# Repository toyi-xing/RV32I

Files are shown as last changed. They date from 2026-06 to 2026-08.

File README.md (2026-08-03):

# RV32I SoC

本仓库是一个 RV32I SoC 实现仓库，维护对象包括五级流水线核 `core.sv`、AXI4-Lite/APB4 数据子系统、MMIO 外设（GPIO/UART/TIMER32）、SoC 集成顶层 `rv32i_soc.sv` 及 SoC 级 testbench。已完成最小 M-mode CSR/trap、machine timer/external interrupt、single-outstanding data access、流水线 backpressure，以及 AXI4-Lite DMEM 和 APB4 外设接入。

## 当前特性（已经过定向验证）

- **40 条 RV32I 指令**：完整 ALU、分支、跳转、访存、LUI/AUIPC、FENCE（当前为 nop）、ECALL、EBREAK 全量支持。
- **五级流水线**：IF/ID/EX/MEM/WB 经典五级流水线结构。
- **数据 hazard**：forwarding（EX/MEM、MEM/WB）+ load-use stall + CSR-use stall。
- **控制 hazard**：branch/JAL/JALR/trap redirect flush + wrong-path kill。
- **CSR 寄存器及访问指令**：6 条 Zicsr 指令（CSRRW/CSRRS/CSRRC/CSRRWI/CSRRSI/CSRRCI），最小 M-mode CSR（mstatus/mtvec/mscratch/mepc/mcause/mtval + 只读 CSR）。
- **同步异常**：instruction address misaligned、illegal instruction、breakpoint、load/store address misaligned、 load/store access fault、ECALL/EBREAK from M-mode。
- **MRET**：trap handler 返回。
- **trap 精确提交**：在 MEM 边界接受，kill 年轻指令，不影响 older instruction。
- **MMIO 地址图及外设**：GPIO0、UART0、TIMER0 已集成于 data_subsystem，寄存器 ABI 见 `rtl/periph/readme.md`，SoC 地址图规划在 `soc_pkg.sv`，平台常量见 `sw/include/platform.h`。
- **MMIO access fault**：未实现外设或预留地址空间访问触发 load/store access fault。
- **machine timer interrupt**：TIMER0.MTIME ≥ MTIMECMP 触发 MTIP，level pending 输出到 mtip_o。
- **machine external interrupt**：GPIO 按 bit 独立配置边沿/电平触发、UART RX 事件，汇总为 MEIP（中断优先级 MEIP > MTIP）。
- **中断精确提交**：CSR 写同拍中断接受、MRET 同拍中断重入、mepc 记录当前提交边界的 interrupt return PC。
- **AXI4-Lite/APB4 数据子系统**：LSU 保留 single-outstanding simple request/response 边界，经 adapter 转为 AXI4-Lite；DMEM 通过外置 AXI-Lite RAM 接入，GPIO/UART/TIMER 经 AXI-Lite-to-APB4 bridge 与 APB mux 接入，标准 channel wait/error 映射到既有 MEM backpressure 和精确 access fault 语义。
- **设计可综合**：CPU 核及子模块采用可综合 rtl 编写；综合对象为 CPU 核顶层 `core.sv`，综合结果不作为项目重点。SoC 顶层透出 IMEM/DMEM 端口，仿真内存模型由 testbench 实例化；MMIO 外设模型为简化模型，未面向真实 IO 单元、真实串口协议或 PPA 做优化。
- **FPGA 上板验证**：基于 v5.1 完成 FPGA 上板验证归档，CPU core RTL 保持不改，SoC MMIO 地址图保持不改；通过 FPGA top、片上 IMEM/DMEM wrapper、UART TX/RX PHY 和 Quartus 工程适配，完成 GPIO/KEY、UART、TIMER polling、TIMER interrupt 等板级验证。

---

## 验证能力

- **SoC 级程序自检定向测试**：汇编/C 测试程序通过 PASS/FAIL 状态字结束仿真，覆盖 ISA、流水线 hazard、trap/CSR、MMIO 和 machine interrupt 场景。
- **TB mailbox 外部激励协议**：`sw/include/tb_rv32i_soc_test.h` 与 `tb/sv/tb_rv32i_soc.sv` 约定保留 DMEM store 命令，由测试程序按自身进度请求 testbench 驱动 GPIO 输入和 UART RX 事件。该协议只属于当前 testbench，不是 SoC 真实 MMIO ABI。
- **interrupt directed test**：覆盖 timer interrupt、GPIO/UART external interrupt、MEIP/MTIP 优先级、CSR 写同拍中断、MRET 同拍中断重入和周期 GPIO 输入测量，测试程序由 TB mailbox 机制自行激发。
- **FPGA board bring-up**：[fpga/readme.md](fpga/readme.md) 作为 FPGA 上板验证入口，归档板卡资料、通用上板方法，以及已完成版本的专项迁移文档和验证结果。
- **VCS/UVM/SVA 验证工作区**：[uvm/v6_0/data_subsystem](uvm/v6_0/data_subsystem/readme.md) 固定保存 v6.0 simple bus 与 response-delay wrapper 的独立验证环境，包含 active bus/wrapper agent、monitor、DMEM/GPIO0 reference check、wrapper delay checker、SVA 和 functional coverage；该版本化快照不代表当前 AXI/APB 主线 RTL，固定 seed 结果与 coverage 见 [verification report](uvm/v6_0/data_subsystem/verification_report.md)。

---

## 系统架构

```text
+-------------------------------------------------------------------------------------------------+
| tb_rv32i_soc                                                                                    |
|                                                                                                 |
|  +-----------------------+    instr     +--------------------------------------------------+    |
|  | simple_rom / IMEM     | -----------> | rv32i_soc                                        |    |
|  | 0x0000_0000  256 KiB  |              |                                                  |    |
|  | +imem image           |              |  +----------------------------------------+      |    |
|  +-----------------------+              |  | core.sv                                |      |    |
|                                         |  | RV32I 5-stage pipeline                 |      |    |
|                                         |  | forwarding / stall / redirect          |      |    |
|                                         |  | CSR / trap / precise interrupt   <---------+  |    |
|                                         |  | single-outstanding LSU + backpressure  |   |  |    |
|                                         |  +-------------------+--------------------+   |  |    |
|                                         |                      | simple req/resp        |  |    |
|                                         |                      v                        |  |    |
|                                         |  +-----------------------------------------+  |  |    |
|                                         |  | data_subsystem                          |  |  |    |
|                                         |  | simple_bus_to_axi_lite                  |  |  |    |
|  +-----------------------+   AXI4-Lite  |  |   -> axi_lite_router                    |  |  |    |
|  | axi_lite_ram / DMEM   | <----------------------+   external DMEM AXI-Lite port    |  |  |    |
|  | 0x0004_0000  256 KiB  |              |  |      +-> axi_lite_to_apb -> apb_mux     |  |  |    |
|  | +dmem image           |              |  |             +-> GPIO0 / UART0 -> MEIP +----+  |    |
|  +-----------------------+              |  |             +-> TIMER0        -> MTIP + |     |    |
|                                         |  +-----------------------------------------+     |    |
|                                         |                                                  |    |
|                                         | observable: commit / trap / data bus             |    |
|                                         |             GPIO / UART / IRQ                    |    |
|                                         +--------------------------------------------------+    |
|                                                                                                 |
|  memory images | PASS/FAIL monitor | commit/trap/data trace                                     |
|  TB mailbox store commands -> GPIO input stimulus / UART RX event                               |
|                                                                                                 |
+-------------------------------------------------------------------------------------------------+
```

IMEM 和 DMEM 均位于 `rv32i_soc` 之外；`data_subsystem` 只向外透出 AXI4-Lite DMEM port，GPIO/UART/TIMER 则作为内部 APB4 外设接入。TB mailbox 和 trace 只属于仿真观察边界。

---

## 目录结构

| 目录 | 说明 |
|---|---|
| `docs/` | 说明文档 |
| [`fpga/`](fpga/readme.md) | FPGA 上板验证工作区，包含板卡资料、版本归档工程、上板流程和验证结果入口 |
| `rtl/` | RTL 源码 |
| `scripts/` | 辅助脚本 |
| `sim/` | 编译和仿真脚本 |
| `sw/` | 汇编和 C 裸机测试程序 |
| `tb/` | SoC 级定向验证 testbench 平台 |
| [`uvm/`](uvm/readme.md) | Linux/VCS CLI UVM 验证工作区，按 release 和验证对象归档 |

---

## 项目时间戳

| 核（相对于上版本的改动） | 顶层 | 状态 | release 版本 | 备注 |
|---|---|---|---|---|
| 单周期 RV32I | `core_single_cycle.sv` | 历史版本已完成，当前不再维护 | v1.0 | 最终兼容版本为 v2.0，自 v2.10 起删除该文件 |
| 五级流水线 RV32I（data hazard + control hazard） | `core_pipeline5.sv` | 已完成 | v2.0 | - |
| 同步异常扩展、CSR 与最小特权级（CSR/exception trap） | `core_pipeline5.sv` | 已完成 | v3.0 | 自 v3.4 起，将 `core_pipeline5.sv` 改名为 `core.sv` |
| 增加 MMIO 最简外设与 SoC 平台集成 | CPU 核 `core.sv` <br> SoC 平台 `rv32i_soc` | 已完成 | v4.0 | 1. 自 v4.10 起，删除旧的 CPU 核测试平台 `tb_core_pipeline5.sv` <br>  2. 外设 offset 计算逻辑存在 bug [RTL-001](docs/known_issues.md)，已在v7.0定位并修复 |
| machine interrupt：MTIP、MEIP | CPU 核 `core.sv` <br> SoC 平台 `rv32i_soc` | 已完成 | v5.0 | 1. 自 v5.1 起，拆分 SoC 顶层电路的 mem 单元 <br> 2. 回归测试统计存在 bug [REG-001](docs/known_issues.md)，已在 v5.6 定位并修复 |
| FPGA 分支：基于 v5.1 的 FPGA 上板验证 | FPGA 顶层 [`e10_rv32i_top.sv`](fpga/project_v5.1_original_to_fpga/project_v5.1_fpga/rtl/fpga/e10_rv32i_top.sv) <br> FPGA 工程 [`e10_rv32i.qpf`](fpga/project_v5.1_original_to_fpga/project_v5.1_fpga/fpga/quartus/e10_rv32i.qpf) | 已完成 | v5.2 | - |
| data-side 可变延迟 | CPU 核 `core.sv` <br> SoC 平台 `rv32i_soc` | 已完成 | v6.0 | - |
| UVM 分支：基于 v6.0 的 data_subsystem UVM/SVA 验证 | DUT rtl top: [`data_subsystem.sv`](uvm/v6_0/data_subsystem/dut/rtl/soc/data_subsystem.sv) <br> UVM top: [`tb_data_subsystem_uvm_top.sv`](uvm/v6_0/data_subsystem/tb/top/tb_data_subsystem_uvm_top.sv) | 已完成 | v7.0 | UVM 固定 seed 回归暴露并修复 [RTL-001](docs/known_issues.md) |
| AXI4-Lite 总线接入 | CPU 核 `core.sv` <br> SoC 平台 `rv32i_soc` | 已完成 | v8.0 | - |

---

## 环境依赖

### 主仓库仿真 —— Linux

- **RISC-V bare-metal GCC 工具链**：`riscv64-unknown-elf-gcc` 等，需支持 `rv32i_zicsr` 和 `ilp32`，用于生成 ELF/BIN。
- **Verilator**：运行根目录 ASM/C directed regression。
- **Python 3**：运行 `bin2mem32.py` ，编译出的裸二进制 .bin 转成每行一个 32-bit hex word 的 .mem 文件。

### FPGA 工作区 —— Windows

- **Quartus Prime Lite 25.1std.0 Build 1129**：综合、布局布线、生成 `.sof` 和 Programmer 下载。
- **USB-Blaster 驱动**：连接 E10 开发板并下载 FPGA。
- **RISC-V bare-metal GCC 工具链、Bash 与 Python 3**：构建裸机程序并生成 `.mem`/`.mif` 初始化镜像。
- **USB-TTL 串口工具**：观察和验证真实 UART TX/RX。

FPGA 板卡、工具和版本化工程说明见 [fpga/readme.md](fpga/readme.md)。

### VCS/UVM 工作区 —— Linux

- **Synopsys VCS**：编译和运行 UVM 仿真平台。

UVM 工具、命令和结果说明见 [uvm/readme.md](uvm/readme.md)。

---

## 五级流水线核（主仓库仿真）

### 涉及文件

**RTL：**
```
rtl/common/          # 核与 SoC 公共常量/枚举/类型（core_pkg、pipeline_pkg、soc_pkg）
rtl/bus/             # AXI4-Lite adapter/router、AXI-Lite-to-APB4 bridge、APB mux/register adapter
rtl/core/            # 五级流水线核（IF/ID/EX/MEM/WB、forwarding、hazard、CSR、trap）
rtl/mem/             # memory 封装（simple_rom、当前 axi_lite_ram、legacy simple_ram）
rtl/periph/          # MMIO 外设（mmio_gpio、mmio_uart、mmio_timer32）
rtl/soc/             # SoC 集成（AXI4-Lite/APB4 data_subsystem、rv32i_soc 顶层）
```

**Testbench：** 

- `tb/sv/tb_rv32i_soc.sv`：集成 MMIO 最小外设的 SoC 测试平台。

**汇编测试程序：**
```
# 基础 ISA 测试
sw/asm/0001_smoke.S                           # 最小冒烟
sw/asm/0101_branch.S                          # 分支指令
sw/asm/0102_alu_imm.S                         # ALU 立即数
sw/asm/0103_alu_reg.S                         # ALU 寄存器
sw/asm/0104_load_store.S                      # 访存指令
sw/asm/0105_jump.S                            # JAL/JALR
sw/asm/0106_u_type.S                          # LUI/AUIPC

# 流水线 data/control hazard 测试
sw/asm/0301_pipeline5_nofwd_noredirect.S      # 不依赖 forwarding/redirect 的基线冒烟
sw/asm/0302_pipeline5_fwd_noredirect.S        # data hazard 全覆盖
sw/asm/0303_pipeline5_fwd_redirect.S          # forwarding + control hazard 混合

# trap 测试
sw/asm/0501_trap_entry_smoke.S                # ECALL trap entry smoke
sw/asm/0502_exception_full.S                  # 全同步异常总测试（9 个 step）
sw/asm/0503_csr_instr_test.S                  # 6 个 CSR 指令读写 CSR 寄存器测试

# SoC/MMIO 测试
sw/asm/0601_soc_smoke.S                       # SoC 级别冒烟
sw/asm/0602_uart_tx.S                         # UART TX 发送字符
sw/asm/0603_gpio_rw.S                         # GPIO OUT/OE/IN 读写
sw/asm/0604_mmio_access_fault.S               # MMIO 未实现外设 access fault
sw/asm/0605_mmio_misaligned_priority.S        # misaligned MMIO 访问优先级
sw/asm/0606_wrong_path_mmio.S                 # wrong-path MMIO 不提交

# interrupt 测试
sw/asm/0705_interrupt_commit_precise.S        # CSR 写同拍中断精确提交
sw/asm/0706_mret_interrupt_reentry.S          # MRET 同拍中断重入

# data subsystem 集成测试（沿用既有编号与文件名）
sw/asm/0801_dmem_wait_basic.S                 # AXI-Lite DMEM 基本 load/store 与 byte lane
sw/asm/0802_dmem_wait_forwarding.S            # AXI-Lite DMEM 固定多周期访问下 forwarding
sw/asm/0804_mmio_wait_access_fault.S          # APB 非法 offset 的精确 access fault
sw/asm/0805_wait_interrupt_boundary.S         # AXI-Lite DMEM 访问期间 interrupt 不越过 older 指令
```

**C 测试程序：**
```
sw/c/0201_c_smoke.c                           # 最小冒烟
sw/c/0202_dmem_init.c                         # .data/.bss/.rodata 初始化
sw/c/0401_control_mix.c                       # 综合控制流 + 内存操作
sw/c/0551_trap_smoke.c                        # C 侧 trap handler smoke
sw/c/0651_soc_mmio_smoke.c                    # SoC MMIO 冒烟（GPIO/UART/access fault）
sw/c/0652_soc_mmio_gpio_uart.c                # SoC MMIO 综合测试（GPIO bit 操作/UART 多字符串）
sw/c/0751_timer_smoke.c                       # TIMER0 定时器中断 smoke（C trap handler + level pending 清除）
sw/c/0752_gpio_irq_basic.c                    # GPIO 外部中断基础行为（4 类触发、IRQ_EN/STATUS/PENDING、W1C）
sw/c/0753_uart_rx_irq.c                       # UART RX 中断（TB 注入、rx_irq_enable 门控、读清与 W1C 差异）
sw/c/0754_external_timer_priority.c           # MEIP/MTIP 优先级（同时 pending 优先进 MEIP，清后进 MTIP）
sw/c/0757_gpio_periodic_irq.c                 # TB 固定周期 GPIO 中断精确测量（TIMER0.MTIME + UART 报告）
sw/c/0853_mmio_wait_basic.c                   # 固定 PREADY APB 外设基本读写与副作用
sw/c/0856_wait_mixed_random_smoke.c           # AXI-Lite DMEM/APB MMIO 混合路由 smoke
```

**仿真脚本：** `sim/soc_asm/`、`sim/soc_c/`

当前共 **38 个 directed tests**（汇编 25 + C 13），全量回归结果为 ASM 25/25、C 13/13。覆盖 RV32I 指令集、五级流水线 hazard（6 种 RAW forward + load-use stall + redirect）、7 种同步异常、MMIO 外设访问与 access fault、machine timer/external interrupt（GPIO 4 类触发、UART RX、MEIP/MTIP 优先级、CSR 同拍中断、MRET 同拍重入），以及 AXI-Lite DMEM、APB 外设、错误传播、MEM backpressure 和 DMEM/MMIO 混合路由场景。

### 仿真命令

```bash
# —— SoC 汇编回归仿真 ——
sim/soc_asm/run_all.sh

# —— SoC C 回归仿真 ——
sim/soc_c/run_all.sh

# —— SoC 单个程序仿真 ——
sim/soc_asm/run_test.sh <n>               # n 表示 sw/asm 下 汇编程序前的四位编码
sim/soc_c/run_test.sh <m>                 # m 表示 sw/c 下 c 程序前的四位编码
```

汇编仿真详细流程见 [docs/simulation_flow_asm.md](docs/simulation_flow_asm.md)。C 仿真流程见 [docs/simulation_flow_c.md](docs/simulation_flow_c.md)。

---

## 编写新测试

在 `sw/asm/` 下创建 `.S` 文件，然后：

```bash
sim/soc_asm/run_test.sh <四位编号或完整basename>
```

在 `sw/c/` 下创建 `.c` 文件后运行：

```bash
sim/soc_c/run_test.sh <四位编号或完整basename>
```

汇编测试集分类见 [sw/asm/readme.md](sw/asm/readme.md)。

c 程序测试集分类与编写方法见 [sw/c/readme.md](sw/c/readme.md)。

MMIO 外设操作手册见 [rtl/periph/readme.md](rtl/periph/readme.md)。

MMIO 地址图镜像查阅见 [sw/linker/readme.md](sw/linker/readme.md)。

## FPGA 上板验证（FPGA 工作区）

FPGA 上板验证入口见 [fpga/readme.md](fpga/readme.md)。该目录维护板卡资料、通用上板方法、版本归档工程、专项迁移说明和板级验证结果；根 README 只保留总入口，具体 FPGA 版本的工程细节以后统一在 `fpga/` 工作区内维护。

## UVM 平台仿真（VCS/UVM 工作区）

```bash
# —— 单个 UVM test，第二个参数为 random seed ——
uvm/v6_0/data_subsystem/sim/run_test.sh DS_map_random_test 1

# —— 启用 simple bus SVA ——
ASSERT_ON=1 uvm/v6_0/data_subsystem/sim/run_test.sh simple_bus_smoke_test 1

# —— 当前 UVM 受控回归 ——
uvm/v6_0/data_subsystem/sim/run_all.sh
```

UVM 工作区总入口见 [uvm/readme.md](uvm/readme.md)，当前环境的完整命令、PASS/FAIL 口径和本地产物见 [uvm_simulation_flow.md](uvm/v6_0/data_subsystem/dut/docs/uvm_simulation_flow.md)。

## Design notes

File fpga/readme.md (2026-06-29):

# RV32I FPGA 上板验证工作区

本工作区用于整理 RV32I SoC 从仿真验证版本迁移到 FPGA 上板验证版本的工程材料。当前主要目标板为正点原子 E10 最小系统板，FPGA 器件为 Intel Cyclone IV E `EP4CE10F17C8`。板卡原理图、器件手册、IO 分配表等资料统一放在 [fpga_e10_board_resources](fpga_e10_board_resources/) 中。

本文档是通用的 FPGA 上板验证方法；具体某个 RTL 版本的改造记录、验证结果和问题闭环放在对应版本目录下。

## 目录结构

```text
.
+-- readme.md
+-- fpga_e10_board_resources/
`-- project_v5.1_original_to_fpga/
    +-- project_v5.1_original/
    `-- project_v5.1_fpga/
```

| 路径 | 内容 |
| --- | --- |
| [fpga_e10_board_resources](fpga_e10_board_resources/) | E10 系统板资料归档，包括 FPGA 器件资料、原理图、IO 分配表、板载存储和外设芯片资料等。 |
| [project_v5.1_original_to_fpga](project_v5.1_original_to_fpga/) | v5.1 从仿真器验证工程迁移到 FPGA 上板工程的版本归档与专项文档入口。 |

## 目标板卡

当前上板目标：

- 板卡：正点原子 E10 最小系统板
- FPGA：Intel Cyclone IV E `EP4CE10F17C8`
- 时钟：板载 50 MHz 时钟
- 基础 IO：LED、KEY、UART、扩展排针
- FPGA 工具：Quartus Prime Lite 25.1

更细的板卡资源、M9K 片内存储、板载 SDRAM/Flash、引脚和原理图资料请查看 [fpga_e10_board_resources/readme.md](fpga_e10_board_resources/readme.md)。

## 通用上板改造项

把一个已经通过仿真的 RV32I SoC 版本搬到 FPGA 上，通常需要完成以下工作：

1. 保留已验证的 CPU core 逻辑，避免在上板适配阶段引入新的流水线行为变化。
2. 根据目标 FPGA 的片上存储资源重新评估 IMEM/DMEM 容量，并同步 RTL 参数、linker script 和 `platform.h`。
3. 分离仿真 memory 与 FPGA memory。仿真可继续使用理想 ROM/RAM，FPGA 侧应使用可综合、可推断或可例化的 block RAM。
4. 为 FPGA 添加板级 top，连接时钟、复位、LED、KEY、UART、扩展 GPIO 等真实 IO。
5. 根据 FPGA RAM 的真实时序适配 IMEM/DMEM wrapper。不能默认仿真 RAM 的组合读行为等价于 FPGA block RAM。
6. 添加 Quartus 工程、器件选择、顶层设置、QSF 引脚约束和存储初始化文件。
7. 建立 C 程序到 FPGA 初始化镜像的构建流程，并确保生成的 IMEM/DMEM 镜像被重新编译进 `.sof`。
8. 用最小可见程序逐步验证 GPIO、按键、timer polling、interrupt、UART 或其他外设。

## 工具依赖

与母仓库不同，本工作区 FPGA 上板验证在 Windows 环境下进行，建议准备：

- Quartus Prime Lite 25.1，用于综合、布局布线、生成 `.sof` 和下载 FPGA。
- USB-Blaster 驱动，用于通过 Quartus Programmer 下载。
- RISC-V bare-metal GCC 工具链，需支持 `rv32i_zicsr` 和 `ilp32`。
- Bash 环境，用于运行工程脚本。
- Python 3，用于二进制镜像、`.mem`、`.mif` 等格式转换。
- 可选 USB-TTL 串口工具，用于验证真实 UART TX/RX。

## C 程序编写规则

FPGA 上板 C 程序遵守以下规则：

- 程序放在对应 FPGA 工程的 `sw/c/` 目录下。
- 文件名使用四位编号开头，例如 `0500_xxx.c`，方便脚本按编号选择程序。
- 使用裸机 C，不依赖操作系统和标准库运行时。
- 包含工程提供的 `platform.h`，通过其中的地址图、寄存器偏移和 CSR helper 访问 SoC。
- 如果 RTL 修改了 IMEM/DMEM 容量或 MMIO 地址图，必须同步 linker script 和 `platform.h`。
- 每次更新 C 程序镜像后，需要重新运行 Quartus compile，因为 FPGA 初始化文件会被打包进 `.sof`。

## 当前版本归档

当前已完成的版本迁移归档见 [project_v5.1_original_to_fpga/readme.md](project_v5.1_original_to_fpga/readme.md)。该目录包含仿真原始工程、FPGA 改造工程，以及 v5.1 专项改造说明、上板流程和边界记录。

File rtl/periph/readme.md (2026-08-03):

# MMIO 外设寄存器手册

本文面向软件开发者描述 `rtl/periph` 下 MMIO 外设 module 的寄存器 ABI。只要系统实例化同一个外设 module，寄存器 offset、bit 定义、访问属性和软件可见副作用就应保持一致。具体实例基地址、SoC 地址译码窗口和中断汇总方式不属于本手册范围，应查对应 SoC 的 MMIO 地址图。

本文中的 offset 都是相对该外设实例 `BASE_ADDR` 的 byte offset：

```text
software_address = instance_BASE_ADDR + register_offset
```

当前三个外设本体都是固定响应 register block，寄存器 ABI 不包含软件可见的 ready/valid 信号。主线数据通路由 `axi_lite_to_apb`、`apb_mux` 和每个外设前的 `apb_to_reg_adapter` 接入：只有 `PSEL && PENABLE && PREADY` 的 APB ACCESS completion 才产生一次寄存器访问脉冲，因此 W1C、读清和 UART TX 等副作用不会在 SETUP 阶段或等待期间重复发生。当前正式外设固定 `PREADY=1`；`access_fault_o` 检测未知 offset，并经 `PSLVERR -> AXI SLVERR -> simple bus error` 形成 CPU load/store access fault。写 RO、读 WO、写保留 bit 等访问类型或字段错误当前不额外触发 fault。

外设端口的 `addr_i` 保持 CPU 发出的 byte address，但寄存器选择按 word-aligned offset 进行：`offset = {(addr_i - BASE_ADDR)[11:2], 2'b00}`。因此同一寄存器 word 内的 `reg+0`、`reg+1`、`reg+2` 和 `reg+3` 都命中同一个寄存器；`addr_i[1:0]` 不参与寄存器 decode，实际读写 byte lane 由 `be_i` 决定。读操作返回完整寄存器 word，CPU 侧再按原始地址和 load 类型提取目标 byte/halfword。只有对齐后的 register word offset 不在本 ABI 中定义时，`access_fault_o` 才应拉高。

通用访问属性：

| 属性 | 含义 |
|---|---|
| `RW` | 软件可读可写。写入时按 byte enable 更新被选中的 byte，未选 byte 保持原值。 |
| `RO` | 软件只读。写入当前忽略，不触发 `access_fault_o`。 |
| `WO` | 软件只写。读取当前返回 0，不触发 `access_fault_o`。 |
| `R/W1C` | 软件可读；写 1 清除对应 bit，写 0 保持。store byte enable 未选中的 byte 不参与清除。 |
| `*` | 不是访问属性；附在属性后表示该寄存器除访问属性本身外，还参与额外访问副作用，可能是触发方，也可能是被影响方。具体方向见寄存器列表的 `副作用` 列。 |

寄存器列表中的 `副作用` 列用于说明访问寄存器时产生或承受的软件可见变化。`-` 表示没有额外访问副作用，不代表寄存器值不会被硬件事件更新。

保留 bit 应由软件写 0，读回值不应被软件依赖。当前部分 RW 配置寄存器会保留写入的保留 bit，后续扩展时可能重新定义这些 bit，因此软件不应依赖这种读回结果。

## 1. `mmio_gpio`

`mmio_gpio` 是可参数化宽度的 GPIO MMIO 外设。寄存器宽度保持 XLEN，低 `GPIO_WIDTH` bit 对实际 GPIO 有意义；高 bit 为保留 bit。

`gpio_in_i` 可能来自 SoC 外部或 testbench。模块内部会先把它两级同步到 `clk_i` 域，软件读到的 `IN` 和中断触发检测都使用同步后的输入视图，因此相对外部真实电平通常会有约两个 `clk_i` 周期延迟。

`mmio_gpio` 把 `OUT`、`OE`、`IN` 分离为普通端口，不在外设内部实现真实 tri-state pad。`OE` 只表示输出使能配置，不参与输入采样和中断 mask。输出模式下是否回读 pad、电平如何进入 `gpio_in_i`，由 SoC 顶层或 pad wrapper 决定。

参数：

| 参数 | 说明 |
|---|---|
| `BASE_ADDR` | 外设实例基地址，用于计算寄存器 offset。 |
| `GPIO_WIDTH` | GPIO bit 数，当前应保持在 1..XLEN。 |

### GPIO 寄存器列表

| offset | 名称 | 属性 | reset | 副作用 | 说明 |
|---:|---|---|---:|---|---|
| `0x000` | `OUT` | `RW` | `0x0000_0000` | - | GPIO 输出数据。 |
| `0x004` | `IN` | `RO` | `0x0000_0000` | - | 同步后的 GPIO 输入值。 |
| `0x008` | `OE` | `RW` | `0x0000_0000` | - | GPIO 输出使能。 |
| `0x00C` | `IRQ_EN` | `RW` | `0x0000_0000` | - | 每 bit 中断总使能。 |
| `0x010` | `IRQ_RISE_EN` | `RW` | `0x0000_0000` | - | 每 bit 上升沿触发使能。 |
| `0x014` | `IRQ_FALL_EN` | `RW` | `0x0000_0000` | - | 每 bit 下降沿触发使能。 |
| `0x018` | `IRQ_HIGH_EN` | `RW` | `0x0000_0000` | - | 每 bit 高电平触发使能。 |
| `0x01C` | `IRQ_LOW_EN` | `RW` | `0x0000_0000` | - | 每 bit 低电平触发使能。 |
| `0x020` | `IRQ_PENDING` | `R/W1C` | `0x0000_0000` | 同拍触发时硬件 set 优先。 | 每 bit interrupt pending。 |
| `0x024` | `IRQ_STATUS` | `RO` | `0x0000_0000` | - | 已使能 pending 视图。 |

### GPIO 数据寄存器

`OUT[GPIO_WIDTH-1:0]` 是每个 GPIO bit 的输出数据，直接对应 `gpio_out_o`。当系统外层实现真实 GPIO pad 时，通常只有 `OE[bit]=1` 的 bit 才会被驱动到外部引脚。

`IN[GPIO_WIDTH-1:0]` 返回同步后的 `gpio_in_i`。`IN` 不受 `OUT` 或 `OE` 影响。

`OE[GPIO_WIDTH-1:0]` 是每个 GPIO bit 的输出使能，直接对应 `gpio_oe_o`。bit 为 1 表示该位按输出使用，bit 为 0 表示该位按输入或高阻使用，具体 pad 行为由外层实现。

### GPIO 中断寄存器

`IRQ_EN` 是每 bit 中断总使能。当前实现中，只有 `IRQ_EN[bit]=1` 时，该 bit 的触发条件才会置 `IRQ_PENDING[bit]`；`IRQ_EN=0` 时发生的历史事件不会被 pending 记录。

`IRQ_RISE_EN`、`IRQ_FALL_EN`、`IRQ_HIGH_EN`、`IRQ_LOW_EN` 配置每个 GPIO bit 的触发类型：

| 寄存器 | bit 为 1 时的含义 |
|---|---|
| `IRQ_RISE_EN` | 同步后输入从 0 到 1 时触发。 |
| `IRQ_FALL_EN` | 同步后输入从 1 到 0 时触发。 |
| `IRQ_HIGH_EN` | 同步后输入为 1 时持续触发。 |
| `IRQ_LOW_EN` | 同步后输入为 0 时持续触发。 |

同一个 GPIO bit 可以同时打开多个触发类型。边沿触发使用同步后的输入历史值；电平触发只要同步后的输入保持在触发电平，就会持续产生触发条件。

`IRQ_PENDING` 是 R/W1C pending 寄存器。软件读出当前 pending；软件写 1 清除对应 bit，写 0 保持。硬件触发和软件 W1C 清除在同一个时钟沿发生时，硬件置位优先。因此电平触发条件仍然成立时，软件写 1 清 pending 后该 bit 可能保持为 1 或立即再次变为 1，这是预期行为。

`IRQ_STATUS` 是 `IRQ_PENDING & IRQ_EN` 的只读视图。`gpio_irq_o` 是 level interrupt 输出，只要 `IRQ_STATUS` 任意 bit 为 1 就为 1。handler 通常读 `IRQ_STATUS` 判断有效中断源，再向 `IRQ_PENDING` 写 1 清除已处理 bit。

## 2. `mmio_timer32`

`mmio_timer32` 是 32-bit 教学用 timer 外设。它提供 `MTIME` 计数器、`MTIMECMP` 比较值、`CTRL` 使能和 `STATUS` 观察口。`timer32_irq_o` 是 level pending，不是 pulse。

这个 module 的命名明确包含 `32`，表示当前寄存器和计数比较语义是 32-bit。后续如果增加 64-bit timer，应该作为新的 timer 规格或扩展规格处理，不应悄悄改变 `mmio_timer32` 的软件可见 ABI。

参数：

| 参数 | 说明 |
|---|---|
| `BASE_ADDR` | 外设实例基地址，用于计算寄存器 offset。 |

### TIMER32 寄存器列表

| offset | 名称 | 属性 | reset | 副作用 | 说明 |
|---:|---|---|---:|---|---|
| `0x000` | `MTIME` | `RW` | `0x0000_0000` | 写 `MTIME` 的同拍不自增。 | 32-bit 计数值。 |
| `0x004` | `MTIMECMP` | `RW` | `0x0000_0000` | - | 32-bit 比较值。 |
| `0x008` | `CTRL` | `RW` | `0x0000_0000` | - | timer 控制寄存器。 |
| `0x00C` | `STATUS` | `RO` | `0x0000_0000` | - | timer 状态寄存器。 |

### `MTIME` 和 `MTIMECMP`

`MTIME` 是 32-bit 计数器。`CTRL.enable=1` 时，`MTIME` 通常每个 `clk_i` 周期加 1。

写 `MTIME` 的时钟沿，写入值生效，本拍不执行自动自增。也就是说，如果软件希望从 0 开始计数，可以先写 `MTIME=0`，该写入周期不会额外加 1。

`MTIMECMP` 是 32-bit 比较值。写 `MTIMECMP` 不阻止 `MTIME` 自增；该时钟沿是否自增取决于写入前的旧 `CTRL.enable`。

### `CTRL` register

```text
31                                                1 0
+-------------------------------------------------+-+
| Reserved                                        |E|
+-------------------------------------------------+-+
```

bit 定义：

| bit | 名称 | 说明 |
|---:|---|---|
| 0 | `enable` | 1 时允许 `MTIME` 自增，并允许比较结果输出到 `timer32_irq_o`。 |
| 31:1 | reserved | 软件写 0，读回值不应依赖。 |

写 `CTRL.enable=1` 后，计数从后续时钟沿开始。写 `CTRL` 的同一时钟沿不暂停 `MTIME`：如果写入前旧 `CTRL.enable=1`，`MTIME` 仍会在该时钟沿自增；如果写入前旧 `CTRL.enable=0`，该时钟沿不自增。

### `STATUS` register

```text
31                                                1 0
+-------------------------------------------------+-+
| Reserved                                        |M|
+-------------------------------------------------+-+
```

bit 定义：

| bit | 名称 | 说明 |
|---:|---|---|
| 0 | `mtip` | `CTRL.enable && (MTIME >= MTIMECMP)`。 |
| 31:1 | reserved | 读 0。 |

timer interrupt 输出 `timer32_irq_o` 与 `STATUS.mtip` 同义，是 level 信号。只要 `CTRL.enable=1` 且 `MTIME >= MTIMECMP`，它就保持为 1；条件不成立时自动为 0。软件清 timer interrupt 的方式不是 acknowledge pending flop，而是让比较条件不成立，例如把 `MTIMECMP` 写到未来值，或关闭 `CTRL.enable`。

## 3. `mmio_uart`

`mmio_uart` 当前是教学用简化 UART MMIO 模型，不是真实串口物理层。TX 和 RX 都按单拍事件建模；当前没有 baud rate、起始位/停止位、采样、FIFO、busy/full 等真实串口逻辑。

后续如果把内部替换成真实串口收发状态机或 FIFO，应尽量保持 `TXDATA/STATUS/CTRL/RXDATA/IRQ_PENDING` 的软件可见语义，使 CPU core、SoC 中断控制和大部分驱动代码不需要感知 UART 内部实现变化。

`rx_valid_i/rx_data_i` 是已经在 `clk_i` 域内的单拍 RX event 接口，不是真实异步串口线。当前 `mmio_uart` 不对 `rx_data_i` 做逐 bit 两级同步；如果后续接真实 UART RX 或其它异步来源，应在 UART RX 前端、握手同步或异步 FIFO 中先转换到 `clk_i` 域，再送入当前寄存器层。

参数：

| 参数 | 说明 |
|---|---|
| `BASE_ADDR` | 外设实例基地址，用于计算寄存器 offset。 |

### UART 寄存器列表

| offset | 名称 | 属性 | reset | 副作用 | 说明 |
|---:|---|---|---:|---|---|
| `0x000` | `TXDATA` | `WO`* | `0x0000_0000` | 写入低 byte 可触发一拍 TX event。 | 发送数据写入口，低 8 bit 有效。 |
| `0x004` | `STATUS` | `RO`* | `0x0000_0001` | 被 `RXDATA` 读副作用影响。 | UART 状态寄存器。 |
| `0x008` | `CTRL` | `RW` | `0x0000_0000` | - | UART 控制寄存器。 |
| `0x00C` | `RXDATA` | `RO`* | `0x0000_0000` | 读出后清 `rx_valid` 和 `irq_pending`。 | 最近一次收到的 RX byte，低 8 bit 有效。 |
| `0x010` | `IRQ_PENDING` | `R/W1C`* | `0x0000_0000` | 被 `RXDATA` 读副作用影响；写 1 清 pending。 | RX interrupt pending。读本寄存器只观察。 |

### `TXDATA` register

`TXDATA[7:0]` 是发送字节。读 `TXDATA` 当前返回 0。

软件写 `TXDATA` 时，只有低 byte 被选中并且 `CTRL.tx_enable=1`，才会产生一拍 TX event。TX event 出现时，`tx_valid_o` 为 1，`tx_data_o` 是本次写入的低 8 bit。

如果 `CTRL.tx_enable=0`，写 `TXDATA` 不发送数据。当前简化模型没有发送 FIFO，也没有 busy/full 状态；`STATUS.tx_ready` 固定为 1。

### `STATUS` register

```text
31                                      3 2 1 0
+---------------------------------------+-+-+-+
| Reserved                              |P|R|T|
+---------------------------------------+-+-+-+
```

bit 定义：

| bit | 名称 | 说明 |
|---:|---|---|
| 0 | `tx_ready` | 当前固定为 1，表示简化 TX 总是可接收一个写入事件。 |
| 1 | `rx_valid` | 1 表示 `RXDATA` 中有尚未被读走的接收字节。 |
| 2 | `irq_pending` | `IRQ_PENDING[0]` 的只读镜像。 |
| 31:3 | reserved | 读 0。 |

读 `STATUS` 只观察状态，不清除 `rx_valid` 或 `irq_pending`。读 `RXDATA` 会影响后续 `STATUS.rx_valid` 和 `STATUS.irq_pending` 的值。

### `CTRL` register

```text
31                                      2 1 0
+---------------------------------------+-+-+
| Reserved                              |R|T|
+---------------------------------------+-+-+
```

bit 定义：

| bit | 名称 | 说明 |
|---:|---|---|
| 0 | `tx_enable` | 1 时，写 `TXDATA` 可产生 TX event；0 时，写 `TXDATA` 不发送。 |
| 1 | `rx_irq_enable` | 1 时，`IRQ_PENDING[0]` 会驱动 `uart_irq_o`；0 时仍可接收 RXDATA，但不输出 UART 中断。 |
| 31:2 | reserved | 软件写 0，读回值不应依赖。 |

### `RXDATA` register

`RXDATA[7:0]` 返回最近一次收到的 RX byte。读 `RXDATA` 会清 `STATUS.rx_valid` 和 `IRQ_PENDING[0]`。读 `RXDATA` 以外的寄存器不会清接收状态。

RX event 到达时，`RXDATA` 更新为新 byte，`STATUS.rx_valid` 置 1，`IRQ_PENDING[0]` 置 1。`IRQ_PENDING[0]` 的置位不受 `CTRL.rx_irq_enable` 门控；`rx_irq_enable` 只决定 pending 是否输出到 `uart_irq_o`。

如果旧 `RXDATA` 尚未被读走时又收到新的 RX event，当前第一版允许新字节覆盖旧字节，不提供 overflow 标志。软件测试应及时读取 `RXDATA`，或在后续真实 UART/FIFO 阶段补充容量和溢出状态。

同一时钟沿同时发生 `RXDATA` 读和 RX event 时，本次 load 返回读边沿前已经保存的 RX byte；边沿后新 RX byte 被保存，`STATUS.rx_valid` 和 `IRQ_PENDING[0]` 保持为 1。也就是说，RX event 对读清副作用有优先级。

### `IRQ_PENDING` register

`IRQ_PENDING[0]` 是 RX interrupt pending。读 `IRQ_PENDING` 本身只观察 pending，不清除。写 `IRQ_PENDING[0]=1` 清 pending；写 0 保持。写 `IRQ_PENDING` 只影响 pending，不清 `RXDATA`，也不清 `STATUS.rx_valid`。

同一时钟沿同时发生 `IRQ_PENDING` W1C 清除和 RX event 时，RX event 置位优先，`IRQ_PENDING[0]` 在该时钟沿后保持为 1。

UART interrupt 输出 `uart_irq_o` 是 level 信号。只要 `CTRL.rx_irq_enable=1` 且 `IRQ_PENDING[0]=1`，它就保持为 1。

# 补充说明：外设中断架构差异

GPIO、UART、TIMER32 的中断 pending/status/irq 架构不同，由各自的中断来源类型决定。

| | GPIO | UART | TIMER32 |
|--|---|---|---|
| 中断来源 | 事件或电平条件，多 bit | RX 数据到达事件，单 bit | `MTIME >= MTIMECMP` 比较电平 |
| PENDING | `R/W1C`，触发条件经 `IRQ_EN` 门控后置位 | `R/W1C`，RX event 置位 | 无单独 pending flop |
| STATUS | `IRQ_PENDING & IRQ_EN` | `rx_valid` 和 pending 镜像 | 比较结果 |
| 清中断 | 写 `IRQ_PENDING` W1C | 读 `RXDATA` 或写 `IRQ_PENDING` W1C | 写 `MTIMECMP` 到未来值，或关闭 `CTRL.enable` |

GPIO 适合多 bit 独立中断源。软件通常读 `IRQ_STATUS` 确定待处理 bit，写 `IRQ_PENDING` acknowledge。由于 `IRQ_STATUS` 受 `IRQ_EN` mask，禁用某 bit 后该 bit 不再推动 `gpio_irq_o`，但已经置位的 `IRQ_PENDING` 仍可被软件读到并清除。

UART 当前只有 RX 一个中断源。`IRQ_PENDING[0]` 保存 RX pending，`STATUS.irq_pending` 是它的只读镜像。读 `RXDATA` 同时消费数据和清 pending；写 `IRQ_PENDING[0]=1` 只清 pending，适合软件只想撤销中断请求但保留 RXDATA 可读状态的场景。

TIMER32 的中断是连续比较结果，不是一闪而过的事件。条件成立则 `timer32_irq_o` 保持高，不成立则自动恢复低。软件清中断的方式是改变比较条件，不需要 acknowledge pending 寄存器。

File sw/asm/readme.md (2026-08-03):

# 汇编测试计划

## 1. smoke 测试 `已通过`

| 文件 | 验证内容 |
|---|---|
| `0001_smoke.S` | 取指、执行、访存、写回、PASS/FAIL 通路 — 最小冒烟 |

## 2. RV32I 指令集测试 `已通过`

| 文件 | 覆盖指令 |
|---|---|
| `0102_alu_imm.S` | ADDI / SLTI / SLTIU / XORI / ORI / ANDI / SLLI / SRLI / SRAI |
| `0103_alu_reg.S` | ADD / SUB / SLL / SLT / SLTU / XOR / SRL / SRA / OR / AND |
| `0104_load_store.S` | LB / LH / LW / LBU / LHU / SB / SH / SW |
| `0101_branch.S` | BEQ / BNE / BLT / BGE / BLTU / BGEU |
| `0105_jump.S` | JAL / JALR |
| `0106_u_type.S` | LUI / AUIPC |

### 2.1 为什么先用汇编，不用 C？

验证 37 条 RV32I 指令阶段，汇编能精确控制每条指令编码、寄存器选择、访存地址和跳转路径。

C 会引入 ABI 约定、栈帧、函数调用、启动代码、`.data`/`.bss` 初始化、编译器额外生成的指令等变量。出错时很难确定是 core 的问题还是编译/链接引入的问题。

### 2.2 先测 BEQ / BNE，再测其他

TB 的判断逻辑很简单：检测到 `TEST_STATUS_ADDR` 被写入 1 就 PASS，写其他值就 FAIL。如果测试程序自己不会判断对错，那 TB 只能知道"程序跑完了"，无法知道"每条指令的结果对不对"。

**策略分三步走：**

1. **先测 BEQ / BNE 的 taken / not-taken** — 确认这两条分支指令工作正常。
2. **后续测试用 `bne` 自检** — 算出结果后和预期值比较，不等就跳 `fail`：

   ```asm
   # 算出结果到 x5，预期值到 x6
   bne x5, x6, fail    # 不符就跳 fail
   # 符合则继续下一个测试
   ```

   这样每条指令的正确性由程序自己保证，TB 只负责"走到最后就是 PASS"，信息量比单纯看 commit trace 高得多。
3. **最后回来补全 0101_branch.S** — 等所有测试都用上自检后，再回过来把剩下的 BLT / BGE / BLTU / BGEU 测完。

### 2.3 依赖链与交叉验证

每个 .S 文件并非只测自己的指令，也依赖前面已验证的指令甚至是**尚未验证过的指令**来构造测试场景和预期值：

```
0001_smoke.S (addi / lui / sw / jal)
  └─→ 0101_branch.S (beq / bne)
        └─→ 0106_u_type.S / 0102_alu_imm.S / 0103_alu_reg.S / 0105_jump.S / 0104_load_store.S
```

这种嵌套关系意味着**测试之间在互相验证**：只要全部 PASS，说明整条依赖链上的指令都正确，不需要区分谁是"被测"谁是"辅助"。

**出错了怎么查：**

如果某个测试 FAIL，不要急着怀疑它本身的测试逻辑。先确认它依赖的指令在对应的定向测试中是否通过。例如 0106_u_type.S 用了 SLLI，如果它 FAIL 了，先跑 0102_alu_imm.S 看 SLLI 是否正常。如果 0102_alu_imm.S 也 FAIL，那问题在 0102_alu_imm.S 而非 0106_u_type.S；如果 0102_alu_imm.S 通过，再回头排查 0106_u_type.S 的测试逻辑本身。

### 2.4 立即数书写规范

| 立即数类型 | 进制 | 适用指令/场景 | 示例 |
|---|---|---|---|
| LUI immediate | 16 进制 | `lui` | `lui x1, 0x10000` |
| 地址/掩码/位图 | 16 进制 | `addi` 构造地址、`xori`/`ori`/`andi` 掩码、比较时使用的位图 | `addi x1, x0, 0xFF`, `xori x2, x1, 0x555` |
| 普通小正整数 | 10 进制 | `addi` 做简单加法、构造小值 | `addi x1, x0, 42` |
| 负立即数 / 符号扩展边界 | 10 进制负数 | `addi` 或 xori/ori/andi 做符号扩展测试 | `addi x1, x0, -1`, `addi x1, x0, -2048` |
| Shift amount | 10 进制 | `slli`/`srli`/`srai` | `slli x1, x1, 4` |
| 比较结果 | 10 进制 | `bne` 与预期值比较 | `bne x1, x2, fail` / `bne x1, x0, fail`（x0 即 0） |

## 3. 五级流水线数据通路测试 `已通过`

| 文件 | 验证内容 |
|---|---|
| `0301_pipeline5_nofwd_noredirect.S` | 不依赖 forwarding/redirect 的基线冒烟（手插 3 NOP 隔离 RAW） |
| `0302_pipeline5_fwd_noredirect.S` | data hazard 全覆盖：EX/MEM→EX、MEM/WB→EX、WB_IMM、store data、load-use rs1+rs2 |
| `0303_pipeline5_fwd_redirect.S` | forwarding + redirect 混合：分支操作数前递、load-use 后紧跟分支、JAL/JALR wrong-path kill、JALR bit0 清零 |

### 3.1 测试关注点

基础 `00xx/01xx` 汇编测试主要验证指令语义是否正确。`03xx` 流水线测试进一步验证 RAW hazard、forwarding、stall 和 redirect kill 是否正确处理：

- `0301_pipeline5_nofwd_noredirect.S` 是早期空壳阶段留下来的基线测试，手动在 producer/consumer 之间插 3 条 NOP，因此即使不依赖 forwarding 也能跑。它现在主要用来回归**流水线的基础数据通路**：指令能否正确流过 5 级，commit 能否正确输出。
- `0302_pipeline5_fwd_noredirect.S` 在 forwarding + stall 实现后使用，**不插入任何用于隔离 RAW 的 NOP**。所有依赖全部靠硬件解决。采用**累加链**设计：每个 forwarding/load-use 场景的结果累加到同一寄存器，最终减固定常数得 1。任意路径出错都会导致最终结果 ≠ 1。

### 3.2 流水线测试特有的注意事项

- **nop 指令的使用**：`nop` 是 `addi x0, x0, 0` 的伪指令。在流水线测试中，nop 不再是"做无害操作"的填充，而是**有意控制流水线距离**的手段（例如在无 forwarding 时拉开 producer/consumer 间距）。在 `0302_pipeline5_fwd_noredirect.S` 中，测试全程不用 nop 隔离 RAW，但收尾仍保留若干 nop 作为合法指令填充，防止 testbench 取到空 ROM 产生误报。
- **测试结果串成累加链**：各场景结果最终汇总到同一个 PASS 值，任意关键路径出错都会影响最终写入结果。

## 5. trap smoke 测试 `已通过`

| 文件 | 验证内容 |
|---|---|
| `0501_trap_entry_smoke.S` | ECALL 触发 trap entry，跳转到 mtvec=0x80 的 handler，并由 handler 写 PASS |
| `0502_exception_full.S` | 全异常总测试：ECALL、EBREAK、非法指令（含全 0 编码、M 扩展、只读 CSR、未实现 CSR）、load/store address misaligned、JALR instruction address misaligned，共 9 个 step，handler 逐项检查 mcause/mepc/mtval 后 mret 返回，最终 score 计分 |
| `0503_csr_instr_test.S` | 6 条 Zicsr 指令独立测试：CSRRW/CSRRS/CSRRC 寄存器形式、CSRRWI/CSRRSI/CSRRCI 立即数形式、rs1=x0 不修改语义、uimm=0 写入 0，共 10 个 step 计分 |

## 6. SoC/MMIO 汇编测试 `已通过`

| 文件 | 验证内容 |
|---|---|
| `0601_soc_smoke.S` | SoC 级别冒烟 — 在 rv32i_soc 下跑通 ALU + DMEM 访存基线，确认 data_subsystem 未破坏 core 主路径 |
| `0602_uart_tx.S` | UART TX — 使能 UART、轮询 STATUS.ready、连续写 TXDATA 发送 "UART\n" 字符串 |
| `0603_gpio_rw.S` | GPIO 读写 — GPIO OUT/OE 写后读验证、GPIO IN 读回 TB 固定驱动值 0xA5A55A5A |
| `0604_mmio_access_fault.S` | MMIO access fault — 对未实现 MMIO 地址执行 load/store，验证 trap 正确捕获且 wrong-path store 被 kill。handler 检查 mcause/mepc/mtval 后 mret 返回 |
| `0605_mmio_misaligned_priority.S` | MMIO 异常优先级 — 对未映射地址执行不对齐 load/store，验证优先报 address misaligned（mcause=4/6）而非 access fault（5/7） |
| `0606_wrong_path_mmio.S` | wrong-path MMIO — taken branch 和 trap entry 后对 GPIO/UART/DMEM 的 wrong-path store 应被 flush/kill，不产生任何副作用 |

### 6.1 运行平台

当前所有汇编测试统一运行 SoC 仿真入口（`sim/soc_asm/`）。旧 core-only 仿真入口已删除，基础 ISA、流水线、trap 和 MMIO 测试都通过同一个 SoC testbench 回归。

### 6.2 测试框架说明

`0604`/`0605` 使用共享的 `SET_EXPECT`/`WRONG_PATH_STORE` 宏和 `check_step` 子程序：
- `SET_EXPECT` 将预期的 mcause/mepc/mtval/resume_pc 写入 DMEM，供 trap handler 检查。
- fault 指令后立即放置 `WRONG_PATH_STORE`，若被执行说明 trap 未 kill 年轻指令，直接 FAIL。
- `check_step` 验证 TRAP_SEEN=1 且 WRONG_PATH=0，通过后累加得分。

`0606` 使用更简单的单次 ECALL 触发 + handler 检查 mepc 后 mret 的方式。`0601`~`0603` 不涉及 trap，直接通过 MMIO 读写操作外设寄存器。

## 7. interrupt 定向测试 `已通过`

| 文件 | 验证内容 |
|---|---|
| `0705_interrupt_commit_precise.S` | CSR 写同拍 interrupt 精确提交语义 — pending 已存在时 CSRRS 使能 MIE，中断在 CSR 提交后同拍触发；同时覆盖 CSRW mtvec 同拍 interrupt 使用新 mtvec redirect；验证 mepc、store 提交和 redirect 目标 |
| `0706_mret_interrupt_reentry.S` | MRET 同拍 interrupt 重入 — handler 第一次不清 pending 直接 mret，MRET 边界 MPIE=1 导致立即重入第二次 handler；验证 MRET+interrupt 语义下两次 mcause/mepc 以及 entry/return 的 mstatus.MIE/MPIE |

### 7.1 CSR 写同拍 interrupt（0705）

```asm
csrrs x0, mstatus, MSTATUS_MIE    # 此时 MIE=0, MEIP=1
# 下一拍：CSR 提交后 MIE=1，trap_ctrl 同拍接受 interrupt
after_mie_enable:
```

CSRRS 使能 `mstatus.MIE` 时，硬件在同一 MEM 提交周期完成：
1. CSR 写提交 → `mstatus.MIE = 1`。
2. trap_ctrl 检测 `MIE=1 & MEIE=1 & MEIP=1` → irq_accept 成立。
3. 硬件写 `mepc = mem_interrupt_return_pc_i`（即 `after_mie_enable` 的地址）。
4. Kill IF/ID, ID/EX, EX/MEM；不 kill MEM/WB（CSR 写已提交）。

同一测试还覆盖 `csrw mtvec, xN` 与 interrupt 同拍成立的情况。测试先准备新 handler 地址并制造 GPIO pending，使 `csrw mtvec` 提交边界接受 interrupt；预期 redirect 使用提交后的新 `mtvec`，进入 `alt_trap_handler`，且 `mepc = after_mtvec_write`。

### 7.2 MRET 同拍 interrupt 重入（0706）

第一次 handler 收到 MEIP 后**不清 GPIO pending**，直接 mret：

```asm
first_entry:
    sw    x6, FIRST_MCAUSE_OFFSET(x20)
    sw    x7, FIRST_MEPC_OFFSET(x20)
    mret                              # 返回 + 立即重入
```

mret 在 MEM 提交时：`MIE <= MPIE = 1`。同拍 trap_ctrl 检测到 mret_accept + irq_request → 同一周期再次进入中断 entry。mepc 保持原值（仍是 `after_enable`），流水线不执行任何一条用户指令即重定向回 mtvec。第二次 handler 入口还会检查 `mstatus.MIE=0, MPIE=1`；第二次 handler 清 pending 后正常 mret 回到主流程，并检查最终 `mstatus.MIE=1, MPIE=1`。

## 8. AXI-Lite/APB 数据子系统集成测试 `已通过`

| 文件 | 验证内容 |
|---|---|
| `0801_dmem_wait_basic.S` | AXI-Lite DMEM 基本 load/store：SW/LW、SB/LB/LBU、SH/LH/LHU 的 `WSTRB` lane、符号/零扩展和基址+偏移访问 |
| `0802_dmem_wait_forwarding.S` | AXI-Lite DMEM 固定多周期访问下的 forwarding：load 后立即 ALU、store data 转发、load-use stall + MEM wait 和连续 load 链 |
| `0804_mmio_wait_access_fault.S` | GPIO0/UART0/TIMER0 未定义 offset 的 APB `PSLVERR` 经 AXI `SLVERR` 转精确 load/store access fault，并检查 faulting/wrong-path store 无副作用 |
| `0805_wait_interrupt_boundary.S` | AXI-Lite DMEM transaction outstanding 时 interrupt 不越过 older load，response 完成后在提交边界接受 timer interrupt，`mepc == after_wait_load` |

### 8.1 迁移说明

这些文件名沿用 0834 的 `wait` 命名以保持测试编号和回归入口稳定。0836 已删除统一 response-delay wrapper 和对应 mailbox 命令，测试不再配置固定 delay；当前延迟来自 adapter request 注册、AXI-Lite RAM 注册 response 以及 APB SETUP/ACCESS 等真实协议阶段。

### 8.2 当前验证边界

- **DMEM 基本访存**（0801）：验证 AXI-Lite RAM 的 read/write、`WSTRB` byte lane 和 CPU load 截取语义。
- **DMEM forwarding**（0802）：使用正常数据依赖链检查固定多周期 DMEM completion 期间的 MEM backpressure、load-use 和 forwarding。
- **MMIO access fault**（0804）：验证 APB 外设非法 offset 的 `PSLVERR` 经 bridge 返回 `SLVERR`，并在 MEM completion 边界形成精确异常。
- **Interrupt boundary**（0805）：在 older AXI-Lite DMEM load 完成前制造 MTIP，验证 core 不会提前进入 interrupt handler。

当前 SoC testbench 使用固定 readiness 的 AXI-Lite RAM 和固定 `PREADY=1` 外设。这组程序能够证明当前主线集成行为，不覆盖 AW/W 任意先后、各 channel 随机 backpressure 或多周期 `PREADY`。

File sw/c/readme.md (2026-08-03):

# 1 C 裸机测试计划

## 1.1 smoke 测试 `已通过`

| 文件 | 验证内容 |
|---|---|
| `0201_c_smoke.c` | C 入口、栈、函数调用、局部变量 — 最小 C 冒烟 |

测试逻辑：定义一个 `main()`，做简单加法后返回 0。如果 core 能正确执行 `crt0.S` → `main()` → 返回 → `crt0.S` 写 PASS 的完整流程，说明 C runtime 和 core 的基本配合正常。

## 1.2 dmem 初始化测试 `已通过`

| 文件 | 验证内容 |
|---|---|
| `0202_dmem_init.c` | `.rodata` 只读表初始化、`.data` 全局变量初始值和写回、`.bss` 清零、局部数组的栈上 load/store、函数调用传参和返回值 |

### 错误码对照

`0202_dmem_init.c` 每个检查点返回不同错误码，FAIL 时可根据返回值定位错误：

| 返回值 | 阶段 | 可能原因 |
|---|---|---|
| 1 | `.data` 初始值 | `+dmem=` 未加载或 `.data` 段顺序异常，`g_data` 不是 7 |
| 2 | `.bss` 清零 | `crt0.S` 的清零循环出错或未执行 |
| 3 | `.rodata` 读表 | `k_table` 初始值错乱，大概率 `+dmem=` 加载路径或格式问题 |
| 4 | `.data` 写回 | 全局变量 store 后 load 不对，检查 core 的 store 通路 |
| 5 | `.bss` 写回 | `.bss` 区域的 store 后 load 不对 |
| 6 | 栈上局部数组 | 栈帧分配或 sp 设置问题，`crt0.S` 的 sp 初始化是否正常 |
| 7 | 函数调用 + ABI | `main()` 调 `add3()` 传入参数或取回返回值有误 |

---

## 1.3 跳过

## 1.4 综合控制流测试 `已通过`

| 文件 | 验证内容 |
|---|---|
| `0401_control_mix.c` | .data/.bss/.rodata、嵌套循环冒泡排序、函数调用栈、byte/halfword 访存、分支密集路径 |

### 错误码对照

`0401_control_mix.c` 错误码从 1~10 逐步收敛：

| 返回值 | 阶段 | 可能原因 |
|---|---|---|
| 1 | `.bss` 检查 | `g_sink` 非零 — `.bss` 未清零 |
| 2~4 | 全局 Work/Bytes/Halves 初始化 | `.bss` 清零未覆盖到对应数组 |
| 5 | 冒泡排序正确性 | 排序结果无序 — 存/取或分支跳转有误 |
| 6 | `fold_step` 累加结果 | 函数调用或运算逻辑出错 |
| 7 | Byte 操作 | `g_bytes` 的 byte store/load 通路 |
| 8 | Halfword 操作 | `g_halves` 的 halfword store/load 通路 |
| 9 | `branch_mix` 三次调用 | 分支密集函数的返回值 |
| 10 | `g_sink` 写回验证 | .data 段的 store 后 load |

---

## 1.5 trap smoke 测试 `已通过`

| 文件 | 验证内容 |
|---|---|
| `0551_trap_smoke.c` | 共享 C trap 入口、ECALL、`mcause/mepc/mtval` 读取、C handler 返回后 `mret` 回主流程 |

`crt0.S` 固定提供 `.text.trap` 入口，并定义弱符号 `__trap_handler_c`。普通 C 测试不需要关心它；需要处理 trap 的测试提供同名强定义即可覆盖默认 handler。

`0551_trap_smoke.c` 的 handler 记录 `mcause/mepc/mtval`，对 ECALL 返回 `mepc + 4`。`main()` 在 `ecall` 后继续执行并检查记录值，全部正确时返回 0。

---

## 1.6 SoC MMIO 测试 `已通过`

| 文件 | 验证内容 |
|---|---|
| `0651_soc_mmio_smoke.c` | 通过 `platform.h` 封装函数访问 GPIO/UART MMIO，验证 GPIO OUT/OE 写后读、GPIO IN 只读、UART 使能/状态查询/TX 发送 |
| `0652_soc_mmio_gpio_uart.c` | GPIO bit 级独立验证（OUT/OE 互不影响、IN 只读）、UART 多字符串发送 |

SoC 平台提供 `sw/include/platform.h`，封装了 `mmio_read32`/`mmio_write32` 等 MMIO 访问原语。C 程序直接调用这些函数操作外设寄存器，无需内联汇编。

`0651_soc_mmio_smoke.c` 的测试顺序：GPIO OUT 写 0x12345678 → 读回验证 → GPIO OE 写 0x0000ffff → 读回验证 → GPIO IN 读回 0xA5A55A5A → UART 使能 → 读 STATUS.ready → 通过 uart_putc 发送 "SOC\n"。全部正确时返回 0。

`0652_soc_mmio_gpio_uart.c` 在 0651 基础上进一步验证外设寄存器独立性：Stage1~2 做 GPIO 全 bit 翻转（`0xAAAAAAAA` / `0x55555555` 覆盖 OUT，`0x0000FFFF` / `0xFFFF0000` 覆盖 OE）；Stage3~4 验证 OUT 和 OE 互不影响；Stage5 写 IN 地址后读回确认仍为 0xA5A55A5A；Stage6 连续发送 3 个字符串验证 UART TX 稳定性。全部正确时返回 0。

---

## 1.7 interrupt 测试 `已通过`

| 文件 | 验证内容 |
|---|---|
| `0751_timer_smoke.c` | 最小 timer interrupt — 配置 TIMER0、开中断、handler 关定时器清 pending、main 检测 flag 后 return 0 |
| `0752_gpio_irq_basic.c` | GPIO0 外部中断基础行为 — IRQ_EN/IRQ_STATUS 关系、上升/下降/高/低电平四类触发、IRQ_PENDING R/W1C、handler 确认 mcause=MEIP |
| `0753_uart_rx_irq.c` | UART0 RX 中断 — TB 注入 RX 字节、RXDATA/STATUS/IRQ_PENDING 同步更新、CTRL.rx_irq_enable 门控、读 RXDATA 清 pending、W1C 只清 pending 不消耗数据 |
| `0754_external_timer_priority.c` | MEIP/MTIP 优先级 — 同时制造 GPIO external pending 和 timer pending，同时开 MEIE+MTIE，验证 first trap 选择 MEIP（MEIP > MTIP）；handler 清 external 后 timer 在第二次进入处理 |
| `0757_gpio_periodic_irq.c` | TB 固定周期 GPIO 输入精确测量 — 用 TIMER0.MTIME 测量 bit30/bit31 边沿间隔，通过 UART TX 输出测量报告，验证快周期均值 ≈ 500、慢周期均值 ≈ 2000、周期比值为 4 |

用 `platform.h` 封装的 CSR 访问函数（`csr_write_mie`、`csr_set_mstatus` 等），不再在测试 .c 内重复定义内联汇编。

- `0751` 测试顺序：关全局中断 → 清 `mie` → 配置 `MTIMECMP=16`、`MTIME=0` → 写 `mie.MTIE` → 开启 timer → 开全局中断 → 等待 handler 置 flag。handler 写 `CTRL=0` 停 timer（`MTIP` 随 `CTRL.enable=0` 变为 0），完成 level pending 清除。
- `0752` 分 6 stage，每 stage 使用不同 GPIO bit。Stage1 轮询验证 IRQ_EN+IRQ_STATUS 关系；Stage2~5 分别验证上升沿、下降沿、高电平、低电平四类触发进入 MEIP handler；Stage6 验证 IRQ_PENDING R/W1C 与 IRQ_EN 的联动。handler 通过关 IRQ_EN 阻止电平重触发。
- `0753` 分 3 stage。Stage1 验证 TB 注入后 RXDATA/STATUS/IRQ_PENDING 同步变化；Stage2 验证 rx_irq_enable=0 时 pending 可置位但不驱动中断，使能后中断触发；Stage3 验证 W1C 只清 pending 不消费 RXDATA，读 RXDATA 同时清 rx_valid 和 pending。
- `0754` 先在 MIE=0 下同时置 GPIO pending 和 timer pending（MTIMECMP=1），验证入口 mip 同时有 MEIP 和 MTIP；开 MIE 后第一拍进 MEIP handler，清 GPIO 后 mip.MEIP=0、MTIP 仍为 1；第二拍进 MTIP handler 停 timer。
- `0757` 利用 TB 固有周期翻转（bit30 每 500 拍翻转、bit31 每 2000 拍翻转）作为中断源，用 TIMER0.MTIME 精确测量边沿间隔。handler 记录每个 bit 的首末次 MTIME，main 计算平均间隔 `avg = (last - first) / (count - 1)` 并通过 UART TX 输出。500 拍快周期长于当前完整 C handler 的处理时间，避免 pending 合并；收口日志为 bit30 avg=500、bit31 avg=2000、ratio=4。

---

## 1.8 AXI-Lite/APB 数据子系统集成测试 `已通过`

| 文件 | 验证内容 |
|---|---|
| `0853_mmio_wait_basic.c` | 固定 `PREADY=1` 下验证 GPIO0/UART0/TIMER0 经 AXI-Lite-to-APB4 链路访问正确，PENDING/W1C、UART TX、RXDATA 读清和 TIMER MTIP 等副作用只发生一次 |
| `0856_wait_mixed_random_smoke.c` | 交替执行 AXI-Lite DMEM 运算、APB GPIO 中断、UART RX 和 TIMER0 操作，验证 router 跨 target 切换时不串响应、不死锁且软件可见语义不变 |

### 迁移说明

两个文件名沿用 0834 的 `wait`/`random` 命名以保持测试编号和回归入口稳定。0836 已删除统一 response-delay wrapper、delay mailbox 和对应 C helper；当前测试不再配置每个 target 的人工延迟。

### 当前验证口径

- **APB 外设与副作用**（0853）：验证 bridge、APB mux、register adapter 和三个外设的端到端功能，外设固定 `PREADY=1`。
- **DMEM/MMIO 混合路由**（0856）：验证外部 AXI-Lite DMEM 与内部 APB 外设之间连续切换，不依赖固定周期计数。

### 注意事项

- AXI-Lite RAM 使用固定 readiness 和注册式 response，APB 外设固定 `PREADY=1`；现有程序不覆盖 AW/W 任意先后、独立 channel 随机 backpressure 或多周期 `PREADY`。
- `tb_rv32i_soc_test.h` 当前只保留 GPIO 和 UART RX 外部激励 helper，不属于 SoC ABI。

# 2 TB mailbox 机制与 C 测试编程

## 2.1 什么是 TB mailbox

TB mailbox（testbench 邮箱）是 `tb_rv32i_soc.sv` 提供的一种**软件→硬件激励**的单向通信机制。C 测试程序通过 DMEM store 向特定地址写入数据，testbench 在每拍监控这些地址的写入操作，检测到后驱动对应的外部激励信号：

```text
C 测试程序                       tb_rv32i_soc.sv
    │                                 │
    ├─ sw DMEM[0x180] = mask ─────--> ├─ gpio0_set(mask)    → GPIO 输入拉高
    ├─ sw DMEM[0x184] = mask ─────--> ├─ gpio0_clear(mask)  → GPIO 输入拉低
    ├─ sw DMEM[0x188] = cmd   ─────-> ├─ gpio0_pulse(cmd)   → GPIO 输入脉冲
    └─ sw DMEM[0x18c] = data  ─────-> ├─ uart0_rx(data)     → UART0 注入 RX 字节
```

这些地址被定义在 `TB_CMD_BASE = DMEM_BASE + 0x180` 的连续区域内，由 `tb_rv32i_soc_test.h` 提供宏定义：

```c
#define TB_GPIO0_SET_MASK_ADDR   (TB_CMD_BASE + 0x00)  // 写 mask, TB 驱动对应 GPIO 输入为高
#define TB_GPIO0_CLR_MASK_ADDR   (TB_CMD_BASE + 0x04)  // 写 mask, TB 驱动对应 GPIO 输入为低
#define TB_GPIO0_PULSE_CMD_ADDR  (TB_CMD_BASE + 0x08)  // 写 packed command, 驱动 GPIO 脉冲
#define TB_UART0_RX_ADDR         (TB_CMD_BASE + 0x0c)  // 写 byte[7:0], TB 注入 UART RX 字节
```

TB mailbox 地址位于 DMEM 的已实现区域，**不是硬件 MMIO 寄存器**。写入这些地址就是一次普通的 DMEM store，经 CPU adapter、AXI-Lite router 到达 testbench 中的 `axi_lite_ram`。testbench 观察完成的外部 DMEM write，并执行对应的激励任务。

## 2.2 为什么需要 TB mailbox

SoC 仿真中的外部激励（GPIO 输入变化、UART RX 字节注入、TIMER 计数调整等）不能由被测 core 直接驱动。通常的做法有两种：

1. **在 testbench 中用 SystemVerilog task 直接驱动** — 需要修改 TB 代码，重新编译，不够灵活。
2. **通过 TB mailbox 由软件触发** — 测试程序运行中动态控制激励，无需重新编译 TB。

本项目采用方案 2。TB mailbox 让 C 测试程序在 `main()` 中直接控制 testbench 行为，把"GPIO 输入拉高""注入 UART RX 数据"等操作变成普通的函数调用，不需要理解 SystemVerilog。

## 2.3 如何在 C 测试中使用 TB mailbox

**步骤 1：包含头文件**

```c
#include "platform.h"              // MMIO 基地址、寄存器 offset、CSR 操作函数
#include "tb_rv32i_soc_test.h"     // TB mailbox 地址、GPIO/UART helper 函数
```

**步骤 2：调用 helper 函数**

`tb_rv32i_soc_test.h` 提供面向语义的封装函数，C 测试直接调用即可：

```c
// GPIO 输入控制
tb_gpio0_set_mask(0x01u);          // GPIO bit0 输入拉高
tb_gpio0_clear_mask(0x01u);        // GPIO bit0 输入拉低
tb_gpio0_pulse(0, 10, true);       // GPIO bit0 高脉冲，持续 10 拍

// UART RX 注入
tb_uart0_rx('A');                  // TB 向 UART0 注入一个 RX 字节 'A'
```

这些 helper 函数的实现都是对 TB mailbox 地址执行普通的 `mmio_write32`。例如：

```c
static inline void tb_gpio0_set_mask(uint32_t mask)
{
    mask &= ~(TB_GPIO0_FAST_PERIODIC_MASK | TB_GPIO0_SLOW_PERIODIC_MASK);
    mmio_write32(TB_GPIO0_SET_MASK_ADDR, mask);
}
```

**步骤 3：等待激励生效**

TB mailbox 的激励不是立即生效的。GPIO 输入变化经过 TB 驱动、两级同步后才被 core 采样到。因此发出激励后需要插入适当的等待：

```c
tb_gpio0_clear_mask(1u);           // 先确保 GPIO bit0 为低
wait_cycles(20u);                   // 等待同步稳定
mmio_write32(gpio_reg(GPIO0_BASE, GPIO_IRQ_PENDING_OFFSET), 1u);  // 软件置 pending
tb_gpio0_set_mask(1u);             // GPIO bit0 上升沿
wait_cycles(30u);                   // 等待 TB 驱动 + 两级同步 + 中断响应
val = mmio_read32(gpio_reg(GPIO0_BASE, GPIO_IRQ_STATUS_OFFSET));  // 检查结果
```

`wait_cycles` 是一个简单的忙等循环，用于消耗足够的周期让 TB 信号传播。等待长度取决于具体场景，需要根据 TB 的同步级数、中断处理时间和测试目标调整。

## 2.4 TB mailbox 限制

- **单次激励**：每次写入触发一次操作。例如 `tb_gpio0_set_mask` 只在对应 DMEM store 完成后驱动一次 GPIO 输入变化，不会持续重复触发。如果需要持续维持某个值，测试程序需要确保后续没有其他写操作改写 TB 的内部激励状态。
- **不允许写 bit[31:30]**：GPIO bit[31:30] 由 TB 固定驱动（周期翻转），C 测试的 `tb_gpio0_set_mask` 和 `tb_gpio0_clear_mask` 自动屏蔽这两个 bit。
- **激励不是硬件状态**：TB mailbox 地址不是可读寄存器，写入后无法通过读同一地址确认激励已生效。
- **监听基于完成的 DMEM write**：testbench 从外部 AXI-Lite RAM 路径识别 mailbox store，因此一次软件 store 最多产生一次激励。

## 2.5 典型测试模式

使用 TB mailbox 的 C 测试通常遵循以下模式：

```c
int main(void)
{
    uint32_t val;
    uint32_t errors = 0u;

    // 1. 关中断，安全初始化
    csr_clear_mstatus(MSTATUS_MIE);
    csr_write_mie(0u);

    // 2. 通过 TB mailbox 设置外部输入初始值
    tb_gpio0_clear_mask(1u);

    // 3. 写 MMIO 寄存器，配置外设
    mmio_write32(gpio_reg(GPIO0_BASE, GPIO_IRQ_EN_OFFSET), 1u);

    // 4. 通过 TB mailbox 驱动激励，等待后检查结果
    tb_uart0_rx((uint8_t)'R');
    wait_cycles(20u);
    val = mmio_read32(uart_reg(UART0_BASE, UART_RXDATA_OFFSET));
    if (val != (uint32_t)'R') {
        errors |= (1u << 0);
    }

    // 5. 清理本测试改变的外部输入
    tb_gpio0_clear_mask(1u);

    return (errors != 0u) ? 1 : 0;
}
```

# 3 C 与汇编测试的分工

汇编测试逐个覆盖 RISC-V ISA 的边缘情况。C 测试不追求指令覆盖，而是验证 **C 编译器生成的正常指令流** 在 core 上能正确运行：

| | 汇编测试 | C 测试 |
|--|---|---|
| 关注点 | 每条指令的编码和结果 | C runtime + 编译器生成代码的整体正确性 |
| 指令流 | 手写，精确控制 | gcc 编译生成，含栈帧/传参/地址加载等 |
| 数据初始化 | 手动构造 | `.rodata`/`.data`/`.bss` 由 linker + crt0 处理 |
| PASS/FAIL | 内联写 DMEM | `crt0.S` 统一根据 `main()` 返回值写 |
| 排错方式 | 看 dump 对比预期 | 先用错误码缩小范围，再看 dump |

**关键区别**：汇编测试通过 `bne x5, x6, fail` 自检，结果由程序自己判断。C 测试只写 `return N`，由 `crt0.S` 统一判断 `x10/a0` 后写 `TEST_STATUS_ADDR`。

# 4 crt0.S 启动流程

```
_start
  │
  ├─ .text.trap 固定提供 trap entry
  │       └─ trap 时保存寄存器，调用 __trap_handler_c，写 mepc，mret
  ├─ 设置 sp = __stack_top
  ├─ 清零 .bss 段 (__bss_start ~ __bss_end)
  ├─ jal x1, main
  │       │
  │       └─ main() 返回 0 → 写 1 (PASS)
  │                   返回非0 → 写 2 (FAIL)
  └─ 无限 loop
```

C 程序永远不直接写 `TEST_STATUS_ADDR(0x00040100)`。（但不是硬件保护，野指针等可能导致被写入）

默认 `__trap_handler_c` 会写 FAIL 并停住，表示普通 C 程序不期望发生 trap。专门的 trap 测试可以实现自己的 `__trap_handler_c(unsigned int mcause, unsigned int mepc, unsigned int mtval)`，返回值会被 `crt0.S` 写入 `mepc`，随后执行 `mret`。

## 4.1 依赖关系

```
0201_c_smoke.c
  └─→ 0202_dmem_init.c  (依赖 crt0 + .data/.bss 通路正常)
```

两个测试都依赖同一个 `crt0.S` 和 `c_baremetal.ld`。如果两个都 FAIL，优先检查：
1. `crt0.S` 是否正常执行到 `main()`（dump 确认 PC 路径）
2. `+dmem=` 是否加载（FAIL 且错误码为 1，说明 `.data` 没初始化）
3. linker 的 `__bss_start`/`__bss_end` 符号是否与 `.bss` 段匹配（`readelf -S` 检查）

## 4.2 编写 C trap handler 测试

crt0.S 已提供完整的 trap 入口，C 测试只需提供 `__trap_handler_c` 强定义即可接管异常。

### 函数原型

```c
unsigned int __trap_handler_c(unsigned int mcause,
                              unsigned int mepc,
                              unsigned int mtval);
```

- `mcause`：`csrr mcause` 的值（异常原因编码）。
- `mepc`：`csrr mepc` 的值（fault 指令 PC）。
- `mtval`：`csrr mtval` 的值（异常附加信息）。
- **返回值**：写入 `mepc` 的值，随后 crt0.S 执行 `mret`。通常传入 `mepc + 4` 跳过 fault 指令，或传入 `resume_pc` 继续执行。

注意：handler 运行在 machine mode，返回后自动 `mret`。crt0.S 的 `.text.trap` 入口已保存/恢复全部 GPR，handler 内读写全局变量安全。

### 参考步骤

以 `0551_trap_smoke.c` 为例，编写一个 C trap handler 测试的流程：

1. **定义全局变量**保存 handler 读到的 CSR 值：
   ```c
   static volatile unsigned int trap_seen;      // 调用计数
   static volatile unsigned int trap_mcause;    // mcause 记录值
   ```

2. **提供 `__trap_handler_c` 强定义**：
   ```c
   unsigned int __trap_handler_c(unsigned int mcause, unsigned int mepc, unsigned int mtval)
   {
       trap_seen = trap_seen + 1u;
       trap_mcause = mcause;
       return mepc + 4u;   // 跳过 ecall，继续执行
   }
   ```

3. **在 `main()` 中触发异常**。fault 指令会打断 C 的正常控制流，需用内联汇编精确嵌入：
   ```c
   __asm__ volatile (
       "1:\n"
       "ecall\n"
       : : : "memory"
   );
   ```
   若需要获取 fault 指令的 PC 以验证 `mepc`，参见 `0551_trap_smoke.c` 中局部 label + `%hi/%lo` 的手法。

4. **在 `main()` 中检查 handler 记录的值**，参考 `0551_trap_smoke.c` 逐项检查、不同错误返回不同 error_code 的模式。

### 内联汇编注意事项

- ecall/ebreak 后面的 C 代码能否执行到，取决于 `__trap_handler_c` 返回的 mepc。
- `"memory"` clobber 保证 `trap_seen` 等全局变量在读检查前被重新加载。
- trap 测试的全局变量必须用 `volatile` 声明，防止编译器优化掉跨 ecall 的读写。

### 运行方式

```bash
sim/soc_c/run_test.sh 0551
```

### 日志预期

```
[..] @ ..: PC=0x800000.. Instr=0x00000073 INSTR_ECALL   noWB
^^^^^^^^^^ this cycle happen trap_entry  ^^^^^^^^^^
...
PASS after N cycles
```

### 实现示例

| 文件 | 验证内容 |
|---|---|
| `0551_trap_smoke.c` | ECALL 触发 → handler 检查 mcause/mepc/mtval → mret 回 main → 逐项检查 |

## 4.3 编写 C MMIO 测试

SoC 平台提供 `sw/include/platform.h`，封装了 GPIO/UART/TIMER32 的 MMIO 地址、offset、bit mask 和基础读写函数。

### MMIO 辅助 API

所有操作通过 `volatile` 指针直接访存，无需 trap handler：

```c
// 核心读写函数
uint32_t mmio_read32(uint32_t addr);
void     mmio_write32(uint32_t addr, uint32_t value);

// GPIO 寄存器地址计算
uint32_t gpio_reg(uint32_t base, uint32_t offset);   // base + offset
// GPIO_OUT_OFFSET = 0x000, GPIO_IN_OFFSET = 0x004, GPIO_OE_OFFSET = 0x008

// UART 寄存器地址计算
uint32_t uart_reg(uint32_t base, uint32_t offset);
// UART_TXDATA_OFFSET = 0x000, UART_STATUS_OFFSET = 0x004, UART_CTRL_OFFSET = 0x008,
// UART_RXDATA_OFFSET = 0x00c, UART_IRQ_PENDING_OFFSET = 0x010

// UART 便捷函数
void uart_enable_tx(uint32_t base);   // 写 UART_CTRL_ENABLE
void uart_putc(uint32_t base, char ch);  // 忙等 READY 后发字符
```

### 参考步骤

以 `0651_soc_mmio_smoke.c` 为例，编写一个 C MMIO 测试的流程：

1. **包含头文件**：
   ```c
   #include "platform.h"
   ```

2. **GPIO OUT/OE 写后读验证**：
   ```c
   mmio_write32(gpio_reg(GPIO0_BASE, GPIO_OUT_OFFSET), 0x12345678u);
   value = mmio_read32(gpio_reg(GPIO0_BASE, GPIO_OUT_OFFSET));
   if (value != 0x12345678u) return 1;
   ```
   写 `GPIO_OUT` 寄存器，读回确认。不同的检查点返回不同错误码。

3. **GPIO IN 只读验证**（由 testbench 驱动固定值）：
   ```c
   value = mmio_read32(gpio_reg(GPIO0_BASE, GPIO_IN_OFFSET));
   if (value != 0xa5a55a5au) return 3;
   ```

4. **UART 使能与状态检查**：
   ```c
   uart_enable_tx(UART0_BASE);                                     // 写 CTRL
   value = mmio_read32(uart_reg(UART0_BASE, UART_STATUS_OFFSET));
   if ((value & UART_STATUS_READY) == 0u) return 4;             // 检查 READY
   ```

5. **UART TX 发送字符**（SoC testbench 会打印到终端）：
   ```c
   uart_putc(UART0_BASE, 'S');
   uart_putc(UART0_BASE, 'O');
   uart_putc(UART0_BASE, 'C');
   uart_putc(UART0_BASE, '\n');
   ```

### 运行方式

```bash
# SoC 仿真（含 MMIO 外设）
sim/soc_c/run_test.sh 0651
```

### 日志预期

```
...
[..]*******[UART_TX_EVENT] uart0_tx_data:0x53('S')*******
[..]*******[UART_TX_EVENT] uart0_tx_data:0x4f('O')*******
[..]*******[UART_TX_EVENT] uart0_tx_data:0x43('C')*******
[..]*******[UART_TX_EVENT] uart0_tx_data:0x0a('
')*******
...
PASS after N cycles
```

### 注意事项

- 当前所有 C 测试统一使用 SoC 仿真入口（`sim/soc_c/`）。旧 core-only 仿真入口已删除。
- 当前 MMIO 经 AXI-Lite-to-APB4 bridge 访问，正式外设固定 `PREADY=1`；`mmio_read32` 仍会等待 adapter、APB SETUP/ACCESS 和 response 完成后返回。
- `GPIO_IN` 的值由 testbench 驱动，C 程序只能读不能写。
- UART 的 `uart_putc` 包含忙等循环，测试的是 UART STATUS 寄存器的正确性。

### 实现示例

| 文件 | 验证内容 |
|---|---|
| `0651_soc_mmio_smoke.c` | GPIO OUT/OE 写后读、GPIO IN 只读验证、UART 使能/状态查询/TX 发送 |
| `0652_soc_mmio_gpio_uart.c` | GPIO bit 级操作、OUT/OE 独立验证、IN 只读确认、UART 多字符串发送 |
# 5 C 裸机约束

- 不使用标准库、`printf`、`malloc`、系统调用。
- 普通 C 测试不主动触发异常或访问 CSR；专门的 trap/CSR 测试除外。
- 不使用乘除法（RV32I 不含 M 扩展）。
- 不主动、故意写地址 `0x00040100`。
- 全局变量可以使用；`.rodata`/`.data` 通过 `dmem.mem` 初始化，`.bss` 由 `crt0.S` 进入 `main` 前清零。

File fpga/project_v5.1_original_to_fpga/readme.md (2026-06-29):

# v5.1 从仿真工程到 FPGA 上板工程

本目录归档 RV32I SoC v5.1 从仿真器验证工程迁移到 FPGA 上板工程的完整材料。这里保留两个并列工程：一个是迁移前的 original 版本，一个是面向 E10 `EP4CE10F17C8` 系统板的 FPGA 版本。

## 目录结构

```text
project_v5.1_original_to_fpga/
+-- readme.md
+-- docs/
+-- project_v5.1_original/
`-- project_v5.1_fpga/
```

| 路径 | 内容 |
| --- | --- |
| [project_v5.1_original](project_v5.1_original/) | v5.1 原始工程，面向 Verilator/仿真器验证，保留原始 RTL、仿真脚本和测试程序。 |
| [project_v5.1_fpga](project_v5.1_fpga/) | v5.1 FPGA 上板工程，包含 E10 顶层、FPGA memory wrapper、Quartus 工程、C 镜像脚本和上板 demo。 |
| [docs](docs/) | v5.1 专项说明文档目录。除本入口 `readme.md` 外，较细的迁移、软件、编译和边界说明统一放在这里。 |

## 阶段结论

v5.1 FPGA 版本已经完成最小上板闭环：

- CPU core RTL 保持不改。
- SoC MMIO 地址图保持不改。
- IMEM/DMEM 缩小到各 16 KiB（方便适配当前工程和FPGA资源的最小改动）。
- 新增 E10 FPGA top、IMEM/DMEM FPGA wrapper、UART TX/RX PHY 和 Quartus 工程。
- C 程序镜像可生成 `current_imem.mem` 与 `current_dmem.mif`，并随 Quartus 编译打包进 `.sof`。
- 已完成 GPIO、KEY、TIMER polling、interrupt 等板级验证。
- FPGA block RAM 同步读与仿真 RAM 组合读时序行为不一致，会导致的中断栈恢复问题。

## 综合与时序结果

当前 Quartus 编译报告来自 `project_v5.1_fpga/fpga/quartus/output_files/`。

| 项目 | 结果 |
| --- | --- |
| Quartus 版本 | Quartus Prime Lite 25.1std.0 Build 1129 |
| 编译状态 | Successful |
| 顶层模块 | `e10_rv32i_top` |
| 目标器件 | `EP4CE10F17C8` |
| Logic elements | 5,184 / 10,320，约 50% |
| Registers | 2,488 |
| Pins | 8 / 180，约 4% |
| Memory bits | 262,144 / 423,936，约 62% |
| Embedded multiplier | 0 / 46 |
| PLL | 0 / 2 |
| 50 MHz setup slack | +1.008 ns，Slow 1200 mV 85 C model |
| 50 MHz hold slack | +0.452 ns，Slow 1200 mV 85 C model |
| 理论最高频率粗算 | 约 52.65 MHz |

该结果说明当前工程可以 fit 到 EP4CE10F17C8，并满足 50 MHz 板载时钟约束。按最差 setup slack 粗略估算，当前关键路径延迟约为 `20.000 ns - 1.008 ns = 18.992 ns`，对应理论最高频率约 `1 / 18.992 ns = 52.65 MHz`。这个数字只用于理解当前 50 MHz 约束下的余量，不等价于重新约束后的正式 Fmax；后续若继续增加外设或扩展 RAM/总线，应重新查看完整 STA report，而不是沿用本次余量。

## 板级验证结果

已在 FPGA 上完成的最小验证：

| 程序/场景 | 验证内容 | 结论 |
| --- | --- | --- |
| `0500` GPIO LED | 软件延时驱动 LED 交替闪烁 | 通过 |
| `0501` smoke | C 裸机程序、GPIO、UART MMIO 写路径 | 通过 |
| `0502` key/LED | GPIO input/output 与按键电平读取 | 通过 |
| `0503` timer polling | TIMER0 计数器轮询 | 通过 |
| `0504` timer interrupt | TIMER0 中断、trap entry、C handler、mret 返回 | 通过 |
| `0505` 综合 | GPIO、KEY、TIMER、UART MMIO 和中断组合使用 | 通过 |

本阶段最关键的问题闭环是 DMEM FPGA wrapper。原仿真 RAM 近似组合读，而 FPGA M9K 是同步读；简单轮询程序可能不暴露问题，但中断入口会大量使用栈保存/恢复寄存器。将 FPGA DMEM 访问时序改为与 CPU 固定访存假设匹配后，中断程序恢复正常。

## 配套文档

`readme.md` 作为阶段入口，汇总目标、目录、结论、资源占用和板级验证结果，不再单独规划 bring-up summary 或 verification report。下面四篇配套文档补齐：

| 文档 | 内容 |
| --- | --- |
| [docs/01_v5.1_rtl_migration_notes.md](docs/01_v5.1_rtl_migration_notes.md) | 说明 RTL 迁移目标、不变边界、逐文件变更表、FPGA memory wrapper、UART ready 握手和 DMEM 同步读时序问题。 |
| [docs/02_v5.1_software_memory_map_and_c_flow.md](docs/02_v5.1_software_memory_map_and_c_flow.md) | 说明 v5.1 软件侧地址图、`platform.h` 同步项、C 裸机规则、`mem/mif` 镜像生成流程。 |
| [docs/03_v5.1_quartus_compile_and_download.md](docs/03_v5.1_quartus_compile_and_download.md) | 说明 v5.1 Quartus 工程编译、SOF 生成、Programmer 下载、更新 C 镜像后重新编译的操作流程。 |
| [docs/04_v5.1_known_limits_and_next_steps.md](docs/04_v5.1_known_limits_and_next_steps.md) | 记录 v5.1 当前边界、未验证项、非通用假设和后续可扩展方向。 |

## 阅读顺序

建议先看根目录 [readme.md](../readme.md) 了解通用上板方法和工具依赖，再回到本目录阅读 v5.1 专项材料。理解 RTL 迁移时优先阅读 `docs/01_v5.1_rtl_migration_notes.md`；实际重新构建和下载时阅读 `docs/02` 到 `docs/03`；评估后续扩展时阅读 `docs/04`。

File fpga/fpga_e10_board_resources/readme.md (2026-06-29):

# FPGA E10 系统板资料

本目录归档正点原子 E10 最小系统板相关资料，用于 RV32I SoC 以及后续其他 RTL 版本的 FPGA 上板验证。当前使用的 FPGA 器件为 Intel Cyclone IV E `EP4CE10F17C8`。

这里主要保存板卡与器件资料，不放具体 RTL 版本的改造说明。具体工程如何使用这些资源，请查看对应版本目录下的上板文档。

## 目录结构

```text
fpga_e10_board_resources/
+-- 01_FPGA/
+-- 03_SDRAM/
+-- 04_FLASH/
+-- 05_UART/
+-- 1_正点原子E10最小系统板入门资料/
`-- 3_正点原子E10最小系统板原理图/
```

| 路径 | 内容 |
| --- | --- |
| [01_FPGA](01_FPGA/) | Cyclone IV / EP4CE10 器件手册、引脚资料和产品表。 |
| [03_SDRAM](03_SDRAM/) | 板载 SDRAM 芯片资料。 |
| [04_FLASH](04_FLASH/) | 板载 SPI Flash 芯片资料。 |
| [05_UART](05_UART/) | 板载 USB-UART / CH340 相关资料。 |
| [1_正点原子E10最小系统板入门资料](1_%E6%AD%A3%E7%82%B9%E5%8E%9F%E5%AD%90E10%E6%9C%80%E5%B0%8F%E7%B3%BB%E7%BB%9F%E6%9D%BF%E5%85%A5%E9%97%A8%E8%B5%84%E6%96%99/) | E10 最小系统板入门教程和 FAQ。 |
| [3_正点原子E10最小系统板原理图](3_%E6%AD%A3%E7%82%B9%E5%8E%9F%E5%AD%90E10%E6%9C%80%E5%B0%8F%E7%B3%BB%E7%BB%9F%E6%9D%BF%E5%8E%9F%E7%90%86%E5%9B%BE/) | E10 原理图、IO 分配表、官方 IO TCL 和板框 DXF。 |

## 关键资料

| 文件 | 用途 |
| --- | --- |
| [01_FPGA/Cyclone IV EP4CE10引脚信息.pdf](01_FPGA/Cyclone%20IV%20EP4CE10%E5%BC%95%E8%84%9A%E4%BF%A1%E6%81%AF.pdf) | EP4CE10 引脚信息。 |
| [01_FPGA/Cyclone IV器件手册.pdf](01_FPGA/Cyclone%20IV%E5%99%A8%E4%BB%B6%E6%89%8B%E5%86%8C.pdf) | Cyclone IV 英文器件手册。 |
| [01_FPGA/Cyclone IV 中文手册.pdf](01_FPGA/Cyclone%20IV%20%E4%B8%AD%E6%96%87%E6%89%8B%E5%86%8C.pdf) | Cyclone IV 中文器件手册。 |
| [01_FPGA/cyclone-iv-product-table.pdf](01_FPGA/cyclone-iv-product-table.pdf) | Cyclone IV 产品资源表。 |
| [3_正点原子E10最小系统板原理图/E10最小系统板原理图_V1.1.pdf](3_%E6%AD%A3%E7%82%B9%E5%8E%9F%E5%AD%90E10%E6%9C%80%E5%B0%8F%E7%B3%BB%E7%BB%9F%E6%9D%BF%E5%8E%9F%E7%90%86%E5%9B%BE/E10%E6%9C%80%E5%B0%8F%E7%B3%BB%E7%BB%9F%E6%9D%BF%E5%8E%9F%E7%90%86%E5%9B%BE_V1.1.pdf) | E10 最小系统板原理图。 |
| [3_正点原子E10最小系统板原理图/E10最小系统板IO分配表.xlsx](3_%E6%AD%A3%E7%82%B9%E5%8E%9F%E5%AD%90E10%E6%9C%80%E5%B0%8F%E7%B3%BB%E7%BB%9F%E6%9D%BF%E5%8E%9F%E7%90%86%E5%9B%BE/E10%E6%9C%80%E5%B0%8F%E7%B3%BB%E7%BB%9F%E6%9D%BFIO%E5%88%86%E9%85%8D%E8%A1%A8.xlsx) | E10 最小系统板 IO 分配表。 |
| [3_正点原子E10最小系统板原理图/E10_MicroSYS_IO.tcl](3_%E6%AD%A3%E7%82%B9%E5%8E%9F%E5%AD%90E10%E6%9C%80%E5%B0%8F%E7%B3%BB%E7%BB%9F%E6%9D%BF%E5%8E%9F%E7%90%86%E5%9B%BE/E10_MicroSYS_IO.tcl) | 官方 Quartus TCL 引脚分配参考，可按工程端口名改写到 QSF。 |
| [05_UART/CH340.pdf](05_UART/CH340.pdf) | 板载 USB-UART 芯片资料。 |
| [03_SDRAM/W9825G6KH.pdf](03_SDRAM/W9825G6KH.pdf) | 板载 SDRAM 芯片资料。 |
| [04_FLASH/W25Q16JVSSIQ.pdf](04_FLASH/W25Q16JVSSIQ.pdf) | 板载 SPI Flash 芯片资料。 |

## 存储资源

E10 最小系统板同时包含 FPGA 片内存储资源和板载外部存储芯片。片内 M9K 适合做小容量、低延迟的 IMEM/DMEM；外部 SDRAM/Flash 容量更大，但需要额外控制器，当前 RV32I 最小上板工程尚未接入。

### FPGA 片内 M9K

`EP4CE10F17C8` 属于 Cyclone IV E 系列，片内 block RAM 为 M9K。M9K 是 FPGA 内部同步 RAM 资源，读数据不是仿真 RAM 那种任意时刻组合返回；RTL 上板时应按同步读 RAM 处理，并在 CPU/SoC 接口或 wrapper 里处理好读时序。

| 项目 | 数值 | 说明 |
| --- | --- | --- |
| M9K 数量 | 46 blocks | 以 EP4CE10 器件资源表为准。 |
| 单块原始容量 | 9,216 bits | 即 9 Kbit。 |
| 单块原始 32-bit word 换算 | 288 words / M9K | `9216 / 32 = 288`，这是纯 bit 容量换算。 |
| 单块常用 32-bit RAM 估算 | 256 words / M9K | 常见 32-bit 端口映射可按 `256 x 32` 估算，剩余 bit 可能因宽度配置未充分利用。 |
| 原始总容量 | 423,936 bits | `46 x 9216` bits，约 51.75 KiB。 |
| 常用 32-bit word 估算 | 11,776 words | `46 x 256` 个 32-bit word，约 46 KiB 可用数据容量估算。 |

当前 RV32I FPGA 工程使用 32-bit word memory：

| 存储 | RTL 深度 | 字节容量 | M9K 估算 |
| --- | --- | --- | --- |
| IMEM | 4,096 x 32-bit word | 16 KiB | 约 16 块 M9K |
| DMEM | 4,096 x 32-bit word | 16 KiB | 约 16 块 M9K |
| IMEM + DMEM | 8,192 x 32-bit word | 32 KiB | 约 32 块 M9K |

因此在 EP4CE10 上将 IMEM/DMEM 各设为 16 KiB 是比较保守的选择，既能容纳当前裸机测试程序，也给其他逻辑和后续小型 RAM 留出一定 M9K 余量。最终资源占用仍应以 Quartus Fitter report 为准。

### 板载外部存储

| 器件 | 资料 | 容量 | 接口 | 当前用途 |
| --- | --- | --- | --- | --- |
| Winbond W9825G6KH SDRAM | [03_SDRAM/W9825G6KH.pdf](03_SDRAM/W9825G6KH.pdf) | 256 Mbit / 32 MiB | SDRAM, 16-bit data bus | 当前最小 RV32I SoC 未接入，后续可用于大容量数据区、framebuffer 或外部内存实验。 |
| Winbond W25Q16JVSSIQ Flash | [04_FLASH/W25Q16JVSSIQ.pdf](04_FLASH/W25Q16JVSSIQ.pdf) | 16 Mbit / 2 MiB | SPI NOR Flash | 当前最小 RV32I SoC 未接入，后续可用于程序镜像、配置数据或简单文件/数据存储。 |

如果后续接入板载 SDRAM 或 SPI Flash，需要新增对应控制器、时序约束、引脚约束和软件驱动；不要把它们和 FPGA 片内 M9K 的固定延迟 RAM 直接等同。

## 基础板级信号

当前 RV32I FPGA 上板工程只使用了 E10 的最小基础资源：

| 信号 | FPGA 引脚 | 方向 | 说明 |
| --- | --- | --- | --- |
| `sys_clk` | `PIN_E1` | input | 板载 50 MHz 时钟。 |
| `sys_rst_n` | `PIN_M1` | input | 低有效复位。 |
| `led[0]` | `PIN_A4` | output | 板载 LED0。 |
| `led[1]` | `PIN_B5` | output | 板载 LED1。 |
| `key[0]` | `PIN_E16` | input | 板载 KEY0。 |
| `key[1]` | `PIN_E15` | input | 板载 KEY1。 |
| `uart_rxd` | `PIN_B13` | input | FPGA UART RXD。 |
| `uart_txd` | `PIN_A13` | output | FPGA UART TXD。 |

以上引脚来自官方 IO 资料，并已在 v5.1 FPGA 工程 QSF 中使用。具体工程端口名应以当前版本 QSF 和 top-level RTL 为准。

## 引脚约束注意事项

- 官方 [E10_MicroSYS_IO.tcl](3_%E6%AD%A3%E7%82%B9%E5%8E%9F%E5%AD%90E10%E6%9C%80%E5%B0%8F%E7%B3%BB%E7%BB%9F%E6%9D%BF%E5%8E%9F%E7%90%86%E5%9B%BE/E10_MicroSYS_IO.tcl) 是引脚分配参考，不应不加检查地整文件导入工程。
- 导入或复制 TCL/QSF 约束时，要确认工程 top-level 端口名与官方示例端口名一致。
- E10 板上许多 FPGA 引脚可能在不同扩展模块示例中复用，实际使用前应同时核对原理图、IO 表和当前外设连接。
- 当前基础上板工程使用 `3.3-V LVTTL` IO standard；扩展外设前应根据器件手册和外设电平重新确认 IO standard。
- 扩展 GPIO 到排针或外设时，应先在 top-level RTL 中增加端口，再在 QSF 中分配对应 pin，并避免与已使用的 LED、KEY、UART、SDRAM、FLASH 等信号冲突。

## 使用建议

为新 RTL 版本做 E10 上板验证时，建议按以下顺序使用本目录资料：

1. 从 `01_FPGA` 确认目标器件型号、资源规模和引脚限制。
2. 从 `3_正点原子E10最小系统板原理图` 查找原理图、IO 分配表和官方 TCL。
3. 在 Quartus QSF 中只添加当前工程真正使用的 pin assignment。
4. 编译后检查 pin report，确认所有顶层 IO 都已分配到预期引脚和 IO standard。
5. 外接 UART、排针或其他模块前，再回到原理图确认信号方向、电平和是否存在板载复用。

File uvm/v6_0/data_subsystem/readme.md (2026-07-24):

# v6.0 Data Subsystem UVM 工作区

本工作区是 0835 为 v6.0 simple data bus 建立的独立 VCS/UVM/SVA 验证环境。DUT 是 `data_subsystem + simple_ram + GPIO0/UART0/TIMER0`，不包含 CPU、IMEM、软件程序或 SoC 级 testbench。它与根目录 Verilator ASM/C self-check regression 并行存在，不替代后者。

## 当前范围

- simple bus active master agent 驱动 single-outstanding request/response 协议。
- wrapper agent 为 DMEM、GPIO0、UART0、TIMER0 配置 response delay；wrapper scoreboard 检查实际 delay。
- simple bus monitor 产生 observed transfer；simple bus scoreboard 当前检查 DMEM 与 GPIO0 可建模行为，UART0/TIMER0 保持明确 skip。
- `simple_bus_sva.svh` 提供基础协议断言；`data_subsystem_coverage` 采样实际 transfer 的读写、target、地址低位、idle gap、delay 和 error。
- `DS_map_random_test` 在固定 seed 下覆盖全部现有 wrapper delay bin，并作为 RTL-001 修复前 FAIL、修复后 PASS 的回归证据。

完整协议、对象所有权、reference model 边界和 out-of-scope 见 `spec.md`；固定 seed 回归、coverage、RTL-001 前后对比和剩余风险见 `verification_report.md`；DUT 快照来源见 `dut/readme.md`。

## 文档入口

| 文档 | 内容 |
|---|---|
| [`spec.md`](spec.md) | DUT 协议、对象所有权、checker/reference model、coverage 和 out-of-scope。 |
| [`verification_report.md`](verification_report.md) | 固定 seed 回归、coverage、RTL-001 修复证据和剩余风险。 |
| [`dut/readme.md`](dut/readme.md) | DUT 快照来源、文件映射、同步和冻结规则。 |
| [`dut/docs/uvm_simulation_flow.md`](dut/docs/uvm_simulation_flow.md) | VCS 编译运行流程、产物和 PASS/FAIL 统计口径。 |

## 常用命令

运行单个 test：

```bash
uvm/v6_0/data_subsystem/sim/run_test.sh <test_name> <seed> [extra_plusargs...]
```

常用示例：

```bash
uvm/v6_0/data_subsystem/sim/run_test.sh simple_bus_smoke_test 1
uvm/v6_0/data_subsystem/sim/run_test.sh data_subsystem_smoke_test 1
uvm/v6_0/data_subsystem/sim/run_test.sh DS_dmem_random_test 1
uvm/v6_0/data_subsystem/sim/run_test.sh DS_map_random_test 1
ASSERT_ON=1 uvm/v6_0/data_subsystem/sim/run_test.sh simple_bus_smoke_test 1
```

运行当前受控回归：

```bash
uvm/v6_0/data_subsystem/sim/run_all.sh
```

`ASSERT_ON=1` 是单条命令的环境变量赋值，只对该次脚本调用生效。传给 `run_test.sh` 的名称必须是已经被 `data_subsystem_pkg.sv` 包含并完成 factory 注册的 test class，不能直接传 sequence class 名。

## 结果与本地产物

`run_test.sh` 的 PASS 条件是 VCS 编译和 runtime 正常完成，且 UVM error/fatal、SVA/SystemVerilog runtime error 均为零。`run_all.sh` 会继续执行完整测试列表，并在末尾汇总每项 test 的进程返回码、UVM severity、simulator error 和最终结果。

本地仿真主要生成：

| 路径 | 内容 |
|---|---|
| `sim/build/` | 按 test、seed 和 SVA 开关隔离的 VCS 编译产物与 `simv`。 |
| `sim/logs/` | compile/runtime log。 |
| `sim/ucli.key` | VCS/UCLI 运行辅助文件。 |

build 和 log 属于可重新生成的本地产物，不作为版本化验证结论。收口时的 test、seed、scoreboard 统计、coverage 和已知问题前后对比统一写入 `verification_report.md`。functional coverage 在 UVM `report_phase` 输出 console summary；当前 VCS/URG 工具环境无法稳定生成 HTML，因此 HTML 不作为 0835 收口条件。

## DUT 快照

`sim/filelist.f` 只编译本目录 `dut/rtl` 下的冻结 RTL，不引用根目录主线。当前镜像来源为 v6.17 修复 RTL-001 后的主线 commit `8930f3a`。0835 收口完成后，该快照不再随主线 AXI-Lite 等后续演进自动同步。

## 已知边界

- 不验证 full CPU/SoC UVM、trap/CSR/interrupt 精确提交或 multi-outstanding 协议。
- 不建立 UART0/TIMER0 完整 reference model，也不覆盖 GPIO/UART/TIMER 的全部 side effect。
- `idle_cycles` 的计划值与 observed gap 可能受 UVM item 交付相位影响；DUT 功能检查以 monitor observed transfer 为准。
- VDB/URG HTML 报告属于工具环境后续事项，当前以固定 seed、checker 统计和 console coverage 作为证据。

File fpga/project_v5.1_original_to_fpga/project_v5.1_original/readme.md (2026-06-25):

# RV32I SoC

本仓库是一个 RV32I SoC 实现仓库，维护对象包括五级流水线核 `core.sv`、MMIO 外设（GPIO/UART/TIMER32）、SoC 集成顶层 `rv32i_soc.sv` 及 SoC 级 testbench。已完成最小 M-mode CSR/trap、MMIO 地址图及外设、machine timer/external interrupt 支持。

## 当前特性（已经过定向验证）

- **40 条 RV32I 指令**：完整 ALU、分支、跳转、访存、LUI/AUIPC、FENCE（当前为 nop）、ECALL、EBREAK 全量支持。
- **五级流水线**：IF/ID/EX/MEM/WB 经典五级流水线结构。
- **数据 hazard**：forwarding（EX/MEM、MEM/WB）+ load-use stall + CSR-use stall。
- **控制 hazard**：branch/JAL/JALR/trap redirect flush + wrong-path kill。
- **CSR 寄存器及访问指令**：6 条 Zicsr 指令（CSRRW/CSRRS/CSRRC/CSRRWI/CSRRSI/CSRRCI），最小 M-mode CSR（mstatus/mtvec/mscratch/mepc/mcause/mtval + 只读 CSR）。
- **同步异常**：instruction address misaligned、illegal instruction、breakpoint、load/store address misaligned、 load/store access fault、ECALL/EBREAK from M-mode。
- **MRET**：trap handler 返回。
- **trap 精确提交**：在 MEM 边界接受，kill 年轻指令，不影响 older instruction。
- **MMIO 地址图及外设**：GPIO0、UART0、TIMER0 已集成于 data_subsystem，寄存器 ABI 见 `rtl/periph/readme.md`，SoC 地址图规划在 `soc_pkg.sv`，平台常量见 `sw/include/platform.h`。
- **MMIO access fault**：未实现外设或预留地址空间访问触发 load/store access fault。
- **machine timer interrupt**：TIMER0.MTIME ≥ MTIMECMP 触发 MTIP，level pending 输出到 mtip_o。
- **machine external interrupt**：GPIO 按 bit 独立配置边沿/电平触发、UART RX 事件，汇总为 MEIP（中断优先级 MEIP > MTIP）。
- **中断精确提交**：CSR 写同拍中断接受、MRET 同拍中断重入、mepc 记录当前提交边界的 interrupt return PC。
- **设计可综合**：CPU 核及子模块采用可综合 rtl 编写；综合对象为 CPU 核顶层 `core.sv`，综合结果不作为项目重点。SoC 顶层透出固定响应 IMEM/DMEM 端口，仿真内存模型由 testbench 实例化；MMIO 外设模型为简化模型，未面向真实 IO 单元、真实串口协议或 PPA 做优化。

---

## 验证能力

- **SoC 级程序自检定向测试**：汇编/C 测试程序通过 PASS/FAIL 状态字结束仿真，覆盖 ISA、流水线 hazard、trap/CSR、MMIO 和 machine interrupt 场景。
- **TB mailbox 外部激励协议**：`sw/include/tb_rv32i_soc_test.h` 与 `tb/sv/tb_rv32i_soc.sv` 约定保留 DMEM store 命令，由测试程序按自身进度请求 testbench 驱动 GPIO 输入、UART RX 事件。该协议只属于当前 testbench，不是 SoC 真实 MMIO ABI。
- **interrupt directed test**：覆盖 timer interrupt、GPIO/UART external interrupt、MEIP/MTIP 优先级、CSR 写同拍中断、MRET 同拍中断重入和周期 GPIO 输入测量。

---

## 系统架构

```
+-----------------------------------------------------------------------------------------------+
| tb_rv32i_soc                                                                                  |
|                                                                                               |
|  +-----------------------+    instr     +------------------------------------------------+    |
|  | simple_rom / IMEM     | -----------> |              rv32i_soc                         |    |
|  | 0x0000_0000  256 KiB  |              |                                                |    |
|  | +imem image           |              |  +--------------------------------+            |    |
|  +-----------------------+              |  | core.sv                        |            |    |
|                                         |  | RV32I 5-stage pipeline         |            |    |
|  +-----------------------+    data      |  | IF / ID / EX / MEM / WB        | <----+     |    |
|  | simple_ram / DMEM     | <----------> |  | fwd + stall + redirect         |      |     |    |
|  | 0x0004_0000  256 KiB  |  TB mailbox  |  | CSR + trap + precise interrupt |      |     |    |
|  | +dmem image           |              |  +----------------+---------------+      |     |    |
|  +-----------------------+              |                   | LSU load/store       |     |    |
|                                         |                   v                      |     |    |
|                                         |  +-----------------------------------+   |     |    |
|                                         |  | data_subsystem: fixed decoder     |   |     |    |
|                                         |  |                                   |   |     |    |
|                                         |  | 0x0004_0000 DMEM    external port |   |     |    |
|                                         |  | 0x0008_0000 GPIO0      IN IRQ --+ |   |     |    |
|                                         |  | 0x0008_2000 UART0      RX IRQ --+-> MEIP    |    |
|                                         |  | 0x0008_1000 TIMER0  MTIME IRQ ----> MTIP    |    |
|                                         |  +-----------------------------------+         |    |
|                                         |                                                |    |
|                                         | observable: commit / trap / data bus           |    |
|                                         |             GPIO / UART / IRQ                  |    |
|                                         +------------------------------------------------+    |
|                                                                                               |
|    memory images | PASS/FAIL monitor | commit/trap trace                                      |
|    TB mailbox store commands -> GPIO input stimulus / UART RX event                           |
|                                                                                               |
+-----------------------------------------------------------------------------------------------+
```

---

## 目录结构

| 目录 | 说明 |
|---|---|
| `rtl/` | RTL 源码（core_pkg、pipeline_pkg、core 各阶段模块、memory 封装） |
| `tb/` | testbench（当前维护 SoC 级 testbench） |
| `sim/` | 编译和仿真脚本（按汇编/C 分目录） |
| `sw/` | 汇编和 C 裸机测试程序 |
| `scripts/` | 辅助脚本（bin2mem32 等） |
| `build/` | 编译产物（.elf、.dump、.bin、.mem） |
| `docs/` | 说明文档 |

---

## 项目时间戳

| 核（相对于上版本的改动） | 顶层 | 状态 | release 版本 | 备注 |
|---|---|---|---|---|
| 单周期 RV32I | `core_single_cycle.sv` | 历史版本已完成，当前不再维护 | v1.0 | 最终兼容版本为 v2.0，自 v2.10 起删除该文件 |
| 五级流水线 RV32I（data hazard + control hazard） | `core_pipeline5.sv` | 已完成 | v2.0 | 后续开发持续在该文件上累积 |
| 同步异常扩展、CSR 与最小特权级（CSR/exception trap） | `core_pipeline5.sv` | 已完成 | v3.0 | 自 v3.4 起，将 `core_pipeline5.sv` 改名为 `core.sv` |
| 增加 MMIO 最简外设与 SoC 平台集成 | CPU 核 `core.sv` + SoC 平台 `rv32i_soc` | 已完成 | v4.0 | 自 v4.10 起，删除旧的 CPU 核测试平台 `tb_core_pipeline5.sv` |
| machine interrupt、TIMER32 与外部中断 | CPU 核 `core.sv` + SoC 平台 `rv32i_soc` | 已完成 | v5.0 | - |

---

## 环境依赖

- **RV32I 工具链**：`riscv64-unknown-elf-gcc` 等，将测试程序编译为 .elf 并提取二进制 .bin。
- **Verilator**：SystemVerilog 仿真器
- **Python 3**：运行 `bin2mem32.py`，编译出的裸二进制 .bin 转成每行一个 32-bit hex word 的 .mem 文件。

---

## 五级流水线核

### 涉及文件

**RTL：**
```
rtl/common/          # 核与 SoC 公共常量/枚举/类型（core_pkg、pipeline_pkg、soc_pkg）
rtl/core/            # 五级流水线核（IF/ID/EX/MEM/WB、forwarding、hazard、CSR、trap）
rtl/mem/             # memory 封装（simple_rom 指令 ROM、simple_ram 数据 RAM）
rtl/periph/          # MMIO 外设（mmio_gpio、mmio_uart、mmio_timer32）
rtl/soc/             # SoC 集成（data_subsystem 总线译码、rv32i_soc 顶层）
```

**Testbench：** 

- `tb/sv/tb_rv32i_soc.sv`：集成 MMIO 最小外设的 SoC 测试平台。

**汇编测试程序：**
```
# 基础 ISA 测试
sw/asm/0001_smoke.S                           # 最小冒烟
sw/asm/0101_branch.S                          # 分支指令
sw/asm/0102_alu_imm.S                         # ALU 立即数
sw/asm/0103_alu_reg.S                         # ALU 寄存器
sw/asm/0104_load_store.S                      # 访存指令
sw/asm/0105_jump.S                            # JAL/JALR
sw/asm/0106_u_type.S                          # LUI/AUIPC

# 流水线 data/control hazard 测试
sw/asm/0301_pipeline5_nofwd_noredirect.S      # 不依赖 forwarding/redirect 的基线冒烟
sw/asm/0302_pipeline5_fwd_noredirect.S        # data hazard 全覆盖
sw/asm/0303_pipeline5_fwd_redirect.S          # forwarding + control hazard 混合

# trap 测试
sw/asm/0501_trap_entry_smoke.S                # ECALL trap entry smoke
sw/asm/0502_exception_full.S                  # 全同步异常总测试（9 个 step）
sw/asm/0503_csr_instr_test.S                  # 6 个 CSR 指令读写 CSR 寄存器测试

# SoC/MMIO 测试
sw/asm/0601_soc_smoke.S                       # SoC 级别冒烟
sw/asm/0602_uart_tx.S                         # UART TX 发送字符
sw/asm/0603_gpio_rw.S                         # GPIO OUT/OE/IN 读写
sw/asm/0604_mmio_access_fault.S               # MMIO 未实现外设 access fault
sw/asm/0605_mmio_misaligned_priority.S        # misaligned MMIO 访问优先级
sw/asm/0606_wrong_path_mmio.S                 # wrong-path MMIO 不提交

# interrupt 测试
sw/asm/0705_interrupt_commit_precise.S        # CSR 写同拍中断精确提交
sw/asm/0706_mret_interrupt_reentry.S          # MRET 同拍中断重入
```

**C 测试程序：**
```
sw/c/0201_c_smoke.c                           # 最小冒烟
sw/c/0202_dmem_init.c                         # .data/.bss/.rodata 初始化
sw/c/0401_control_mix.c                       # 综合控制流 + 内存操作
sw/c/0551_trap_smoke.c                        # C 侧 trap handler smoke
sw/c/0651_soc_mmio_smoke.c                    # SoC MMIO 冒烟（GPIO/UART/access fault）
sw/c/0652_soc_mmio_gpio_uart.c                # SoC MMIO 综合测试（GPIO bit 操作/UART 多字符串）
sw/c/0751_timer_smoke.c                       # TIMER0 定时器中断 smoke（C trap handler + level pending 清除）
sw/c/0752_gpio_irq_basic.c                    # GPIO 外部中断基础行为（4 类触发、IRQ_EN/STATUS/PENDING、W1C）
sw/c/0753_uart_rx_irq.c                       # UART RX 中断（TB 注入、rx_irq_enable 门控、读清与 W1C 差异）
sw/c/0754_external_timer_priority.c           # MEIP/MTIP 优先级（同时 pending 优先进 MEIP，清后进 MTIP）
sw/c/0757_gpio_periodic_irq.c                 # TB 固定周期 GPIO 中断精确测量（TIMER0.MTIME + UART 报告）
```

**仿真脚本：** `sim/soc_asm/`、`sim/soc_c/`

当前共 **32 个 directed tests**（汇编 21 + C 11），覆盖 RV32I 指令集、五级流水线 hazard（6 种 RAW forward + load-use stall + redirect）、7 种同步异常、MMIO 外设访问与 access fault、machine timer/external interrupt（GPIO 4 类触发、UART RX、MEIP/MTIP 优先级、CSR 同拍中断、MRET 同拍重入）。

### 仿真命令

```bash
# —— SoC 汇编回归仿真 ——
sim/soc_asm/run_all.sh

# —— SoC C 回归仿真 ——
sim/soc_c/run_all.sh

# —— SoC 单个程序仿真 ——
sim/soc_asm/run_test.sh <n>               # n 表示 sw/asm 下 汇编程序前的四位编码
sim/soc_c/run_test.sh <m>                 # m 表示 sw/c 下 c 程序前的四位编码
```

汇编仿真详细流程见 [docs/simulation_flow_asm.md](docs/simulation_flow_asm.md)。C 仿真流程见 [docs/simulation_flow_c.md](docs/simulation_flow_c.md)。

---

## 编写新测试

在 `sw/asm/` 下创建 `.S` 文件，然后：

```bash
sim/soc_asm/run_test.sh <四位编号或完整basename>
```

在 `sw/c/` 下创建 `.c` 文件后运行：

```bash
sim/soc_c/run_test.sh <四位编号或完整basename>
```

汇编测试集分类见 [sw/asm/readme.md](sw/asm/readme.md)。

c 程序编写方法见 [sw/c/readme.md](sw/c/readme.md)。

MMIO 外设操作手册见 [rtl/periph/readme.md](rtl/periph/readme.md)。

MMIO 地址图镜像查阅见 [sw/linker/readme.md](sw/linker/readme.md)。

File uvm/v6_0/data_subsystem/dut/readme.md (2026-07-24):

# v6.0 Simple Bus DUT RTL 快照

本目录保存 `v6_0/data_subsystem` UVM 环境使用的最小 DUT RTL 编译闭包。保存快照的目的是让本环境在主线后续切换到 AXI-Lite、修改 package 或删除 `data_subsystem` 后，仍能从当前仓库独立编译和复现。

## 来源基线

| 项目 | 值 |
|---|---|
| 源仓库 commit | `8930f3a` |
| 源仓库 release | v6.17，0835 最终收口 tag 待创建 |
| 快照建立日期 | `2026-07-24` |
| 验证对象 | `data_subsystem + simple_ram + GPIO0/UART0/TIMER0` |
| data bus 版本 | v6.0 single-outstanding simple request/response bus |

快照建立时，下列 RTL/ABI 文件与根目录对应文件逐字节一致。`sim/filelist.f` 只引用本目录的镜像文件。

## 文件映射

| 快照文件 | 来源文件 | 用途 |
|---|---|---|
| `rtl/common/core_pkg.sv` | `rtl/common/core_pkg.sv` | XLEN、DMEM 地址和基础公共类型。 |
| `rtl/common/soc_pkg.sv` | `rtl/common/soc_pkg.sv` | MMIO 地址图、寄存器 offset 和 target 类型。 |
| `rtl/common/data_bus_pkg.sv` | `rtl/common/data_bus_pkg.sv` | `data_req_t`、`data_resp_t`。 |
| `rtl/mem/simple_ram.sv` | `rtl/mem/simple_ram.sv` | 外置固定响应 DMEM model。 |
| `rtl/periph/mmio_gpio.sv` | `rtl/periph/mmio_gpio.sv` | GPIO0 register block。 |
| `rtl/periph/mmio_uart.sv` | `rtl/periph/mmio_uart.sv` | UART0 register block。 |
| `rtl/periph/mmio_timer32.sv` | `rtl/periph/mmio_timer32.sv` | TIMER0 register block。 |
| `rtl/soc/data_subsystem.sv` | `rtl/soc/data_subsystem.sv` | simple bus decoder、target wrapper 和 response mux。 |
| `docs/periph_register_abi.md` | `rtl/periph/readme.md` | 与快照匹配的外设寄存器 ABI。 |

本快照不包含 CPU core、`rv32i_soc`、IMEM、软件程序或 SoC directed testbench，因为它们不属于本 UVM harness 的 DUT 编译闭包。

## 开发期同步规则

0835 环境尚未冻结时，如果 UVM 发现真实 RTL bug：

1. 先在根目录主线 RTL 修复问题。
2. 运行相关 Verilator directed test，确认 CPU/SoC 端到端行为不退化。
3. 将同一修复同步到本快照。
4. 在下方“快照差异”记录原因、文件和对应 commit。

不得只修改本快照来隐藏 DUT bug，也不得为了方便 UVM 驱动而改变协议。验证适配应放在 `../tb/` 的 interface、harness 或 bind/assertion 中。

## 冻结规则

0835 完成后，本目录作为 v6.0 simple bus DUT 归档冻结。主线进入 AXI-Lite 或其它协议后，不再把无关变化同步到这里。未来环境应建立新的版本目录和独立 filelist，不能同时编译多个版本的同名 package/module。

## 快照差异

相对 v6.0 `v6.0-data-side-variable-delay` 基线，本快照包含后续 VCS 兼容性整理和 RTL-001 修复。RTL-001 将 GPIO0、UART0、TIMER0 的寄存器 decode 从原始 byte offset 改为 word-aligned offset `{full_offset[11:2], 2'b00}`；原始 byte address 继续透传，`be` 继续决定有效 byte lane。修复前后 UVM 证据记录在根目录 `docs/known_issues.md`。

本快照中的 RTL 不包含 UVM 专用改动；任何未来主线变更若需要同步，必须重新完成主线回归、更新本说明并重新运行本工作区回归。

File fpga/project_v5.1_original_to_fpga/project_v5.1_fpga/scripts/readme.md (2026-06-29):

# FPGA 镜像构建脚本

本目录包含将 RV32I 裸机 C 程序构建为 FPGA 存储器初始化文件的辅助脚本。

## 脚本总览

| 脚本 | 作用 |
| --- | --- |
| `build_rv32i_c_image.sh` | 编译单个 C 程序，生成 ELF/dump/map 文件，以及 IMEM `.mem` 和 DMEM `.mif` 镜像，输出到 `build/fpga_c/` |
| `bin2mem32.py` | 将二进制文件转换为每行一个 32-bit little-endian 十六进制字的格式，供 `$readmemh` 使用 |
| `mem32_to_mif.py` | 将每行一个 32-bit 字的 `.mem` 文件转换为 Quartus `.mif` 格式 |
| `update_fpga_mem.sh` | 串联执行前三个脚本：C 镜像构建，并将结果替换到 `fpga/mem/current_imem.mem` 和 `fpga/mem/current_dmem.mif` |

## 常用流程

在 `project_v5.1_fpga/` 目录下执行：

```bash
scripts/update_fpga_mem.sh 0500
```

参数可以是以下任意形式：

```text
0500
0504_fpga_timer_irq
sw/c/0505_fpga_key_led_uart.c
```

脚本会更新当前活跃的 FPGA 存储器镜像：

```text
fpga/mem/current_imem.mem
fpga/mem/current_dmem.mif
```

之后重新运行 Quartus 编译，将新的存储器文件打包进 SOF。

## 构建输出

默认情况下，中间构建产物位于：

```text
build/fpga_c/
```

典型输出包括：

| 输出文件 | 说明 |
| --- | --- |
| `<test>.elf` | 链接后的 RV32I 裸机可执行文件 |
| `<test>.dump` | 反汇编文件，用于人工审查 |
| `<test>.map` | 链接映射表，用于检查各 section 大小和地址 |
| `<test>_imem.mem` | 安装前的 IMEM 镜像 |
| `<test>_dmem.mif` | 安装前的 DMEM MIF 镜像 |
| `last_build.txt` | 上一次 C 镜像构建的摘要信息 |

## 工具链变量

| 变量 | 用途 |
| --- | --- |
| `RISCV_PREFIX` | 工具链前缀，默认为 `riscv64-unknown-elf` |
| `RISCV_CC` | 覆盖编译器命令 |
| `RISCV_OBJCOPY` | 覆盖 objcopy |
| `RISCV_OBJDUMP` | 覆盖 objdump |
| `TOOLCHAIN_ENV` | 构建前 source 的可选 shell 脚本 |
| `BUILD_DIR` | 覆盖输出目录 |
| `EXTRA_CFLAGS` | 添加额外的 C 编译器 flags |

## 冒烟测试镜像行为

`0500_fpga_led_spark.c` 是最简单的板级冒烟测试程序。更新存储器文件、重新编译 Quartus 并下载新 SOF 后，LED0 和 LED1 会交替闪烁形成流水灯：

```text
LED0 亮, LED1 灭
LED0 灭, LED1 亮
重复
```

该程序不产生 UART 输出，也不依赖中断，因此是检查板级配置通路时的首选测试程序。

## 容量检查

`build_rv32i_c_image.sh` 会拒绝超过当前 v5.1 限制的镜像：

```text
IMEM <= 16 KiB
DMEM <= 16 KiB
```

若后续 RTL 存储器尺寸发生变化，需要同步更新 linker script、`platform.h`、memory wrapper、MIF 深度以及脚本侧的这些限制。

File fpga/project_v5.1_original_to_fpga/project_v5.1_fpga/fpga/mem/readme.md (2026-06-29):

# FPGA 存储器镜像文件

此目录存放 Quartus FPGA 构建流程所需的存储器初始化文件。

## 文件列表

| 文件 | 使用者 | 说明 |
| --- | --- | --- |
| `current_imem.mem` | `rtl/fpga/fpga_imem.sv` | 当前活跃的 IMEM 镜像，会被打包进下一次 SOF 构建 |
| `current_dmem.mif` | `rtl/fpga/fpga_dmem.sv` | 当前活跃的 DMEM 镜像，会被打包进下一次 SOF 构建 |
| `default_imem.mem` | 手动回退备用 | 精简的默认/冒烟测试 IMEM 镜像 |
| `default_dmem.mif` | 手动回退备用 | 精简的默认/冒烟测试 DMEM 镜像 |

`current_*` 文件是 Quartus 的实时输入。修改这些文件后，需要重新运行 Quartus 编译，新内容才会被嵌入到 `output_files/e10_rv32i.sof` 中。

## 默认板级行为

默认/冒烟测试镜像用作简单的板级 sanity check。在 E10 开发板上，它会驱动 GPIO LED0 和 LED1 交替闪烁，形成流水灯效果：

```text
LED0 亮, LED1 灭
LED0 灭, LED1 亮
重复
```

该最小镜像不产生 UART 输出，也不依赖中断。适用于快速验证 FPGA 配置、复位、时钟、IMEM 以及 GPIO 输出通路是否基本正常。

## 更新活跃镜像

在 `project_v5.1_fpga/` 目录下执行：

```bash
scripts/update_fpga_mem.sh 0500
```

或将 `0500` 替换为 `sw/c/` 下其他 C 程序代码的名称。

脚本会更新以下文件：

```text
fpga/mem/current_imem.mem
fpga/mem/current_dmem.mif
```

更新完成后，重新运行 Quartus 编译并下载新生成的 SOF 文件。

## 注意事项

- `fpga_imem.sv` 通过 `$readmemh` 加载 `../mem/current_imem.mem`
- `fpga_dmem.sv` 例化 `altsyncram` 并加载 `../mem/current_dmem.mif`
- `current_dmem.mem` **不**用于 FPGA DMEM wrapper（此为有意设计）
- 当前 v5.1 镜像假定 IMEM 和 DMEM 均为 16 KiB

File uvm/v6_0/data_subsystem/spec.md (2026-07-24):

# v6.0 Data Subsystem UVM Verification Spec

本文定义 `uvm/v6_0/data_subsystem` 独立 UVM 工作区的验证对象、协议语义、验证架构、数据对象所有权、检查边界、coverage 口径和非目标。

本 spec 绑定项目 v6.0 的 simple data bus 与 `data_subsystem` response-delay wrapper。后续若 data bus 被 AXI-Lite 或其它协议替换，本 spec 和对应工作区作为历史 release 资产保留；新协议必须建立新的版本目录、verification spec 和 filelist，不能静默复用本文。

## 1. 定位

本 UVM 环境验证 0834 后形成的 data-side simple request/response bus、`data_subsystem` 地址译码、DMEM/GPIO0 的当前软件可见行为，以及 per-target response-delay wrapper。

当前环境具备：

- UVM active master 驱动 simple data bus。
- 独立 wrapper agent 驱动并观测 DMEM、GPIO0、UART0、TIMER0 的 response-delay 配置。
- virtual sequence 协调 bus sequence 与 wrapper sequence。
- simple bus monitor 从 interface 独立重建 observed transfer。
- simple bus scoreboard 检查 DMEM 和 GPIO0 当前已建模行为。
- wrapper scoreboard 独立检查 request accepted 时的实际 wrapper 配置与 observed response delay。
- SVA 检查 simple bus 引脚级协议 invariant。
- functional coverage 只采样 monitor 实际观察到的完整 transaction。

本环境不实例化整颗 `rv32i_soc`，不运行 `.mem` 程序，不验证 CPU 指令流、GPR、CSR、trap handler 或 interrupt 精确提交。现有 Verilator ASM/C self-check regression 必须继续保留；VCS/UVM/SVA 是并行验证平台，不替代 directed regression。

## 2. 文件与版本边界

| 内容 | 路径 |
|---|---|
| UVM testbench | `uvm/v6_0/data_subsystem/tb` |
| DUT RTL/ABI 快照 | `uvm/v6_0/data_subsystem/dut` |
| VCS 脚本与日志 | `uvm/v6_0/data_subsystem/sim` |
| 仿真流程说明 | `uvm/v6_0/data_subsystem/dut/docs/uvm_simulation_flow.md` |
| 实际验证结果 | `uvm/v6_0/data_subsystem/verification_report.md` |

目录名体现 release 绑定；package/class 名按 data-subsystem、simple-bus 和 wrapper 的职责命名。归档后的 v6.0 filelist 只编译本工作区 DUT 快照，不引用根目录主线 RTL。不同 release 环境不进入同一个 VCS filelist，避免 package/class/module 重名和行为漂移。

开发期若 UVM 暴露真实 RTL 问题，必须先修复主工程 RTL 并运行主线回归，再同步 DUT 快照。快照来源、文件映射和冻结规则见 `dut/readme.md`。

## 3. DUT Harness 与验证架构

### 3.1 静态 harness

~~~text
simple_bus_if
    |
    v
data_subsystem
    +--> external simple_ram as DMEM model
    +--> mmio_gpio    GPIO0
    +--> mmio_uart    UART0
    +--> mmio_timer32 TIMER0

wrapper_if
    +--> dmem/gpio0/uart0/timer0 response-delay inputs
~~~

`simple_bus_if` 表达 core-side request/response 协议。`wrapper_if` 是 v6.0 DUT wrapper 专用的 testbench 配置与观测通道，不属于 simple bus，也不进入通用 bus transaction payload。

GPIO input 和 UART RX 等 DUT 外部输入在当前 harness 中保持固定 idle 值；GPIO output、UART TX event 和 IRQ 等 sideband 未建立独立 UVM agent。涉及这些信号的外设 side effect 不属于当前自动检查范围。

### 3.2 UVM 组件关系

~~~text
test
  -> physical sequence or virtual sequence
       -> data_subsystem_virtual_sequencer
            +--> simple_bus_agent.sequencer
            |      -> simple_bus_driver
            |      -> simple_bus_if
            |
            +--> wrapper_agent.sequencer
                   -> wrapper_driver
                   -> wrapper_if

simple_bus_monitor.transfer_ap
    +--> simple_bus_scoreboard.tr_imp
    +--> wrapper_scoreboard.bus_tr_fifo
    +--> data_subsystem_coverage.analysis_export

wrapper_monitor.transfer_ap
    +--> wrapper_scoreboard.wrp_tr_fifo
~~~

`data_subsystem_env` 创建两个 active agent、virtual sequencer、两个 scoreboard 和 coverage collector。普通 simple-bus smoke 可以直接启动 bus physical sequence；需要逐笔配置 wrapper 的场景通过 virtual sequence 协调两个 physical sequencer。test、sequence、scoreboard 和 coverage 不直接驱动 virtual interface。

bus driver 的 `planned_item_ap` 与 wrapper driver 的 `applied_item_ap` 已提供扩展观察口，但当前 env 没有把它们接入 checker；当前 PASS/FAIL 依据以 monitor、scoreboard 和 SVA 为准。

### 3.3 DUT 主接口

| 信号 | 方向 | 说明 |
|---|---|---|
| `core_req_i.valid` | master -> DUT | request payload 有效。 |
| `core_req_i.write` | master -> DUT | 1=write/store，0=read/load。 |
| `core_req_i.be` | master -> DUT | byte enable，bit0 对应最低 byte lane。 |
| `core_req_i.addr` | master -> DUT | byte address。 |
| `core_req_i.wdata` | master -> DUT | 按 byte lane 对齐的 write data。 |
| `core_req_ready_o` | DUT -> master | DUT 可以接受新 request。 |
| `core_resp_o.valid` | DUT -> master | response payload 有效。 |
| `core_resp_o.rdata` | DUT -> master | read response data；write/error 时不作为软件有效数据。 |
| `core_resp_o.error` | DUT -> master | 1 表示本次访问失败。 |

`core_req_i` 和 `core_resp_o` 类型来自 `data_bus_pkg.sv`：

- `data_bus_pkg::data_req_t`
- `data_bus_pkg::data_resp_t`

`ready` 保持为离散信号。response 侧没有 `resp_ready`；master 不能对 response 施加 backpressure，必须在 `core_resp_o.valid=1` 的采样点接收结果。

## 4. Simple Data Bus 协议

### 4.1 Request 接受

request 在以下时钟采样点被接受：

~~~text
req_accept = core_req_i.valid && core_req_ready_o
~~~

request 被接受前，driver 必须保持以下 payload 稳定：

- `write`
- `be`
- `addr`
- `wdata`

当 `valid=1 && ready=0` 时，driver 不得改变 payload 或提前撤销 valid。

### 4.2 Request idle gap

对于非首笔 transaction，planned `idle_cycles` 定义为：上一笔 response 完成后，到本笔 `core_req_i.valid` 首次为 1 前，额外保持 valid=0 的完整采样拍数。

第一笔 transaction 没有上一笔 response，其 planned `idle_cycles` 表示 reset 释放锚点后的 initial idle。initial idle 受 test 启动和 clocking block 对齐影响，不作为当前功能 scoreboard 的检查项。

`idle_cycles=0` 表示在协议允许的最早采样拍发起下一笔 request；`idle_cycles=N` 表示额外保持 N 个完整 idle 拍。sequence 产生计划值，driver 只执行；sequence 不使用额外 `@(clock)` 隐式制造 gap。

monitor 独立统计 observed idle gap，并写入 `simple_bus_transfer.observed_item.idle_cycles`。功能 scoreboard 与 coverage 以该 observed 值为准；planned/observed idle 的严格执行检查属于第 16 章的可扩展项。

### 4.3 Response 完成与 delay

transaction 在 `core_resp_o.valid=1` 的时钟采样点完成。

- `resp_delay=0`：request accepted 与 response valid 同拍。
- `resp_delay=N`：response 在 accepted request 后第 N 个采样间隔返回。

monitor 把实际延迟写入 `simple_bus_transfer.resp_delay`。在非 0 wait-state outstanding 期间，`core_req_ready_o` 必须保持为 0，避免接受第二笔 request。

### 4.4 Single Outstanding

v6.0 simple bus 只支持 single outstanding、in-order completion：

- 同一时刻最多一笔 accepted 但未 response 的 transaction。
- 没有 transaction ID。
- response 对应最近一笔未完成 request。
- 不允许 orphan response。
- outstanding 未完成时不接受第二笔 request。

monitor 只需一个 pending transfer。driver、monitor 和 SVA 都应具有防御性检查，但协议 invariant 的主要静态检查路径是 SVA。

testbench 必须有全局 timeout，bus driver 必须有单 transaction response timeout。timeout 上限大于最大 wrapper delay 127，并保留调度裕量；超时时打印 op、addr、target 和等待拍数。

### 4.5 Reset

reset 有效期间：

- bus driver 驱动 request idle，即 `core_req_i.valid=0`。
- DUT 不产生有效 response。
- wrapper driver 将四路 delay 配置初始化为 0。
- driver 不从 sequencer 取得并执行普通 item，monitor 不发布 transfer；sequence 即使已在 run phase 启动，也只会阻塞等待 driver。

当前环境只要求仿真开始时 reset；运行中 reset 不属于 reference model 的强制场景。若后续加入 mid-test reset，所有 agent、monitor pending state、checker expected state 和 reference model 必须统一定义 reset 行为。

### 4.6 Error

`core_resp_o.error=1` 表示 transaction 失败。UVM 不模拟 CPU trap，只检查 bus-visible error 和软件可见结果。

error response 的 `rdata` 不作为有效数据比较。DMEM window 内访问不应 error；MMIO known/unknown offset 和 unmapped address 按第 5、9 章处理。

## 5. 地址与 Target

地址常量来源：

| 常量 | package | 说明 |
|---|---|---|
| `DMEM_BASE` / `DMEM_SIZE_BYTES` | `core_pkg` | DMEM window。 |
| `GPIO0_BASE` / `GPIO0_SIZE_BYTES` | `soc_pkg` | GPIO0 window。 |
| `UART0_BASE` / `UART0_SIZE_BYTES` | `soc_pkg` | UART0 window。 |
| `TIMER0_BASE` / `TIMER0_SIZE_BYTES` | `soc_pkg` | TIMER0 window。 |

Target 译码：

| Target | 地址范围 | 期望 |
|---|---|---|
| DMEM | `[DMEM_BASE, DMEM_BASE + DMEM_SIZE_BYTES)` | 外置 `simple_ram`，合法访问不产生 error。 |
| GPIO0 | GPIO0 window | 命中 `mmio_gpio`；unknown word offset 返回 error。 |
| UART0 | UART0 window | 命中 `mmio_uart`；unknown word offset 返回 error。 |
| TIMER0 | TIMER0 window | 命中 `mmio_timer32`；unknown word offset 返回 error。 |
| undefined | 其它地址 | 不经过 target wrapper，同拍返回 error，`rdata=0`。 |

总线传递原始 byte address。CPU 已根据 `addr[1:0]` 和访问类型生成 `be`、按 byte lane 对齐 store `wdata`，并在 load response 返回后自行选取和扩展 byte/half 数据。DMEM 和 MMIO target 使用 `{addr[31:2], 2'b00}` 选择 word/register，`addr[1:0]` 不参与 target 内部 word/register decode；实际有效 byte lane 只由 `be` 决定，read 返回完整的对齐 word/register 数据。

MMIO offset、bit、访问属性和 side effect 以 `dut/docs/periph_register_abi.md` 为唯一 ABI 来源。本 spec 规定验证边界，不复制维护完整寄存器手册。RTL-001 曾违反上述 word-aligned decode 规则，现已修复并由 `DS_map_random_test` 固定 seed 回归覆盖。

## 6. 数据对象、所有权与关联

### 6.1 `simple_bus_item`：planned command

`simple_bus_item` 用于 sequence -> sequencer -> driver，表达 master 计划：

| 字段 | 来源 | 说明 |
|---|---|---|
| `write` | sequence | 计划 read/write。 |
| `addr` | sequence | 计划 byte address。 |
| `be` | sequence | 计划 byte enable。 |
| `wdata` | sequence | 计划 write data。 |
| `idle_cycles` | sequence | 计划 request 前 idle gap；首笔为 initial idle。 |

item 不保存 DUT response，不作为功能 scoreboard 或 coverage 的输入。driver 等到 response 后调用 `item_done()`，并可把开始执行前的 clone 发布到 `planned_item_ap`；当前 checker 不消费该 port。

### 6.2 `simple_bus_transfer`：observed transaction

`simple_bus_transfer` 只由 monitor 创建，表达 interface 上实际完成的 transaction：

| 字段 | 来源 | 说明 |
|---|---|---|
| `observed_item.write/addr/be/wdata` | monitor | 实际 accepted request payload。 |
| `observed_item.idle_cycles` | monitor | interface 上实际 request idle gap。 |
| `rdata/error` | monitor | 实际 response payload。 |
| `resp_delay` | monitor | accepted request 到 response valid 的实际延迟。 |
| `req_cycle/accept_cycle/resp_cycle` | monitor | monitor 的采样周期编号，用于时序关联与 debug。 |
| target | `observed_item` helper | 根据实际 addr 推导。 |

monitor 不读取 sequence item、wrapper item 或 driver 内部状态。它在 request valid 首次出现时记录 `req_cycle`，在 request accepted 时锁存 payload 和 `accept_cycle`，在 response 时填写 response、`resp_delay` 与 `resp_cycle`，随后通过 `transfer_ap` 广播。0 wait-state 同拍 accept/response 必须输出一笔完整 transfer。

### 6.3 `wrapper_item`：planned/applied configuration command

| 字段 | 说明 |
|---|---|
| `target` | DMEM/GPIO0/UART0/TIMER0。 |
| `delay_cycles` | 请求的 delay 值；driver 对负数报 fatal，对大于 127 的值饱和到 127 并 warning。 |

该 item 只在 wrapper agent 内流动，不进入 simple bus agent。wrapper driver 实际调用 `wrapper_if.set_target_resp_delay()` 后，将实际应用值的 clone 发布到 `applied_item_ap`；当前 wrapper scoreboard 不消费该 port。

### 6.4 `wrapper_transfer`：observed configuration snapshot

`wrapper_transfer` 由 wrapper monitor 每个 reset 释放后的采样周期发布，保存四路实际 delay 配置和 `sample_cycle`。它是 interface observation，不是单 target 配置命令。

wrapper scoreboard 按 bus transfer 的 `accept_cycle` 选择同一 `sample_cycle` 的完整配置快照。这样同拍配置与访问的关联不依赖两个 analysis port 的回调顺序，也不信任 sequence 或 driver 自己推导 DUT 实际配置。

### 6.5 数据来源不得混用

| 数据流 | 表示 | 当前消费者 |
|---|---|---|
| planned bus item | sequence 要求 bus driver 执行什么 | bus driver；`planned_item_ap` 保留扩展口 |
| planned/applied wrapper item | wrapper driver 要求并实际应用什么 | wrapper driver；`applied_item_ap` 保留扩展口 |
| observed bus transfer | simple bus interface 实际发生什么 | simple bus scoreboard、wrapper scoreboard、coverage |
| observed wrapper transfer | wrapper interface 实际配置状态 | wrapper scoreboard |

功能 scoreboard 不读取 planned item；wrapper scoreboard 不读取 virtual sequence 内部值；coverage 不采样 sequence 计划值。当前协议 single outstanding、in-order，因此 bus monitor 和 checker 不需要 transaction ID。未来若支持多 outstanding，必须增加 transaction ID 或重新定义关联机制。

### 6.6 约束与激励分层

`simple_bus_item` 的通用约束要求 `be != 0`、`idle_cycles` 位于 0～15，并对 data-side 地址图、write data 和 idle gap 提供基础加权。通用 map random 不强制 `addr/be` 形成 CPU access profile，它有意覆盖 generic non-zero BE 与非零地址低位组合。

CPU-shaped profile 可在专属 sequence 中进一步约束：

| profile | `addr/be` 关系 |
|---|---|
| byte | `be = 4'b0001 << addr[1:0]`。 |
| halfword | `addr[0]=0`；按 `addr[1]` 选择 `0011/1100`。 |
| word | `addr[1:0]=0` 且 `be=1111`。 |
| generic bus corner | addr 与任意非零 be 独立，不代表 CPU 一定产生该形状。 |

当前默认地址总权重为 DMEM 50%、GPIO0 20%、UART0 10%、TIMER0 10%、全地址空间 10%。`simple_bus_dmem_random_access_seq` 在 DMEM 内维护已写 word 地址池；`simple_bus_map_random_access_seq` 在完整 32-bit word 地址图维护已写地址池，并使大部分 read 复用已写 word，从而提高已有 reference model 的有效比较比例。sequence 不读取 scoreboard 实现范围。

## 7. Response-delay Wrapper 配置与检查

### 7.1 DUT wrapper 语义

`data_subsystem` 为固定响应 target 注入 per-target delay：

| 输入 | 说明 |
|---|---|
| `dmem_resp_delay_cycles_i` | DMEM delay。 |
| `gpio0_resp_delay_cycles_i` | GPIO0 delay。 |
| `uart0_resp_delay_cycles_i` | UART0 delay。 |
| `timer0_resp_delay_cycles_i` | TIMER0 delay。 |

- delay 0：同拍 response。
- delay N：request accepted 后延迟 N 拍 response。
- undefined target 不经过 wrapper，固定同拍 error response。
- wrapper 在 request accepted 时访问 target、锁存 data/error，再延迟 core-side response。
- wrapper 是验证配套层，不表示外设本体是多拍 slave。

### 7.2 wrapper agent

~~~text
wrapper_agent
    +--> wrapper_sequencer
    +--> wrapper_driver
    +--> wrapper_monitor
~~~

wrapper driver 通过 `wrapper_if.drv_mp` 独占四路配置驱动，并在 reset 期间调用 interface task 清零配置。wrapper monitor 通过 `wrapper_if.mon_mp` 每拍独立采样四路实际配置并发布 `wrapper_transfer`。top 分别以完全匹配的 virtual-interface 类型向 driver 和 monitor 配置 vif。

cfg channel 是 TB 专用控制侧带，不是待验证的 handshake protocol。wrapper sequence/driver 不在 outstanding transaction 期间改变配置；配置 task 不消耗仿真时间，下一笔 request 可以按协议允许的最早采样拍发起。

### 7.3 virtual sequence 协调规则

需要 wrapper 配置的场景遵循：

~~~text
apply wrapper item
  -> wrapper driver applies value and item_done
  -> send bus item or bus sequence
  -> bus driver waits request/response completion and item_done
  -> apply next wrapper item
~~~

配置在下一笔 request accepted 前稳定，outstanding 期间不得修改。simple-bus smoke 不发送 wrapper item，使用 reset 默认 delay 0。固定、边界和随机 delay 均通过 wrapper agent 配置，不通过 test 直接访问 virtual interface。

### 7.4 wrapper scoreboard

`wrapper_scoreboard` 接收两个 monitor 的 observation：

- `simple_bus_monitor.transfer_ap -> bus_tr_fifo`
- `wrapper_monitor.transfer_ap -> wrp_tr_fifo`

checker 先取得一笔完整 bus transfer，再丢弃早于其 `accept_cycle` 的 wrapper snapshot，最终要求选中的 `wrapper_transfer.sample_cycle == simple_bus_transfer.accept_cycle`。按 observed address 译码 target 后，比较该 target 的实际配置与 `simple_bus_transfer.resp_delay`；undefined target 的 expected delay 固定为 0。

两个 `uvm_tlm_analysis_fifo` 消除了同一采样拍内 analysis port 回调先后顺序对检查结果的影响。checker 只检查 wrapper timing，不检查 rdata、MMIO 状态或 bus driver 的计划值；test 结束时若仍有未处理 bus transfer 则报 fatal，较新的 wrapper 周期快照允许留在 FIFO。

## 8. DMEM 检查边界

DMEM 使用外置 `simple_ram`：

- 组合 read。
- 时钟上升沿按 byte enable 写 byte lane。
- `DMEM_BASE` 映射 `mem[0]`。
- 合法 DMEM window 访问不返回 error。

当前 DMEM reference model 按 `(addr - DMEM_BASE) >> 2` 保存关联数组状态，支持多地址、任意非零 `be` 的逐 byte lane 更新以及 write 后 readback。合法 DMEM 访问返回 error 或已建模地址读回不一致时报告 UVM error。

未写地址没有可靠初始化来源时不比较 `rdata`，计入 `partial_count`；write response 的 `rdata` 没有 spec 语义，只检查 `error` 并计入 `partial_count`。因此 `partial` 不等于失败，但说明该 transaction 只完成了当前可定义部分的检查。

若未来 DUT RAM 使用 `$readmemh` 预加载，reference model 必须加载同一镜像，不能一边预加载 DUT RAM、一边假设 reference 初值为 0。

## 9. MMIO 检查边界

MMIO 的 DUT 语义以 `dut/docs/periph_register_abi.md` 为准。当前 UVM reference model 只实现 GPIO0 的一部分；DUT 支持但 checker 未实现的行为不能因为随机访问通过而宣称已验证。

### 9.1 GPIO0 当前自动检查

当前 `simple_bus_scoreboard`：

- 按 word-aligned offset 译码，覆盖非零 `addr[1:0]`。
- 建模 `OUT` 和 `OE` 的逐 byte-lane write，并检查后续 readback。
- 对 GPIO0 已定义 word offset 检查 `error=0`。
- 对 GPIO0 unknown word offset 检查 `error=1`。
- 对尚未建模的已定义寄存器 read 只完成 error 检查，计入 `partial_count`。
- 对 write 只完成 error 检查并更新当前可建模参考状态，计入 `partial_count`；OUT/OE 的状态更新通过后续 readback 获得端到端可观测检查。

GPIO IN、IRQ_PENDING/W1C、IRQ_STATUS、外部 GPIO 输出和 IRQ side effect 尚未自动检查。

### 9.2 UART0 与 TIMER0

当前 `simple_bus_scoreboard` 未建立 UART0/TIMER0 reference model，相关 transfer 计入 `skip_count`。wrapper scoreboard 仍会检查这些 target 的 response delay，但这不能替代寄存器数据、error 或 side effect 检查。

若后续扩展，至少应按 ABI 覆盖 UART TX/RX event、read-clear/W1C/IRQ 语义，以及 TIMER MTIME/MTIMECMP/CTRL/STATUS、计数和 IRQ 关系。涉及外部输入或输出事件时，应建立独立 sideband monitor/driver，而不是让 reference model 直接访问 DUT interface。

### 9.3 统计口径

`simple_bus_scoreboard` 的四类结果含义：

| 计数 | 含义 |
|---|---|
| `correct_count` | 当前对该 transaction 定义的全部检查均完成且匹配。 |
| `error_count` | 任一已定义检查不匹配。 |
| `partial_count` | 已检查 error 或部分数据语义，但仍有当前基础设施未覆盖的结果。 |
| `skip_count` | target-specific reference model 尚未接入，功能检查整体跳过。 |

四类计数之和必须等于 `compare_count`。`partial_count` 和 `skip_count` 不直接导致 test FAIL，但必须在 verification report 中作为剩余验证边界披露。

## 10. SVA 边界

SVA 检查引脚级协议 invariant，不实现具体 testcase 或功能 reference model。

`tb/sva/simple_bus_sva.svh` 在 `simple_bus_if` 内 include，所有 assertion/state 受 `ASSERT_ON` 控制。SVA 不 import UVM package，不读取 item、transfer 或 checker 状态。

当前检查：

| assertion 类别 | 意义 |
|---|---|
| reset outputs | reset 时 request idle、response quiet，ready 符合当前 DUT 口径。 |
| control/payload known | request/response 有效时相关控制和 payload 无 X/Z。 |
| payload stable on backpressure | `valid && !ready` 期间 request payload 不变。 |
| single outstanding | pending response 返回前不接受第二笔 request。 |
| no orphan response | response 对应 pending request 或本拍 0-delay accepted request。 |

action block 使用清晰 assertion label 和 `[SVA]` 日志。`run_test.sh` 把 assertion `$error` 统计为 `SIM_ERROR`/FAIL。故障注入可用于调试 assertion infrastructure，但不是正常回归的强制用例。

DUT 内部状态断言若有需要，使用 `tb/sva` 下独立 assertion module + bind；不放入 UVM class。CPU trap/CSR/flush/interrupt invariant 不属于本 data-subsystem spec。

## 11. Checker 与 Reference Model 架构

### 11.1 simple bus scoreboard

`simple_bus_scoreboard` 只消费 observed `simple_bus_transfer`，负责 target decode、DMEM reference memory、GPIO0 最小 reference state 以及相应 data/error expectation。它不读取 planned item、wrapper item 或 virtual sequence 状态。

### 11.2 wrapper scoreboard

`wrapper_scoreboard` 按第 7.4 节消费 observed bus transfer 与 observed wrapper snapshot，只检查配置对应的实际 response delay，不检查功能数据。

### 11.3 一对多 observation

simple bus monitor 的 transfer 是唯一 bus truth source，同一对象同步广播给两个 scoreboard 和 coverage。subscriber 当前在回调内完成读取或将对象按 FIFO 顺序消费，不得修改 monitor 发布的共享对象；若未来需要长期保存，必须 clone。

各验证层职责：

- simple bus scoreboard：当前已建模的数据与 error 结果。
- wrapper scoreboard：delay wrapper 时序。
- SVA：周期级协议 invariant。
- coverage：实际场景是否发生。
- regression script：VCS 返回码、UVM severity 和 simulator error 汇总。

driver execution checker、完整 MMIO reference model 和 peripheral sideband checker 属于第 16 章的可扩展项，不计入当前环境完成条件。

## 12. Functional Coverage

`data_subsystem_coverage` 是 `uvm_subscriber #(simple_bus_transfer)`，只采样 simple bus monitor 发布的完整 observed transfer。coverage 证明场景实际发生过，不替代 scoreboard 或 SVA 的正确性判断。

当前 covergroup：

| covergroup | 内容 |
|---|---|
| `rw_data_cg` | read/write 类型、成功 transaction 的 read/write data 区间及 cross。 |
| `bus_behavior_cg` | op、observed idle gap、target、`addr[1:0]`、BE 访问宽度、observed response delay、response error。 |

当前 crosses：

- op x access width。
- op x response delay。
- target x response delay，undefined target 除外。
- target x address low bits。
- GPIO0 address low bits x response error。
- idle gap x response delay。

response delay bins 明确覆盖 0、1、2～7、8～15、16～63、64～126 和 127。console coverage 由 collector 的 `report_phase` 输出；VDB/URG HTML 报告在当前工具环境中不稳定，不作为 0835 收口条件。

当前 coverage 百分比只反映已定义 covergroup 的命中率，不表示 UART0/TIMER0 reference model、MMIO side effect 或完整协议空间已经验证。实际固定 seed 数值记录在 `verification_report.md`。

## 13. Test 与回归入口

当前注册 test：

| test | 目的 |
|---|---|
| `data_subsystem_base_test` | 创建完整 env，验证组件构建、vif 获取和空场景收尾。 |
| `simple_bus_smoke_test` | 直接启动固定 DMEM bus sequence，检查基础 read/write 与 zero-delay。 |
| `data_subsystem_smoke_test` | 通过 virtual sequence 协调固定和随机 DMEM wrapper delay 与 write/read。 |
| `DS_dmem_random_test` | DMEM 随机访问、已写地址复用和逐笔随机 wrapper delay。 |
| `DS_map_random_test` | 全 data-side 地址图随机访问，按固定 delay 档位覆盖四个 target，并回归 RTL-001。 |

`run_test.sh` 的 PASS 条件是 VCS runtime 正常结束，且 UVM_ERROR、UVM_FATAL、SVA/SystemVerilog runtime error 均为 0。`run_all.sh` 汇总上述 test；固定 seed 和逐项证据见 `verification_report.md`。

## 14. UVM、Directed Test 与 Out of Scope

UVM data-subsystem 环境不使用 `.mem` 程序执行流、crt0、trap handler、C/ASM self-check 程序、CPU commit trace、TB mailbox DMEM command 协议或 ISA reference model。这些属于 Verilator SoC directed regression。

本 spec 不覆盖：

- AXI-Lite 协议、adapter 或 interconnect。
- full SoC/CPU UVM。
- ISS lockstep 或 random instruction generation。
- RISC-V ISA reference model。
- CPU 内部 GPR/CSR/trap/interrupt 精确提交。
- multi-outstanding、transaction ID 或 out-of-order response。
- 真实 UART 串口物理层。
- FPGA 板级时序、PLL、外部 SRAM/Flash controller。

Verilator 与 VCS 回归必须并行保留；任何 UVM 文件不进入 Verilator 默认 filelist。超出本工作区边界的能力应在对应后续 release 建立新的 spec。

## 15. v6.0 环境完成标准

当前 v6.0 data-subsystem UVM 环境的收口标准：

- VCS 能运行 base、simple-bus smoke、data-subsystem smoke、DMEM random 和全地址图 random test。
- bus agent 与 wrapper agent 均进入 env，virtual sequence 能协调两者。
- `simple_bus_item`、`simple_bus_transfer`、`wrapper_item` 和 `wrapper_transfer` 的 planned/observed 所有权明确。
- monitor 正确重建 0 wait-state 和非 0 wait-state transaction。
- DMEM scoreboard 自动检查任意非零 BE 的 reference state 与 readback。
- GPIO0 scoreboard 检查 OUT/OE readback、known/unknown word-offset error，并明确标识部分检查。
- wrapper scoreboard 自动检查 0～127 范围内的实际配置与 observed response delay。
- SVA 可由 `ASSERT_ON=1` 启用，assertion runtime error 能被脚本计入 FAIL。
- functional coverage 使用 observed transfer，能输出非空 console report。
- `DS_map_random_test` 能复现 RTL-001 修复前 FAIL，并在同 seed 下验证修复后 PASS。
- Verilator ASM/C directed regression 在 RTL 修复后继续通过。
- DUT snapshot、filelist、README、仿真说明、本 spec 和 verification report 与冻结实现一致。

达到上述条件不表示第 16 章全部完成，也不表示 full CPU/SoC 或全部 MMIO 功能已经验证。

## 16. 可继续扩展的验证面

以下能力有工程价值，但因 0835 的教学目标、时间和 v7.0 即将归档而未纳入当前收口条件：

### 16.1 Driver execution checker

接入 bus driver `planned_item_ap`，与 observed transfer 按 FIFO 配对，检查 request payload 和非首笔 planned/observed idle gap。首笔 initial idle 需要单独定义锚点。

### 16.2 完整 MMIO reference model

补齐 GPIO0 IN、IRQ_PENDING/W1C、IRQ_STATUS，UART0 TX/RX/read-clear/W1C/IRQ，以及 TIMER0 MTIME/MTIMECMP/CTRL/STATUS、计数和 IRQ 语义。

### 16.3 Peripheral sideband agent

为 GPIO input、UART RX 建立受控激励，为 GPIO output/OE、UART TX event 和各 IRQ 建立独立 observation；side-effect checker 关联 bus transfer 与 sideband event。

### 16.4 Access profile 与 negative traffic

增加 CPU-shaped byte/half/word profile、MMIO known/unknown offset 权重、unmapped address、error response 和边界地址专属 sequence，避免通用 map random 的流量分布代替目标明确的 testcase。

### 16.5 Coverage closure

增加 MMIO register/op、known/unknown、side effect、target/idle、边界地址和 error crosses，定义 coverage exclusion、目标阈值和多 seed closure；工具条件允许时恢复 VDB/URG HTML 或合并报告。

### 16.6 Data-subsystem 硬件边界 SVA

增加 wrapper delay 输入不大于 127、配置在 outstanding 期间稳定、target response 只发生一次等 DUT 边界断言。若断言依赖 DUT 内部状态，应使用独立 assertion module + bind。

### 16.7 Reset、长回归与维护

增加 mid-test reset、checker/reference model reset、更多固定 seed、长随机回归和 CI 结果归档。未来若协议升级为 multi-outstanding，必须重做 monitor pending model、scoreboard 关联和 wrapper 配对规则。

## 17. 验证证据

本 spec 定义验证契约，不保存某一次运行的可变结果。v6.0 收口时实际执行的 test、seed、checker 统计、functional coverage、RTL-001 修复前后证据和剩余风险统一记录在 `verification_report.md`；原始 VCS 日志由脚本生成在本地 `sim/logs/`，不作为版本化验证结论。

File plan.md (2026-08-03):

# 0836 AXI-Lite adapter、interconnect 与 APB 外设桥执行计划

当前主线基线为 v7.0，已经完成：

- RV32I 五级流水线、M-mode CSR/trap/interrupt 和最小 SoC。
- GPIO0、UART0、TIMER0 与稳定的软件可见寄存器 ABI。
- data-side single-outstanding simple request/response bus。
- MEM wait/backpressure、delayed response/error 和精确提交语义。
- Verilator ASM/C 程序自检回归。
- v6.0 `data_subsystem` 独立 UVM/SVA 验证工作区和 DUT RTL 快照。

本计划承接 `docs/08xx/0836 AXI-Lite adapter、interconnect与APB外设桥规划.md`，目标是在不修改 CPU 内部 LSU 事务语义的前提下，把 SoC 数据侧升级为 AXI4-Lite + APB4：

```text
core LSU
  -> internal simple data bus
  -> simple_bus_to_axi_lite
  -> single-master AXI-Lite router
       -> AXI-Lite DMEM slave
       -> AXI-Lite-to-APB4 bridge
            -> APB4 GPIO0/UART0/TIMER0
       -> reserved ACCEL0 control window
       -> default error response
```

本计划以 RTL 功能落地为主。验证部分目前只定义层次、对象和收口方向；等 RTL 结构稳定后，再根据真实接口覆盖为详细验证计划。

## 0. 执行方式和固定边界 `已确认`

### 0.1 执行方式

- 每一章是一个可单独审查和确认的实现节点。
- 开始某一章前，先确认上一章的接口和职责没有遗留分歧。
- 每章完成后先检查语法、elaboration、接口方向、状态机边界和注释，再决定是否进入下一章。
- 当前计划描述文件、模块职责、连接结构和完成条件，不提前写逐行实现方案。
- 实现允许参考成熟开源 AXI/APB 项目，但关键模块按本项目 single-outstanding 边界独立实现。
- 若直接复制任何第三方源码，必须先确认许可证、固定来源版本并单独记录；默认只参考，不整仓引入。
- 不修改 `uvm/v6_0/data_subsystem` 已冻结工作区，它继续绑定 v6.0 simple bus DUT 快照。

### 0.2 固定协议边界

本阶段固定：

| 项目 | 边界 |
|---|---|
| CPU data-side | 保留现有 `data_bus_pkg` simple request/response |
| AXI 协议 | AXI4-Lite，保留 AW/W/B/AR/R 五通道独立握手 |
| 数据宽度 | 32 bit |
| 地址宽度 | 32 bit byte address |
| byte enable | simple bus `be` -> AXI `WSTRB` -> APB4 `PSTRB` |
| outstanding | 系统全局最多一笔未完成 read 或 write |
| 顺序 | in-order completion，无 transaction ID |
| 时钟 | CPU、AXI-Lite、APB4 和当前外设使用同一时钟域 |
| reset | 延续当前 active-low reset |
| IMEM | 保持现有固定响应接口，不纳入 0836 |
| DMEM | 改为 AXI-Lite slave 接入 |
| MMIO | GPIO0/UART0/TIMER0 通过 AXI-Lite-to-APB4 接入 |
| ACCEL0 | 只保留 direct AXI-Lite control slot，未实现时返回 DECERR |
| AXI4/burst/DMA | 不属于本阶段 |

### 0.3 固定目录方向

本阶段新增 RTL 原则上放入：

```text
rtl/
  common/
    axi_lite_pkg.sv
    apb_pkg.sv
  bus/
    axi_lite/
      simple_bus_to_axi_lite.sv
      axi_lite_error_slave.sv
      axi_lite_router.sv
    bridge/
      axi_lite_to_apb.sv
    apb/
      apb_mux.sv
      apb_to_reg_adapter.sv
  mem/
    axi_lite_ram.sv
  soc/
    data_subsystem.sv
    rv32i_soc.sv
```

开发过程中允许新旧 data subsystem 短期并行，但最终主线只保留一个 `data_subsystem` 集成边界。验证专用 driver、delay model 和 assertion 不放进上述可综合目录。

## 1. AXI-Lite/APB4 公共类型和目录骨架 `已完成`

### 1.1 新增文件 `已完成`

新增：

- `rtl/common/axi_lite_pkg.sv`
- `rtl/common/apb_pkg.sv`
- `rtl/bus/axi_lite/`
- `rtl/bus/bridge/`
- `rtl/bus/apb/`

### 1.2 `axi_lite_pkg.sv` 职责 `已完成`

统一定义本项目 AXI4-Lite 的：

- address/data/strobe/protection/response 宽度。
- AXI response 编码，包括 OKAY、SLVERR 和 DECERR。
- master-to-slave request 聚合类型。
- slave-to-master response 聚合类型。
- AW、W、B、AR、R 五通道的标准 payload。
- 空闲默认值和必要的公共辅助类型。

AXI-Lite 在 RTL 内优先使用 packed struct 聚合，而不是让每一级模块重复展开几十个离散端口。结构体只负责表达标准 channel，不携带本项目 target、delay 或验证状态。

建议采用两组总线方向类型：

| 类型职责 | 内容 |
|---|---|
| master -> slave | AW valid/payload、W valid/payload、B ready、AR valid/payload、R ready |
| slave -> master | AW ready、W ready、B valid/payload、AR ready、R valid/payload |

类型名称在执行本步时统一确定，后续模块不得重新定义同义结构。

### 1.3 `apb_pkg.sv` 职责 `已完成`

统一定义 APB4 的：

- 32-bit address/data 和 4-bit `PSTRB`。
- APB master-to-slave request 类型。
- APB slave-to-master response 类型。
- `PSEL/PENABLE/PWRITE/PADDR/PWDATA/PSTRB/PPROT`。
- `PREADY/PRDATA/PSLVERR`。

APB 类型不包含 GPIO/UART/TIMER 专用信号，外设 sideband 继续由 SoC integration 单独连接。

### 1.4 本步完成条件 `已完成`

- 两个 package 能被 VCS、Verilator 和当前综合语法路径独立解析。
- 类型方向清楚，不存在同一信号在 request/response 两侧重复定义。
- AXI-Lite 保留完整五通道握手字段，没有因为 single outstanding 删除标准 channel。
- APB 使用 APB4 byte strobe，不退回无法表达 byte write 的 APB3 最小子集。
- 文件头、注释和命名符合当前 RTL 风格。

## 2. Simple bus 到 AXI-Lite master adapter `已完成`

### 2.1 新增文件 `已完成`

新增：

- `rtl/bus/axi_lite/simple_bus_to_axi_lite.sv`

### 2.2 模块定位 `已完成`

该模块是 CPU 内部 LSU transaction 与标准 AXI-Lite 五通道之间的唯一转换边界。

上游继续使用：

- `data_bus_pkg::data_req_t`
- 离散 request ready
- `data_bus_pkg::data_resp_t`

下游使用第 1 章定义的 AXI-Lite request/response struct。

CPU、`mem_stage`、`pipeline_ctrl` 和 hazard 网络不感知 AW/W/B/AR/R。

### 2.3 功能结构 `已完成`

adapter 按全局 single-outstanding 组织为 read/write 两条受控路径：

- idle 时接受一笔 simple request并锁存 payload。
- read request 独立完成 AR handshake，再等待 R response。
- write request 同时准备 AW 和 W，但分别记录二者是否握手。
- AW 与 W 允许同拍、AW 先或 W 先完成。
- B response 只能在 AW 与 W 都被接受后结束本笔 write。
- R/B response 被接受时转换成唯一一次 simple response。
- AXI OKAY 映射为 `error=0`。
- AXI SLVERR/DECERR 映射为 `error=1`。
- transaction 完成后回到 idle，才允许下一笔 simple request。

第一版不追求 simple request 到 AXI request 的组合直通。adapter 使用清晰的注册状态保存 transaction，优先避免 CPU ready、AXI ready 和下游 slave 形成长组合路径。

### 2.4 Reset 和保护边界 `已完成`

- reset 清除所有 channel valid、握手完成标志和 pending transaction。
- stalled AXI channel 的 valid/payload 必须保持。
- simple request accepted 后不再依赖上游继续保持 payload。
- adapter 不生成第二笔 outstanding transaction。
- 不允许 B/R orphan response 被转换为 simple response。
- `AWPROT/ARPROT` 第一版使用固定、明确的合法值。

### 2.5 本步完成条件 `已完成`

- 模块接口只连接 simple bus 与 AXI-Lite，不包含地址译码、外设或 RAM。
- read/write 状态职责清楚。
- AW/W handshake 独立，不要求 `AWREADY && WREADY` 同拍。
- R/B stalled 时不会重复完成 simple response。
- 语法/elaboration 通过。
- 本步先做有限的结构检查；独立 channel delay 的完整功能验证留到 RTL 主线完成后统一规划。

## 3. AXI-Lite default error slave `已完成`

### 3.1 新增文件 `已完成`

新增：

- `rtl/bus/axi_lite/axi_lite_error_slave.sv`

### 3.2 模块定位 `已完成`

该模块为没有实际 target 的地址提供标准 AXI-Lite终止响应，避免 router 对未映射访问永久不返回。

### 3.3 功能结构 `已完成`

- read address 被接受后返回单笔 R response。
- write address和 write data分别被接受后返回单笔 B response。
- response code 默认使用 DECERR。
- AW/W 接受顺序不固定。
- B/R 在上游 ready 前保持有效和 payload 稳定。
- 同一时刻只保存一笔 read 或 write，遵守本项目 single-outstanding 边界。
- 不产生 memory/MMIO 副作用。

ACCEL0 未实现期间可以复用该模块返回 DECERR，不需要伪造一个读零写丢弃的 accelerator slave。

### 3.4 本步完成条件 `已完成`

- 任意合法单笔 read/write 都能结束，不会 hang。
- AW/W 任意顺序均能得到一次 B response。
- response stall 时保持稳定。
- reset 后没有残留 response。
- 模块不依赖 SoC 地址常量，可被 router 的任意 default route 复用。

## 4. Single-master AXI-Lite router `已完成`

### 4.1 新增文件 `已完成`

新增：

- `rtl/bus/axi_lite/axi_lite_router.sv`

### 4.2 模块定位 `已完成`

该模块是单 AXI-Lite master 的 address decoder 和 response router，不是多 master crossbar。

第一版至少包含以下逻辑目标：

| 目标 | 路由 |
|---|---|
| DMEM | 下游 AXI-Lite DMEM port |
| GPIO0/UART0/TIMER0 | 下游 AXI-Lite-to-APB bridge port |
| ACCEL0 | 预留下游 slot；未接入时走 DECERR |
| 其它地址 | default DECERR |

具体地址继续来自 `core_pkg.sv/soc_pkg.sv`，router 不重新硬编码一套地址图。

### 4.3 Write 路由结构 `已完成`

write 路径必须处理 W channel 没有地址的问题：

- 根据 AWADDR 选择并保存 target。
- 在 target 未确定前，不把 W transaction错误路由到其它 slave。
- 允许 AW/W 同拍或分拍到达。
- 保存本笔 write 的 AW/W 完成状态和 target。
- B response 完成前不覆盖 route state。
- 只允许被选中的 slave观察到有效 transaction。

第一版可以采用明确的内部缓冲或握手限制来处理 W 先到达，但不能依赖 master 永远 AW 先到达，也不能形成 AW/W 相互等待的死锁。

### 4.4 Read 路由结构 `已完成`

- AR handshake 时确定并保存 target。
- 只有被选中 slave 接收 AR。
- 只有该 slave 的 R response 能返回上游。
- R transaction 完成前不接受会覆盖 route state 的下一笔 read。

### 4.5 Read/write admission `已完成`

当前 adapter 不会同时发起 read/write，但 router 仍要防止同拍错误接受两笔而只保存一份状态。

第一版采用固定、可说明的 admission/优先级策略；不能服务的一侧通过 READY backpressure，不把吞掉请求作为简化方式。

### 4.6 本步完成条件 `已完成`

- router 只负责路由，不包含 RAM、APB状态机或外设寄存器逻辑。
- DMEM/MMIO/ACCEL/default 地址边界明确。
- AW/W/B route 生命周期完整。
- AR/R route 生命周期完整。
- default error slave 正确接入。
- 未选中的 slave 不产生误握手。
- single-outstanding 状态不会被第二笔请求覆盖。
- 语法/elaboration 通过。

## 5. AXI-Lite DMEM slave `已完成`

### 5.1 新增文件 `已完成`

新增：

- `rtl/mem/axi_lite_ram.sv`

### 5.2 模块定位 `已完成`

该模块提供可综合的 32-bit AXI-Lite RAM slave，用于 Verilator/VCS harness 和后续 FPGA wrapper。它替代主线 testbench 中 simple data bus 直连的 `simple_ram`，但不把程序镜像加载逻辑塞进 SoC。

`axi_lite_ram` 保持独立，最终由 testbench 或 FPGA wrapper 实例化并连接 SoC 透出的 DMEM AXI-Lite port。

### 5.3 功能结构 `已完成`

- 参数化 RAM word depth，地址映射与现有 DMEM window 一致。
- 支持 AXI-Lite read。
- 支持 AXI-Lite write。
- AW/W 独立接受并在两者均具备后提交一次写操作。
- `WSTRB[3:0]` 逐 byte lane 更新。
- read 返回完整 32-bit aligned word。
- B/R response 为注册响应，并支持上游 backpressure。
- 地址越界返回 SLVERR，不访问非法数组索引。
- RAM 存储数组允许 testbench 通过层级或已有加载流程写入，但模块本体不解析 plusarg、不实现 mailbox、不随机延迟。

### 5.4 与现有 `simple_ram` 的关系 `已完成`

- 本步不立即删除 `rtl/mem/simple_ram.sv`。
- 新旧模块在 SoC 切换完成前可以并存。
- v7.0 UVM snapshot 中的 `simple_ram` 不修改。
- 主线所有 filelist 和 testbench 切换到 AXI-Lite RAM 后，再决定根目录旧 `simple_ram` 是否仍被 FPGA/其它路径使用。

### 5.5 本步完成条件 `已完成`

- word/byte lane 地址语义与当前 CPU 保持一致。
- `WSTRB` 任意非零组合都按 lane 更新。
- read-after-write 能返回更新后的完整 word。
- AW/W/B 和 AR/R 均符合 stalled payload 保持规则。
- 越界访问得到明确 response。
- 无 testbench-only 行为进入可综合功能路径。

## 6. AXI-Lite-to-APB4 bridge `已完成`

### 6.1 新增文件 `已完成`

新增：

- `rtl/bus/bridge/axi_lite_to_apb.sv`

### 6.2 模块定位 `已完成`

该模块上游是一个 AXI-Lite slave port，下游是一个 APB4 master port。它集中吸收 AXI 五通道复杂性，让低速寄存器外设只面对 APB setup/access。

### 6.3 Write 路径结构 `已完成`

- 独立接受并保存 AW 和 W。
- 两者都完成后启动一次 APB write。
- APB write 使用 AXI address、data、strobe 和 protection 信息。
- APB ACCESS 完成后生成 AXI B response。
- `PSLVERR=0` 返回 OKAY。
- `PSLVERR=1` 返回 SLVERR。
- BREADY 未到时保持 BVALID/BRESP。

### 6.4 Read 路径结构 `已完成`

- 接受并保存 AR。
- 启动一次 APB read。
- APB ACCESS 完成后保存 PRDATA/PSLVERR。
- 返回 AXI RDATA 和 OKAY/SLVERR。
- RREADY 未到时保持 RVALID/RDATA/RRESP。

### 6.5 APB 状态边界 `已完成`

- 每笔 APB transaction 必须经历 SETUP 和 ACCESS。
- SETUP 后才能拉高 PENABLE。
- PREADY 为 0 时保持 PSEL、PENABLE、地址、方向和 payload 稳定。
- access completion 后撤销 PSEL/PENABLE。
- 每笔 AXI transaction 最多产生一次 APB transaction。
- bridge 同一时刻只处理一笔 read 或 write。
- read/write 同时到达时采用固定 admission 策略，不同时吞下两笔。

### 6.6 本步完成条件 `已完成`

- AW/W 任意顺序不会丢失 write。
- APB zero-wait 和 multi-cycle wait 结构均成立。
- PSLVERR 能准确映射到对应 B/R response。
- AXI response backpressure 不会重复 APB side effect。
- reset 清除 AXI pending 和 APB state。
- 模块不包含具体 GPIO/UART/TIMER 地址译码。

## 7. APB mux 与现有外设适配 `已完成`

### 7.1 新增文件 `已完成`

新增：

- `rtl/bus/apb/apb_mux.sv`
- `rtl/bus/apb/apb_to_reg_adapter.sv`

现有以下寄存器模块原则上保留内部寄存器和 side effect 逻辑：

- `rtl/periph/mmio_gpio.sv`
- `rtl/periph/mmio_uart.sv`
- `rtl/periph/mmio_timer32.sv`

### 7.2 `apb_mux.sv` 职责 `已完成`

- 根据 APB PADDR 选择 GPIO0、UART0 或 TIMER0。
- 对每个外设产生独立、one-hot 的 APB slave request。
- mux 被选中外设的 PREADY、PRDATA 和 PSLVERR。
- APB 地址未命中任何实现外设时返回错误并正常结束，不永久等待。
- ACCEL0 不进入 APB mux，它属于预留 direct AXI-Lite control slot。

### 7.3 `apb_to_reg_adapter.sv` 职责 `已完成`

该模块把 APB4 access completion 转换为现有外设寄存器接口：

- APB write/read 转换为现有 valid/we/be/addr/wdata。
- `PSTRB` 映射为外设 byte enable。
- 外设 rdata 映射为 PRDATA。
- 外设 access fault 映射为 PSLVERR。
- 当前固定响应寄存器块可使用 `PREADY=1`。
- 只有真正 APB ACCESS completion 才产生一次外设访问脉冲。

同一 adapter 可以参数化复用，不为 GPIO/UART/TIMER 复制三套相同 APB握手逻辑。

### 7.4 外设 side effect 边界 `已完成`

接入后必须保持：

- GPIO W1C 只执行一次。
- UART TX event 只产生一次。
- UART RX read side effect 只执行一次。
- TIMER register write 只执行一次。
- APB SETUP 不触发寄存器访问。
- APB ACCESS 等待期间不重复触发寄存器访问。
- 未定义 register offset 返回 PSLVERR。

### 7.5 本步完成条件 `已完成`

- APB mux 的地址译码与 one-hot 选择正确。
- 地址图和现有软件 ABI 不变。
- 三个现有外设无需重复实现 AXI-Lite 五通道。
- APB fixed-ready 外设路径功能闭合。
- 非法外设地址和非法 register offset 的错误层次清楚。
- side effect 触发点统一为 APB completion。

## 8. 新 AXI data subsystem 集成 `已完成`

### 8.1 集成策略 `已完成`

开发期间先让新 AXI data subsystem 与当前 `rtl/soc/data_subsystem.sv` 并行，避免在 adapter/router/bridge 尚未连通时破坏现有 SoC。

本步并行实现使用 `rtl/soc/axi_data_subsystem.sv` 和 `axi_data_subsystem` 模块名，后续在 SoC 切换与旧实现清理节点统一名称。

新模块稳定后，最终主线仍保留一个通用名称 `data_subsystem`；旧 response-delay wrapper 实现由 v7.0 tag 和 UVM DUT snapshot 保存，不在主线长期保留两套同名职责。

### 8.2 集成内容 `已完成`

新的 data subsystem 负责实例化和连接：

- simple-bus-to-AXI-Lite adapter。
- AXI-Lite router。
- default error slave。
- AXI-Lite-to-APB4 bridge。
- APB mux。
- 三个 APB-to-register adapter。
- GPIO0、UART0、TIMER0 寄存器模块。

它对外保留：

- core-side simple request/response。
- downstream DMEM AXI-Lite port。
- GPIO/UART 外部 sideband。
- GPIO/UART/TIMER interrupt。
- 必要的 transaction/target 观察信号。

它不再包含：

- `*_resp_delay_cycles_i`。
- response-delay counter wrapper。
- simple RAM 固定响应端口。
- testbench mailbox 或随机延迟配置。

### 8.3 地址和 target 语义 `已完成`

- DMEM 送往外部 AXI-Lite DMEM port。
- GPIO0/UART0/TIMER0 送往 APB bridge。
- ACCEL0 未实现时走 DECERR。
- 完全未映射地址走 DECERR。
- APB 外设 window 内未定义 offset 走 SLVERR。
- 保留区分 DMEM/MMIO/undefined 的观察能力；若新增 target enum，应同步 `soc_pkg.sv`，但不修改已冻结 UVM snapshot。

### 8.4 中断和 sideband `已完成`

- GPIO/UART/TIMER interrupt 仍直接汇总到 SoC/core，不经过 AXI/APB transaction channel。
- GPIO pin、UART RX/TX event 仍是独立 sideband。
- 总线改造不改变中断 pending、enable、trap entry 或 MRET 语义。

### 8.5 本步完成条件 `已完成`

- 新 data subsystem 可以作为独立 elaboration top。
- core request 能到达正确 AXI target。
- AXI response 能回到唯一一次 simple response。
- APB 外设路径完成连接。
- error 分层符合 DECERR/SLVERR 规划。
- response-delay wrapper 已从新实现中消失。
- 模块职责以集成为主，没有重新塞回多个重复协议状态机。

## 9. `rv32i_soc` 切换到新 data subsystem `已完成`

### 9.1 修改文件 `已完成`

主要修改：

- `rtl/soc/rv32i_soc.sv`
- `tb/sv/tb_rv32i_soc.sv`
- Verilator/VCS 当前 SoC 顶层使用的必要 package 和 filelist。

本步在切换 SoC RTL 的同时完成最小 testbench 端口迁移，保证当前仿真 top 不因接口变化而失去编译能力；不在同一节点展开随机 delay、完整 scoreboard 或专项 testcase。

### 9.2 SoC 顶层变化 `已完成`

- core 与 data subsystem 之间的 simple bus 接线保持不变。
- 旧离散 DMEM we/be/addr/wdata/rdata 端口替换为 downstream DMEM AXI-Lite port。
- 删除四路 `*_resp_delay_cycles_i` SoC 端口。
- GPIO/UART sideband 和 interrupt 端口保持。
- commit/trap/mem_wait 观察口保持。
- data transaction 观察口根据新层次更新注释和语义。

### 9.3 最小 testbench 迁移 `已完成`

- `tb_rv32i_soc.sv` 改接新的 downstream DMEM AXI-Lite port。
- testbench 实例化第 5 章完成的 `axi_lite_ram`，继续承担程序数据镜像和 PASS/FAIL 状态 RAM。
- 第一版 TB 只使用固定、无额外 backpressure 的 AXI-Lite RAM 响应配置，使 SoC 切换后先恢复可编译、可运行的基线。
- simple ROM、程序镜像加载、commit/trap trace、PASS/FAIL、GPIO/UART 外部激励和非 delay mailbox 功能继续保留。
- 旧四路 `*_resp_delay_cycles_i` 连接与 TB 状态只能在新 AXI RAM 接线完成后删除，不能留下新 SoC 配旧 TB 的中间状态。
- 当前 ASM/C 仿真入口使用的 filelist 同步加入 AXI/APB packages 和 RTL 模块。

本步不提供内部 APB `PREADY` 注入。当前 GPIO0/UART0/TIMER0 在 SoC 集成中固定 `PREADY=1`，APB multi-cycle wait 由第 11 章的 bridge 模块级 testbench 验证。

### 9.4 CPU RTL 边界 `已完成`

原则上不修改：

- `mem_stage.sv` 的 LSU request/response 结构。
- `pipeline_ctrl.sv` 的 MEM wait 规则。
- trap/interrupt 精确提交逻辑。

若集成时发现必须修改 CPU RTL，应先判断是接口适配遗漏还是现有 bug，不因 AXI 五通道方便而把 channel 状态引入 CPU。

### 9.5 本步完成条件 `已完成`

- `rv32i_soc` 能完整 elaboration。
- `tb_rv32i_soc` 能连接新 SoC、AXI-Lite RAM 和现有 ROM/sideband，不引用已经删除的端口。
- `sim/soc_asm`、`sim/soc_c` 使用的 Verilator top 和 filelist 至少能完成编译/elaboration。
- CPU 侧接口和流水线控制没有 AXI channel 信号。
- downstream DMEM 使用标准 AXI-Lite结构。
- MMIO 通过 APB 路径实例化。
- 所有删除或新增端口在注释中准确反映。
- 未引入悬空 AXI/APB channel。

## 10. 主线切换、旧 wrapper 清理与 RTL 收口 `已完成`

### 10.1 主线文件收敛 `已完成`

完成新 SoC RTL 切换后：

- 新 AXI data subsystem 成为正式 `rtl/soc/data_subsystem.sv`。
- 删除开发期间的临时并行模块或重复顶层。
- 清理旧 response-delay wrapper 逻辑。
- 清理主线 RTL 中已经过时的固定响应、wrapper 和 delay input 注释。
- 保留 v7.0 tag 与 `uvm/v6_0/data_subsystem/dut/rtl` 快照，不回写旧验证资产。

### 10.2 `simple_ram` 和旧接口清理 `已完成`

- 根目录 `simple_ram.sv` 保留为 simple bus 独立场景和历史教学参考，并在头注释中明确标记 legacy。
- SoC 主线 testbench 已切换为 `axi_lite_ram`，不再实例化 `simple_ram`。
- 旧 SoC 离散 DMEM 端口和 TB delay 配置不能半切换；主线 RTL 与后续 testbench 必须采用一致边界。

### 10.3 静态检查 `已完成`

RTL 功能阶段先完成：

- VCS/Verilator 语法解析。
- package/filelist 编译顺序。
- top-level elaboration。
- `default_nettype none` 下无隐式 net。
- 无未驱动、多驱动和明显宽度错误。
- 基本 lint/Yosys elaboration 能通过的部分。
- 对照开源参考重新检查 AW/W/B、AR/R 和 APB 状态生命周期。

这些检查只说明 RTL 结构闭合，不代替后续动态协议验证。

### 10.4 本步完成条件 `已完成`

- 主线只有一个 data subsystem 实现。
- 旧 wrapper 不再参与主线 AXI/APB transaction。
- AXI/APB RTL 目录和模块职责稳定。
- SoC、packages、filelists 和注释同步。
- RTL 能作为下一阶段详细验证计划的固定 DUT。

## 11. SoC 集成级定向验证与问题收口 `已完成`
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

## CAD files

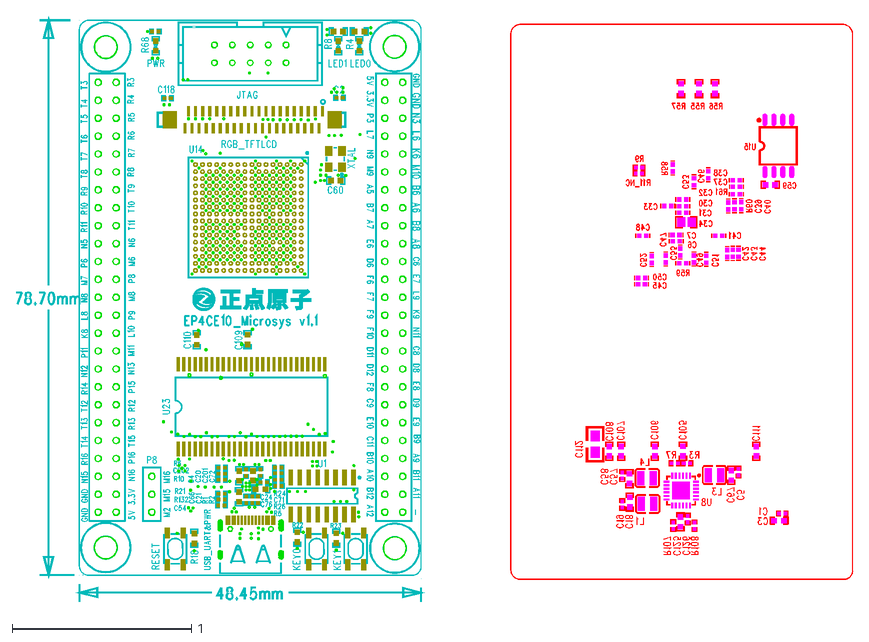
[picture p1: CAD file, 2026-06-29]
fpga/fpga_e10_board_resources/3_正点原子E10最小系统板原理图/E10 最小系统板V1.1.DXF
4.67 x 3.27

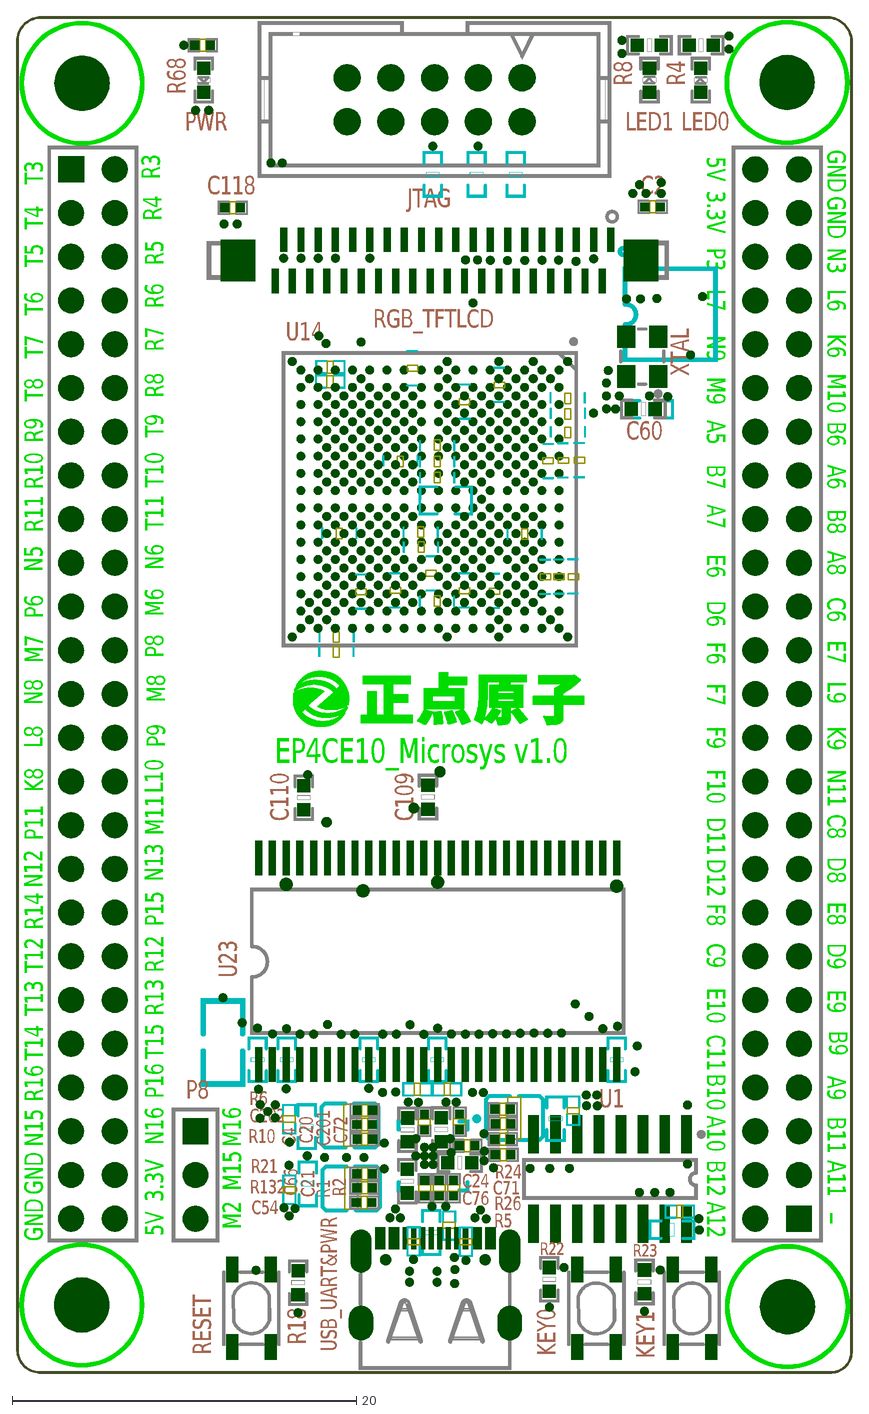
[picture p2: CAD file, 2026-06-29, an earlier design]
fpga/fpga_e10_board_resources/3_正点原子E10最小系统板原理图/E10 最小系统板V1.0(1).dxf
T13
T12
R14
N12
P11
K8
L8
N8
M7
N5
T11
P6
T10
T9
T8
T5
T7
T3
T4
T6
R12
P15
N13
M11
L10
P9
M8
P8
M6
R11
N6
R10
R3
R9
R5
R8
R6
R7
R4
R13
M10
B6
A6
B8
A8
C6
E7
L9
K9
C8
D8
N11
E8
D9
E9
B11
B9
_
A11
A9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

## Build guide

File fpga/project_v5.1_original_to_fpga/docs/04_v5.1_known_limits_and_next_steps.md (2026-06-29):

# v5.1 已知边界与后续方向

本文档记录 v5.1 FPGA 版当前已经验证的范围、仍需注意的限制，以及后续可扩展方向。它不是缺陷清单，而是工程交接时应显式写下的边界。

## 当前完成范围

| 类别 | 状态 |
| --- | --- |
| CPU core | RV32I core RTL 保持原样，未因 FPGA 上板修改流水线实现。 |
| SoC 地址图 | GPIO、UART、TIMER0 MMIO 基地址保持不变。 |
| FPGA top | 已接入 E10 板载 50 MHz 时钟、复位、2 个 LED、2 个 KEY、UART RX/TX。 |
| IMEM/DMEM | 已替换为 FPGA 可综合/可初始化的 16 KiB + 16 KiB 存储器。 |
| C 裸机流程 | 已支持 C 程序编译、镜像生成、MIF/MEM 更新和 SOF 打包。 |
| 板级验证 | 已通过 LED、KEY、TIMER polling、TIMER interrupt 和综合 demo。 |
| 时序 | 当前 50 MHz 约束下 setup/hold 均通过。 |

## 已知边界

| 边界 | 当前状态 | 影响 |
| --- | --- | --- |
| 工作频率 | 以 50 MHz 为正式目标 | README 中约 52.65 MHz 是粗算理论值，不代表可直接提高时钟。 |
| 存储容量 | IMEM/DMEM 各 16 KiB | C 程序、静态数据、`.bss` 和栈都必须控制在该范围内。 |
| 配置方式 | 当前使用 `.sof` SRAM 下载 | FPGA 断电后程序消失，尚未整理配置 Flash 固化流程。 |
| UART | 简单 TX/RX PHY，无 FIFO | 适合低速状态输出和简单交互，高吞吐场景可能丢数据或需要软件等待。 |
| GPIO | 只实际接出 2 个 KEY 和 2 个 LED | SoC 内部 GPIO 位宽更大，但当前板级 top 只暴露少量 IO。 |
| 中断 | 已验证 TIMER interrupt | GPIO/UART interrupt 相关硬件路径存在，但板级覆盖还不完整。 |
| 时钟域 | 单 `sys_clk` 设计 | 尚未处理多时钟域 CDC 问题。 |
| 调试接口 | 无 JTAG debug、无片上逻辑分析集成说明 | 调试主要依赖 LED、UART、测试程序和 Quartus 报告。 |
| 外部存储 | 未接 SDRAM/SRAM/Flash 数据总线 | 当前程序必须完全放入片上 RAM 初始化镜像。 |

## 非通用假设

这些假设对当前工程成立，但后续复用时需要重新确认：

- 目标器件固定为 `EP4CE10F17C8`，memory wrapper 使用 Cyclone IV E/M9K 相关实现。
- `fpga_dmem.sv` 使用 `altsyncram`，不是跨 FPGA 厂商通用 RAM wrapper。
- IMEM/DMEM 初始化路径相对 Quartus 工程目录成立，移动工程目录时要重新检查路径。
- `sys_clk` 为 50 MHz，UART PHY 参数按 50 MHz / 115200 baud 设置。
- KEY/LED 的有效电平按当前 E10 板卡连接处理，移植到其他板卡时要检查极性。
- C 裸机程序不使用标准库运行时，不依赖操作系统、堆、文件系统或动态内存。

## 需要优先保护的回归点

后续改 RTL 或脚本时，建议把下面几项当作最小回归：

| 优先级 | 回归项 | 原因 |
| ---: | --- | --- |
| 1 | `0500_fpga_led_spark.c` | 快速确认 reset、IMEM、GPIO output 和基础执行。 |
| 2 | `0503_fpga_timer_blink.c` | 确认 TIMER0 MMIO 读写和 polling 路径。 |
| 3 | `0504_fpga_timer_irq.c` | 覆盖 trap、CSR、中断和 DMEM 栈保存/恢复，是 memory timing 关键用例。 |
| 4 | `0505_fpga_key_led_uart.c` | 覆盖多个外设组合路径。 |
| 5 | Quartus STA | 确认 setup/hold 未因改动退化。 |

## 后续扩展方向

| 方向 | 建议 |
| --- | --- |
| UART FIFO | 在 `mmio_uart` 或 PHY 边界加入 TX/RX FIFO，减少软件轮询压力。 |
| GPIO 中断上板验证 | 增加 KEY 触发 GPIO interrupt 的独立 demo，覆盖 MEIP 路径。 |
| UART RX 中断验证 | 增加串口输入触发 UART interrupt 的 demo，覆盖 RXDATA/IRQ_PENDING 行为。 |
| 配置 Flash 固化 | 补充 E10 板卡对应的 Flash 下载和上电自启动流程。 |
| 更大程序空间 | 评估外部存储或更大 FPGA 器件；在 EP4CE10 上继续扩大片上 RAM 会明显挤压资源。 |
| 构建自动化 | 增加一键 `update_fpga_mem + quartus compile` 脚本，减少手工漏步骤。 |
| 报告归档 | 每次阶段性修改后归档 `.fit.rpt`、`.sta.rpt`、资源表和验证程序版本。 |
| 仿真/上板一致性 | 给 FPGA memory wrapper 增加可仿真的替代模型，减少只在板上暴露的问题。 |

## 交接建议

若后续有人接着做 v5.2 或移植到其他板卡，建议先确认三件事：

1. 是否仍要求 CPU core RTL 不动。
2. 目标 FPGA 的 block RAM 读时序是否与当前 wrapper 假设一致。
3. 软件镜像容量、链接脚本和 RTL 地址常量是否同步。

只要这三点没有漂移，当前 v5.1 的文档和脚本就可以作为后续版本的稳定基线。

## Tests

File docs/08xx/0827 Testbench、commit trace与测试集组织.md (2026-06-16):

# 0827 Testbench、commit trace 与测试集组织

> 文档编号：0827  
> 所属系列：082x RISC-V 最小教学核项目实践  
> 文档定位：定义第一版 RV32I 教学核的 testbench 结构、pass/fail 机制、commit trace 和 directed test 组织方式  
> 前置文档：`0822 最小教学核工程目录、顶层接口与命名约定.md`、`0825 Hazard控制：forwarding、stall、flush与kill.md`、`0826 裸机程序、ROM与RAM加载与工具链使用示例.md`

本文解决的是“怎么证明教学核真的跑对了”。第一版不要只靠看波形，也不要只跑一个 smoke test。最低目标是：每个关键功能都有 directed test，testbench 能自动判断 pass/fail，出错时能通过 commit trace 定位到第一条错误提交。

本文默认项目假设：

| 项目 | 假设 |
|---|---|
| DUT | 当前维护路径为五级流水 `core_pipeline5`；早期单周期顶层只作为历史阶段 |
| imem | `$readmemh` 加载 32 bit word `.mem` |
| dmem | testbench 可观察内部 memory 或 store 事件 |
| pass/fail | 当前实现采用固定 `TEST_STATUS_ADDR` store 检查 |
| trace | 第一版以 WB 阶段 valid 指令作为 commit |
| 测试类型 | directed test 优先，后续再加随机/参考模型 |

当前实现状态：

| 项目 | 当前状态 |
|---|---|
| PASS/FAIL | 已实现，程序写 `DMEM_BASE + 0x100`，写 1 为 PASS，其他值为 FAIL |
| timeout | 已实现，超过固定周期未结束则打印 TIMEOUT |
| commit trace | 已实现，当前五级流水 testbench 打印提交 PC、指令 ID、原始指令和写回信息 |
| DMEM/stack 统计 | 已实现，仿真结束时打印运行期 DMEM 访问范围和最大栈深 |
| directed test 编号分组 | 已实现，测试文件使用四位编号前缀，脚本支持四位编号或完整 basename |
| scoreboard / reference model / ISS | 选择实现，可暂时不用；当前 directed self-check + commit trace 已满足 v2.0 教学核验证 |
| unsupported / illegal / misaligned 测试 | 选择实现，可暂时不用；当前 v2.0 假设程序只使用合法指令且访存对齐 |
| SystemVerilog assertion / coverage | 选择实现，可暂时不用；后续验证收口或加 CSR/trap 时再系统补 |

## 第1章 testbench 顶层结构

### 1.1 基本结构

```text
tb_core
    ├── clock/reset 产生
    ├── simple_rom/imem
    ├── simple_ram/dmem
    ├── core_top DUT
    ├── imem 加载
    ├── pass/fail 检查
    ├── commit trace monitor
    └── timeout watchdog
```

testbench 的职责是搭环境和检查结果，不是替 CPU 执行指令。

### 1.2 顶层连接

```systemverilog
core_top u_core (
    .clk_i              (clk),
    .rst_n_i            (rst_n),

    .imem_addr_o        (imem_addr),
    .imem_rdata_i       (imem_rdata),

    .dmem_we_o          (dmem_we),
    .dmem_be_o          (dmem_be),
    .dmem_addr_o        (dmem_addr),
    .dmem_wdata_o       (dmem_wdata),
    .dmem_rdata_i       (dmem_rdata),

    .commit_valid_o     (commit_valid),
    .commit_pc_o        (commit_pc),
    .commit_instr_o     (commit_instr),
    .commit_reg_we_o    (commit_reg_we),
    .commit_rd_o        (commit_rd),
    .commit_rd_wdata_o  (commit_rd_wdata)
);
```

`commit_*` 信号不是 ISA 必需接口，但对教学项目非常有价值。

## 第2章 pass/fail 机制

### 2.1 固定 cycle 后检查 dmem

最简单方式：

```systemverilog
initial begin
    rst_n = 1'b0;
    repeat (5) @(posedge clk);
    rst_n = 1'b1;

    repeat (200) @(posedge clk);

    if (u_dmem.mem[0] == 32'd7) begin
        $display("PASS");
    end else begin
        $display("FAIL: dmem[0] = %08h", u_dmem.mem[0]);
    end

    $finish;
end
```

优点是简单；缺点是每个测试要写不同检查逻辑，且程序提前失败时不一定能马上停。

### 2.2 TEST_STATUS_ADDR 地址

更通用的方式是约定一个 dmem 地址作为测试结束状态：

| 地址 | 含义 |
|---|---|
| `0x0001_0100` | 程序写 1 表示 pass，写其他值表示 fail |

testbench 观察 store：

```systemverilog
localparam logic [31:0] TEST_STATUS_ADDR = 32'h0001_0100;

always_ff @(posedge clk) begin
    if (rst_n && dmem_we && (dmem_addr == TEST_STATUS_ADDR)) begin
        if (dmem_wdata == 32'd1) begin
            $display("PASS");
        end else begin
            $display("FAIL: status = %08h", dmem_wdata);
        end
        $finish;
    end
end
```

为了和本文 DMEM_BASE `0x0004_0000` 保持一致，推荐把 `TEST_STATUS_ADDR` 放在数据区起始处附近，例如：

| 地址 | 用途 |
|---|---|
| `0x0004_0000` | 普通测试结果 word0 |
| `0x0004_0004` | 普通测试结果 word1 |
| `0x0004_0100` | `TEST_STATUS_ADDR` |

汇编中写 `0x0004_0100`：

```asm
    lui  x31, 0x40
    addi x30, x0, 1
    sw   x30, 0x100(x31)
```

### 2.3 timeout 必须有

任何自动化仿真都要有 timeout：

```systemverilog
initial begin
    repeat (5000) @(posedge clk);
    $display("FAIL: timeout");
    $finish;
end
```

否则 PC 卡死、程序没写 `TEST_STATUS_ADDR`、flush 出错等情况会让回归一直挂着。

## 第3章 commit trace

### 3.1 trace 格式

建议每条提交指令打印一行：

```text
cycle pc        instr     rd  wdata     mem_we mem_addr  mem_wdata
12    00000000  00300093  01  00000003  0      --------  --------
13    00000004  00400113  02  00000004  0      --------  --------
14    00000008  002081b3  03  00000007  0      --------  --------
15    00000010  00322023  --  --------  1      00010000  00000007
```

第一版可以把 GPR 写回和 store 事件分开打印，也可以打印在同一行。关键是能定位：

- 哪个 cycle。
- 哪个 PC。
- 哪条 instruction。
- 写了哪个 rd，写入什么值。
- 是否 store，store 地址和值是什么。

### 3.2 trace monitor 示例

```systemverilog
integer trace_fd;

initial begin
    trace_fd = $fopen("build/commit.trace", "w");
end

always_ff @(posedge clk) begin
    if (rst_n && commit_valid) begin
        $fwrite(trace_fd, "%0t %08h %08h", $time, commit_pc, commit_instr);

        if (commit_reg_we) begin
            $fwrite(trace_fd, " x%0d %08h", commit_rd, commit_rd_wdata);
        end else begin
            $fwrite(trace_fd, " -- --------");
        end

        $fwrite(trace_fd, "\n");
    end
end
```

store trace 可以在 dmem monitor 里另写：

```systemverilog
always_ff @(posedge clk) begin
    if (rst_n && dmem_we) begin
        $display("STORE addr=%08h be=%b wdata=%08h", dmem_addr, dmem_be, dmem_wdata);
    end
end
```

### 3.3 commit 定义

第一版可以简单定义：

| 事件 | commit 定义 |
|---|---|
| ALU/load/JAL/LUI | WB 阶段 valid |
| store | MEM 阶段 dmem 写发生 |
| branch | WB 阶段 valid，也可只记录 PC/instr |
| bubble/flush | 不 commit |

后续加入异常、中断、可变延迟 memory 后，commit 定义要更严格，不能简单等同于 WB valid。

## 第4章 DMEM/stack 运行时统计

除 PASS/FAIL 和 commit trace 之外，testbench 还可以在仿真结束时打印本次程序的 DMEM 访问范围和最大栈深：

```text
PASS after 3652 cycles
DMEM access range: 0x00040200 - 0x0007fffc
Stack max used:    80 bytes
```

当前五级流水 testbench 采用以下统计口径：

| 统计项 | 统计方法 | 说明 |
|---|---|---|
| `DMEM access range` | 监控 `dmem_re || dmem_we`，记录 `dmem_addr` 最小值和最大值 | 用来快速判断程序是否访问到预期数据区、栈区或越界地址 |
| `Stack max used` | 通过层级路径读取 `u_core.u_regfile.gpr_q[2]`，记录 `sp/x2` 的最小值 | 栈向低地址增长，所以 `STACK_TOP - min(sp)` 就是运行期间看到的最大栈深 |

注意：DMEM 地址范围和**真正“用了多少 RAM”**不是完全等价的，因为程序可能访问了高地址和低地址，中间未必全用；而栈深度用 `min(sp)` 统计通常最有价值。

还有两个实现细节：

- `TEST_STATUS_ADDR = DMEM_BASE + 0x100` 是 testbench 的结束标志地址，不计入程序自身的 DMEM 访问范围，否则所有测试的最低访问地址都会被 PASS/FAIL 写状态字污染。
- 汇编测试通常不初始化 `sp`，这时栈统计会打印 `SP not initialized to stack top`；C 测试由 `crt0.S` 初始化 `sp = __stack_top`，所以更适合观察栈深。

## 第5章 directed test 组织

### 5.1 测试命名

建议测试按功能分组：

```text
sw/asm/
    0001_smoke.S
    0101_branch.S
    0102_alu_imm.S
    0103_alu_reg.S
    0104_load_store.S
    0105_jump.S
    0106_u_type.S
    0301_pipeline5_nofwd_noredirect.S
    0302_pipeline5_fwd_noredirect.S
    0303_pipeline5_fwd_redirect.S

sw/c/
    0201_c_smoke.c
    0202_dmem_init.c
    0401_control_mix.c
```

当前使用四位编号：前两位表示测试部分，后两位表示该部分内的测试序号。脚本支持两种参数形式：

```bash
sim/pipeline5_asm/run_test.sh 0102
sim/pipeline5_asm/run_test.sh 0102_alu_imm
```

编号能保证回归输出稳定排序，也能让单个测试命令更短。

### 5.2 每个测试只证明少数事情

| 测试 | 不要混入 |
|---|---|
| `addi` | branch、load-use、复杂函数调用 |
| `load_ext` | branch flush |
| `forward_exmem` | JALR、store byte enable |
| `branch_flush_store` | 大量无关 ALU 运算 |

测试短，失败时才容易定位。

当前仓库里有些文件为了减少数量，会把一组相关指令或一组流水线场景合在一起，例如 `0102_alu_imm.S` 覆盖全部 I-type ALU，`0302_pipeline5_fwd_noredirect.S` 覆盖多类 data hazard。这个选择对当前教学阶段是可以接受的；如果后续要做更严格 regression，可再拆成更细的 directed test。

### 5.3 汇编测试模板

```asm
.option norvc
.section .text.init
.global _start

_start:
    jal  x0, test_main

.section .text
test_main:
    # test body
    addi x1, x0, 3
    addi x2, x0, 4
    add  x3, x1, x2

    # write result
    lui  x10, 0x40
    sw   x3, 0(x10)

    # pass
    addi x30, x0, 1
    sw   x30, 0x100(x10)

done:
    jal  x0, done
```

实际测试里可以把写 pass/fail 的代码做成宏，但初期先展开写清楚更直观。

## 第6章 scoreboard 和参考模型

### 6.1 第一版 scoreboard 可以很简单

当前 v2.0 没有实现独立 scoreboard 类或参考模型。现在采用的是“程序自检 + testbench 观察状态地址 + commit trace 辅助 debug”：

| 检查对象 | 当前实现 |
|---|---|
| pass/fail | 已实现，观察 `TEST_STATUS_ADDR` |
| dmem 结果 | 主要由测试程序自己 load 后比较；testbench 只统计访问范围 |
| commit trace | 已实现打印，但尚未自动和 expected trace 比较 |

这个强度足够支撑当前合法 RV32I + 对齐访存的教学核验证。它不能替代 reference model；如果后续加入随机测试、CSR/trap、非法指令、不对齐访问、可变延迟 memory 或外设 MMIO，再补 scoreboard/reference model 更合适。

最简单 scoreboard：

| 检查对象 | 方法 |
|---|---|
| pass/fail | 观察 `TEST_STATUS_ADDR` |
| dmem 结果 | 仿真结束检查指定地址 |
| commit trace | 与预期文本比较 |

不必一开始写复杂 UVM。第一版 CPU 项目里，清晰的 directed test + commit trace 已经很有价值。

### 6.2 自写简单 reference model

选择实现，可暂时不用。

可以写一个很小的 Python 模型，只支持当前指令子集：

```text
读取 .mem 指令
维护 pc、gpr、dmem
每次执行一条指令
输出 commit trace
```

再和 RTL trace 比较：

```text
RTL trace:  cycle pc instr rd wdata
REF trace:        pc instr rd wdata
```

比较时通常忽略 cycle，因为流水线和单周期模型的 cycle 不同；重点比较提交顺序和架构结果。

### 6.3 使用 ISS

选择实现，可暂时不用。

后期可以接 Spike、Sail 或其他 RISC-V ISS。但第一版有两个注意点：

| 注意点 | 说明 |
|---|---|
| 支持范围 | ISS 默认完整架构，教学核可能不支持 CSR/trap |
| 环境约定 | `TEST_STATUS_ADDR`、链接脚本、memory map 要匹配 |

所以前期更实用的是先自写小参考模型或手写 expected trace。

## 第7章 回归脚本思路

### 7.1 单测试流程

每个测试大致流程：

```text
test.S
  ↓ gcc 生成 test.elf
  ↓ objdump 生成 test.dump
  ↓ objcopy + bin2mem32 生成 test.mem
  ↓ 运行 RTL 仿真 +imem=test.mem
  ↓ 检查 PASS/FAIL 和 trace
```

流水线 C 测试使用同一类组织方式，但会生成 `_imem.mem` 和 `_dmem.mem` 两个镜像；其中 IMEM 镜像包含 `.text.init/.text.trap/.text`，DMEM 镜像来自 `.dmem_image`。

命令细节见 `0826`。本篇只强调组织方式。

当前仓库的单测试脚本支持四位编号或完整 basename：

```bash
sim/pipeline5_asm/run_test.sh 0102
sim/pipeline5_asm/run_test.sh 0102_alu_imm
sim/pipeline5_c/run_test.sh 0401
```

`run_all.sh` 不扫描目录自动运行所有测试，而是维护阶段专属列表。这样基础 RV32I 回归、流水线 hazard 回归和后续 CSR/trap 回归可以有不同范围。

### 7.2 回归输出

建议回归输出简洁：

```text
[PASS] 0001_smoke
[PASS] 0102_alu_imm
[FAIL] 0302_pipeline5_fwd_noredirect
       see build/0302_pipeline5_fwd_noredirect/wave.vcd
       see build/0302_pipeline5_fwd_noredirect/commit.trace
```

失败时要保留：

- ELF。
- dump。
- mem。
- trace。
- wave。
- 仿真 log。

这样才能复现。

## 第8章 最小覆盖清单

### 8.1 ISA 功能

| 类别 | 至少覆盖 |
|---|---|
| U-type | `LUI`、`AUIPC` |
| I-type ALU | 每个 funct3，shift immediate 的两种 funct7 |
| R-type ALU | 每个 funct3/funct7 |
| load | `LB/LH/LW/LBU/LHU` |
| store | `SB/SH/SW` |
| branch | taken/not-taken，signed/unsigned |
| jump | `JAL/JALR`，`rd=x0` 和 `rd!=x0` |
| unsupported | 非法 opcode 或未支持系统指令，选择实现，可暂时不用 |

### 8.2 pipeline hazard

| 类别 | 至少覆盖 |
|---|---|
| EX/MEM forwarding | rs1、rs2 |
| MEM/WB forwarding | rs1、rs2 |
| 优先级 | 两个后级同时匹配 |
| load-use | rs1、rs2、store data |
| branch forwarding | branch 操作数来自前一条 |
| store data forwarding | store 数据来自前一条 |
| flush | wrong-path GPR write、wrong-path store |

### 8.3 基础断言

选择实现，可暂时不用。当前 v2.0 主要靠 directed test 自检和 commit trace；后续做更系统验证时再补断言和覆盖率。

可以在 testbench 或 RTL 中加：

```systemverilog
assert property (@(posedge clk) disable iff (!rst_n)
    !(commit_valid && commit_reg_we && (commit_rd == 5'd0)));
```

如果 RTL 内部能观察 GPR，也可以断言：

```systemverilog
assert property (@(posedge clk) disable iff (!rst_n)
    (u_core.u_regfile.gpr[0] == 32'b0));
```

断言要少而准，先盯不变量。

## 第9章 常见测试误区

| 误区 | 后果 |
|---|---|
| 只跑一个大程序 | 失败后不知道哪类功能错 |
| 只看最终 memory | 不知道第一条错误指令 |
| 不保存 objdump | 不知道工具链实际生成了什么指令 |
| 没有 timeout | 回归可能挂死 |
| pass/fail 地址和 dmem map 不一致 | 程序写了，但 testbench 看错地址 |
| 测试里用了未支持指令 | 误以为 CPU 错，其实编译产物超出范围 |
| 没测 wrong-path store | flush bug 可能长期隐藏 |

## 第10章 相关文档

| 文档 | 关系 |
|---|---|
| `0825 Hazard控制：forwarding、stall、flush与kill.md` | 本文测试清单的重要来源 |
| `0826 裸机程序、ROM与RAM加载与工具链使用示例.md` | 编译和加载测试程序 |
| `0828 波形debug、常见bug与定位清单.md` | 回归失败后的定位手册 |
| `0829 综合、FPGA上板与SoC扩展方向.md` | 后续将仿真测试扩展到综合/上板 |

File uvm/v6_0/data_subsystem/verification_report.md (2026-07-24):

# v6.0 Data Subsystem UVM Verification Report

本文记录 0835 收口时 `uvm/v6_0/data_subsystem` 的实际验证证据。验证要求和协议边界见 `spec.md`，仿真命令及脚本行为见 `dut/docs/uvm_simulation_flow.md`。

## 1. 基线

| 项目 | 值 |
|---|---|
| 报告日期 | 2026-07-24 |
| 主工程 RTL commit | `v7.0` |
| DUT 快照 | `dut/rtl`，与上述主工程 RTL 逐文件一致 |
| DUT | `data_subsystem + simple_ram + GPIO0/UART0/TIMER0` |
| 协议 | v6.0 single-outstanding simple request/response bus |
| 仿真器 | Synopsys VCS `W-2024.09-SP1_Full64` |
| UVM | VCS 自带 UVM 1.1d |
| UVM 固定 seed | `1` |

`sim/filelist.f` 已切换为只编译本工作区 `dut/rtl` 快照，不引用根目录主线 RTL。快照来源和文件映射见 `dut/readme.md`。

## 2. UVM 回归结果

下表来自收口时本地 `sim/logs/` 中 seed 1 的运行日志。`partial` 表示只检查了当前已定义的 error/data 子集，`skip` 表示 target-specific 功能模型尚未接入；两者不等于 mismatch，剩余边界见第 6 章。日志属于可重新生成的本地产物，本报告保存版本化结论。

| Test | Transaction | Simple bus scoreboard | Wrapper scoreboard | Data coverage | Behavior coverage | UVM error/fatal | 结果 |
|---|---:|---|---|---:|---:|---|---|
| `data_subsystem_base_test` | 0 | 0 correct / 0 error / 0 partial / 0 skip | 0 correct / 0 error | 0.00% | 0.00% | 0 / 0 | PASS |
| `simple_bus_smoke_test` | 4 | 2 correct / 0 error / 2 partial / 0 skip | 4 correct / 0 error | 60.00% | 27.86% | 0 / 0 | PASS |
| `data_subsystem_smoke_test` | 10 | 5 correct / 0 error / 5 partial / 0 skip | 10 correct / 0 error | 60.00% | 40.57% | 0 / 0 | PASS |
| `DS_dmem_random_test` | 2000 | 826 correct / 0 error / 1174 partial / 0 skip | 2000 correct / 0 error | 100.00% | 71.15% | 0 / 0 | PASS |
| `DS_map_random_test` | 2100 | 819 correct / 0 error / 703 partial / 578 skip | 2100 correct / 0 error | 96.67% | 100.00% | 0 / 0 | PASS |

`data_subsystem_base_test` 是结构性空场景，只证明 env 构建、连接和 phase 收尾正常，不提供功能 coverage。其余 test 均由 monitor 产生完整 transaction，并由 wrapper scoreboard 覆盖全部 transaction。

## 3. Coverage 结论

`DS_map_random_test` 在每个 delay 档位为 DMEM、GPIO0、UART0、TIMER0 配置相同 delay，并依次运行 `0/1/3/8/32/64/127` 七档，共完成 2100 笔 transaction。该固定 seed 命中当前 `bus_behavior_cg` 的全部 bins/crosses，behavior coverage 为 100.00%；成功 transaction 的 data 分布 coverage 为 96.67%。

该百分比只说明当前 covergroup 定义的 op、target、地址低位、BE 分类、idle gap、response delay、error 及相应 crosses 已被命中，不代表 UART0/TIMER0 reference model、全部 GPIO0 寄存器、外设 side effect 或 full CPU/SoC 已覆盖。

当前 VCS/URG 工具环境生成 HTML 报告时发生工具自身异常，因此 0835 使用 UVM `report_phase` 的 console coverage、checker 统计和固定 seed 日志作为归档证据。HTML coverage 不是本次收口的 PASS 条件。

## 4. RTL-001 前后对比

`DS_map_random_test 1` 在 RTL-001 修复前得到 `UVM_ERROR=52`：其中 48 条是 GPIO0 已定义 word offset 上的非零 byte address 被误判为 unknown offset，另有 4 条是被拒绝写入后产生的 OUT/OE readback mismatch。相同运行中 wrapper scoreboard 为 2100/2100 匹配，说明失败集中在 MMIO register decode，而不是 response-delay wrapper。

RTL 修复将 GPIO0、UART0、TIMER0 的寄存器 offset decode 统一改为 `{full_offset[11:2], 2'b00}`，保留原始 byte address 和 `be` 的 byte-lane 语义。修复后使用相同 test 和 seed，`UVM_ERROR=0`、`UVM_FATAL=0`，GPIO0 known/unknown word-offset 检查通过，wrapper scoreboard 仍为 2100/2100 匹配。

完整问题分析、定向测试未暴露原因和修复记录见根目录 `docs/known_issues.md` 的 RTL-001。

## 5. Directed Regression

RTL-001 修复后，现有 Verilator C 与 ASM self-check regression 已由项目维护者运行并通过。该结果证明修复未破坏现有 CPU/SoC 软件可见场景；UVM 与 directed regression 的验证职责仍保持并行。

本报告不把 C/ASM 日志复制进 UVM 工作区。对应 testcase、脚本和原始日志继续由根目录 Verilator 回归目录维护。

## 6. 剩余风险

- `simple_bus_scoreboard` 完整建模 DMEM，并只建模 GPIO0 OUT/OE；UART0/TIMER0 功能 transfer 当前计入 `skip_count`。
- GPIO0 其它已定义寄存器和 write response 只完成部分检查，计入 `partial_count`；没有 UVM error 不代表这些未建模结果已经验证。
- GPIO input、UART RX、外设输出事件和 IRQ 没有独立 sideband agent/checker。
- bus driver `planned_item_ap` 尚未接入 execution checker，planned/observed idle gap 未作为 PASS/FAIL 条件。
- 当前只归档 seed 1 的 closure 结果，没有定义多 seed coverage closure 或 CI 阈值。
- SVA 可通过 `ASSERT_ON=1` 启用并由脚本统计 `SIM_ERROR`，但本表不单列一次 assertion-enabled 全回归证据。
- VDB/URG HTML 报告受当前工具环境限制，未作为归档证据。

这些项目不阻塞 v7.0 教学型 UVM 基础设施收口；若继续扩展本工作区，应按 `spec.md` 第 16 章逐项增加明确 testcase、checker 和 coverage。

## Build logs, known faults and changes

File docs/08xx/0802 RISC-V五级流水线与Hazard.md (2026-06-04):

# 0802 RISC-V 五级流水线与 Hazard(冒险)

> 文档编号：0802  
> 所属部分：08 处理器架构、RISC-V(第五代精简指令集架构) 与 CPU(中央处理器) 微架构  
> 对应总纲小节：8.2 RISC-V 经典五级流水线、8.3 hazard  
> 主题定位：系统讲解经典 RISC-V 五级流水线的 IF(取指)、ID(译码)、EX(执行)、MEM(访存)、WB(写回) 分工，重点理解 structural hazard(结构冒险)、data hazard(数据冒险)、control hazard(控制冒险)、forwarding(前递/旁路)、stall(停顿)、bubble(气泡)、flush(冲刷) 与 load-use hazard(加载-使用冒险)。  
> 目标岗位：数字 IC(集成电路) 设计、数字 IC 验证、SoC(片上系统) 前端、FPGA(现场可编程门阵列)/ASIC(专用集成电路) RTL(寄存器传输级)、CPU 前端设计、处理器验证、嵌入式处理器相关岗位。  
> 前置知识：建议先阅读 `0801 RISC-V ISA基础.md`；需要理解 register file(寄存器堆)、ALU(算术逻辑单元)、PC(程序计数器)、基础 RV32I/RV64I(32 位/64 位基础整数指令集) 指令语义、组合逻辑和时序逻辑。

---

## 术语首次出现说明

本文档遵循“英文名词或缩写首次出现时给出中文名称”的规则。以下术语在后文会高频出现，后续再次出现时可直接使用英文或缩写。

| 英文术语 | 中文名称 | 英文术语 | 中文名称 | 英文术语 | 中文名称 |
|---|---|---|---|---|---|
| RISC-V | 第五代精简指令集架构 | Hazard | 冒险/相关冲突 | CPU | 中央处理器 |
| IC | 集成电路 | SoC | 片上系统 | FPGA | 现场可编程门阵列 |
| ASIC | 专用集成电路 | RTL | 寄存器传输级 | SystemVerilog | 系统 Verilog |
| ISA | 指令集架构 | RV32I/RV64I | 32 位/64 位基础整数指令集 | RISC | 精简指令集计算机 |
| IF/ID/EX/MEM/WB | 取指/译码/执行/访存/写回 | pipeline | 流水线 | stage | 流水级 |
| pipeline register | 流水线寄存器 | cycle | 时钟周期 | clock period | 时钟周期时间 |
| frequency | 频率 | Fmax | 最高工作频率 | CPI | 每条指令平均周期数 |
| IPC | 每周期执行指令数 | latency | 延迟 | throughput | 吞吐率 |
| critical path | 关键路径 | PPA | 性能、功耗、面积 | STA | 静态时序分析 |
| PC | 程序计数器 | instruction | 指令 | instruction memory | 指令存储器 |
| data memory | 数据存储器 | memory | 存储器/内存 | Harvard architecture | 哈佛结构 |
| von Neumann architecture | 冯诺依曼结构 | register file | 寄存器堆 | GPR | 通用寄存器 |
| x0 | 恒零寄存器 | ALU | 算术逻辑单元 | LSU | 加载存储单元 |
| CSR | 控制状态寄存器 | decoder | 译码器 | immediate generator | 立即数生成器 |
| branch comparator | 分支比较器 | control signal | 控制信号 | datapath | 数据通路 |
| valid bit | 有效位 | valid-ready | 有效-就绪握手 | backpressure | 反压 |
| stall | 停顿 | bubble | 气泡 | flush | 冲刷 |
| kill/squash | 杀除/压掉无效指令 | interlock | 流水线互锁 | replay | 重放 |
| forwarding | 前递/旁路 | bypass | 旁路 | MUX | 多路选择器 |
| structural hazard | 结构冒险 | data hazard | 数据冒险 | control hazard | 控制冒险 |
| RAW/WAR/WAW | 读后写/写后读/写后写相关 | load-use hazard | 加载-使用冒险 | branch hazard | 分支冒险 |
| branch prediction | 分支预测 | branch target | 分支目标地址 | branch resolution | 分支决策完成 |
| BTB | 分支目标缓冲器 | BHT | 分支历史表 | RAS | 返回地址栈 |
| PC redirect | 程序计数器重定向 | wrong-path instruction | 错误路径指令 | mispredict | 预测错误 |
| speculative work | 推测性工作 | side-effect gating | 副作用门控 | target PC | 目标程序计数器 |
| always not taken | 总是不跳转预测 | always taken | 总是跳转预测 | static prediction | 静态预测 |
| dynamic prediction | 动态预测 | write-first/read-first | 先写后读/先读后写寄存器堆语义 | single-port RAM | 单端口随机存储器 |
| dual-port RAM | 双端口随机存储器 | cache | 缓存 | instruction cache | 指令缓存 |
| data cache | 数据缓存 | load/store | 加载/存储 | store data forwarding | 存储数据前递 |
| writeback forwarding | 写回前递 | EX-to-EX forwarding | 执行级到执行级前递 | MEM-to-EX forwarding | 访存级到执行级前递 |
| comparator | 比较器 | priority | 优先级 | opcode | 操作码 |
| rd/rs1/rs2 | 目的/源 1/源 2 寄存器字段 | funct3/funct7 | 3 位/7 位功能码 | immediate | 立即数 |
| hazard detection | 冒险检测 | effective address | 有效地址 | write mask | 写掩码 |
| sign extension/zero extension | 符号扩展/零扩展 | source operand | 源操作数 | destination register | 目的寄存器 |
| branch taken | 分支成立 | branch not taken | 分支不成立 | next PC | 下一条程序计数器 |
| exception | 异常 | interrupt | 中断 | trap | 陷入 |
| precise exception | 精确异常 | commit/retire | 提交/退休 | illegal instruction | 非法指令异常 |
| reset | 复位 | setup/hold | 建立时间/保持时间 | clock gating | 时钟门控 |
| CDC | 跨时钟域 | SVA | SystemVerilog 断言 | UVM | 通用验证方法学 |
| directed test | 定向测试 | random test | 随机测试 | coverage | 覆盖率 |
| scoreboard | 记分板 | reference model | 参考模型 | ISS | 指令集模拟器 |
| DUT | 待测设计 | testbench | 测试平台 | waveform | 波形 |
| trace | 跟踪记录 | bug | 缺陷 | debug | 调试 |
| trade-off | 权衡 | one-hot | 独热编码 | FSM | 有限状态机 |
| parameter | 参数 | logic | SystemVerilog 四态逻辑类型 | always_ff/always_comb | 时序/组合过程块 |
| MDU | 乘除法单元 | cache miss | 缓存未命中 | bus | 总线 |
| data valid | 数据有效 | memory response | 存储响应 | byte enable | 字节使能 |
| byte lane | 字节通道 | store data | 存储写数据 | load value | 加载结果值 |
| ALU result | ALU 结果 | CSR read data | CSR 读取数据 | commit valid | 提交有效信号 |
| instruction address misaligned | 指令地址非对齐异常 | instruction access fault | 指令访问错误异常 | load/store address misaligned | 加载/存储地址非对齐异常 |
| access fault | 访问错误异常 | side effect | 副作用 | debug halt | 调试暂停 |
| trap vector | 陷入入口地址 | reset vector | 复位入口地址 | commit mismatch | 提交不匹配 |
| OS | 操作系统 | bare-metal | 裸机软件 | runtime | 运行时 |
| kernel | 内核 | driver | 驱动程序 | software stack | 软件栈 |
| MMIO | 内存映射输入输出 | memory map | 地址映射 | linker script | 链接脚本 |
| virtual memory | 虚拟内存 | page table | 页表 | page fault | 页故障 |
| RTOS | 实时操作系统 | Unix-like OS | 类 Unix 操作系统 | boot code | 启动代码 |
| FENCE | 存储屏障指令 | store buffer | 存储缓冲 | device memory | 设备内存 |
| ROM | 只读存储器 | SRAM | 静态随机存取存储器 | DRAM | 动态随机存取存储器 |
| flash | 闪存 | I-cache | 指令缓存 | D-cache | 数据缓存 |
| storage controller | 存储控制器 | block device | 块设备 | DMA | 直接存储器访问 |
| PC+4 adder | 程序计数器加 4 加法器 | branch target adder | 分支目标地址加法器 | memory controller | 存储器控制器 |
| JAL/JALR | 跳转并链接/寄存器间接跳转并链接 | link register | 链接寄存器 | unconditional jump | 无条件跳转 |
| M extension | 乘除法扩展 | unified memory | 统一存储器 | memory arbiter | 存储端口仲裁器 |
| privilege level | 特权级 | M/S/U mode | 机器/监管/用户模式 | ECALL | 环境调用指令 |
| MRET/SRET | 机器/监管陷入返回指令 | MMU | 内存管理单元 | TLB | 地址转换后备缓冲 |
| CLINT | 核局部中断控制器 | PLIC | 平台级中断控制器 | atomic instruction | 原子指令 |
| EPC | 异常程序计数器 | cause | 陷入原因 | tval | 陷入附加值 |

---

## 第0章 本专题学习地图

### 0.0 为什么五级流水线是 CPU 面试核心

RISC-V ISA 告诉我们每条指令“最终应该做什么”，五级流水线讨论的是“硬件如何让多条指令重叠执行，并仍然保持 ISA 可见行为正确”。

五级流水线之所以高频，是因为它把数字 IC 的很多基础能力集中在一起：

- 时序切分：如何把长组合路径切成多个 stage。
- 控制优先级：stall、flush、exception、interrupt 谁优先。
- 数据相关：后一条指令需要前一条结果时怎么办。
- 资源冲突：取指和访存是否抢同一个 memory。
- 分支控制：走错路径的指令如何清掉。
- 验证闭环：如何证明流水线内部乱动后，commit 的架构状态仍符合 ISA。

很多候选人会背“五级是 IF、ID、EX、MEM、WB”，但面试官真正想看的是：

```text
你能不能画出相邻指令在不同周期的位置；
能不能说明哪一拍数据可用；
能不能解释 forwarding 为什么有时够、有时不够；
能不能写出 load-use hazard 的检测条件；
能不能说明 branch flush 和 stall 同时发生时怎么定优先级。
```

### 0.1 小节划分与关系

本篇按以下顺序展开：

1. 第1章讲为什么需要 pipeline，以及 latency、throughput、CPI、Fmax 的关系。
2. 第2章讲经典 RISC-V 五级流水线每一级做什么。
3. 第3章讲 pipeline register、valid bit、stall、bubble、flush 的通用控制模型。
4. 第4章总览三类 hazard。
5. 第5章深入 data hazard，重点是 RAW 与 forwarding。
6. 第6章深入 load-use hazard，解释为什么 forwarding 仍然不够。
7. 第7章讲 structural hazard，包括单端口 memory、register file 端口、计算资源复用和多周期执行单元。
8. 第8章讲 control hazard，包括分支决策位置、flush、静态预测和简单动态预测。
9. 第9章讲异常、中断与流水线精确提交的基础。
10. 第10章集中概述系统 OS、裸机运行时和 CPU 流水线的关系，并说明后续 `0803-0805` 会分别展开哪些软件视角。
11. 第11章给出 RTL 控制骨架。
12. 第12章讲验证、断言、coverage 和 reference model。
13. 第13章整理常见 bug、面试问法和练习题。
14. 第14章讲与其他章节的关联。
15. 第15章做本篇总结。

### 0.2 与其他文档的关系

- `0801 RISC-V ISA基础.md` 是本篇前置，所有流水线控制都必须服务于 ISA 语义。
- `030x` 流水线和握手类文档可支撑通用 pipeline 控制。
- `040x` 运算单元文档可支撑 EX 阶段 ALU、乘除法、多周期执行单元。
- `060x` 存储器和 cache 文档可支撑 MEM 阶段和 cache miss。
- `0803 CSR、异常中断与特权级.md` 应继续展开 trap、CSR 和 precise exception。
- `100x` 验证文档可支撑指令随机验证、scoreboard、SVA 和 coverage。
- `130x` STA 文档可支撑 pipeline stage 切分、critical path 和 Fmax 分析。

---

## 第1章 为什么需要流水线

### 1.0 本章概述

流水线的核心目标是提高 throughput，而不一定降低单条指令 latency。它通过在不同 stage 同时处理不同指令，让硬件资源在每个 cycle 尽量忙起来。

### 1.1 单周期、多周期和流水线

假设一条指令需要完成：

```text
取指 -> 译码/读寄存器 -> 执行 -> 访存 -> 写回
```

有三种典型实现：

| 实现 | 特点 | 优点 | 缺点 |
|---|---|---|---|
| 单周期 CPU | 一条指令一个长 cycle 完成所有工作 | 控制简单 | clock period 被最慢指令决定，Fmax 低 |
| 多周期 CPU | 一条指令分多个 cycle 完成，不同指令不重叠 | 复用硬件，面积小 | CPI 高，throughput 低 |
| pipeline CPU | 多条指令重叠执行 | throughput 高，Fmax 可提高 | 控制复杂，有 hazard |

单周期核的关键路径可能是：

```text
PC寄存器 -> instruction memory -> decode -> register file -> ALU -> data memory -> writeback MUX -> register file
```

这个路径太长。五级流水线用 pipeline register 把它切成：

```text
IF | ID | EX | MEM | WB
```

每一级只做一部分工作。

从时序角度看，流水线的收益来自把一个长组合路径拆成若干较短路径。拆分后时钟周期不再由整条指令路径决定，而由最慢的流水级决定：

$$
T_{clk} \ge \max_i(T_{stage,i}) + T_{reg} + T_{skew} + T_{margin}
$$

其中 $T_{stage,i}$ 是第 $i$ 个 stage 的组合延迟，$T_{reg}$ 是 pipeline register 的 clk-to-q、setup 等寄存器开销，$T_{skew}$ 是时钟偏斜，$T_{margin}$ 是工程余量。面试中要注意：pipeline 不是免费加速，切得越细，寄存器开销、flush penalty、控制复杂度和功耗都会增加。

### 1.2 latency 和 throughput

不要把 latency 和 throughput 混淆。

| 概念 | 含义 | 五级流水线中的表现 |
|---|---|---|
| latency | 一条指令从进入到完成经历多久 | 理想情况下约 5 个 cycle |
| throughput | 单位时间完成多少指令 | 理想情况下每 cycle 完成 1 条 |
| CPI | 平均每条指令消耗多少 cycle | 理想流水线接近 1 |
| IPC | 每 cycle 完成多少条指令 | 单发射理想情况下接近 1 |

流水线主要提升 throughput。单条指令从 IF 到 WB 仍然需要多个 cycle。

对理想单发射五级流水线：

$$
\begin{aligned}
latency_{inst} &\approx 5 \times T_{clk} \\
throughput_{ideal} &\approx \frac{1}{T_{clk}} \\
CPI_{ideal} &\approx 1 \\
IPC_{ideal} &\approx 1
\end{aligned}
$$

这和 `0405` 中 MAC pipeline 的 II 思想类似：单个操作的 latency 可能变长，但只要每拍能接收一条新指令，填满后吞吐就高。CPU pipeline 的难点在于指令之间有数据相关、控制流和共享资源，所以真实 II 经常被 stall 和 flush 打断。

### 1.3 理想五级流水线时序

假设没有 hazard，连续指令 `I1` 到 `I5` 的执行可表示为：

```text
cycle:  1   2   3   4   5   6   7   8   9
I1:     IF  ID  EX  MEM WB
I2:         IF  ID  EX  MEM WB
I3:             IF  ID  EX  MEM WB
I4:                 IF  ID  EX  MEM WB
I5:                     IF  ID  EX  MEM WB
```

填满 pipeline 后，每个 cycle 都有一条指令进入 WB。

这张图是理解 throughput 的理想模型：IF 每拍都按顺序 PC 取一条指令，`I1` 这拍在 IF，下一拍进 ID，同时 `I2` 进入 IF。它默认了一个非常强的前提：下一拍要取的 PC 已经确定，而且前面进入流水线的指令都不会改变控制流。

真实 CPU 里这个前提经常不成立。`BEQ`、`BNE`、`JAL`、`JALR`、exception、interrupt 都可能改变 PC。问题在于：IF 为了保持吞吐，不能总是等到所有老指令都完全执行完再取下一条；它通常会先按某种策略取一个“猜测的下一条”。

最简单策略是 always not taken：默认下一条是 `pc + 4`。若一条 `BEQ` 到 EX 阶段才算出 taken 和 branch target，那么在它到 EX 之前，后面的顺序指令已经进入 IF/ID，甚至 ID/EX：

```text
cycle:       1   2   3   4   5
BEQ I0:      IF  ID  EX  MEM WB
I1=pc+4:         IF  ID  EX
I2=pc+8:             IF  ID
target T:                 IF  ID  EX ...
```

如果 `BEQ` 在 cycle 3 的 EX 阶段发现 taken，那么 `I1` 和 `I2` 不是 ISA 语义上应该执行的指令，它们只是为了保持前端不断流而提前取入的 wrong-path instruction(错误路径指令)。正确处理不是让它们继续产生结果，而是在 branch resolution(分支决策完成) 的那一拍做三件事：

1. 产生 PC redirect(程序计数器重定向)，把 PC 改成 branch target。
2. flush 或 kill 比该 branch 更年轻的 wrong-path instruction，例如 IF/ID、ID/EX 中的 `I1`、`I2`。
3. 用 valid/kill 门控所有副作用，保证被 flush 的指令不能写 GPR、写 memory、写 CSR，也不能作为 commit 指令被 scoreboard 看见。

时序上可以理解成：

```text
cycle:       1    2    3             4    5    6
BEQ I0:      IF   ID   EX(taken)     MEM  WB
I1=pc+4:          IF   ID(killed)    --   --
I2=pc+8:               IF(killed)    --   --
target T:                              IF   ID   EX
```

所以“下一条指令已经 IF 了”并不等于“下一条指令已经被 ISA 接受执行了”。在流水线 CPU 中，IF/ID/EX 里的年轻指令有时只是 speculative work(推测性工作)。只有当一条指令有效、没有被 kill，并走到设计定义的 commit/retire 边界，它的寄存器写回、内存写、CSR 更新等副作用才算真正改变架构状态。

这点和 `0405` 中流水 MAC 的反馈问题有相似之处：一旦后级结果会反过来影响前级输入选择，控制逻辑就必须定义“旧路径上已经进入流水线的数据怎么办”。区别是 MAC 数据通路通常处理的是数值反馈和 valid 对齐，而 CPU 控制流处理的是 PC 反馈和错路径副作用取消。CPU 不能只把 target PC 接回 IF，还必须同时 flush 已经按旧 PC 取入的年轻指令。

一个常见面试级回答可以这样说：

```text
五级流水线不是等 branch 完成后才继续取指，而是先按 pc+4 或预测方向取指。
如果后级发现真实 next PC 与前面取指假设不同，就 redirect PC，并 flush younger wrong-path instructions。
所有架构副作用必须由 valid 且未被 kill 的指令产生，因此错路径指令可以进过前几级，但不能 commit。
```

后文第8章会专门展开 control hazard、branch penalty、提前分支决策和 branch prediction。本节先建立关键直觉：理想流水线图说明吞吐，真实流水线还必须有 redirect、flush 和 side-effect gating 才能保持 ISA 正确。

### 1.4 理想 CPI 和实际 CPI

实际 CPI 可粗略理解为：

$$
CPI = 1 + penalty_{stall} + penalty_{branch} + penalty_{memory} + penalty_{exception}
$$

五级流水线性能优化常围绕：

- 减少 data hazard stall。
- 提前 branch resolution。
- 提高 branch prediction 准确率。
- 降低 memory miss 代价。
- 平衡各 stage critical path。

更具体地说，性能不是只看 CPI，也不是只看 Fmax，而是看单位时间提交多少指令。对单发射顺序核可以粗略写成：

$$
Perf \propto \frac{IPC}{T_{clk}} = \frac{1}{CPI \times T_{clk}}
$$

所以一个优化是否值得，要同时看两边：提前 branch resolution 可能降低 $penalty_{branch}$，但如果把比较器、target adder 和 forwarding 都塞进 ID，导致 $T_{clk}$ 变大，最终性能未必提升。这个 trade-off 是五级流水线面试中最常见的深入追问。

### 1.5 三类 Hazard 的先导认识

前面已经看到，理想五级流水线默认每拍都能让一条新指令进入 IF，并让流水线中所有指令自然前进一级。hazard 可以先粗略理解成：**如果还按这个理想节奏推进，结果就可能出错或资源就不够用**。

这里先只建立直觉，不展开检测条件和 RTL 控制。后面第4章会做总览，第5到第8章再分别深入。

| Hazard 类别 | 中文直觉 | 破坏了理想流水线的哪个假设 | 一个最小例子 | 典型处理动作 | 后文位置 |
|---|---|---|---|---|---|
| structural hazard | 硬件资源冲突 | 默认不同 stage 可以同时使用自己需要的硬件 | IF 要取指，同时 MEM 要访存，但只有一个 single-port RAM | 增加资源、仲裁、stall | 第7章 |
| data hazard | 前后指令有数据依赖 | 默认后一条指令读寄存器时，前一条结果已经可用 | `ADD x3, x1, x2` 后紧跟 `SUB x4, x3, x5`，`SUB` 需要新的 `x3` | forwarding、stall、bubble | 第5章、第6章 |
| control hazard | 下一条 PC 不确定 | 默认 IF 每拍取的 `pc + 4` 就是正确路径 | `BEQ` 到 EX 才知道 taken，但后面的顺序指令已经被取入 | predict、redirect、flush/kill | 第8章 |

这三类问题的共同点是：它们都不是 ISA 语义本身，而是“重叠执行”带来的微架构问题。单周期 CPU 通常不会暴露这些流水线 hazard，因为一条指令做完才开始下一条；五级流水线为了提高 throughput，让多条指令同时处在不同 stage，于是必须额外处理资源、数据和 PC 流向之间的冲突。

从控制动作上也可以先有一个分工印象：`stall` (阻塞)多用于“还不能前进，但这条路径仍然是对的”；`flush/kill` 多用于“已经取进来的某些年轻指令不该继续产生副作用”；`forwarding`  (旁路转发)则是“结果还没写回 register file，但可以从后级直接送到前级使用”。这些动作的精确定义会在第3章展开。

---

## 第2章 RISC-V 五级流水线分工

### 2.0 本章概述

经典五级流水线把指令执行分成 IF、ID、EX、MEM、WB。每一级边界不是唯一标准，但下面的划分最常见，也最适合面试讨论。

### 2.1 IF：取指

IF 主要做：

- 使用当前 PC 访问 instruction memory 或 instruction cache。
- 取出 instruction。
- 计算默认 next PC，通常是 `pc + 4`。
- 根据分支预测或重定向选择下一拍 PC。
- 把 `pc`、`inst`、预测信息写入 IF/ID pipeline register。

简化结构：

```text
          +---------+
next_pc ->| PC reg  |---- pc ----+
          +---------+            |
                ^                v
                |        +---------------+
                +--------| next PC MUX   |
                         +---------------+
                                 ^
                                 |
      branch/jump/trap redirect -+
```

### 2.2 ID：译码和读寄存器

ID 可以理解为“把一条 instruction 变成后级能执行的控制包和数据包”。IF 只负责把 `pc` 和 `inst` 取进来；到了 ID，硬件才真正开始回答：这是什么指令、要读哪些寄存器、要不要写回、是否访问 memory、后面能不能继续流动。

| ID 做的事情 | 通常怎么做 | 作用 | 需要注意的点 |
|---|---|---|---|
| 字段解析 | 从 `inst` 中切出 opcode、rd、rs1、rs2、funct3、funct7 | 给 decoder、register file、hazard detection 提供基础输入 | 不同 type 对同一 bit 段的含义不同，例如 I-type 没有 rs2 |
| 主译码 | 用 opcode/funct3/funct7 查 decode table 或进入 `case` 译码 | 生成 `alu_op`、`operand_sel`、`mem_read`、`mem_write`、`wb_sel`、`reg_we`、`branch/jump` 等 control signal | control signal 必须和这条指令一起写入 ID/EX，不能后级重新猜 |
| 读 register file | 用 rs1、rs2 作为读地址读出源操作数，`x0` 读出全 0 | 为 EX 的 ALU、branch comparator、load/store 地址计算准备操作数 | 读出的值不一定就是最终值，后面可能被 forwarding 覆盖 |
| 生成 immediate | immediate generator 按 I/S/B/U/J type 拼接并符号扩展 | 为 ALU 立即数、load/store offset、branch/JAL target 提供操作数 | B/J type 的低位隐含 0，JALR 是 `rs1 + imm_I` 后清 bit 0 |
| 冒险检测 | 比较当前指令源寄存器和流水线中更老指令的目的寄存器，并结合结果是否已经可用 | 决定本拍能不能让 ID 指令进入 EX，或是否需要 stall/bubble | 要区分“可以靠 forwarding 解决”和“必须 stall”等情况 |
| 可选的早期分支判断 | 简单核可把 branch comparator 和 target adder 放在 ID | 提前知道 branch 方向，减少 flush 代价 | 会拉长 ID 关键路径，并让 branch operand forwarding 更复杂 |
| 写入 ID/EX | 把 `pc`、寄存器读值、immediate、rd/rs1/rs2、control signal、valid bit 写入 ID/EX pipeline register | 让下一拍 EX 能处理同一条指令的数据和控制 | stall/flush 时必须按统一控制更新 valid 和控制信号 |

其中 hazard detection 最容易让初学者困惑。它不是“看到寄存器编号相同就停”，而是要判断当前 ID 指令真正需要的源操作数，在下一拍进入 EX 时能不能拿到正确值。

| 检测场景 | 典型判断 | 常见动作 | 为什么 |
|---|---|---|---|
| 当前指令不使用某个源寄存器 | 例如 I-type 算术只使用 rs1，不使用 rs2 | 不因为 `inst[24:20]` 碰巧相等而 stall | 指令格式里的 bit 段不一定都是有效源寄存器 |
| 源寄存器是 `x0` | `rs1 == 0` 或 `rs2 == 0` | 通常不需要 forwarding 或 stall | `x0` 永远读 0，写 `x0` 也不会改变架构状态 |
| 前一条 ALU 指令写当前源寄存器 | ID 源寄存器等于 ID/EX 或 EX/MEM 中老指令的 rd，且老指令会写 GPR | 多数五级流水线允许继续前进，后续在 EX 用 forwarding MUX 选新值 | ALU 结果通常在 EX 末尾已经产生，下一拍可从后级旁路给消费者 |
| 前一条 load 写当前源寄存器 | ID/EX 是 load，rd 等于当前指令实际使用的 rs1/rs2 | 典型处理是 PC 和 IF/ID stall 一拍，同时 ID/EX 插入 bubble | load 数据通常要到 MEM 末尾才回来，下一拍 EX 还拿不到 |
| branch/JALR 的源操作数依赖老指令 | 分支比较或 JALR target 需要的 rs1/rs2 尚未可用 | 根据 branch 在 ID 还是 EX 决策，选择 forwarding 或 stall | 控制流目标不能用旧操作数，否则会跳到错误 PC |
| 后级资源不能接收新指令 | 例如 MEM 因 cache miss 反压，或多周期执行单元 busy | 保持相关 pipeline register，不让 ID 覆盖还没前进的指令 | 防止丢指令、重复执行或控制信号和数据错位 |

ID 阶段的关键风险是组合逻辑容易变长：decode、register file 读、immediate 生成、hazard detection、甚至早期 branch 比较都可能挤在同一拍里。真实项目里常把“功能正确”和“时序可收敛”一起考虑，不是把所有能提前做的事都无条件塞进 ID。

### 2.3 EX：执行和地址计算

EX 主要做：

- ALU 运算。
- branch comparator 或 branch target 计算。
- JAL/JALR target 计算。
- load/store 地址计算。
- forwarding MUX 选择真实操作数。
- 对多周期乘除法，可能启动 M extension 执行单元。

EX 是五级流水线中 data hazard 最集中的 stage，因为多数消费者指令在 EX 需要源操作数。

这里有两个容易忽略的点。第一，EX 使用的操作数通常不是直接来自 ID 读出的 register file 值，而是先经过 forwarding MUX；否则前一两条指令刚算出的结果还没写回，消费者就会读到旧值。第二，branch、JALR、load/store 也都依赖 EX 操作数：branch comparator 要比较真实 rs1/rs2，JALR 要用真实 rs1 算 target，store 既要用 rs1 算地址，也可能需要对 rs2 的 store data 做 forwarding。

### 2.4 MEM：访存

MEM 是 load/store 真正接触数据存储系统的阶段。对不访存的 ALU/JAL/JALR 指令，MEM 通常只是把 EX/MEM pipeline register 中的结果继续传给 MEM/WB；对 load/store，MEM 是 LSU、cache、总线和异常信息交汇的地方。

| MEM 做的事情 | 通常怎么做 | 作用 | 需要注意的点 |
|---|---|---|---|
| 接收 EX 的访存信息 | 从 EX/MEM 取得 effective address、store data、访问大小、load/store 控制、rd、valid bit | 确保访存请求和原指令绑定 | 地址、数据、控制信号必须来自同一条有效指令 |
| 对齐与异常检查 | 根据访问大小检查地址低位，并接收 cache/bus 返回的 access fault | 决定本次 load/store 是否可以正常完成，或是否要进入 trap | misaligned/access fault 不能被后续普通写回覆盖 |
| load 读数据 | 向 data memory/data cache 发出读请求，等待 memory response | 取得原始读数据，供 WB 写回 GPR | 若 cache miss 或总线等待，需要让 pipeline stall 或 backpressure |
| store 写数据 | 根据地址低位、访问大小生成 byte enable/write mask，并把 store data 放到正确 byte lane | 只改写目标 byte/halfword/word，完成 memory 或 MMIO 写副作用 | store 是外部副作用，必须受 valid/kill 门控，不能被 flush 后仍然发出 |
| load 数据整理 | 从返回的数据中选出目标 byte/halfword/word，并按 LB/LBU/LH/LHU/LW 做 sign extension 或 zero extension | 形成最终要写回 rd 的 load value | signed/unsigned load 的区别在这里体现，错了会像 ALU 比较错误 |
| memory stall 控制 | 当 data cache miss、总线未 ready 或外设未响应时，保持 MEM 及其前级状态 | 防止前级覆盖尚未完成的访存指令 | 可变延迟 memory 会把简单五级流水线推向 valid-ready/backpressure 控制 |

如果没有 data cache，而 instruction memory 和 data memory 是同一个单端口 RAM，则 IF 和 MEM 可能出现 structural hazard。

### 2.5 WB：写回

WB 是很多简单顺序五级流水线的寄存器写回和 commit/retire 边界。它的工作看起来比 ID/EX/MEM 简单，但它直接决定软件可见的 GPR 状态，因此 valid、kill、rd 和写使能的门控不能含糊。

| WB 做的事情 | 通常怎么做 | 作用 | 需要注意的点 |
|---|---|---|---|
| 选择写回数据 | 根据 `wb_sel` 从 ALU result、load value、`pc + 4`、CSR read data 中选一路 | 把不同指令类型统一成“写 rd 的值” | `wb_sel` 必须跟随同一条指令从 ID 一路传到 WB |
| 写 register file | 当 `wb_valid && !wb_kill && reg_we && rd != x0` 时写 rd | 更新 GPR，这是最常见的 ISA 可见状态更新 | `rd == x0` 必须抑制写入；被 flush 的指令不能写回 |
| 产生 commit/retire 信息 | 输出 commit valid、pc、inst、rd、写回值、异常信息等 | 供 trace、scoreboard、debug 和性能计数使用 | commit 口看到的必须是有效且未被 kill 的指令 |
| 配合寄存器堆时序 | 设计可能规定同拍 WB 写、ID 读时是 write-first 或 read-first | 影响是否需要额外 writeback forwarding | 这个语义要在 RTL 和验证环境中统一 |
| 处理不写 rd 的指令 | store、branch、部分 system 指令即使到 WB，也可能 `reg_we = 0` | 保持流水线统一推进，同时不改变 GPR | store 的 memory 副作用通常已在 MEM 发生，不能误以为所有副作用都在 WB |

因此，“WB commit”是一个简化但很有用的模型：对大多数写 GPR 的普通指令，WB 是结果变成架构状态的位置；但对 store、trap、CSR 这类有特殊副作用的指令，设计还要明确副作用发生在哪一级，以及它们如何被 valid/kill 和异常优先级约束。

### 2.6 五级流水线寄存器

这里的“寄存器”容易和 `0801` 第 3.4 节的 ABI 寄存器别名混在一起。`IF/ID`、`ID/EX`、`EX/MEM`、`MEM/WB` 不是 `x0-x31`，也不是 `ra/sp/a0` 这类软件能在汇编里直接读写的寄存器；它们是 CPU 内部相邻 stage 之间的时序暂存。

可以把 pipeline register 理解成“每条指令随身带着的一张草稿纸”：上一拍某一级得到的中间信息，在时钟沿被记下来，下一拍交给后一级继续使用。普通组合中间信号只在当前 cycle 内传播，而 pipeline register 会把这些信息跨 cycle 保存下来。

| 对象 | 软件是否可见 | 例子 | 主要作用 |
|---|---|---|---|
| GPR/ABI 寄存器 | 可见 | `x10/a0`、`x1/ra`、`x2/sp` | 指令语义真正读写的架构寄存器，属于 ISA 可见状态 |
| pipeline register | 不可见 | `IF/ID.inst`、`ID/EX.rs1_value`、`EX/MEM.alu_result`、`MEM/WB.rd` | 保存某条指令在流水线中间阶段携带的数据、控制信号和 valid bit |

`IF/ID` 这种名字表示“位于 IF stage 和 ID stage 之间的 pipeline register”。更具体地说，当前 cycle 在 IF 阶段取到的 `PC`、`instruction` 等中间信息，会在时钟沿写入 `IF/ID`；下一 cycle，ID 阶段再从 `IF/ID` 里读取这些信息继续译码。因此，`IF/ID` 不是 IF 里一个寄存器加 ID 里一个寄存器，而是 IF 输出到 ID 输入之间的一组时序暂存寄存器。

同理，`ID/EX` 保存 ID 交给 EX 的信息，`EX/MEM` 保存 EX 交给 MEM 的信息，`MEM/WB` 保存 MEM 交给 WB 的信息。斜杠前后两个名字描述的是它所在的 stage 边界。
因此，`ID/EX.rd = x10` 的意思不是硬件里又多了一个 ABI 寄存器，而是“当前进入 EX 的这条指令，将来如果有效提交，需要把结果写回 `x10`”。同理，`ID/EX.rs1_value` 是 ID 阶段从 register file 读出的源操作数值的暂存副本，不等于 `x11` 这个寄存器本身。

典型 pipeline register：

| 寄存器 | 保存内容 |
|---|---|
| IF/ID | PC、instruction、预测信息、valid bit |
| ID/EX | PC、rs1/rs2 值、rd/rs1/rs2 编号、immediate、控制信号、valid bit |
| EX/MEM | ALU 结果、store 数据、rd、memory 控制、写回控制、valid bit |
| MEM/WB | load 数据、ALU 结果、rd、写回控制、valid bit |

关键思想：

```text
指令往后流动，控制信号也必须跟着同一条指令往后流动。
```

如果控制信号没有和数据对齐，就会出现“上一条指令的数据配上下一条指令的写使能”这类严重 bug。

---

## 第3章 流水线控制基础：valid、stall、bubble、flush

### 3.0 本章概述

五级流水线不是每拍都简单整体前进。遇到 hazard，需要让某些 stage 停住、插入 bubble 或清掉错误路径指令。清楚区分这些动作，是写对控制逻辑的基础。

### 3.1 valid bit

valid bit 表示 pipeline register 中是否有一条有效指令。

为什么需要 valid bit：

- reset 后 pipeline 为空。
- flush 后某些 stage 应变为空。
- stall 时某些 stage 保持原指令。
- exception 或 branch 可能 kill younger instruction。

没有 valid bit 的设计容易把空槽当成真实指令写寄存器或访问 memory。

### 3.2 stall

stall 表示某一级或某段 pipeline 暂停前进，pipeline register 保持原值。

典型原因：

- load-use hazard。
- data cache miss。
- instruction memory 未 ready。
- 多周期乘除法未完成。
- 下游总线 backpressure。

stall 的本质是：

```text
当前 stage 不能接收新输入，前面的 stage 也不能覆盖它保存的旧指令。
```

### 3.3 bubble

bubble 是插入一条“无效指令”或空槽。它向后流动，但不会改变架构状态。

load-use hazard 的典型处理：

- IF/ID 保持不动。
- ID/EX 写入 bubble。
- EX/MEM、MEM/WB 正常前进。

这样消费者指令延后一拍进入 EX，load 数据有机会从 MEM/WB forwarding 到 EX。

### 3.4 flush

flush 表示清掉错误路径或不该继续执行的指令。

典型原因：

- branch prediction 错误。
- JAL/JALR 在 EX 才确认目标。
- exception/trap 发生。
- interrupt 被接收。

flush 和 bubble 的区别：

| 动作 | 目的 | 来源 |
|---|---|---|
| bubble | 为等待数据或资源主动插入空槽 | hazard stall |
| flush | 清除已经进入 pipeline 的错误指令 | 控制流改变或异常 |

### 3.5 valid bit 是流水线安全边界

valid bit 不只是“这个 stage 里有没有指令”的标志，而是副作用是否允许发生的安全边界。流水线中很多信号即使在 bubble 或 flush 后仍然会有某个编码值：`rd` 可能不是 0，`mem_we` 可能因为旧控制信号还保持为 1，`wb_data` 也可能是上一拍的结果。如果没有 valid 统一门控，这些残留值就可能错误写寄存器或 memory。

工程上可以把每一级动作分成三类：

| 动作 | 例子 | 是否必须受 valid/kill 门控 |
|---|---|---|
| 纯组合计算 | ALU 输出、branch compare、next PC 候选 | 可以计算，但不能直接产生架构副作用 |
| pipeline 状态更新 | IF/ID、ID/EX、EX/MEM、MEM/WB 写入 | 必须按 stall/flush 规则更新 valid |
| 架构或外部副作用 | GPR 写回、data memory 写、CSR 更新、trap 接受 | 必须由 valid 且未 kill 的指令触发 |

典型原则是：

$$
side\_effect\_en = stage\_valid \land \lnot stage\_kill \land op\_en
$$

这条公式在 RTL 中会落成类似：

```systemverilog
assign rf_we_o   = wb_valid_q  && !wb_kill_q  && wb_reg_we_q && (wb_rd_q != 5'd0);
assign dmem_we_o = mem_valid_q && !mem_kill_q && mem_mem_we_q;
```

面试回答 stall/flush 时，如果只说“清一下流水线寄存器”还不够。更完整的回答要说明：flush 后 wrong-path instruction 即使控制信号残留，也不能 commit；exception redirect 后 younger instruction 不能写 GPR、写 memory 或更新 CSR。

### 3.6 stall 与 flush 的优先级

常见原则：

```text
更年轻的错误路径指令必须被 flush；
持有正确老指令的 stage 不能被错误覆盖；
exception/trap redirect 通常优先级高于普通 branch redirect；
reset 优先级最高。
```

一种常见优先级：

```text
reset > exception/trap flush > branch/jump flush > load-use stall > normal advance
```

但实际设计要结合 stage 位置决定。例如 EX 阶段 branch flush 和 ID 阶段 load-use stall 同时出现时，通常要优先处理 branch redirect，并 kill 错路径 younger instruction。

### 3.7 pipeline register 更新模型

一个带 valid/stall/flush 的 pipeline register 可抽象为：

```systemverilog
always_ff @(posedge clk or negedge rst_n) begin
  if (!rst_n) begin
    id_ex_valid_q <= 1'b0;
    id_ex_q       <= '0;
  end else if (flush_id_ex) begin
    id_ex_valid_q <= 1'b0;
    id_ex_q       <= '0;
  end else if (stall_id_ex) begin
    id_ex_valid_q <= id_ex_valid_q;
    id_ex_q       <= id_ex_q;
  end else begin
    id_ex_valid_q <= if_id_valid_q;
    id_ex_q       <= id_ex_d;
  end
end
```

真实设计中如果 `stall_id_ex` 为真，通常没有必要写自赋值；这里写出来是为了说明行为。

---

## 第4章 Hazard 总览

### 4.0 本章概述

hazard 是 pipeline 中“下一拍按理想方式推进会出错”的情况。经典分类为 structural、data、control。

### 4.1 structural hazard (结构冒险)

structural hazard 来自硬件资源冲突。

例子：

- IF 和 MEM 同时访问同一个 single-port RAM。
- register file 读写端口数量不足。
- ALU 被普通指令和地址计算同时需要。
- 乘除法单元正在忙，下一条 M extension 指令无法进入。

解决方法：

- 增加资源，例如分离 instruction memory 和 data memory。
- 增加端口，例如 2 读 1 写 register file。
- 仲裁和 stall。
- pipeline 化共享资源。

### 4.2 data hazard (数据冒险)

data hazard 来自指令之间的数据依赖。

最重要的是 RAW：

```text
I1: ADD x3, x1, x2
I2: SUB x4, x3, x5
```

I2 读 x3，I1 写 x3。如果 I2 在 I1 写回前就读取旧 x3，就会错。

data hazard 里最常见的是“前一条指令产生结果，后一条指令马上使用结果”。但不同 producer 的结果产生时间不同，所以处理方式也不同：

| 典型相关 | 示例 | 为什么会有 hazard | 总览层面的处理 |
|---|---|---|---|
| ALU-ALU 相关 | `ADD x3, x1, x2` 后接 `SUB x4, x3, x5` | `ADD` 的 ALU 结果在 EX 末尾已经产生，但还没写回 register file | 通常用 forwarding 从后级直接送到下一条指令的 EX 输入 |
| Load-Use 相关 | `LW x3, 0(x1)` 后接 `ADD x4, x3, x5` | load 的数据要等 MEM 访存后才返回，紧邻指令到 EX 时数据通常还没准备好 | forwarding 还不够，通常要 stall 一拍并插入 bubble |

因此，Load-Use Hazard 不是独立于 data hazard 的第四类 hazard，而是 RAW data hazard 中最典型、也最容易考察的特殊情况。第5章先讲数据已经产生时如何 forwarding；第6章再专门讲 load 数据尚未产生时为什么必须 interlock。

解决方法：

- forwarding/bypass。
- stall 插入 bubble。
- 编译器插入独立指令。
- 乱序核用 register renaming 和调度解决更多相关。

### 4.3 control hazard (控制冒险)

control hazard 来自下一条 PC 不确定。

例子：

```text
BEQ x1, x2, target
```

在 branch 条件计算完成前，IF 不知道下一条应取：

- 顺序地址 `pc + 4`。
- branch target。

解决方法：

- stall 等待 branch resolution。
- 默认预测 not taken。
- branch prediction。
- 提前在 ID 阶段比较。
- flush 错路径指令。

### 4.4 hazard 与 ISA 的关系

hazard 是微架构问题，不是 ISA 语义本身。

ISA 只要求：

```text
程序按指令语义执行，最终架构状态正确。
```

pipeline 必须通过 stall、forwarding、flush 等机制，让重叠执行不改变这个结果。

---

## 第5章 Data Hazard 与 Forwarding (旁路转发)

### 5.0 本章概述

简单顺序五级流水线中，最常见 data hazard 是 RAW (Read After Write)。WAR 和 WAW 在严格按序读寄存器、按序写回的五级流水线中通常不会发生，但在乱序或多写回端口设计中会出现。

### 5.1 RAW、WAR、WAW

| 类型 | 含义 | 简单五级顺序流水线是否常见 |
|---|---|---|
| RAW | 后一条读前一条将要写的数据 | 常见，必须处理 |
| WAR | 后一条写前一条还没读的数据 | 通常不出现，因为读在 ID，写在 WB，顺序流动 |
| WAW | 后一条写前一条还没写的数据 | 通常不出现，因为写回顺序和指令顺序一致 |

例子：

```text
ADD x5, x1, x2
SUB x6, x5, x3
```

SUB 在 EX 阶段需要 x5，但 ADD 的结果还没有写回 register file。

### 5.2 为什么 register file 写回太晚

无 forwarding 时，时序如下：

```text
cycle:  1   2   3   4   5   6
ADD:    IF  ID  EX  MEM WB
SUB:        IF  ID  EX  MEM WB
```

SUB 在 cycle 3 的 ID 读 register file，此时 ADD 要到 cycle 5 才 WB，SUB 读到旧 x5。

如果只靠 stall，要等 ADD 写回后 SUB 再读：

```text
cycle:  1   2   3   4   5   6   7   8
ADD:    IF  ID  EX  MEM WB
SUB:        IF  ID  ID  ID  EX  MEM WB
```

这会浪费多个 cycle。forwarding 的目的就是减少 stall。

### 5.3 forwarding 的基本思想

forwarding 不等结果写回 register file，而是从后面 stage 直接把结果送到前面需要它的 EX 输入。

更准确地说，forwarding 解决的是“数据已经在某个流水级产生，但还没有写回架构寄存器”的时序窗口。它不是按指令名字前递，而是按 producer 的结果可用时间和 consumer 的操作数需要时间来决定。

典型路径：

```text
EX/MEM.alu_result  ----+
                       |
MEM/WB.wb_data     ----+--> operand MUX --> ALU input
                       |
ID/EX.rs_value     ----+
```

常见 forwarding 来源：

| 来源 | 目标 | 用途 |
|---|---|---|
| EX/MEM -> EX | 下一条指令需要上一条 ALU 结果 | ALU-ALU 相关 |
| MEM/WB -> EX | 隔一条指令需要结果，或 load 数据已到 WB | ALU/load 结果前递 |
| MEM/WB -> ID | 某些 register file 读写语义下辅助读新值 | 依设计而定 |
| EX/MEM 或 MEM/WB -> store data | store 的 rs2 数据来自前面指令 | store data forwarding |

| producer 类型 | 结果何时可用 | 紧邻 consumer 能否只靠 forwarding | 说明 |
|---|---|---|---|
| ALU 指令 | EX 末尾，进入 EX/MEM 后可用 | 通常可以 | 下一拍 consumer 在 EX，从 EX/MEM 取数 |
| LUI/AUIPC/JAL | 依实现，常在 EX 或更早形成写回值 | 通常可以 | 关键是 forward data 必须选对 `wb_sel` |
| load 命中一拍 memory | MEM 末尾，进入 MEM/WB 后可用 | 通常不可以 | 紧邻 consumer 同拍 EX 太早，需要 bubble |
| 多周期乘除法 | done 时才可用 | 取决于 interlock/scoreboard | 未 done 前不能前递 |
| CSR (控制状态寄存器)读写 | CSR read stage 结束后 | 取决于放在哪一级 | 还要处理异常和特权检查 |

因此，forwarding 单元不能只看 `rd == rs1/rs2`。它还要知道该 producer 的数据在当前 cycle 是否已经可用。把 load 的 EX/MEM 地址计算结果误当前递数据，是 load-use bug 的典型来源。

从 forwarding 的适用范围也能反过来理解哪些流水级需要 stall/bubble/flush、哪些不需要。

- EX/MEM 和 MEM/WB 两级在任何情况下都不需要 stall、bubble 或 flush。因为 GPR 只读于 ID、只写于 WB：RAW 数据缺口由 forwarding_unit 跨级前递填补（EX/MEM -> EX 或 MEM/WB -> EX），不需要让 EX/MEM 或 MEM/WB 停住。
- 同样，branch/JAL/JALR 在 EX 阶段算出 redirect 后，flush 只杀 IF/ID 和 ID/EX 中的错误路径指令；走到 EX/MEM 的指令必定已是正确路径，不存在需要 flush 的理由。

store 的 rs2 数据依赖也是同一类问题。若 store 的 rs2 来自前一条 `load` 如：

```text
LW x5, ...
SW x5, ...
```

`load` 数据到 MEM 末尾才有效。

标准处理是 load-use stall 一拍（冻结 PC 和 IF/ID，ID/EX 插 bubble），下一拍 consumer 进入 EX 时从 MEM/WB forward 拿到 load data。

不需要 MEM/WB -> MEM 转发，因为 store_data 已在 EX 阶段选好并锁存进 EX/MEM 寄存器；等 load_data 到达 MEM/WB 时，SW 的 store_data 早已在 EX/MEM 里，MEM 阶段使用的是上一拍锁存的数据，而非当前 MEM/WB 的组合输出。

> 注意：EX/MEM -> EX 之所以可行，是因为 EX 是纯组合逻辑：forwarding mux 改变输入后，同一拍内 ALU 和 branch comparator 的输出随之更新，结果在时钟沿锁存进 EX/MEM。

### 5.4 ALU-ALU forwarding 示例

```text
I1: ADD x5, x1, x2
I2: SUB x6, x5, x3
```

时序：

```text
cycle:  1   2   3   4   5   6
I1:     IF  ID  EX  MEM WB
I2:         IF  ID  EX  MEM WB
```

在 cycle 4：

- I1 位于 MEM，ALU 结果保存在 EX/MEM。
- I2 位于 EX，需要 x5。
- forwarding MUX 选择 EX/MEM.alu_result 给 I2 的 ALU 输入。

这样不需要 stall。

### 5.5 forwarding 检测条件

以 EX 阶段源操作数 A 为例：

```text
如果 EX/MEM 阶段指令有效，并且会写 rd，并且 rd != x0，并且 rd == ID/EX.rs1，
则 operand A 从 EX/MEM forwarding。

否则，如果 MEM/WB 阶段指令有效，并且会写 rd，并且 rd != x0，并且 rd == ID/EX.rs1，
则 operand A 从 MEM/WB forwarding。

否则 operand A 使用 ID/EX 中保存的 register file 读值。
```

EX/MEM 优先于 MEM/WB，因为它代表更年轻、更接近消费者的写入。

### 5.6 forwarding 控制示例

```systemverilog
typedef enum logic [1:0] {
  FWD_REG,                                                            // 使用 ID/EX 中已经保存的 register file 读值
  FWD_EX_MEM,                                                         // 从 EX/MEM 旁路，通常是上一条 ALU 指令刚算出的结果
  FWD_MEM_WB                                                          // 从 MEM/WB 旁路，通常是更老一拍的 ALU/load/writeback 数据
} fwd_sel_e;

always_comb begin
  fwd_a_sel_o = FWD_REG;                                              // 默认不前递，operand A 直接用 ID/EX.rs1_value
  fwd_b_sel_o = FWD_REG;                                              // 默认不前递，operand B 直接用 ID/EX.rs2_value

  if (ex_mem_valid_i && ex_mem_reg_we_i &&                            // EX/MEM 中有有效 producer，且它会写 GPR
      (ex_mem_rd_i != 5'd0) && (ex_mem_rd_i == id_ex_rs1_i)) begin    // producer.rd 命中当前 EX 消费者的 rs1，且 rd 不是 x0
    fwd_a_sel_o = FWD_EX_MEM;                                         // 选择最近的 EX/MEM 结果，优先级高于 MEM/WB
  end else if (mem_wb_valid_i && mem_wb_reg_we_i &&                   // 若 EX/MEM 未命中，再检查 MEM/WB 中更老的 producer
      (mem_wb_rd_i != 5'd0) && (mem_wb_rd_i == id_ex_rs1_i)) begin    // producer.rd 命中 rs1，且 rd 不是 x0
    fwd_a_sel_o = FWD_MEM_WB;                                         // 选择 MEM/WB 写回数据作为 operand A
  end

  if (ex_mem_valid_i && ex_mem_reg_we_i &&                            // operand B 的判断逻辑与 operand A 相同
      (ex_mem_rd_i != 5'd0) && (ex_mem_rd_i == id_ex_rs2_i)) begin    // producer.rd 命中当前 EX 消费者的 rs2
    fwd_b_sel_o = FWD_EX_MEM;                                         // store data 或 ALU operand B 都可能需要这一路
  end else if (mem_wb_valid_i && mem_wb_reg_we_i &&                   // EX/MEM 未命中时，继续检查 MEM/WB
      (mem_wb_rd_i != 5'd0) && (mem_wb_rd_i == id_ex_rs2_i)) begin    // producer.rd 命中 rs2，且 rd 不是 x0
    fwd_b_sel_o = FWD_MEM_WB;                                         // 选择 MEM/WB 写回数据作为 operand B
  end
end
```

注意：

- x0 不需要 forwarding。
- 对 load 指令，EX/MEM 阶段可能还没有真正 load data，不能把地址计算结果当成 load 结果前递给 ALU。
- forwarding 数据源必须根据写回选择产生，例如 ALU 结果、load 数据、PC+4、CSR 数据。

### 5.7 store data forwarding

store data forwarding 指的是：**store 指令要写入 memory 的数据来自前面某条还没写回 register file 的指令时，硬件要把这个新数据旁路给 store，而不能让 store 写入旧值**。

store 指令有两个源寄存器，但它们的用途不同：

| 源寄存器 | 在 store 中的作用 | 典型使用阶段 | 是否需要 forwarding |
|---|---|---|---|
| `rs1` | base address，用来和 immediate 相加形成 effective address | EX | 需要普通 ALU operand forwarding |
| `rs2` | store data，也就是要写进 memory 的数据 | 通常在 MEM 真正写出 | 需要 store data forwarding |

所以 store 的 forwarding 不能只看“ALU 两个输入”。`rs1` 影响写到哪里，`rs2` 影响写什么值；二者任何一个用旧值都会出错。

例子：

```text
ADD x5, x1, x2
SW  x5, 0(x10)
```

第二条 `SW` 的含义是：

```text
memory[x10 + 0] = x5
```

这里 `x10` 是地址基址，`x5` 是要写入 memory 的数据。`ADD` 刚产生新的 `x5`，但这个结果可能还没有写回 register file；如果 `SW` 直接使用 ID 阶段读出的旧 `x5`，memory 中就会被写入错误数据。

如果 x5 是 store data：

- 可以在 EX 阶段把前递后的 `rs2` 选好，写入 `EX/MEM.store_data`，再一路带到 MEM。
- 也可以让 `SW` 到 MEM 阶段时，再专门比较它的 `rs2` 和后级 producer 的 `rd`，命中后把最新数据送到 data memory 写端口。

两种做法都可以，关键是项目里要定义清楚 store data 在哪一级最终确定，并让 hazard/forwarding 单元和这个时序一致。

容易漏测的是：

```text
LW  x5, 0(x1)
SW  x5, 4(x2)
```

这组指令比 `ADD -> SW` 更容易出 bug。`LW` 的数据通常到 MEM 末尾或 MEM/WB 才有效，而紧跟的 `SW` 要把这个 load 出来的新 `x5` 写到另一个地址。如果设计只做了 EX/MEM 到 EX 的 ALU forwarding，却没有覆盖 store data 路径，`SW` 可能会把旧 `x5` 写进 memory。

验证时建议至少覆盖三类情况：

| 序列 | 检查点 |
|---|---|
| `ADD rd,...` 后紧跟 `SW rd, offset(base)` | ALU 结果能作为 store data 写出 |
| `LW rd,...` 后紧跟或隔一条 `SW rd, offset(base)` | load data 能作为 store data 写出，必要时插入 stall |
| `SW rs2, offset(rd)` 且前一条写 `rd` | store address 的 base forwarding 也正确 |

### 5.8 register file (寄存器堆)写读语义

有些 register file 支持同一 cycle 对同一地址先写后读，ID 阶段可以读到 WB 正在写的数据；有些则读到旧值。

两种语义：

| 语义 | 同 cycle 写 rd、读 rs 命中时读到 |
|---|---|
| write-first | 新写入数据 |
| read-first | 旧数据 |

如果设计依赖 write-first，必须确保：

- 目标工艺或 FPGA 原语支持该行为。
- 仿真模型和综合后行为一致。
- 验证中覆盖 WB 与 ID 同址读写。

更稳妥的做法是把 WB forwarding 显式建模，不隐含依赖不清楚的 memory macro 语义。

---

## 第6章 Load-Use Hazard

### 6.0 本章概述

第4章已经把 Load-Use Hazard 放在 data hazard 里做了总览：它本质上仍然是 RAW 相关，只是 producer 是 load 指令，结果要到 MEM 阶段访存后才真正可用。

load-use hazard 是五级流水线最经典的面试题。它说明 forwarding 不是万能的：如果数据本身还没从 memory 返回，就没有东西可以前递。

可以把 ALU 指令和 load 指令先粗略区分成两种 producer：

| producer | EX 阶段做什么 | 结果大约什么时候可用 | 紧邻下一条指令能否直接用 |
|---|---|---|---|
| `ADD/SUB/AND` 等 ALU 指令 | 用组合逻辑算出结果 | EX 末尾已经得到 ALU result，下一拍可从 EX/MEM 前递 | 通常可以 |
| `LW/LH/LB` 等 load 指令 | 先用 ALU 算出访存地址 | 真正要写回的 load data 要等 MEM 访问 memory 后才返回 | 通常不可以，需要 stall |

也就是说，`LW x5, 0(x1)` 的 EX 阶段只是在算地址 `x1 + 0`，这时还没有读到 memory 里的数据。紧跟着的 `ADD x6, x5, x2` 到 EX 阶段时，ALU 输入需要的是 `x5` 的 load data，而不是 load 的地址计算结果。由于这份 data 通常要到同一个 cycle 的 MEM 末尾才有效，已经晚于 `ADD` 在 EX 前半段选择操作数的时间，所以不能像普通 ALU-ALU 相关那样直接前递。

### 6.1 典型例子

```text
LW  x5, 0(x1)
ADD x6, x5, x2
```

时序：

```text
cycle:  1   2   3   4   5   6
LW:     IF  ID  EX  MEM WB
ADD:        IF  ID  EX  MEM WB
```

在 cycle 4：

- LW 在 MEM，load data 通常到 cycle 4 末尾才有效。
- ADD 在 EX，cycle 4 中就需要操作数 x5。

因此无法在同一个 cycle 早些时候把还没产生的 load data 送给 ADD 的 ALU。需要 stall 一拍。

### 6.2 插入 bubble 后的时序

```text
cycle:  1   2   3   4   5   6   7
LW:     IF  ID  EX  MEM WB
ADD:        IF  ID  ID  EX  MEM WB
bubble:             EX
```

控制动作：

- PC 保持不变。
- IF/ID 保持不变，让 ADD 停在 ID。
- ID/EX 写入 bubble。
- LW 继续从 EX 进入 MEM，再进入 WB。
- 下一拍 ADD 进入 EX，从 MEM/WB forwarding 获得 load data。

### 6.3 检测条件

典型 load-use 检测：

```text
ID/EX 阶段是 load，且会写 rd；
IF/ID 阶段指令有效；
IF/ID.rs1 或 IF/ID.rs2 需要读取该 rd；
rd != x0；
则 stall。
```

注意“需要读取”很重要。不是所有指令字段 `[24:20]` 都表示 rs2。例如 I-type 指令没有 rs2。误判会造成多余 stall，漏判会造成功能错误。

### 6.4 RTL 示例

```systemverilog
always_comb begin
  load_use_stall_o = 1'b0;                                             // 默认不 stall，只有确认 load-use 相关时才拉高

  if (id_ex_valid_i && id_ex_is_load_i && id_ex_reg_we_i &&            // ID/EX 中有有效 load producer，且它会写 GPR
      (id_ex_rd_i != 5'd0) && if_id_valid_i) begin                     // producer.rd 不是 x0，且 IF/ID 中有有效 consumer
    if ((if_id_uses_rs1_i && (if_id_rs1_i == id_ex_rd_i)) ||           // consumer 确实使用 rs1，且 rs1 命中 load 的 rd
        (if_id_uses_rs2_i && (if_id_rs2_i == id_ex_rd_i))) begin       // consumer 确实使用 rs2，且 rs2 命中 load 的 rd
      load_use_stall_o = 1'b1;                                         // load data 还没从 MEM 返回，必须插入 bubble 等一拍
    end
  end
end
```

配套控制：

```text
load_use_stall:
  pc_write      = 0
  if_id_write   = 0
  id_ex_flush   = 1   // 插入 bubble
  ex_mem_write  = 1   // 后级继续推进
  mem_wb_write  = 1   // 后级继续推进
```

这里要区分“检测信号”和“流水线动作”。`load_use_stall_o` 只是说明控制单元发现了 load-use hazard；真正改变流水线状态的是 `pc_write`、`if_id_write`、`id_ex_flush` 这些控制信号。

和 6.2 的控制动作对照如下：

| 控制信号 | 取值 | 对应 6.2 的动作 | 为什么这么做 |
|---|---:|---|---|
| `pc_write` | `0` | PC 保持不变 | 不让 IF 继续取走新的顺序指令，否则前端会越过当前等待的 consumer |
| `if_id_write` | `0` | IF/ID 保持不变，让 `ADD` 停在 ID | consumer 还不能进入 EX，因为它需要的 load data 尚未返回 |
| `id_ex_flush` | `1` | ID/EX 写入 bubble | 在 EX 阶段插入一个空槽，让前面的 `LW` 能继续进入 MEM，同时不让 `ADD` 错误进入 EX |
| `ex_mem_write` | `1` | `LW` 继续从 EX 进入 MEM | producer 必须继续前进到 MEM，才能真正访问 memory 并拿到 load data |
| `mem_wb_write` | `1` | MEM 结果继续进入 WB | load data 返回后要进入 MEM/WB，下一拍才能作为 forwarding 来源 |

所以 load-use stall 的动作不是“整条流水线全部冻结”。更准确地说，它是**冻结 PC 和 IF/ID，向 ID/EX 插入 bubble，同时让 EX/MEM 和 MEM/WB 正常推进**：load 指令继续向 MEM 前进，consumer 指令留在 ID 等一拍。

“下一拍 `ADD` 进入 EX，从 MEM/WB forwarding 获得 load data”对应的是 stall 解除后的正常推进和 forwarding 选择：

```text
next cycle after bubble:
  pc_write      = 1
  if_id_write   = 1
  id_ex_flush   = 0
  fwd_a_sel_o / fwd_b_sel_o = FWD_MEM_WB   // 如果 ADD 的 rs1/rs2 命中 MEM/WB.rd
```

也就是说，load-use interlock 只负责把 consumer 延后一拍；真正把 load data 送到 `ADD` ALU 输入的，是第5章讲过的 MEM/WB -> EX forwarding。

### 6.5 load-use 的变体

需要覆盖的序列：

```text
LW  x5, 0(x1)
ADD x6, x5, x2       // rs1 相关

LW  x5, 0(x1)
ADD x6, x2, x5       // rs2 相关

LW  x5, 0(x1)
SW  x5, 0(x2)        // store data 相关

LW  x5, 0(x1)
BEQ x5, x0, label    // branch compare 相关，取决于分支在哪一级比较

LW  x0, 0(x1)
ADD x6, x0, x2       // 不应 stall，因为 x0 恒为 0
```

### 6.6 如果 memory 延迟不固定

前面假设 data memory 一拍返回。如果 data cache miss 或总线等待导致 load 延迟不固定，则简单“一拍 bubble”不够。

需要：

- MEM 阶段保持 load 指令直到 data valid。
- 后续 stage 不能错误前进。
- 前面 stage 可能 backpressure。
- load data 到达后再允许依赖指令继续。

这时 pipeline 更接近 valid-ready 控制，而不是固定五级每拍推进。

固定一拍 memory 和可变延迟 memory 的控制差异可以这样看：

| memory 模型 | load 数据返回 | load-use 处理 | 控制核心 |
|---|---|---|---|
| 一拍同步 SRAM | MEM 末尾固定返回 | 固定插入 1 个 bubble | 简单 interlock |
| cache hit/miss | hit 一拍，miss 多拍 | hit 后可继续，miss 期间全局或局部 stall | data valid + backpressure |
| 总线外设/MMIO | 延迟不可预测 | load/store 请求保持到 response | valid-ready 或 request/response 状态机 |

如果 MEM stage 因 cache miss 停住，不能只停住 MEM 自己。后面的 WB 可能还能接收已有结果，前面的 EX/ID/IF 也必须按设计 backpressure，否则会出现三类严重问题：

- 同一条 load 被覆盖，response 回来后找不到对应指令。
- 年轻指令越过未完成 load 提交，破坏顺序核的精确异常模型。
- store 在 miss 或 flush 期间重复发起，造成外设副作用重复。

因此，真实项目常会把 `mem_stall` 纳入统一 pipeline enable/flush 逻辑，而不是把 load-use interlock 当成唯一 stall 来源。验证上要覆盖 miss 持续 0、1、多拍，并检查 PC、IF/ID、ID/EX 的保持关系。

---

## 第7章 Structural Hazard

### 7.0 本章概述

structural hazard 不是“后面的指令需要前面的结果”，而是“同一个 cycle 里，有多个流水级想用同一个硬件资源，但这个资源同一拍服务不了这么多请求”。可以用一个很朴素的判断式理解：

$$
\text{某资源在本 cycle 的需求次数} > \text{该资源本 cycle 能服务的次数}
$$

在理想五级流水线里，同一个 cycle 不是只有一条指令在动，而是可能同时有五条不同指令分别位于 IF、ID、EX、MEM、WB：

| 流水级 | 这一拍通常需要的硬件资源 | 如果资源不够会怎样 |
|---|---|---|
| IF | PC 寄存器、PC+4 加法器、取指访问路径 | 取不到下一条 instruction，前端 stall |
| ID | decoder、immediate generator、register file 读端口 | 源操作数读不全，ID 不能推进 |
| EX | ALU、branch comparator、地址/目标地址计算资源 | 当前指令不能完成执行计算 |
| MEM | data memory、D-cache、总线或 MMIO 访问路径 | load/store 不能完成访存 |
| WB | register file 写端口 | rd 不能在本拍写回 |

所以，structural hazard 的学习重点不是“背有哪些资源冲突”，而是看懂：**五级流水线之所以能每拍推进，是因为硬件资源被设计成足够并行**。入门模型经常直接假设这些资源已经分开，因此很多 structural hazard 平时看不到；但面试里常会追问“为什么 instruction memory 和 data memory 要分离”“为什么 GPR 要 2 读 1 写”“为什么 PC+4 不一定复用主 ALU”，问的就是这些假设背后的硬件原因。

### 7.1 instruction memory 与 data memory 冲突

这里的 `instruction memory` 和 `data memory` 沿用的是流水线视角，分别表示 IF 阶段的取指访问路径和 MEM 阶段的 load/store 访问路径。它们不一定对应真实 SoC 里两块独立的物理 RAM：instruction 可能来自 boot ROM、flash、SRAM、I-cache 或总线；data 可能来自 SRAM、D-cache、DRAM、MMIO 外设，甚至由 storage controller 把 block device 中的数据搬到 DRAM 后再被 CPU 读取。`0801` 第7章已经先建立了这张直觉地图，本节只关心这些访问路径在同一个 cycle 会不会抢同一个硬件端口。

这是初学五级流水线时最值得先理解的 structural hazard。假设 IF 和 MEM 共用一个 single-port RAM：

```text
cycle N:
  I4 位于 IF   ：需要取下一条 instruction
  I1 位于 MEM  ：需要执行 load/store
```

single-port RAM 同一拍只能做一次读或写。现在 IF 想读 instruction，MEM 也想访问 data，两者同时访问同一个端口，就冲突。

这不是 data hazard，因为两条指令不一定有数据依赖；也不是 control hazard，因为 PC 不一定跳错。它单纯是硬件端口不够。

| 解决方法 | 硬件含义 | 对初学五级流水线的意义 |
|---|---|---|
| 使用 Harvard architecture | 取指和访存走两套访问路径 | 教科书五级流水线最常用的假设 |
| 使用 dual-port RAM | 同一个存储体提供两个端口 | 面积、时序和存储宏选择会更复杂 |
| MEM 访问时让 IF stall | 资源只有一个，优先保证 load/store | 硬件简单，但 CPI 变差 |
| 引入 instruction cache 和 data cache | 前端访问 I-cache，访存访问 D-cache | 更接近真实处理器，但 cache miss 后仍可能产生 backpressure |

如果选择“MEM 访问时让 IF stall”，控制动作要说清楚是“只停前端取指”，不是把整条流水线都冻结。一个常见保守做法是：PC 保持不变，IF/ID 不接收新指令，并在前端插入一个空槽；后面的 ID/EX、EX/MEM、MEM/WB 继续正常推进。

```text
当 MEM stage 正在占用统一 memory 端口：
  pc_write       = 0   // PC 保持，下一拍仍从同一个 PC 重新尝试取指
  if_id_bubble   = 1   // IF 没有取到新 instruction，IF/ID 写入空槽
  downstream_en  = 1   // ID/EX、EX/MEM、MEM/WB 继续推进，让 MEM 尽快释放端口
```

这和第6章 load-use stall 不完全一样。load-use 是让 ID 里的 consumer 原地等一拍，所以 IF/ID 要保持；single-port memory 冲突则是 IF 本拍没有拿到新指令，ID 中已有的指令通常可以继续往后走，因此 IF/ID 更像写入 bubble。二者都属于 stall/backpressure，但保持哪个流水线寄存器、哪个位置插 bubble，要由具体资源冲突的位置决定。

### 7.2 single-port memory 冲突的 RTL 示例

下面只展示一种最典型的 structural hazard：IF 取指和 MEM load/store 共用一个 single-port memory 端口。这个示例假设：

- MEM 阶段的 load/store 优先级高于 IF 取指。
- 当 MEM 占用端口时，IF 本拍不能发起取指。
- ID 及更后面的 stage 仍可继续推进。
- IF/ID 写入 bubble，表示这一拍前端没有提供新 instruction。

```systemverilog
always_comb begin
  mem_port_used_by_mem_o = ex_mem_valid_i && ex_mem_mem_req_i;            // MEM 阶段有有效 load/store，需要占用统一 memory 端口
  if_req_valid_o         = if_valid_i && !mem_port_used_by_mem_o;         // 只有端口没被 MEM 占用时，IF 才能发起取指请求

  pc_write_o             = 1'b1;                                          // 默认 PC 正常更新到 next PC
  if_id_write_o          = 1'b1;                                          // 默认 IF/ID 接收本拍取到的新指令
  if_id_bubble_o         = 1'b0;                                          // 默认不插入前端 bubble

  if (mem_port_used_by_mem_o) begin                                       // IF 和 MEM 争用 single-port memory，MEM 优先
    pc_write_o           = 1'b0;                                          // PC 保持，下一拍重新尝试取同一个地址
    if_id_write_o        = 1'b1;                                          // IF/ID 仍更新，但写入的是 bubble，而不是重复旧指令
    if_id_bubble_o       = 1'b1;                                          // 本拍没有有效新 instruction 进入 ID
  end
end
```

对应的 IF/ID pipeline register 可以这样理解：

```systemverilog
always_ff @(posedge clk or negedge rst_n) begin
  if (!rst_n) begin
    if_id_valid_q <= 1'b0;                                                // 复位后 IF/ID 为空
  end else if (if_id_flush_i) begin
    if_id_valid_q <= 1'b0;                                                // control hazard 或 trap 时清掉错误路径指令
  end else if (if_id_write_i) begin
    if_id_valid_q <= if_resp_valid_i && !if_id_bubble_i;                  // 插 bubble 时 valid=0，表示没有真实指令进入 ID
    if_id_pc_q    <= if_pc_i;                                             // PC 可保留调试值；valid=0 时不能被当成真实指令提交
    if_id_inst_q  <= if_resp_inst_i;                                      // valid=0 时 inst 内容无架构意义，后级必须用 valid 门控
  end
end
```

这个例子故意没有写完整 memory arbiter，因为本节只想说明 structural hazard 的控制核心：**资源被 MEM 占用时，IF 不能假装取到了指令；流水线要么保持等待的 stage，要么插入 bubble，但不能让无效取指结果当成真实 instruction 往后流。**

### 7.3 register file 端口冲突

第二个典型例子是 register file 端口。这里的 register file 就是 `0801` 第3.4节讲的 x0-x31 GPR 的物理寄存器堆，不是 ABI 别名本身；ABI 名字只是软件约定，硬件实际看到的是 rs1、rs2、rd 编号。

在同一个 cycle 中，流水线里可能同时发生：

```text
ID stage:  一条较年轻指令要读 rs1、rs2
WB stage:  一条较年老指令要写 rd
```

所以典型 RV32I 五级流水线的 GPR 做成：

```text
2 read ports + 1 write port
```

这里的“2 读 1 写”不是随便定的，而是由指令格式和流水线并行性共同决定的：

| 指令类别 | ID 阶段最多读几个 GPR | WB 阶段是否写 GPR | 为什么需要这些端口 |
|---|---:|---|---|
| R-type，例如 `ADD rd, rs1, rs2` | 2 | 写 rd | 同一条指令需要两个源操作数 |
| I-type，例如 `ADDI rd, rs1, imm` | 1 | 写 rd | 一个源操作数来自 GPR，另一个来自 immediate |
| load，例如 `LW rd, imm(rs1)` | 1 | 写 rd | rs1 用来算 effective address，load value 写回 rd |
| store，例如 `SW rs2, imm(rs1)` | 2 | 不写 rd | rs1 给地址基址，rs2 给 store data |
| branch，例如 `BEQ rs1, rs2, label` | 2 | 不写 rd | 需要比较两个源寄存器 |

如果 register file 只有 1 个读端口，`ADD`、`SW`、`BEQ` 这类需要两个源操作数的指令就不能在一个 ID cycle 读完，只能分两拍读，或者让 ID stall 一拍。如果没有独立写端口，WB 写回也会和 ID 读寄存器争用，流水线就无法保持理想的一拍推进。

还有一个容易混淆的点：同一拍 WB 写 `rd`，ID 又读同一个寄存器时，是否能读到新值，取决于 register file 的 write-first/read-first 语义，或者是否额外做 writeback forwarding。这个问题和 data hazard 有交叉，但端口数量本身仍然属于 structural hazard 的讨论范围。

### 7.4 计算资源复用：不是“两条 EX 指令抢 ALU”

这里需要把一个常见误解拆开：**经典单发射、顺序五级流水线里，同一个 cycle 通常只有一条指令处于 EX，所以一般不是“两条 EX 指令同时抢主 ALU”。**

真正容易发生的是另一类问题：同一个 cycle 中，不同流水级或者同一条复杂控制流指令，都可能需要“加法/比较/地址计算”这类计算资源。

先看不同流水级同拍的例子：

```text
cycle N:
  IF:  需要计算 PC + 4，用来顺序取下一条 instruction
  EX:  当前指令是 LW，需要计算 rs1 + imm，得到 load effective address
```

如果整个 CPU 只有一个加法器，而且 PC+4 和 load 地址都必须在这一拍得到结果，那么这两个计算就会抢同一个资源。实际设计通常不会这样做，而是给 IF 放一个很小的 PC+4 加法器，EX 再用主 ALU 算 load/store 地址。

再看同一条 branch 指令的例子：

```asm
BEQ x1, x2, label
```

这条指令在决定 next PC 时至少需要两类信息：

| 需要的信息 | 硬件计算 | 用途 |
|---|---|---|
| branch 是否成立 | 比较 `x1 == x2` | 决定走顺序路径还是跳转路径 |
| branch target | 计算 `PC + immB` | branch 成立时作为 next PC |

如果比较复用主 ALU，target 也复用主 ALU，就要么把计算拆到不同拍，造成 stall；要么在一个 cycle 内串起很长的组合路径，影响 Fmax。更常见的做法是：主 ALU 负责普通算术/地址计算，branch comparator 负责比较，branch target adder 负责目标地址计算。

类似地，`JALR rd, imm(rs1)` 也需要：

$$
\text{target PC} = (\text{rs1} + \text{imm}) \mathbin{\&} \sim 1
$$

同时还要把返回地址 `PC+4` 写入 `rd`。因此很多实现会把 `PC+4` 很早就算好并一路带到 WB，而不是到 JALR 执行时再临时抢主 ALU。

几种实现选择可以这样对比：

| 实现选择 | 做法 | 优点 | 代价 |
|---|---|---|---|
| 主 ALU 大量复用 | PC+4、地址、target、比较都尽量走主 ALU 或同一套组合路径 | 面积小，早期教学设计容易画 | MUX 多，控制绕，critical path 可能变长；必要时还要 stall |
| 增加 PC+4 adder | IF stage 专门计算顺序 next PC | 取指路径清楚，几乎是经典五级流水线标配 | 多一个小加法器 |
| 增加 branch target adder | EX 或 ID 单独计算 `PC + immB` | 分支处理更清楚，减少和主 ALU 抢资源 | 面积略增；若放 ID，会拉长 ID stage |
| 增加 branch comparator | 比较逻辑不复用主 ALU | branch taken 判断更直接 | 需要额外比较器和 forwarding 配合 |
| 把部分计算提前到 ID | 提前算 target 或提前比较 | 可能减少 branch penalty | ID stage 更复杂，ID 阶段也可能需要 forwarding |

所以本节的核心不是“一个硬件线程单发射时会有多条 EX 指令”，而是：**一个看起来简单的五级流水线，其实每拍同时需要多个计算结果。到底复制小硬件，还是复用大硬件，是 PPA trade-off。**

### 7.5 多周期执行单元冲突

MDU 是 multiply/divide unit，也就是乘除法单元。RISC-V 基础整数指令集 RV32I/RV64I 不包含整数乘除法；如果实现 M extension，才会有 `MUL`、`MULH`、`DIV`、`REM` 这类指令。当前阶段不需要深入 M extension 的算法，只要知道：乘法和除法通常比普通 `ADD/SUB/AND/OR` 更贵，简单核可能不愿意做成“一拍完成”。

先看最直接的结构冲突：两条乘除法指令连续到来，但硬件里只有一个迭代 MDU(乘除单元，独立于 ALU)。迭代 MDU 的意思是，它接收一条 `MUL` 或 `DIV` 后，需要连续工作多拍，busy 期间不能再接收下一条乘除法请求。

```text
cycle 3: MUL x5, x1, x2  进入 EX，MDU 开始工作
cycle 4: DIV x6, x3, x4  也想进入 EX，但 MDU 仍 busy
cycle 5: DIV             继续等待
cycle 6: MUL             完成，结果可以向后推进
cycle 7: DIV             才能启动 MDU
```

这里 `DIV` 等待的原因不是它要读 `MUL` 的结果，而是同一个 MDU 还没空出来。因此这是 structural hazard：执行单元资源被占用。

再看一个容易困惑的情况：为什么有些资料会说 `MUL` 后面的普通 `ADD` 也可能被堵住？`ADD` 本身不需要 MDU，它只需要普通 ALU。它被堵住通常不是因为“ADD 抢 MDU”，而是因为简单顺序核采用了更保守的控制：只要 EX stage 中的多周期指令没完成，就把整个 EX stage 冻住，ID/IF 也一起 backpressure。这样控制简单，但无关指令也会被挡住。

```text
cycle 3: MUL 进入 EX，MDU busy
cycle 4: ADD 想进入 EX；虽然 ADD 不用 MDU，但 EX stage 被 MUL 占住
cycle 5: ADD 继续等待
cycle 6: MUL 完成并离开 EX
cycle 7: ADD 进入 EX，使用普通 ALU
```

所以这里要分清两层：

| 情况 | 为什么等待 | 属于哪类理解 |
|---|---|---|
| `MUL` 后接 `DIV`，只有一个 MDU | 两条 M extension 指令抢同一个 MDU | 直接的 structural hazard |
| `MUL` 后接无关 `ADD`，简单核仍 stall | 整个 EX stage 被多周期指令占住 | 保守流水线控制带来的结构占用 |
| `MUL x5,...` 后接 `ADD x6,x5,x7` | `ADD` 还需要 `x5` 的结果 | data hazard 和结构占用可能同时存在 |

| 方案 | 控制方式 | 适用场景 |
|---|---|---|
| EX 整体 stall | MDU busy 时，EX 不接收新指令，ID/IF 被 backpressure | 简单顺序核，控制最容易 |
| 乘法器 pipeline 化 | 每拍可以接收一个新的乘法请求，若干拍后连续出结果 | 乘法频繁、追求 throughput 的设计 |
| 除法器独立握手 | DIV 发给独立 MDU，完成后再写回或提交 | 比固定 stall 更灵活，但控制复杂 |
| 配合 scoreboard | 记录哪些 rd 结果未完成，允许无关指令继续前进 | 已经接近更复杂的顺序非阻塞或乱序思想 |

对初学五级流水线来说，记住第一行就够用：**多周期执行单元会让执行资源长时间 busy，因此可能产生 structural hazard，并通过 stall/backpressure 解决。**

### 7.6 后续还会在哪里遇到 structural hazard

本章前面讲的是最适合五级流水线入门的结构冲突。随着模型更接近真实 SoC，还会遇到一些更系统级的资源冲突：

| 场景 | 为什么像 structural hazard | 后续在哪里继续看 |
|---|---|---|
| cache miss 后 MEM stage 等 memory response | MEM stage 的访存资源没有完成，前后级需要 backpressure | `0805` 第3.3/3.4 会从 cache refill、MSHR 和 miss 阻塞角度继续讲 |
| CPU、DMA、外设同时访问总线或 SRAM | 多个访问者争用同一条 bus、同一个 SRAM 端口或同一个 memory controller | `0804` 第2章和第5章会从 interconnect、仲裁和 outstanding 事务角度继续讲 |
| MMIO 访问慢外设 | load/store 发出后，外设若干拍后才返回 response | `0804` 第1章、第5章会从 MMIO 事务、bridge 和 timeout 角度继续讲 |
| store buffer 满 | 新 store 想进入队列，但队列没有空位 | `0805` 第6.2 会从 store buffer、FENCE 和 drain 角度继续讲 |
| CSR 或特权控制路径需要串行化 | 某些状态更新不能和普通指令随意并行 | `0803` 第7.3 会从 CSR/trap/xRET 同拍竞争和优先级角度继续讲 |

这些内容暂时不需要提前学深。现在先建立一个判断标准即可：只要问题的根因是“硬件资源、端口、队列、执行单元或访问路径服务不过来”，就优先从 structural hazard 的角度分析；如果根因是“值没准备好”，再去看 data hazard；如果根因是“PC 路径选错或尚未确定”，再去看 control hazard。

### 7.7 本章小结

面试中可以这样回答 structural hazard：

> structural hazard 是流水线同一拍多个动作争用同一硬件资源。经典五级流水线为了接近每拍完成一条指令，通常假设 instruction/data 访问路径分离、register file 有 2 读 1 写端口、IF 有 PC+4 加法器、EX 有主 ALU，必要时再给 branch 单独比较器和 target adder。如果资源不足，就要复制资源、增加端口、pipeline 化资源，或者通过 stall/backpressure 让流水线等待。

对当前阶段最重要的三个例子是：

1. IF 取指和 MEM load/store 抢 single-port RAM。
2. ID 读 rs1/rs2 和 WB 写 rd 需要 register file 端口支持。
3. PC+4、load/store 地址、branch target、branch compare 等计算资源是否复用，会影响面积、时序和 CPI。

---

## 第8章 Control Hazard 与分支处理

### 8.0 本章概述

control hazard 的根源是：IF 需要每拍取下一条 instruction，但 branch/jump/trap 可能改变 PC。在目标和方向确定前，取到的指令可能是错路径。

### 8.1 分支决策在 EX 的代价

若 branch 在 EX 阶段才知道 taken/not taken：

```text
cycle:  1   2   3   4   5
BEQ:    IF  ID  EX  MEM WB
I+1:        IF  ID  EX
I+2:            IF  ID
```

如果 BEQ taken，则 I+1 和 I+2 是错路径，需要 flush。

代价通常是 2 个 cycle 左右，取决于设计中 PC redirect 何时生效。

这类代价可以粗略并入 CPI：

$$
penalty_{branch} \approx f_{branch} \times P_{mispredict} \times N_{flush}
$$

其中 $f_{branch}$ 是分支指令比例，$P_{mispredict}$ 是预测错误概率，$N_{flush}$ 是一次错误需要清掉或损失的 cycle 数。对 always not taken 来说，taken 分支都可看作预测错误，所以循环尾部 branch 会特别影响性能。

分支决策放在哪一级，本质是在时序和 CPI 之间取舍：

| 决策位置 | flush 代价 | 时序/控制代价 | 适用场景 |
|---|---:|---|---|
| EX | 较高，常见约 2 拍 | ID 简单，forwarding 主要到 EX | 入门五级流水线 |
| ID | 较低，常见约 1 拍 | ID 路径变长，需要到 ID 的 forwarding | 小核优化 branch penalty |
| IF/预测阶段 | 依预测准确率决定 | 需要 BTB/BHT/RAS 和恢复机制 | 高性能前端 |

### 8.2 always not taken (默认不跳转)

最简单策略：

- IF 默认取 `pc + 4`。
- branch 在 EX 判断。
- 如果 not taken，前面取的指令正确。
- 如果 taken，flush IF/ID 和 ID/EX 中的错路径指令，并把 PC 改为 branch target。

优点：

- 控制简单。
- 不需要预测表。

缺点：

- taken branch 有固定惩罚。
- 循环末尾分支通常 taken，会损失性能。

### 8.3 提前分支决策

可以把 branch comparator 和 target adder 放到 ID 阶段，减少 flush 代价。

但会带来：

- ID critical path 增长。
- branch 操作数可能需要更多 forwarding 到 ID。
- load-use 到 branch 的相关更复杂。

这是一种典型 trade-off：减少 branch penalty，但增加时序和控制复杂度。

### 8.4 JAL/JALR：无条件跳转也是 control redirect (控制流重定向)

JAL/JALR 不是“减少 control hazard 代价的一种技巧”，而是 RISC-V ISA 中本来就存在的无条件控制转移指令。它们和 branch 的区别是：branch 要先判断 taken/not taken，而 JAL/JALR 从语义上一定会跳转。硬件仍然要处理 PC redirect 和 flush，只是少了“条件是否成立”的判断。

可以这样对比：

| 指令类别 | 是否需要判断跳不跳 | target 来源 | 是否写 rd | 典型用途 |
|---|---|---|---|---|
| branch，例如 `BEQ` | 需要比较 rs1/rs2 | `PC + immB` | 不写 rd | if/loop 这类条件控制流 |
| `JAL rd, immJ` | 不需要，一定跳 | `PC + immJ` | 写 `PC+4` 到 rd | 函数调用、长距离直接跳转 |
| `JALR rd, imm(rs1)` | 不需要，一定跳 | `(rs1 + imm) & ~1` | 写 `PC+4` 到 rd | 函数返回、函数指针、间接调用 |

所以 8.4 要讲的不是“jump 可以消灭 control hazard”，而是：**jump 也会改变 PC，也会让已经按旧 PC 取进来的年轻指令变成错路径；只是它的 redirect 可能比条件 branch 更早、更确定。**

`JAL` 的目标只依赖当前指令的 PC 和 immediate：

$$
\text{jal\_target} = \text{PC} + \text{immJ}
$$

因此只要 ID 阶段已经拿到 instruction 并生成 immediate，就能很早算出 target。有些设计甚至在 IF/ID 附近就准备好 `PC+immJ`，这样 `JAL` 的 penalty 可以比 EX 决策的 branch 更小。

但 `JAL` 仍然有 flush 问题。假设 IF 默认每拍取 `PC+4`，而 `JAL` 在 ID 才被识别：

```text
cycle:  1   2   3
JAL:    IF  ID
I+1:        IF   <- 已经按 PC+4 取入，但 JAL 一定跳走
target:         IF
```

这里 `I+1` 是错路径，需要 flush。区别只是：`JAL` 不需要等到 EX 比较寄存器，所以通常比 `BEQ` 更早 redirect。

JALR 的目标依赖 rs1：

$$
\text{jalr\_target} = (\text{rs1} + \text{imm}) \mathbin{\&} \sim 1
$$

这里的 `& ~1` 来自 RISC-V ISA 规定：JALR 目标地址最低位要清 0。这样可以保证跳转目标至少按 2 byte 对齐，也给函数指针等软件约定留出低位标记空间。

`JALR` 比 `JAL` 晚一点，因为它的 target 依赖 `rs1` 的真实值。如果 `rs1` 来自前面指令，JALR 也会有 data hazard，需要 forwarding 或 stall。

JALR 比 JAL 更容易出 bug，因为它同时跨了三条路径：register source、immediate generator 和 PC redirect。一个典型序列是：

```asm
ADDI x1, x0, target
JALR x0, 0(x1)
```

如果 JALR 在 EX 计算 target，`x1` 需要从上一条 ADDI 前递；如果 forwarding 漏掉 jump operand，JALR 会用旧 `x1` 跳走。验证时要覆盖 JALR 的 `rs1` 来自前一条、隔一条、load 返回、以及 `rd=x0` 的纯跳转场景。

还要注意 `rd` 的含义。`JAL/JALR` 写回的不是 target，而是返回地址：

$$
\text{rd\_wdata} = \text{PC} + 4
$$

当 `rd = x1/ra` 时，软件通常把它当函数返回地址；当 `rd = x0` 时，就表示只跳转、不保存返回地址。例如 `JALR x0, 0(x1)` 常见于“跳到 x1 指向的位置，但不需要回来”的场景；函数返回更常见的伪指令 `RET` 本质上是 `JALR x0, 0(x1)`。

### 8.5 branch prediction 基础

更高性能设计会预测分支：

| 预测方式 | 思想 |
|---|---|
| always not taken | 默认不跳 |
| always taken | 默认跳 |
| static prediction | 根据方向或编译提示预测 |
| dynamic prediction | 根据历史行为预测 |
| BHT | 记录分支历史状态 |
| BTB | 记录分支目标地址 |
| RAS | 预测函数返回地址 |

入门五级流水线通常只需要会讲 always not taken 和 flush。若项目涉及 branch prediction，要能说清预测信息如何随指令进入 pipeline，以及 mispredict 如何恢复。

预测信息必须跟着指令流动，而不能只存在 IF 阶段。至少要记录：

```text
predicted_taken
predicted_target
predicted_next_pc
branch_pc
```

当 branch 在 EX 或 ID 解析出真实方向和真实 target 后，硬件比较 predicted next PC 和 actual next PC。如果不同，就 redirect PC (重定向 PC)，并 flush younger wrong-path instruction。这个过程和 data forwarding 一样，本质上不是“分支指令特殊处理一下”，而是让每条分支携带足够的元数据，在解析时能判断是否需要恢复。

### 8.6 redirect/flush RTL 示例

下面给一个入门五级流水线常见的控制示例：branch 和 JALR 都在 EX 阶段给出真实 next PC，JAL 在 ID 阶段已经可以给出 redirect。为了突出 control hazard，本例暂时不展开 trap/interrupt/cache miss 的优先级。

先约定一下信号含义：这里的 `flush_if_id_o`、`flush_id_ex_o` 表示“下一拍对应 pipeline register 写入 bubble”，而不是把 redirect 指令本身从当前 stage 里抹掉。比如 JAL 在 ID 阶段产生 redirect 时，JAL 自己仍要进入后级写回 `rd = PC+4`；被清掉的是更年轻的顺序取指结果。

```systemverilog
always_comb begin
  redirect_valid_o = 1'b0;                                                // 默认没有 PC redirect，IF 继续取顺序 next PC
  redirect_pc_o    = pc_plus4_i;                                          // 默认 next PC = PC + 4
  flush_if_id_o    = 1'b0;                                                // 默认不清 IF/ID
  flush_id_ex_o    = 1'b0;                                                // 默认不清 ID/EX

  if (ex_valid_i && ex_is_branch_i && ex_branch_taken_i) begin            // EX 阶段解析出条件 branch 成立
    redirect_valid_o = 1'b1;                                              // 真实 next PC 不是前面假设的顺序 PC
    redirect_pc_o    = ex_branch_target_i;                                // 跳到 branch target
    flush_if_id_o    = 1'b1;                                              // 清掉比 branch 年轻、已进入 IF/ID 的错路径指令
    flush_id_ex_o    = 1'b1;                                              // 清掉比 branch 年轻、已进入 ID/EX 的错路径指令
  end else if (ex_valid_i && ex_is_jalr_i) begin                          // JALR 一定跳，但 target 要等 rs1+imm 算出
    redirect_valid_o = 1'b1;                                              // JALR 也是 control redirect
    redirect_pc_o    = ex_jalr_target_i;                                  // target = (rs1 + imm) & ~1
    flush_if_id_o    = 1'b1;                                              // 清掉按旧 PC 取入的年轻指令
    flush_id_ex_o    = 1'b1;                                              // 清掉按旧 PC 推进的年轻指令
  end else if (id_valid_i && id_is_jal_i) begin                           // JAL 不需要比较寄存器，ID 阶段可较早确定 target
    redirect_valid_o = 1'b1;                                              // 发现无条件直接跳转
    redirect_pc_o    = id_jal_target_i;                                   // target = PC + immJ
    flush_if_id_o    = 1'b1;                                              // 阻止 IF 本拍按 PC+4 取到的年轻指令进入 IF/ID
    flush_id_ex_o    = 1'b0;                                              // JAL 自己仍要进入后级写 rd=PC+4，不能把自己清掉
  end
end
```

这段代码有三个关键点：

| 信号 | 作用 | 容易错的地方 |
|---|---|---|
| `redirect_valid_o` | 告诉 IF：下一拍 PC 要改成 `redirect_pc_o` | 只改 PC、不 flush 错路径指令 |
| `flush_if_id_o` | 清掉已经取入但不该执行的年轻指令 | 忘记用 valid/kill 门控副作用 |
| `flush_id_ex_o` | 清掉已经译码并进入 EX 前的错路径指令 | 对 ID 阶段 JAL 不能误清 JAL 自己 |

如果 branch 在 EX 才成立，那么 ID 阶段和 IF 阶段的年轻指令通常都可能是错路径，所以需要让 IF/ID、ID/EX 在下一拍写入 bubble。如果 JAL 在 ID 就解析出来，只有 IF 本拍按顺序路径取来的年轻指令需要被挡掉；JAL 自己还要继续向后执行并在 WB 写 `rd = PC+4`。实际项目会把“哪一级产生 redirect”和“哪些 pipeline register 比它年轻”做成明确规则。

实际设计还要处理：

- JAL/JALR redirect。
- trap redirect。
- interrupt redirect。
- cache miss stall 同时发生。
- IF 取指响应回来时是否属于被 kill 的旧请求。

### 8.7 flush/kill 的 RTL 实现：清 valid 与屏蔽副作用

从 RTL 角度看，flush/kill 不是把某条 instruction 从硬件里“删除”。pipeline register 本质上只是一组触发器，里面的 `pc`、`inst`、`rd`、控制信号在物理上仍然有 0/1 值。真正让一条指令失效的做法通常是：

1. 在对应 pipeline register 更新时把 `valid` 清 0，让它变成 bubble。
2. 对所有写寄存器、写 memory、写 CSR、提交 trace 等副作用使用 `valid` 或 `kill` 门控。
3. 如果有取指请求、cache miss、总线请求这类可能延迟返回的操作，用 `kill`、请求编号或 epoch 判断返回结果是否还属于当前路径。

因此，最入门的五级流水线可以先把 `flush` 理解成“下一拍把某些年轻 stage 的 `valid` 清 0”。例如 EX 阶段 branch taken 后，IF/ID 和 ID/EX 里的年轻指令都是错路径：

```text
cycle N:
  EX     : BEQ 发现 taken，产生 redirect_pc 和 flush
  ID     : I+1 是错路径
  IF     : I+2 是错路径

posedge N+1:
  PC     : 更新为 branch target
  IF/ID  : valid 清 0，I+2 被杀掉
  ID/EX  : valid 清 0，I+1 被杀掉
  EX/MEM : BEQ 自己继续向后流动
```

对应的 IF/ID pipeline register 可以写成这样：

```systemverilog
always_ff @(posedge clk or negedge rst_n) begin
  if (!rst_n) begin
    if_id_valid_q <= 1'b0;                            // reset 后前端没有有效指令
    if_id_pc_q    <= '0;                              // 调试字段清零，不代表真实 PC
    if_id_inst_q  <= 32'h0000_0013;                   // 可选写入 NOP，便于看波形
  end else if (flush_if_id_i) begin                   // branch/jump/trap 要清掉 IF/ID 年轻指令
    if_id_valid_q <= 1'b0;                            // 关键动作：valid=0，这条指令变成 bubble
    if_id_pc_q    <= if_id_pc_q;                      // PC/inst 可保持旧值，valid=0 时无架构意义
    if_id_inst_q  <= 32'h0000_0013;                   // 可选写 NOP，降低后级误用旧 opcode 的风险
  end else if (!stall_if_id_i) begin                  // 没有 stall 时，IF/ID 接收新取到的指令
    if_id_valid_q <= if_resp_valid_i;                 // 取指响应有效，才让 ID 看到真实指令
    if_id_pc_q    <= if_resp_pc_i;                    // PC 必须和 instruction 一起进入 IF/ID
    if_id_inst_q  <= if_resp_inst_i;                  // 后级 decode 的就是这条 instruction
  end                                                 // stall 时保持 IF/ID 不变
end
```

ID/EX 也类似，但它已经包含译码后的控制信号，所以 flush 时通常会同时把关键副作用控制信号清 0。严格来说，只要后面所有副作用都受 `valid` 门控，控制信号残留也不会改变架构状态；但工程上常把 `reg_we`、`mem_we`、`csr_we` 等一起清掉，波形更直观，也能降低误接线风险。

```systemverilog
always_ff @(posedge clk or negedge rst_n) begin
  if (!rst_n) begin
    id_ex_valid_q  <= 1'b0;             // reset 后 EX 前没有有效指令
    id_ex_reg_we_q <= 1'b0;             // 默认不允许写 GPR
    id_ex_mem_we_q <= 1'b0;             // 默认不允许写 data memory/MMIO
    id_ex_csr_we_q <= 1'b0;             // 默认不允许写 CSR
  end else if (flush_id_ex_i) begin     // 清掉已经译码但不该进入 EX 的错路径指令
    id_ex_valid_q  <= 1'b0;             // 关键动作：让 EX 下一拍看到 bubble
    id_ex_reg_we_q <= 1'b0;             // 防止后级误把旧 rd/control 当成真实写回
    id_ex_mem_we_q <= 1'b0;             // store 是外部副作用，flush 时必须关闭
    id_ex_csr_we_q <= 1'b0;             // CSR 写也属于架构副作用，必须关闭
  end else if (!stall_id_ex_i) begin    // 没有 stall 时，ID 指令正常进入 EX
    id_ex_valid_q  <= if_id_valid_q;    // ID/EX 的有效性来自 IF/ID
    id_ex_pc_q     <= if_id_pc_q;       // PC 跟随同一条指令传递
    id_ex_rs1_q    <= id_rs1_value_i;   // 源操作数进入 EX，供 ALU/branch 使用
    id_ex_rs2_q    <= id_rs2_value_i;   // store data 或第二个 ALU operand
    id_ex_rd_q     <= id_rd_i;          // 目的寄存器编号继续向后流动
    id_ex_reg_we_q <= id_reg_we_i;      // 是否写 GPR，由 decode 产生
    id_ex_mem_we_q <= id_mem_we_i;      // 是否 store，由 decode 产生
    id_ex_csr_we_q <= id_csr_we_i;      // 是否写 CSR，由 decode 产生
  end                                   // stall 时保持 ID/EX 不变
end
```

最后，还要在真正发生副作用的位置再门控一次。这样即使某个控制信号残留为 1，只要这条 instruction 已经被 flush/kill，就不会写出软件可见状态：

```systemverilog
assign dmem_we_o     = ex_mem_valid_q && !ex_mem_kill_q &&
                       ex_mem_mem_we_q && dmem_req_ready_i;               // 只有有效且未 kill 的 store 才能写 memory/MMIO

assign rf_we_o       = mem_wb_valid_q && !mem_wb_kill_q &&
                       mem_wb_reg_we_q && (mem_wb_rd_q != 5'd0);          // 只有有效且未 kill 的指令才能写 GPR

assign csr_we_o      = mem_wb_valid_q && !mem_wb_kill_q &&
                       mem_wb_csr_we_q;                                   // CSR 写必须同样受 valid/kill 保护

assign commit_valid_o = mem_wb_valid_q && !mem_wb_kill_q;                 // trace/scoreboard 只看真正提交的指令
```

这里的 `kill_q` 可以按设计复杂度选择是否真的做成一个独立 bit。简单五级流水线里，很多时候 `valid=0` 就已经等价于“这条指令被 kill”。更复杂的设计中，`kill` 常用来处理“指令或请求已经发出，但后来发现它属于旧路径”的情况，例如：

| 场景 | 为什么只清当前 pipeline register 不够 | 常见做法 |
|---|---|---|
| IF 请求已经发给 I-cache，总线响应晚几拍回来 | redirect 后返回的旧 instruction 可能已经不属于当前 PC 路径 | 给请求带 epoch/tag，响应回来时不匹配就丢弃 |
| store 已进入带缓冲的 memory path | 错路径 store 如果已经对 MMIO 可见，就无法撤销 | store 必须到确认可提交后才发出，或用 valid/kill 严格门控 |
| exception/trap 发生在较后级 | 更年轻指令可能已经在 IF/ID/ID/EX/EX/MEM 中 | trap redirect 时 flush younger stage，副作用只允许 older/exception instruction 产生 |

所以可以把实现原则压缩成一句话：**flush 负责把错路径的 pipeline slot 变成 bubble，kill/valid 负责保证这个 slot 后面即使还有残留信号，也不能产生任何架构副作用。**

---

## 第9章 Exception、Interrupt 与精确提交基础

### 9.0 本章概述

虽然本篇重点是五级流水线和 hazard，但一旦做 RISC-V CPU，exception 和 interrupt 无法完全回避。面试常追问：“如果流水线里同时有异常和分支，怎么办？”

先从硬件直觉看：exception 和 interrupt 都会让 CPU 暂停当前普通取指路径，转去执行 trap handler (异常中断处理函数)。区别在于，exception 通常是“当前这条指令自己执行时发现问题”，interrupt 通常是“外部或定时器等异步事件希望 CPU 尽快处理”。

| 事件 | 典型来源 | 硬件在哪一级可能发现 | 流水线要做什么 |
|---|---|---|---|
| illegal instruction | ID 译码发现 opcode/funct 组合不合法，或当前核不支持该扩展指令 | ID | 记录异常原因和该指令 PC，后续不应把它当普通指令执行 |
| instruction access fault (取指访问异常) | IF 取指访问的地址或总线返回错误 | IF | 把取指错误跟这条 PC 绑定，不能被后面译码错误覆盖 |
| load/store address misaligned (未对齐) | MEM 访问的数据地址不满足对齐要求，例如 word load 地址不是 4 字节对齐 | EX/MEM | 记录 fault address，阻止错误的访存副作用 |
| load/store access fault | 数据存储、MMIO、总线或权限检查返回访问错误 | MEM | 记录访问地址和原因，不能让后续 younger store 写出 |
| timer/external interrupt | 定时器、外设中断控制器、软件中断等 | 通常在 commit 边界采样并接受 | 当前指令边界进入 trap，flush younger instruction |

当某一级发现 exception 时，简单做法不是立刻把所有 CSR 都写掉，而是先把“这条指令发生了什么”作为异常信息放进 pipeline register，让它跟着这条 instruction 一起向后流动。这里的异常信息通常包括：

| 字段 | 含义 |
|---|---|
| `exception_valid` | 这条指令是否已经带着待处理异常 |
| `exception_cause` | 异常原因，例如 illegal instruction、load address misaligned |
| `exception_tval` | 附加调试值，常见是 fault address 或非法指令编码 |
| `exception_pc` | 触发异常的指令 PC，很多设计直接复用随流水线流动的 `pc` 字段 |
| `exception_is_interrupt` | 是否是 interrupt；简单五级核也可以把 interrupt 单独在 commit 边界处理 |

commit/retire 可以先理解成“这条指令正式被 CPU 承认为已经执行到软件可见边界”。一条普通 `ADD` 到 commit 时，写回 GPR 才算真正生效；一条 `SW` 到允许提交的位置时，store 才能对 memory/MMIO 产生不可撤销副作用；一条带 exception 的指令到 commit 时，CPU 不再按普通写回处理，而是写 EPC/cause/tval 等 CSR、flush 更年轻指令，并把 PC redirect 到 trap vector。后续 `0803` 会系统讲这些 CSR 和 trap 入口，本章只关心它们如何和流水线的 valid/kill/flush 配合。

进入 trap handler 后，后续程序是否继续执行不是流水线自己决定的，而是 trap handler 软件决定的。硬件只负责把现场交代清楚：`mepc/sepc` 记录触发 trap 的指令 PC，也就是后续 `MRET/SRET` 可能返回的位置；`mcause/scause` 记录原因，`mtval/stval` 记录附加信息，然后跳到 `mtvec/stvec` 指向的处理入口。

| 情况 | 流水线中的后续指令 | trap handler 处理完后通常怎样 |
|---|---|---|
| interrupt | 已经进入 IF/ID/ID/EX 的 younger instruction 会被 flush，避免它们在中断边界前产生副作用 | 处理完定时器或外设事件后执行 `MRET/SRET` (异常返回指令，负责 “从哪儿来回哪儿去”)，通常回到被打断位置继续执行 |
| illegal instruction 这类同步 exception | 异常指令后面的 younger instruction 必须 flush；异常指令自己不能再当普通指令写回 | 若程序错误，OS 可能杀进程，裸机可能进入错误处理；若 handler 能软件模拟这条指令，可以模拟效果后把 `mepc/sepc` 改到下一条指令再返回 |
| load/store access fault 或 page fault | fault 指令后面的 younger instruction 必须 flush，尤其不能让 younger store 写出 | OS 可能修复映射后重试同一条指令，也可能报告错误；是否重试取决于 handler 是否修改 `mepc/sepc` |

所以要区分两个“后续”：已经进入流水线的后续指令会被 flush/kill；程序代码里位于异常指令之后的后续指令，只有在 handler 选择返回并把 `mepc/sepc` 指到合适位置后，才可能重新被 IF 取出来执行。如果 illegal instruction 的 handler 不修改 `mepc/sepc` 就直接 `MRET/SRET`，CPU 会回到同一条非法指令并再次 trap。

这里还有一个很关键的边界：硬件不认识“函数还没执行完”或“这个函数后面的代码”。函数边界、调用栈和错误处理策略是软件概念；流水线只认识 PC 和已经进入各级的动态指令。因此 flush/kill 只杀掉“当时已经在流水线里、并且比异常指令更年轻”的那些 instruction。程序文本里更后面的 instruction 并不是永久作废，它们是否会执行，取决于 trap handler 最后让 PC 去哪里。

| handler 最后的选择 | 返回后的取指位置 | 原程序后续代码是否可能执行 |
|---|---|---|
| 保持 `mepc/sepc` 指向异常指令 | 回来重试同一条 instruction | 若异常原因被修复，后续代码会重新取指执行；若没修复，会再次 trap |
| 把 `mepc/sepc` 改成下一条 instruction | 跳过或软件模拟异常指令后继续 | 下一条及更后面的代码可能继续执行 |
| 改到错误处理函数或退出路径 | 从新的 PC 开始执行 | 原来顺序路径上的后续代码通常不再执行 |
| 不返回，例如 OS 杀进程、裸机停机 | 不再回到原程序 | 原程序后续代码不会执行 |

### 9.1 precise exception

precise exception 要求异常看起来发生在某一条指令边界：

- 异常指令之前的指令都已完成。
- 异常指令之后的指令都没有改变架构状态。
- trap handler 能看到一致的状态。

precise exception 不是一种新的异常原因，而是 CPU 处理异常时必须满足的效果。比如下面这段指令中，`LW` 的地址非对齐：

```asm
ADD  x3, x1, x2
LW   x5, 2(x10)     # 假设 x10 为 0x1000，则访问 0x1002，word load 非对齐
ADD  x6, x5, x7
SW   x6, 0(x11)
```

当 `LW` 到 EX/MEM 计算出有效地址后，硬件发现 `0x1002` 不是 4 字节对齐地址，于是给这条 `LW` 标上 `exception_valid=1`，`exception_cause=load address misaligned`，`exception_tval=0x1002`。为了做到 precise exception，`ADD x3` 作为 older instruction 可以正常提交；`LW` 自己进入 trap 流程；后面的 `ADD x6` 和 `SW` 即使已经被取指、译码，甚至进入了前面几个 stage，也必须被 flush/kill，不能写 `x6`，更不能真的执行 store。

简单顺序五级流水线相对容易实现 precise exception，因为指令按顺序进入 WB/commit。只要所有架构副作用都集中在受 valid/kill 门控的提交边界，硬件就能在“最老的待处理异常指令”处切开流水线。

从提交视角看，precise exception 可以理解成一条边界：

```text
older instructions    exception instruction    younger instructions
已经提交或允许提交       记录异常并进入 trap       必须被 kill，不能产生副作用
```

这和 branch flush 很像，但语义更严格。branch flush 只是控制流恢复；exception flush 还要保证异常原因、异常 PC、访问地址等状态与触发异常的那条指令绑定，不能被更年轻的指令覆盖。

### 9.2 不同 stage 的异常

可能异常：

| stage | 异常示例 |
|---|---|
| IF | instruction address misaligned、instruction access fault |
| ID | illegal instruction |
| EX | branch/jump target misaligned |
| MEM | load/store address misaligned、access fault |
| WB | 通常提交状态，异常应已确定 |

异常信息要随指令在 pipeline register 中流动，不能丢失或和别的指令混淆。

一个常见做法是在 pipeline register 中携带异常字段：

```text
valid
pc
inst
exception_valid
exception_cause
exception_tval
```

如果 IF 阶段已经发现 instruction access fault，这条指令后续即使不再需要正常执行 ALU，也要把异常信息一路带到接受 trap 的位置。否则 ID 阶段重新译码出 illegal instruction，可能错误覆盖更早、更应该优先报告的 IF 异常。

异常优先级通常按“同一条指令内部的规范优先级”和“流水线中指令年龄”共同决定。简单顺序核里，older instruction 的异常应优先于 younger instruction；同一条指令如果已经有更早 stage 的异常，后级通常不应再发起会产生副作用的动作。

### 9.3 flush younger instruction

当某条指令产生 exception 并被接受：

- older instruction 应已经提交或继续提交。
- exception instruction 进入 trap 流程。
- younger instruction 必须 flush。
- PC redirect 到 trap vector。

这要求所有 younger stage 的 side effect 都受 valid/kill 控制。例如 MEM 阶段一条 load/store 发现 access fault，同时 IF/ID 里已经取入了后续 store；trap redirect 必须清掉这条 younger store，且它不能向 data memory 发起写请求。

### 9.4 interrupt 的特殊性

interrupt 是异步事件，不是当前 instruction 自己执行造成的。为了 precise exception，简单设计通常在指令边界接受 interrupt。

常见策略：

- 在 WB/commit 边界检查 pending interrupt。
- 当前指令提交后进入 trap。
- flush younger instruction。

更复杂设计会有更细的优先级和屏蔽规则，这应放到 `0803` 继续展开。

### 9.5 commit/retire 信息

为了验证和 debug，建议顺序核产生 commit trace：

```text
commit_valid
commit_pc
commit_inst
commit_rd
commit_wdata
commit_mem_addr
commit_mem_we
commit_exception
```

reference model 可以逐条比对 commit 信息，定位第一条错误提交。

---

## 第10章 系统 OS、裸机运行时与流水线的接口

### 10.0 为什么这里要提 OS

本篇的主线仍然是 CPU pipeline，不是操作系统实现。但只要 CPU 要放进 SoC 里运行裸机程序、RTOS 或 Unix-like OS，流水线里的很多控制动作都会直接变成系统软件能观察到的行为。

这里先给一个总览，后续文档会在对应硬件位置分散展开。这样做的边界是：数字 IC 学习需要理解 OS/运行时如何使用硬件接口，不需要在这里深入调度器、文件系统或完整内核实现。

| 系统软件场景 | 对流水线意味着什么 | 后续在哪里展开 |
|---|---|---|
| reset 后启动裸机 runtime | IF 必须从 reset vector (复位向量)取到第一条有效指令，异常/中断通常先关闭 | `0804` 的 boot ROM、memory map、linker script |
| trap handler 处理异常/中断 | exception instruction 要精确记录 EPC/cause/tval，younger instruction 要 flush | `0803` 的 CSR、trap entry、MRET/SRET |
| driver 访问 MMIO 外设 | load/store 可能访问慢外设，MEM 阶段可能 stall，也可能产生 access fault | `0804` 的 MMIO、bus、PLIC/CLINT |
| OS 使用虚拟内存 | IF/MEM 访问可能经历 TLB/MMU，TLB miss、page fault 会反向影响流水线 | `0805` 的 TLB、MMU、page table、page fault |
| driver 或内核使用 FENCE (内存屏障) | store buffer、cache、MMIO 顺序不能只按普通 ALU 指令理解 | `0805` 的 memory model、FENCE、device memory |

### 10.1 什么是 OS

OS 可以先通俗理解成“替所有应用程序管理整台机器的那层核心软件”。如果没有 OS，程序通常就是裸机程序：reset 后 CPU 跳到某个固定地址，从那里开始执行一段代码，这段代码自己初始化栈、自己配置外设、自己决定什么时候读写内存和寄存器。单片机里常见的裸机主循环、简单中断服务函数，就接近这种模型。

有了 OS 以后，普通应用一般不能直接控制整台机器。应用想读文件、申请内存、收发网络、等待定时器、访问屏幕或磁盘，通常要通过系统调用进入内核；内核再用更高的 privilege、页表、驱动和中断机制去管理硬件资源。这样做的目标不是让 CPU 算得更快，而是让多个程序能安全、稳定、可恢复地共享 CPU、内存和外设。

| 视角 | 没有 OS 的裸机程序 | 有 OS 的系统 |
|---|---|---|
| 谁拥有硬件 | 当前程序基本直接拥有 CPU、内存和外设 | OS 内核统一管理，应用通过系统调用请求服务 |
| 出错怎么办 | 常见做法是停机、复位、进入错误循环或由项目自定义处理 | OS 根据异常原因杀进程、发信号、修复 page fault、记录错误或重启服务 |
| 中断给谁处理 | 中断服务函数通常就是项目代码的一部分 | 先进入内核/驱动，再决定唤醒哪个任务、更新哪个设备状态 |
| 内存怎么用 | 程序通常直接使用物理地址或固定链接地址 | OS 用虚拟内存隔离进程，并通过页表控制权限和映射 |
| 对 CPU 硬件的要求 | 能启动、能执行指令、能响应必要中断即可 | 还需要可靠的 trap、CSR、权限、MMU/TLB、cache/MMIO 顺序等机制 |

从 CPU 流水线角度看，OS 不是一个神秘的软件概念，而是一类会频繁使用硬件边界的程序：它会靠 trap 进入内核，靠 `MRET/SRET` 返回，靠 page fault 发现缺页或权限错误，靠 timer interrupt 获得调度机会，靠 MMIO driver 控制外设。因此数字 IC 学习不需要在这里实现完整 OS，但需要知道 OS 会怎样观察和依赖 CPU 的精确异常、提交边界、访存顺序和中断行为。

### 10.2 OS 是软件，硬件提供机制

OS 本质上是软件。它和普通应用一样，最终也会变成 instruction，放在存储器里，由 CPU 一条条取指、译码、执行。区别在于，OS 内核运行在更高 privilege，能访问普通应用不能访问的 CSR、页表和外设控制寄存器。

可以把关系压成三层：

```text
硬件：提供机制
  privilege、CSR、trap、中断、MMU、MMIO、timer

OS：使用这些机制
  调度任务、管理内存、处理中断、驱动外设、隔离进程

应用程序：向 OS 请求服务
  读文件、申请内存、创建线程、访问网络
```

所以不能说“OS 在硬件上实现”。更准确的说法是：**OS 用软件实现，硬件实现 OS 所依赖的控制机制**。如果这些机制不可靠，OS 就无法判断哪条指令出错、从哪里返回、哪些寄存器和内存已经真的改变。

| OS 想做的事 | 硬件要提供什么 | 和流水线的关系 |
|---|---|---|
| 不让普通应用乱改外设、页表和中断 | privilege level、CSR 访问权限 | ID/EX 需要检查权限，非法访问要产生 precise exception |
| 应用进入内核请求服务 | `ECALL` 触发 trap | 记录 EPC/cause，flush younger instruction，redirect 到 trap vector |
| 定时切换任务 | timer interrupt | 在指令边界接受 interrupt，保证被打断现场精确 |
| 外设通知 CPU | external interrupt、中断控制器 | 异步信号进入 CPU 后，要按优先级和屏蔽规则接受 |
| 每个进程看到自己的地址空间 | MMU、TLB、page table、page fault | IF/MEM 访问可能产生 page fault，需要精确记录 fault PC/address |
| 驱动访问外设寄存器 | MMIO、bus、memory map | load/store 可能有外部副作用，必须受 valid/kill 和顺序规则约束 |

### 10.3 RISC-V 里 OS 依赖哪些机制

放到 RISC-V 语境下，OS 相关机制不是一条单独指令，而是一组软硬件接口。不同级别的系统需要的集合不同：裸机程序可能只需要 M-mode、基本 trap 和 timer；RTOS 常需要稳定的中断和上下文切换；Linux 这类 Unix-like OS 通常还需要 S-mode、U-mode、MMU、TLB、外部中断控制器和原子操作。

| RISC-V 机制 | OS 怎么用 | 后续文档位置 |
|---|---|---|
| M/S/U privilege | M-mode 管底层机器资源，S-mode 常运行内核，U-mode 运行普通应用 | `0803` 特权级与 CSR |
| `mstatus/sstatus` | 保存 trap 前的中断使能和特权级返回信息 | `0803` trap 状态栈 |
| `mtvec/stvec` | 指定异常、中断、系统调用进入哪段 handler | `0803` trap entry |
| `mepc/sepc` | 记录 trap 返回 PC，handler 可选择重试、跳过或改走错误路径 | `0803` trap 返回 |
| `mcause/scause`、`mtval/stval` | 告诉 handler 为什么 trap，以及 fault address/非法指令等细节 | `0803` 异常原因 |
| `ECALL`、`MRET/SRET` | `ECALL` 让应用进入内核，`MRET/SRET` 从 trap handler 返回 | `0803` 系统调用与返回 |
| CLINT/PLIC 或平台中断控制器 | 提供 timer、software、external interrupt 来源 | `0804` SoC 与外设互联 |
| MMU/TLB/page table | 支持虚拟地址、进程隔离、权限检查和 page fault | `0805` MMU/TLB |
| atomic/FENCE | 支持锁、同步和 MMIO/cache 顺序约束 | `0805` 内存模型 |

对本篇流水线来说，最核心的交叉点仍然是：RISC-V OS 依赖硬件在正确的指令边界上记录 `xepc/xcause/xtval`、更新状态、flush younger instruction，并保证被 kill 的指令不会写 GPR、memory、CSR 或 MMIO。

### 10.4 从软件栈看 CPU 硬件边界

可以把系统软件和流水线的连接压成一条链：

```text
启动代码 / OS / driver
  -> instruction fetch、load/store、CSR instruction、FENCE
  -> pipeline stage、hazard control、commit/retire
  -> trap/MMIO/cache/TLB/bus 等硬件行为
  -> 软件看到返回值、异常、中断或外设状态变化
```

软件不会看见 `IF/ID`、`ID/EX` 这类 pipeline register，但会看见它们控制是否正确带来的结果：PC trace 是否对、寄存器写回是否对、异常是不是精确、MMIO 写有没有重复或丢失、TLB 旧项有没有被清掉。

### 10.5 学到什么程度就够

对数字 IC/CPU/SoC 岗位，更合适的目标不是“会写完整 OS”，而是能把下面几件事讲成软硬件闭环：

| 需要了解的系统 OS/运行时内容 | 为什么数字 IC 需要懂 |
|---|---|
| reset vector、启动汇编、栈初始化、`.bss` 清零 | 判断 CPU 复位后是否能取到第一条指令，debug 启动卡死问题 |
| trap handler 保存/恢复现场 | 理解硬件只保存 EPC/cause/status，GPR 现场通常由软件保存 |
| MMIO driver 读写外设寄存器 | 理解 load/store 为什么会变成外设副作用，以及为什么 device memory 不能随便 cache |
| timer/external interrupt | 理解异步事件如何进入流水线提交边界，再跳到 handler |
| page table、TLB、page fault | 理解 OS 为什么要 MMU，以及硬件为什么要产生精确异常 |
| FENCE 和内存顺序 | 理解 store buffer、cache、DMA、MMIO 之间的可见顺序 |

不需要在本系列主线里深入文件系统、shell、复杂调度策略、Linux 驱动框架或完整内核工程。它们属于系统软件专题；本系列只把它们当作硬件接口的使用者。

### 10.6 一个统一判断原则

遇到 OS/裸机软件相关问题时，可以先问一句：

```text
软件依赖的状态，是否在正确的指令边界上变得可见？
```

这句话能统一很多看似分散的问题：

- branch/JALR：错路径指令不能写 GPR 或发出 MMIO store。
- exception：异常指令之前的结果可见，之后的 younger instruction 不可见。
- interrupt：异步事件通常在指令边界被接受，不能把一条指令执行到一半暴露给 handler。
- MMIO：store 一旦对外设可见，就可能触发真实动作，必须受 valid/kill 和顺序规则约束。
- TLB/page fault：OS 看到的 EPC、fault address 和权限原因必须和触发访问对应。
- FENCE：软件要求“之前的访存已经到达规定可见点”，硬件不能只把它当普通 NOP。

因此，系统 OS 视角不是额外背一套软件知识，而是提醒我们：CPU 流水线的每个 redirect、flush、stall、commit 和 side-effect gating，最后都要落到软件可见行为正确。

---

## 第11章 RTL 控制骨架

### 11.0 本章概述

本章给出五级流水线控制的骨架。真实 CPU 代码会更复杂，但核心动作离不开：

- PC write enable。
- IF/ID write enable。
- ID/EX flush。
- forwarding select。
- branch/trap redirect。
- memory stall。

### 11.1 load-use interlock 控制

```systemverilog
always_comb begin
  pc_en        = 1'b1;
  if_id_en     = 1'b1;
  if_id_flush  = 1'b0;
  id_ex_flush  = 1'b0;

  if (trap_redirect) begin
    if_id_flush = 1'b1;
    id_ex_flush = 1'b1;
  end else if (branch_redirect) begin
    if_id_flush = 1'b1;
    id_ex_flush = 1'b1;
  end else if (load_use_stall) begin
    pc_en       = 1'b0;
    if_id_en    = 1'b0;
    id_ex_flush = 1'b1;
  end
end
```

这段代码体现优先级：

```text
trap > branch > load-use stall
```

实际项目中还要加入 memory stall、debug halt、reset 等条件。

### 11.2 forwarding operand MUX

```systemverilog
always_comb begin
  unique case (fwd_a_sel)
    FWD_EX_MEM: alu_op_a = ex_mem_forward_data;
    FWD_MEM_WB: alu_op_a = mem_wb_forward_data;
    default:    alu_op_a = id_ex_rs1_value;
  endcase

  unique case (fwd_b_sel)
    FWD_EX_MEM: alu_op_b_raw = ex_mem_forward_data;
    FWD_MEM_WB: alu_op_b_raw = mem_wb_forward_data;
    default:    alu_op_b_raw = id_ex_rs2_value;
  endcase

  alu_op_b = id_ex_alu_src_imm ? id_ex_imm : alu_op_b_raw;
end
```

注意：

- rs2 的前递值可能用于 ALU，也可能用于 store data。
- 如果 ALU 第二操作数选择 immediate，rs2 前递不应影响 ALU，但可能仍影响后续 store data。

### 11.3 valid bit 与副作用屏蔽

所有会改变架构状态或外部状态的动作，都应受 valid bit 控制：

```systemverilog
assign rf_we_o  = mem_wb_valid_q && mem_wb_reg_we_q && (mem_wb_rd_q != 5'd0);
assign dmem_we_o = ex_mem_valid_q && ex_mem_mem_we_q;
```

否则 flush 出来的无效指令可能仍然写 register file 或 memory。

### 11.4 PC 选择优先级

PC next 选择常见优先级：

```text
reset vector
trap vector
branch/jump redirect
predicted next PC
pc + 4
```

如果 IF stage 因 memory stall 不能接受新 PC，则 redirect 需要被保存或让前级控制确保 PC 更新不会丢。

---

## 第12章 验证方法

### 12.0 本章概述

五级流水线验证的核心是同时证明两件事：

1. ISA 可见结果正确。
2. 微架构控制在 hazard、stall、flush 下不会丢指令、重复提交或错误写状态。

### 12.1 directed test

必须覆盖：

| 类别 | 例子 |
|---|---|
| ALU-ALU RAW | `ADD x5,...` 后立即 `SUB ...,x5,...` |
| load-use | `LW x5,...` 后立即使用 x5 |
| store data forwarding | `ADD x5,...` 后 `SW x5,...` |
| branch data hazard | 比较寄存器来自上一条指令 |
| branch taken flush | taken 后错路径不能写回 |
| branch not taken | 不应错误 flush |
| x0 相关 | 写 x0 后依赖 x0 不应 forwarding/stall |
| back-to-back load | 连续 load 和依赖使用 |
| memory stall | load 等待多拍 |
| exception flush | illegal instruction 后 younger 指令不能提交 |

### 12.2 random test 与 ISS 比对

random test 可以发现 directed test 想不到的组合，例如：

- forwarding 和 branch flush 同时出现。
- load-use stall 后紧跟 exception。
- store data forwarding 与 memory stall 重叠。
- 写 x0 和 RAW 检测重叠。

比对方式：

- DUT 产生 commit trace。
- ISS 执行同一条 instruction。
- scoreboard 比对 PC、rd、wdata、memory side effect、exception。

### 12.3 SVA 断言示例

#### 11.3.1 flush 后无效指令不能提交

```systemverilog
// 不可综合：验证断言
property p_flush_kills_if_id;
  @(posedge clk) disable iff (!rst_n)
    flush_if_id |=> !if_id_valid_q;
endproperty

assert property (p_flush_kills_if_id);
```

#### 11.3.2 写 x0 不改变架构状态

```systemverilog
// 不可综合：验证断言
property p_x0_zero_at_commit;
  @(posedge clk) disable iff (!rst_n)
    commit_valid |-> (rf_x0_value == '0);
endproperty

assert property (p_x0_zero_at_commit);
```

#### 11.3.3 load-use 需要 interlock

```systemverilog
// 不可综合：验证断言，信号名仅示意
property p_load_use_stall;
  @(posedge clk) disable iff (!rst_n)
    id_ex_valid_q && id_ex_is_load_q && (id_ex_rd_q != 5'd0) &&
    if_id_valid_q &&
    ((if_id_uses_rs1 && (if_id_rs1 == id_ex_rd_q)) ||
     (if_id_uses_rs2 && (if_id_rs2 == id_ex_rd_q)))
    |-> load_use_stall;
endproperty

assert property (p_load_use_stall);
```

### 12.4 coverage

功能覆盖建议：

- RAW 距离：相邻、隔一条、隔两条。
- 源操作数：rs1 命中、rs2 命中、二者都命中。
- forwarding 来源：EX/MEM、MEM/WB。
- 目的寄存器：x0、普通寄存器、ABI 常用寄存器。
- load-use 指令类型：ALU、branch、store。
- branch：taken、not taken、正偏移、负偏移。
- flush 与 stall 同时出现。
- memory stall 长度：0、1、多拍。
- exception stage：IF、ID、MEM。

### 12.5 波形 debug 观察点

建议波形里长期保留：

```text
if_pc, if_inst, if_valid
id_pc, id_inst, id_valid, id_rs1, id_rs2, id_rd
ex_pc, ex_inst, ex_valid, alu_op_a, alu_op_b, alu_result
mem_pc, mem_inst, mem_valid, dmem_req, dmem_we, dmem_addr
wb_pc, wb_inst, wb_valid, rf_we, wb_rd, wb_data
stall, flush, branch_redirect, trap_redirect
fwd_a_sel, fwd_b_sel
commit_valid, commit_pc, commit_inst
```

debug 时先找第一条 commit mismatch，再往前看 hazard 控制。

---

## 第13章 常见 bug、面试问法与练习题

### 13.0 常见 bug

| bug | 表现 | 修复方向 |
|---|---|---|
| forwarding 忘记排除 x0 | 依赖 x0 的指令得到错误值 | 命中条件加 `rd != 0` |
| EX/MEM 与 MEM/WB 优先级反了 | 连续写同一 rd 后读到旧值 | 更近的 EX/MEM 优先 |
| load 当成 ALU 结果前递 | load-use 得到地址而非数据 | load-use stall，load data 到 WB 再前递 |
| IF/ID stall 时 ID/EX 未 bubble | 同一指令重复进入 EX | stall 时插入 bubble |
| branch flush 没清写使能 | 错路径指令写回 | valid bit 屏蔽所有副作用 |
| store data 未前递 | store 写旧数据 | 加 store data forwarding |
| register file 同拍读写语义不一致 | 仿真过，综合后错 | 显式 WB forwarding 或固定宏行为 |
| memory stall 时前级覆盖指令 | 丢指令 | valid-ready 或全局 backpressure |
| flush 与 stall 优先级错 | 跳转后卡死或执行错路径 | 明确优先级并写断言 |
| exception 后 younger 指令提交 | 非精确异常 | exception flush younger instruction |

### 13.1 高频面试问法

#### 问题1：五级流水线每一级做什么

简洁答案：

```text
IF 取指并产生 next PC，ID 译码和读寄存器，EX 做 ALU、分支判断和地址计算，
MEM 访问数据存储器，WB 把结果写回寄存器堆。
```

深入追问：

```text
控制信号要在 ID 生成并跟随指令经过 ID/EX、EX/MEM、MEM/WB。
如果某级 stall 或 flush，数据和控制都必须一起保持或清空。
```

#### 问题2：pipeline 提高了什么

答案要点：

- 主要提高 throughput。
- 理想单发射流水线填满后每 cycle 完成一条指令。
- 单条指令 latency 不一定降低，通常是多个 cycle。
- Fmax 可能提高，因为 critical path 被切短，但 pipeline register 也有开销。

#### 问题3：三类 hazard 是什么

答案要点：

- structural hazard：资源冲突。
- data hazard：数据依赖导致读到旧值。
- control hazard：PC 流向不确定或预测错误。

#### 问题4：forwarding 解决什么问题

简洁答案：

```text
forwarding 把后面 stage 已经产生但还没写回寄存器堆的结果，直接送到前面消费者指令的操作数输入，减少 RAW stall。
```

深入追问：

```text
典型路径有 EX/MEM 到 EX、MEM/WB 到 EX。命中条件要检查 valid、reg_we、rd != x0、rd 等于消费者 rs1/rs2。
如果 EX/MEM 和 MEM/WB 同时命中，应选择更年轻的 EX/MEM。
```

#### 问题5：load-use hazard 为什么 forwarding 不够

答案要点：

- load 的数据通常在 MEM 阶段末尾才从 memory 返回。
- 紧随其后的消费者在同一 cycle 的 EX 阶段早些时候就需要操作数。
- 数据还没产生，无法前递。
- 需要 stall 一拍并插入 bubble，下一拍从 MEM/WB 前递。

#### 问题6：branch taken 时怎么处理

答案要点：

- 如果默认取 `pc + 4`，branch taken 后前面已经取入的顺序指令是错路径。
- branch 在 EX 决策时，需要 redirect PC 到 branch target。
- 同时 flush IF/ID 和 ID/EX 中 younger wrong-path instruction。

#### 问题7：flush 和 stall 同时发生怎么办

答案要点：

- 先明确二者对应的 stage 和指令年龄。
- trap/exception redirect 通常优先级最高，其次 branch redirect，再考虑普通 data stall。
- 错路径 younger instruction 必须被 kill。
- 正确路径上的 older instruction 不能被覆盖。

### 13.2 练习题

#### 练习1：画 load-use 时序

题目：

```text
LW x5, 0(x1)
ADD x6, x5, x2
```

画出需要插入 bubble 后的五级流水线。

答案：

```text
cycle:  1   2   3   4   5   6   7
LW:     IF  ID  EX  MEM WB
ADD:        IF  ID  ID  EX  MEM WB
bubble:             EX
```

#### 练习2：写 forwarding 条件

题目：

```text
EX 阶段指令 rs1 需要前递，写出从 EX/MEM 前递的条件。
```

答案要点：

```text
ex_mem_valid &&
ex_mem_reg_we &&
ex_mem_rd != 0 &&
ex_mem_rd == id_ex_rs1 &&
ex_mem_forward_data 已经可用
```

#### 练习3：判断是否需要 stall

题目：

```text
LW  x0, 0(x1)
ADD x2, x0, x3
```

是否需要 load-use stall？

答案：

不需要。x0 恒为 0，load 写 x0 无效，后续读 x0 应得到 0，不依赖 load 返回数据。

#### 练习4：连续写同一寄存器后读取

题目：

```text
ADD x5, x1, x2
SUB x5, x3, x4
OR  x6, x5, x7
```

OR 应该使用哪个结果？

答案：

OR 应使用 SUB 写入 x5 的结果，因为 SUB 比 ADD 更年轻，且在程序顺序上最后一次写 x5。forwarding 优先级应选择更近的 EX/MEM，而不是 MEM/WB 中更老的 ADD。

#### 练习5：branch flush 副作用

题目：

```text
BEQ x1, x1, target
ADD x5, x2, x3
target:
SUB x6, x4, x7
```

如果 branch 在 EX 才判断，ADD 可能已经进入 pipeline。应该如何处理？

答案要点：

- BEQ 一定 taken。
- ADD 是错路径 younger instruction。
- branch redirect 时应 flush ADD 所在的 IF/ID 或 ID/EX。
- ADD 不能写 x5。

## 第14章 与其他章节的关联

### 14.0 必须回看的章节

- `0801 RISC-V ISA基础.md`：本篇所有 hazard 处理都服务于 ISA 语义，尤其是 x0、立即数、branch/JAL/JALR、load/store 和 exception。
- `0803 CSR、异常中断与特权级.md`：trap、interrupt、CSR 写入和 xRET 都会变成特殊的 flush、redirect 和提交边界问题。
- `0804 RISC-V SoC、MMIO与外设互联.md`：MEM 阶段的 load/store 可能访问 SRAM、cache、MMIO 或慢外设，memory stall 和 bus error 会反向影响 pipeline 控制。
- `0805 Cache、TLB、MMU、分支预测与内存模型.md`：I-cache/D-cache miss、TLB miss、branch prediction 和 FENCE 会把简单五级流水线扩展成更真实的处理器前端/访存系统。
- `0806 高级微架构基础：乱序、ROB与执行后端.md`：乱序核仍然保留本篇的核心问题，但用 rename、ROB、IQ、LSQ 等结构处理更复杂的 hazard。

### 14.1 和基础专题的关系

- `030x` 流水线与握手：valid、ready、stall、bubble、flush 是通用 pipeline 控制，不只用于 CPU。
- `040x` 运算数据通路：EX 阶段的 ALU、branch comparator、乘除法单元会直接影响 forwarding 和多周期 stall。
- `060x` 存储器/cache：MEM 阶段的 SRAM、cache、byte enable、load 扩展会决定 load-use 和 memory stall 行为。
- `100x` 验证专题：五级流水线必须用 directed test、random test、ISS 比对、SVA 和 coverage 形成闭环。
- `130x` STA 专题：ID decode、forwarding MUX、branch redirect、load-use detection 都可能成为时序热点。

### 14.2 学习路径建议

本篇是从 ISA 走向 CPU 微架构的第一步。推荐按下面路径复习：

```text
先用 0801 明确每条指令最终应该改变什么
再用 0802 理解重叠执行为什么会出错、如何修正
然后用 0803/0804/0805 补齐 trap、SoC、cache/TLB/预测
最后用 0806 理解乱序核如何把同样问题推广到更大窗口
```

如果面试项目是五级流水线核，至少要能把本篇的 forwarding、load-use、branch flush、valid side effect gating 和 commit trace 讲成一个完整闭环。

## 第15章 从这里开始上手一个 RISC-V 最小教学核

看到这里，已经可以开始做一个 RISC-V 教学核项目了。更准确地说：如果目标是“用项目把 0801 和 0802 的知识落到 RTL”，现在就应该开始；如果目标是一上来就做能跑 OS、带 cache、带 MMU、带中断控制器的 SoC，那还需要继续学 0803～0805。

如果准备把本章内容真正落成一个 RV32I 最小教学核项目，具体设计流程、实现路线和后续分册规划可以继续阅读 `0820 RISC-V最小教学核设计流程与方案.md` 及 `082x` 系列文档。

教学核第一版不要追求“像真实商业 CPU 一样完整”，而要追求“边界清楚、能跑程序、能验证、能讲清每个 hazard 为什么这样处理”。推荐的第一版目标如下：

| 维度 | 第一版建议 | 为什么这样定 |
|---|---|---|
| ISA 范围 | RV32I 基础整数指令，先不做 M/C/A/F/D 扩展 | RV32I 已经覆盖译码、GPR、ALU、branch、JAL/JALR、load/store 和 x0，足够训练 CPU 主干 |
| 微架构 | 单发射、顺序执行、经典五级流水线 | 与本文内容直接对应，面试也容易讲清楚 |
| hart 数量 | 单 hart | 避免一开始引入多核一致性、原子操作和跨核中断 |
| 存储系统 | 分离 instruction memory 和 data memory，先用 1 cycle SRAM 模型 | 先绕开 cache miss、总线等待和 MMIO 慢响应，把 pipeline hazard 练扎实 |
| privilege/CSR | 第一版可以不实现 CSR、trap、interrupt | 最小教学核可以先只跑裸机测试；0803 的内容放到第二阶段 |
| SoC/外设 | 第一版不接复杂总线，只保留简单 imem/dmem 接口 | 0804 的 MMIO、bridge、UART、timer 可以等核心稳定后再加 |
| cache/MMU | 第一版不做 cache、TLB、MMU | 0805 是真实 CPU/SoC 绕不开的内容，但不是第一个教学核的启动条件 |
| 软件形态 | 裸机汇编或很小的 C 程序 | 不依赖 OS，不需要系统调用、页表和中断返回 |

这里的“最小”不是只能做玩具。一个设计干净的 RV32I 五级流水线核，已经能体现数字 IC 岗位非常看重的能力：能从 ISA 语义拆出 datapath，能写可综合 RTL，能处理 stall/flush/forwarding，能用 directed test 和 reference model 验证，能从波形解释 bug。

建议把项目分成下面几个里程碑，而不是一口气写完整 CPU。

| 阶段 | 目标 | 关键验收点 |
|---|---|---|
| 0. 搭环境 | 能编译 RTL、加载指令 memory、看波形、打印 commit trace | 仿真能跑一个 `ADDI; ADD; SW` 级别的小程序 |
| 1. 单周期或非流水骨架 | 先把 RV32I 指令语义跑通，作为后续流水线的对照 | x0 不变、立即数正确、ALU/branch/load/store 基本正确 |
| 2. 五级流水空壳 | 建 IF/ID/EX/MEM/WB pipeline register 和 valid bit | 指令能按五级流动，bubble 不产生写寄存器和写 memory 副作用 |
| 3. 完整基本数据通路 | 接好 decoder、regfile、imm_gen、ALU、LSU、writeback | 不考虑复杂相关时，顺序程序结果正确 |
| 4. data hazard | 加 EX/MEM、MEM/WB 到 EX 的 forwarding | 连续 `ADD`、`SUB`、`OR` 这类 ALU 相关不需要 stall |
| 5. load-use hazard | 加 load-use 检测和 bubble 插入 | `LW` 后紧跟使用者时结果正确，且只停必要的拍数 |
| 6. control hazard | 加 branch/JAL/JALR redirect 和 flush/kill | taken branch 后错路径指令不能写 GPR，也不能真的 store |
| 7. 验证收敛 | directed test、随机指令、commit trace 比对、基础断言 | 能定位“第几条提交指令”开始和参考模型不一致 |
| 8. 第二阶段扩展 | 再考虑 CSR/trap、MMIO timer/UART、总线或 cache | 每加一类系统功能，都有明确的测试和回归入口 |

如果你担心“一上来写五级流水线太复杂”，可以先写一个非常小的单周期 RV32I 核作为 golden model。它不一定用于最终综合，只用于帮助你确认 decode、immediate、ALU、load/store 扩展和 branch target 是否正确。等单周期版本能跑通一批基础测试，再把同样的 ISA 语义搬到五级流水线里。这样做的好处是：遇到错误时，你能区分“指令语义本身错了”还是“流水线控制错了”。

一个比较清晰的最小模块拆分可以是：

| 模块 | 主要职责 |
|---|---|
| `core_top` | 连接各 stage、imem/dmem 接口、全局 stall/flush 控制 |
| `if_stage` | 保存 PC，发起取指，计算默认 `PC+4` |
| `id_stage` | decode、读 GPR、生成 immediate 和控制信号 |
| `ex_stage` | ALU、branch compare、branch/JAL/JALR target 计算 |
| `mem_stage` | load/store 请求、byte enable、load 数据符号/零扩展 |
| `wb_stage` | 选择 ALU/load/`PC+4` 写回数据 |
| `regfile` | 32 个 GPR，保证 x0 恒为 0 |
| `decoder` / `imm_gen` | 从 instruction 生成类型、控制信号和立即数 |
| `forwarding_unit` | 根据 `rs1/rs2`、后级 `rd`、后级 write enable 选择前递数据 |
| `hazard_unit` | 检测 load-use、memory stall、flush 优先级 |
| `pipe_reg_*` | 保存每级之间的数据、控制信号、valid 和异常/调试信息 |
| `simple_rom` / `imem` | 第一版 instruction memory 模型，仿真时由 `$readmemh` 初始化，CPU 只读 |
| `simple_ram` / `dmem` | 第一版 data memory 模型，支持 load 读和 store 按 byte enable 写 |
| `commit_trace` | 仿真时打印提交 PC、instruction、rd、wdata，便于和参考模型比对 |

代码量只能粗略估计，因为风格差异很大，但可以用下面范围建立预期：

| 项目形态 | 大致 RTL 代码量 | 说明 |
|---|---:|---|
| 极简单周期 RV32I | 约 600～1200 行 | 适合作为语义验证起点，不体现 pipeline hazard |
| 干净的五级流水 RV32I 核 | 约 1500～3000 行 | 不含 CSR/cache/MMU/复杂总线，包含 forwarding、load-use、flush |
| testbench、memory model、脚本、测试程序 | 约 800～2500 行 | 项目能不能讲清楚，很大程度取决于这部分是否扎实 |
| 加最小 CSR/trap/MMIO | 额外约 500～1500 行 | 进入 0803、0804 的范围，建议核心稳定后再做 |
| 加 cache/MMU/分支预测 | 额外代码量变化很大 | 已经不是“最小教学核”，应作为后续专题项目 |

不要把行数当成目标。一个 2000 行左右但边界清楚、测试充分、波形能解释的核，比一个复制了很多功能但自己讲不清控制路径的核更适合作为学习和面试项目。

开源项目可以参考，但建议“先自己写，再对照看”，不要一开始照着抄。几个参考方向如下：

| 参考项目 | 适合看什么 | 不建议怎么用 |
|---|---|---|
| [PicoRV32](https://github.com/YosysHQ/picorv32) | 小型 RISC-V 核、可配置 RV32I/RV32IMC、测试和简单 SoC 组织方式 | 它不是经典五级流水线，不适合直接照搬 stage 划分 |
| [Ibex](https://github.com/lowRISC/ibex) | 工程化小核、异常/CSR、验证组织、代码质量 | 对第一版教学核来说复杂度偏高，不要一开始追它的完整性 |
| [riscv-sodor](https://github.com/ucb-bar/riscv-sodor) | 教学微架构、1/2/3/5 级流水思路 | 多数内容不是 SystemVerilog 风格，重点看结构思想 |
| [riscv-tests](https://github.com/riscv-software-src/riscv-tests) | 基础 ISA 汇编测试用例 | 一开始不要直接追全量通过，先挑 `rv32ui` 中简单用例逐步接入 |
| [riscv-arch-test](https://github.com/riscv/riscv-arch-test) | 架构符合性测试方向 | 更适合后期规范化验证，前期仍应先写自己的 directed test |

一个实际可执行的上手顺序可以是：

1. 自己画一张五级流水线数据通路图，把每个 stage 的输入、输出、pipeline register 字段列出来。
2. 先实现 `LUI/AUIPC/ADDI/ADD/SUB/AND/OR/XOR/SLL/SRL/SRA` 这类不访存、不跳转的指令。
3. 加 `LW/SW/LB/LH/LBU/LHU/SB/SH`，重点验证 byte enable 和 load 扩展。
4. 加 `BEQ/BNE/BLT/BGE/BLTU/BGEU/JAL/JALR`，重点验证 target、`PC+4` 写回和 flush。
5. 加 forwarding，再用连续相关指令打穿 EX/MEM、MEM/WB 两条前递路径。
6. 加 load-use stall，明确控制动作是“冻结 PC 和 IF/ID，向 ID/EX 插入 bubble”。
7. 加 commit trace，与一个简单 reference model 或 ISS 输出对比。
8. 最后再接入更系统的测试集，并整理项目文档：支持哪些指令、不支持哪些异常、memory 假设是什么、hazard 怎么处理、验证覆盖了哪些场景。

教学核写好以后，“跑程序”并不是 testbench 代替 CPU 执行程序。testbench 只是在仿真环境里扮演板子和存储器：提供 clock/reset，把程序机器码放进 instruction memory，必要时检查 data memory、commit trace 或某个 pass/fail 地址。真正执行程序的是 CPU 核自己。

为了跑通这个闭环，环境里至少需要下面几类工具：

| 工具类别 | 常用命令 | 作用 | 当前阶段是否必须 |
|---|---|---|---|
| RTL 仿真器 | `verilator` 或 `iverilog/vvp` | 编译并运行 SystemVerilog testbench | 必须 |
| 综合/可综合性检查 | `yosys` | 检查 RTL 是否能综合，早期发现 latch、不可综合写法等问题 | 建议 |
| RISC-V 交叉编译器 | `riscv64-unknown-elf-gcc` | 把裸机汇编/C 编译、汇编、链接成 RISC-V ELF | 必须 |
| binutils 工具 | `objcopy`、`objdump`、`readelf` | ELF 转 `.mem/.hex`，反汇编，看 ELF 入口和段信息 | 必须 |
| 波形工具 | `gtkwave` 或仿真器自带波形查看器 | 看 PC、valid、stall、flush、forwarding、GPR 写回 | 强烈建议 |
| reference model/ISS | Spike、Sail、简单自写模型等 | 后期做 commit trace 比对 | 后期建议 |

完整流程可以理解为：

```text
裸机汇编/C 程序
    ↓ 交叉编译/汇编/链接
ELF 或 bin/hex/mem 机器码文件
    ↓ testbench 用 $readmemh 等方式加载到 instruction memory
CPU reset，PC 指向 reset vector
    ↓ IF 按 PC 取指，ID/EX/MEM/WB 执行
程序写寄存器、写 data memory、跳转或进入结束循环
    ↓
testbench 判断 pass/fail 或在超时后停止仿真
```

第一阶段通常跑的是 bare-metal 裸机程序，也就是没有 OS、没有进程、没有系统调用的一段固定代码。每次仿真前换一份 instruction memory 初始化文件，CPU 就执行另一段程序。一个最小汇编测试可以长这样：

```asm
.section .text
.global _start

_start:
    addi x1, x0, 3
    addi x2, x0, 4
    add  x3, x1, x2
    sw   x3, 0(x0)

done:
    jal  x0, done
```

这段程序没有 `return` 给 OS，因为根本没有 OS。它做完计算后进入死循环，testbench 可以在若干 cycle 后检查 data memory 地址 0 是否为 7。也可以约定某个特殊地址，例如 `32'h0000_1000` 是 `tohost` 地址：程序向它写 1 表示 pass，写其他值表示 fail。这个地址在第一版仿真里不一定是真外设，可以只是 testbench 或 memory model 观察的一个约定。

常见的仿真接法如下：

| 环节 | 谁负责 | 做什么 |
|---|---|---|
| 写程序 | 人或测试脚本 | 写 `.S` 汇编，后期也可以写很小的 `.c` |
| 生成机器码 | RISC-V 工具链 | 按 `-march=rv32i -mabi=ilp32` 编译/汇编/链接，导出 `.mem` 或 `.hex` |
| 加载程序 | testbench | 用 `$readmemh("test.mem", imem.mem)` 初始化 instruction memory |
| 执行程序 | CPU RTL | 从 reset PC 取指，按 ISA 语义修改 GPR、PC 和 data memory |
| 判断结果 | testbench | 检查 memory、寄存器写回 trace、`tohost` 地址或超时 |
| debug | 人和脚本 | 看 waveform、commit trace、reference model mismatch |

一个非常简化的 testbench 片段可以是：

```systemverilog
initial begin
    $readmemh("test.mem", u_imem.mem);
end

initial begin
    rst_n = 1'b0;
    repeat (5) @(posedge clk);
    rst_n = 1'b1;

    repeat (200) @(posedge clk);

    if (u_dmem.mem[0] == 32'd7) begin
        $display("PASS");
    end else begin
        $display("FAIL: mem[0] = %h", u_dmem.mem[0]);
    end
    $finish;
end
```

这段 testbench 不可综合，只用于仿真。`$readmemh`、`$display`、`$finish` 都是仿真任务，不会变成硬件。真正可综合的部分是 CPU、register file、ALU、pipeline register、hazard/forwarding 控制，以及如果需要上板则替换成 FPGA block RAM 或 SRAM wrapper 的 memory 接口。

这里还要区分教学核里的 ROM 和 RAM 怎么实现。第一版常把 instruction memory 写成 `simple_rom` 或 `imem`，名字叫 ROM 是因为 CPU 执行期间只从里面取指，不通过 store 去改它；但在仿真开始前，testbench 仍然可以用 `$readmemh` 把程序内容灌进去。这个“初始化”是仿真/加载行为，不等于 CPU 正在写 ROM。data memory 则通常写成 `simple_ram` 或 `dmem`，因为 CPU 的 `LW/LH/LB` 要读它，`SW/SH/SB` 要改它。

一个最小 instruction memory 可以是异步读模型，方便入门理解：

```systemverilog
module simple_rom #(
    parameter int AW = 12
) (
    input  logic [31:0] addr_i,
    output logic [31:0] rdata_o
);
    logic [31:0] mem [0:(1 << AW)-1];

    initial begin
        $readmemh("test.mem", mem);      // 仿真初始化，不是可综合 CPU 写 ROM
    end

    assign rdata_o = mem[addr_i[AW+1:2]]; // 32-bit 指令，按 word 取址
endmodule
```

这个写法适合仿真教学，但不同综合工具对 `initial + $readmemh` 的可综合支持不同。FPGA 上经常会把它综合成初始化过的 block RAM 或 distributed ROM；ASIC 里一般不会靠 RTL 的 `initial` 生成真实 ROM，而是接工艺库 ROM macro、SRAM macro，或者由 boot ROM/外部加载链路在系统启动时提供指令。

一个最小 data memory 要支持 byte enable，因为 RV32I 有 `SB/SH/SW`：

```systemverilog
module simple_ram #(
    parameter int AW = 12
) (
    input  logic        clk_i,
    input  logic        we_i,
    input  logic [3:0]  be_i,
    input  logic [31:0] addr_i,
    input  logic [31:0] wdata_i,
    output logic [31:0] rdata_o
);
    logic [31:0] mem [0:(1 << AW)-1];

    wire [AW-1:0] word_addr = addr_i[AW+1:2];

    assign rdata_o = mem[word_addr];      // 简化成组合读，便于第一版流水线学习

    always_ff @(posedge clk_i) begin
        if (we_i) begin
            if (be_i[0]) mem[word_addr][ 7: 0] <= wdata_i[ 7: 0];
            if (be_i[1]) mem[word_addr][15: 8] <= wdata_i[15: 8];
            if (be_i[2]) mem[word_addr][23:16] <= wdata_i[23:16];
            if (be_i[3]) mem[word_addr][31:24] <= wdata_i[31:24];
        end
    end
endmodule
```

这两个 memory model 是为了让教学核先跑起来，不代表真实芯片里一定长这样。真实 SoC 里，指令可能来自 boot ROM、flash、SRAM、I-cache 或总线；数据可能来自 SRAM、D-cache、DRAM 或 MMIO 外设。第一版先把 imem/dmem 固定成简单、1 cycle、无等待的模型，是为了把注意力集中在五级流水线本身。等核心稳定后，再把固定 memory 端口替换成 valid-ready SRAM 接口、总线接口或 cache 接口，就会进入 0804 和 0805 的范围。

如果换成 FPGA 或真实 SoC，testbench 的角色会被真实硬件启动链替代：

```text
仿真阶段：testbench 加载 test.mem 到 imem
FPGA 阶段：bitstream 初始化 block RAM，或 UART/JTAG/bootloader 把程序写进 SRAM
SoC 阶段：CPU 从 boot ROM reset vector 开始，bootloader 再搬运或加载更大的程序
```

所以，第一版教学核可以先理解成“每次仿真执行一段固定裸机程序”。等后面加入 0803 的 CSR/trap、0804 的 MMIO/UART/timer、0805 的 cache/MMU 后，才会逐步接近能运行 runtime、RTOS 甚至更复杂软件栈的系统。

这个项目的第一版最好从头写。原因不是开源项目不好，而是教学核的价值在于你亲手处理那些会让 CPU 出错的细节：x0 写屏蔽、立即数拼接、load-use 停顿、branch flush、store 副作用屏蔽、JALR 前递、register file 写读同拍语义。等自己版本跑起来，再看开源项目，你会更容易看懂别人为什么那样拆模块、为什么控制信号要那样命名、为什么验证环境比 RTL 还复杂。

因此，本阶段的路线可以概括成一句话：**0801 负责告诉你每条指令“最终应该发生什么”，0802 负责告诉你多条指令重叠执行时“怎样仍然只发生这些事”，而教学核项目就是把这两件事写成 RTL 并用测试证明。**

## 第16章 本篇总结

五级流水线的核心不是背五个 stage，而是理解“重叠执行如何保持 ISA 语义不变”：

- pipeline 提高 throughput，但引入 hazard。
- structural hazard 来自资源冲突。
- data hazard 主要靠 forwarding，load-use 需要 stall。
- control hazard 需要预测、redirect 和 flush。
- valid bit 是防止错路径或空槽产生副作用的关键。
- stall、bubble、flush 的优先级必须明确。
- 验证要用 directed test、random test、SVA、coverage 和 ISS/reference model 形成闭环。

能把这些讲清楚，RISC-V 五级流水线就不再是口号，而是可以真正落到 RTL 和验证计划的工程结构。

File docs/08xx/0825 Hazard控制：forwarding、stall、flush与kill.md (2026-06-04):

# 0825 Hazard 控制：forwarding、stall、flush 与 kill

> 文档编号：0825  
> 所属系列：082x RISC-V 最小教学核项目实践  
> 文档定位：定义第一版 RV32I 五级流水线教学核中的 forwarding、stall、bubble、flush、kill 控制条件和优先级  
> 前置文档：`0802 RISC-V五级流水线与Hazard.md`、`0822 最小教学核工程目录、顶层接口与命名约定.md`、`0824 数据通路、流水线寄存器与控制信号参考.md`

本文是控制条件手册。它不重新解释五级流水线原理，而是把第一版教学核里最容易写错的 hazard 控制拆成可实现规则。

本文默认项目假设：

| 项目 | 假设 |
|---|---|
| pipeline | IF、ID、EX、MEM、WB |
| branch 决策 | EX 阶段 |
| memory | 第一版固定响应，无 wait state |
| forwarding 来源 | EX/MEM、MEM/WB |
| load-use | 通过冻结 PC/IFID，向 IDEX 插 bubble 解决 |
| wrong-path | 通过 flush/kill 清 valid，副作用由 valid gating 屏蔽 |

## 第1章 本篇使用的控制动作

### 1.1 四个动作不要混用

| 动作 | 含义 | 典型对象 |
|---|---|---|
| forwarding | 不等 GPR 写回，直接从后级结果送到 EX 操作数 | ALU 输入、branch 比较输入、store data |
| stall | 某级寄存器保持不变 | PC、IF/ID |
| bubble | 向后级插入一个 invalid 空槽 | ID/EX |
| flush/kill | 清掉错路径年轻指令，使其不能产生副作用 | IF/ID、ID/EX |

`stall` 是保持，`bubble` 是插入空槽，`flush/kill` 是杀掉错误路径。RTL 里不要用一个信号同时表达这些动作。

### 1.2 推荐控制信号

沿用 `0822/0824` 的命名：

| 信号 | 动作 |
|---|---|
| `stall_if` | PC 保持，不取新路径顺序指令 |
| `stall_id` | IF/ID 保持，ID 当前指令不前进 |
| `bubble_ex` | ID/EX 写入 invalid bubble |
| `flush_if_id` | IF/ID valid 清 0 |
| `flush_id_ex` | ID/EX valid 清 0 |
| `redirect_valid` | EX 产生新 PC |
| `redirect_pc` | 新 PC |
| `fwd_a_sel` | EX 阶段 rs1 操作数选择 |
| `fwd_b_sel` | EX 阶段 rs2 操作数选择 |
| `store_fwd_sel` | store data 选择，可和 `fwd_b_sel` 共享 |

## 第2章 forwarding

### 2.1 forwarding 解决什么

forwarding 解决的是：前一条指令已经算出结果，但还没写回 GPR；后一条指令已经进入 EX，需要这个最新结果。

典型例子：

```asm
add  x3, x1, x2
sub  x4, x3, x5
```

`sub` 在 EX 阶段需要 `x3`，但 `add` 还没到 WB 写回。此时应从 EX/MEM 前递 `add` 的 ALU 结果。

### 2.2 forwarding 来源

第一版常用两个来源：

| 来源 | 适合前递的数据 | 注意 |
|---|---|---|
| EX/MEM | ALU 结果、`PC+4`、LUI 结果等已经在 EX 得到的数据 | load 在 EX/MEM 时还没有 load data，不能把地址当前递数据 |
| MEM/WB | 最终写回数据 `wb_rd_wdata` | ALU/load/JAL/LUI 都可以统一前递 |

推荐把 MEM/WB 的前递数据定义成最终写回数据：

```systemverilog
assign mem_wb_forward_data = wb_rd_wdata;
```

这样 `WB_ALU/WB_MEM/WB_PC4/WB_IMM` 都不用分开判断。

### 2.3 rs1/rs2 forwarding 条件

对 EX 阶段当前指令的 `rs1`：

```systemverilog
assign exmem_can_fwd =
    ex_mem_valid &&
    ex_mem_reg_we &&
    (ex_mem_rd_addr != 5'd0) &&
    !ex_mem_mem_re;

assign memwb_can_fwd =
    mem_wb_valid &&
    mem_wb_reg_we &&
    (mem_wb_rd_addr != 5'd0);

assign exmem_match_rs1 =
    exmem_can_fwd &&
    id_ex_uses_rs1 &&
    (ex_mem_rd_addr == id_ex_rs1_addr);

assign memwb_match_rs1 =
    memwb_can_fwd &&
    id_ex_uses_rs1 &&
    (mem_wb_rd_addr == id_ex_rs1_addr);
```

`rs2` 同理：

```systemverilog
assign exmem_match_rs2 =
    exmem_can_fwd &&
    id_ex_uses_rs2 &&
    (ex_mem_rd_addr == id_ex_rs2_addr);

assign memwb_match_rs2 =
    memwb_can_fwd &&
    id_ex_uses_rs2 &&
    (mem_wb_rd_addr == id_ex_rs2_addr);
```

注意 `!ex_mem_mem_re`：load 指令在 EX/MEM 阶段时，`ex_mem_alu_result` 是 load 地址，不是 load 数据。如果把它前递给下一条 ALU，会把地址当成数据。

### 2.4 forwarding 优先级

如果 EX/MEM 和 MEM/WB 同时匹配同一个源寄存器，选 EX/MEM，因为它更新。

```systemverilog
always_comb begin
    fwd_a_sel = FWD_GPR;

    if (exmem_match_rs1) begin
        fwd_a_sel = FWD_EXMEM;
    end else if (memwb_match_rs1) begin
        fwd_a_sel = FWD_MEMWB;
    end
end
```

典型例子：

```asm
addi x1, x0, 1
addi x1, x1, 1
add  x2, x1, x0
```

第三条 `add` 应该看到第二条 `addi` 产生的新 `x1`，不是第一条产生的旧 `x1`。

### 2.5 forwarding 数据选择

```systemverilog
always_comb begin
    unique case (fwd_a_sel)
        FWD_GPR:   ex_rs1_data = id_ex_rs1_rdata;
        FWD_EXMEM: ex_rs1_data = ex_mem_forward_data;
        FWD_MEMWB: ex_rs1_data = mem_wb_forward_data;
        default:   ex_rs1_data = id_ex_rs1_rdata;
    endcase
end
```

`ex_mem_forward_data` 要根据后级指令类型定义。第一版如果 `LUI/AUIPC/JAL` 的结果都已经在 EX 阶段形成，可以统一放在 `ex_mem_alu_result` 或一个专门的 `ex_mem_wb_data_pre` 中。关键是不能对 load 使用 EX/MEM 地址当数据。

### 2.6 branch 和 store 也需要 forwarding

branch 比较在 EX 阶段进行时，比较输入就是 EX 操作数，因此自然应使用 forwarding 后的数据：

```asm
add x1, x2, x3
beq x1, x0, target
```

store 的 `rs2` 是写入 memory 的数据，也可能来自前一条指令：

```asm
add x3, x1, x2
sw  x3, 0(x4)
```

因此 `ex_mem_store_data` 应保存 forwarding 后的 `rs2`，不要保存 ID 阶段读出的旧 `rs2`。

## 第3章 load-use stall

### 3.1 为什么 forwarding 不够

load 的数据不是 EX 阶段 ALU 算出的结果，而是 MEM 阶段从 data memory 返回的结果。

```asm
lw  x3, 0(x1)
add x4, x3, x5
```

当 `add` 下一拍进入 EX 时，`lw` 还在 MEM 阶段读 memory，数据还没稳定到 MEM/WB。因此这类紧邻使用必须 stall 一拍。

### 3.2 检测条件

load-use 在 ID 阶段检测比较自然：当前 ID 指令要读的寄存器，等于 ID/EX 中 load 的 `rd`。

```systemverilog
assign load_use_rs1 =
    if_id_valid_q &&
    id_uses_rs1 &&
    id_ex_valid &&
    id_ex_mem_re &&
    (id_ex_rd_addr != 5'd0) &&
    (id_ex_rd_addr == id_rs1_addr);

assign load_use_rs2 =
    if_id_valid_q &&
    id_uses_rs2 &&
    id_ex_valid &&
    id_ex_mem_re &&
    (id_ex_rd_addr != 5'd0) &&
    (id_ex_rd_addr == id_rs2_addr);

assign load_use_stall = load_use_rs1 || load_use_rs2;
```

`id_uses_rs1/id_uses_rs2` 必须来自 decoder。不要只看 instruction 的 bit 字段，否则 `LUI/JAL` 等不读寄存器的指令可能产生假 stall。

### 3.3 控制动作

检测到 load-use：

| 目标 | 动作 | 原因 |
|---|---|---|
| PC/IF | `stall_if = 1` | 不取下一条新指令 |
| IF/ID | `stall_id = 1` | 当前使用者指令留在 ID |
| ID/EX | `bubble_ex = 1` | 让 EX 下一拍空一拍 |
| EX/MEM | 正常前进 | load 继续去 MEM 读数据 |
| MEM/WB | 正常前进 | load 数据下一拍进入 WB |

时序效果：

```text
cycle N:     lw 在 EX，add 在 ID，检测到 load-use
cycle N+1:   lw 在 MEM，ID/EX 是 bubble，add 仍在 ID
cycle N+2:   lw 在 WB，add 进入 EX，从 MEM/WB forwarding 获得 load data
```

这里“LW 继续从 EX 进入 MEM，再进入 WB”不需要额外控制，它是因为 EX/MEM 和 MEM/WB 没有被 stall；“ADD 下一拍进入 EX”是因为 load-use stall 只持续一拍，下一拍条件解除，IF/ID 正常流入 ID/EX。

### 3.4 load-use 常见错误

| 错误 | 现象 |
|---|---|
| 只停 PC，不停 IF/ID | 使用者指令丢失或重复错乱 |
| 只停 IF/ID，不插 bubble | load 和使用者同时挤在 EX，时序不对 |
| 把 EX/MEM 也停住 | load 不去 MEM，stall 可能无法解除 |
| 没排除 `rd=x0` | `lw x0,...` 后的指令被误停 |
| 没用 `uses_rs1/uses_rs2` | `LUI/JAL` 等产生假相关 |

## 第4章 control hazard 与 flush/kill

### 4.1 EX 决策 branch 的代价

第一版 branch/JAL/JALR 在 EX 阶段得到最终 redirect：

| 指令 | EX 阶段做什么 |
|---|---|
| branch | 比较 `rs1/rs2`，taken 时 `redirect_pc = pc + immB` |
| JAL | `redirect_pc = pc + immJ`，写回 `PC+4` |
| JALR | `redirect_pc = (rs1 + immI) & ~1`，写回 `PC+4` |

当 EX 发现要跳转时，IF 和 ID 中已经有旧路径上的年轻指令。这些指令必须被 flush/kill。

### 4.2 redirect 条件

```systemverilog
assign branch_taken =
    id_ex_valid &&
    (id_ex_branch_op != BR_NONE) &&
    branch_condition_met;

assign jump_taken =
    id_ex_valid &&
    id_ex_jump;

assign redirect_valid = branch_taken || jump_taken;

assign redirect_pc =
    id_ex_jalr ? ((ex_rs1_data + id_ex_imm) & 32'hffff_fffe) :
    id_ex_jump ? (id_ex_pc + id_ex_imm) :
                 (id_ex_pc + id_ex_imm);
```

对 branch 和 JAL，上式 target 都是 `pc + imm`；对 JALR，是 `rs1 + imm` 后清 bit0。实际 RTL 可以写得更清晰。

### 4.3 flush 动作

EX 阶段 redirect 时，常见动作：

| 目标 | 动作 |
|---|---|
| PC | 下一拍改成 `redirect_pc` |
| IF/ID | `flush_if_id = 1` |
| ID/EX | 通常 `flush_id_ex = 1` 或让当前 EX 指令继续、清 younger 槽 |
| EX/MEM | 当前 branch/jump 自己继续向后提交 |

如果 branch 当前在 EX，那么 ID/EX 中保存的就是 branch 自己，不能把“当前正在 EX 的 branch”误杀掉。具体实现上，`flush_id_ex` 通常作用于下一拍即将写入 ID/EX 的内容，使 ID 阶段旧路径年轻指令不能进入 EX；而 EX/MEM 仍接收当前 branch 的信息。

更直观地说：

```text
正在 EX 的 branch/jump：保留，它是正确路径上较老指令
IF/ID 中的年轻指令：kill
ID 阶段准备进入 EX 的年轻指令：kill/bubble
```

### 4.4 kill 的本质是 valid 清零

kill 不一定意味着把所有数据位清零，关键是 `valid=0`。被 kill 的指令即使波形上还带着原始 `instr`，也不能：

- 写 GPR。
- 写 dmem。
- 打印 commit。
- 触发后续异常提交。

因此副作用必须写成：

```systemverilog
assign dmem_we_o = ex_mem_valid && ex_mem_mem_we;

assign wb_gpr_we =
    mem_wb_valid &&
    mem_wb_reg_we &&
    (mem_wb_rd_addr != 5'd0);
```

## 第5章 structural hazard 在第一版中的处理

第一版采用分离 imem/dmem，GPR 两读一写，ALU 单条指令独占，因此结构冒险很少。

| 资源 | 第一版假设 | 是否需要 stall |
|---|---|---|
| imem/dmem | 分离 | 不需要处理取指/访存冲突 |
| GPR | 2 read + 1 write | 不需要为普通 `rs1/rs2/rd` 冲突 stall |
| ALU | 单发射，每拍最多一条 EX 指令 | 不需要 ALU 仲裁 |
| MDU | 第一版无乘除法 | 不需要多周期 busy stall |
| dmem | 固定响应 | 不需要 memory wait stall |

后续若加入单端口统一 memory、多周期乘除法、valid-ready 总线或 cache miss，structural hazard 会重新出现，进入 `0829` 或扩展文档范围。

## 第6章 控制优先级

### 6.1 第一版推荐优先级

在固定响应 memory 的第一版中，常见事件优先级：

```text
reset > redirect/flush > load-use stall > normal advance
```

含义：

| 优先级 | 事件 | 原因 |
|---|---|---|
| 1 | reset | 清空所有状态 |
| 2 | redirect/flush | 一旦确定 PC 要跳转，旧路径年轻指令必须被 kill |
| 3 | load-use stall | 正确路径上的数据等待 |
| 4 | normal | 正常流动 |

如果同一拍同时出现 redirect 和 load-use，通常 redirect 优先，因为 load-use 可能来自即将被 kill 的旧路径年轻指令。具体设计要保证不会把 wrong-path 的 stall 留下来阻止正确 redirect。

### 6.2 组合控制汇总示例

示意写法：

```systemverilog
always_comb begin
    stall_if    = 1'b0;
    stall_id    = 1'b0;
    bubble_ex   = 1'b0;
    flush_if_id = 1'b0;
    flush_id_ex = 1'b0;

    if (redirect_valid) begin
        flush_if_id = 1'b1;
        flush_id_ex = 1'b1;
    end else if (load_use_stall) begin
        stall_if  = 1'b1;
        stall_id  = 1'b1;
        bubble_ex = 1'b1;
    end
end
```

这只是第一版固定 memory 的简化逻辑。后续加 memory wait 时，还要考虑 MEM 阶段向前级施加 backpressure。

## 第7章 最小测试清单

### 7.1 forwarding 测试

| 测试 | 示例 | 目标 |
|---|---|---|
| EX/MEM -> rs1 | `add x3,x1,x2; sub x4,x3,x5` | rs1 前递 |
| EX/MEM -> rs2 | `add x3,x1,x2; sub x4,x5,x3` | rs2 前递 |
| MEM/WB -> rs1 | 中间隔一条无关指令 | MEM/WB 前递 |
| 双来源优先级 | 连续写同一 rd | EX/MEM 优先 |
| rd=x0 | `add x0,x1,x2; add x3,x0,x4` | 不从 x0 前递 |
| branch operand | `add x1,x2,x3; beq x1,x0,L` | branch 比较前递 |
| store data | `add x3,x1,x2; sw x3,0(x4)` | store 写数据前递 |

### 7.2 load-use 测试

| 测试 | 示例 | 目标 |
|---|---|---|
| 紧邻 rs1 | `lw x3,0(x1); add x4,x3,x5` | 停一拍 |
| 紧邻 rs2 | `lw x3,0(x1); add x4,x5,x3` | 停一拍 |
| store data 紧邻 | `lw x3,0(x1); sw x3,0(x2)` | store data 使用 load 值 |
| 隔一条使用 | `lw; nop; add` | 不应额外 stall |
| load rd=x0 | `lw x0,0(x1); add x2,x0,x3` | 不应 stall |

### 7.3 flush/kill 测试

| 测试 | 示例 | 目标 |
|---|---|---|
| taken branch 后写 GPR | branch 后放 `addi x5,...` | `x5` 不应被写 |
| taken branch 后 store | branch 后放 `sw` | dmem 不应被写 |
| not-taken branch | 普通顺序执行 | 不应误 flush |
| JAL | 跳转后旧路径指令无副作用 | `rd=PC+4` 正确 |
| JALR | 目标由寄存器决定 | bit0 清零，旧路径 kill |

## 第8章 常见 bug

| bug | 典型现象 | 根因 |
|---|---|---|
| forwarding 未排除 load | `lw; add` 得到地址而不是数据 | EX/MEM load 地址被当前递数据 |
| forwarding 未排除 x0 | 读 x0 变成非 0 | `rd=0` 仍参与匹配 |
| MEM/WB 前递不是最终 wb 数据 | JAL/load 前递错误 | 没统一用 `wb_rd_wdata` |
| load-use 只停一部分 | 指令丢失或重复执行 | stall/bubble 动作不完整 |
| redirect 被 stall 阻塞 | taken branch 后继续取旧路径 | 优先级错 |
| flush 只清 IF/ID | ID/EX 旧路径指令继续执行 | kill 范围不够 |
| wrong-path store 写入 | dmem 被错误修改 | `dmem_we` 没 valid gating |
| commit trace 打印 bubble | trace 多出奇怪指令 | `commit_valid` 没用 valid |

## 第9章 相关文档

| 文档 | 关系 |
|---|---|
| `0802 RISC-V五级流水线与Hazard.md` | 原理解释和背景 |
| `0822 最小教学核工程目录、顶层接口与命名约定.md` | 本文沿用的控制信号命名 |
| `0824 数据通路、流水线寄存器与控制信号参考.md` | 本文依赖的 pipeline register 字段 |
| `0827 Testbench、commit trace与测试集组织.md` | 后续把本文测试清单变成可运行回归 |
| `0828 波形debug、常见bug与定位清单.md` | 后续从波形角度定位本文这些 bug |

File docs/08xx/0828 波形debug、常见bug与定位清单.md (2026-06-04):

# 0828 波形 debug、常见 bug 与定位清单

> 文档编号：0828  
> 所属系列：082x RISC-V 最小教学核项目实践  
> 文档定位：汇总第一版 RV32I 五级流水线教学核的常见错误现象、波形观察顺序和定位方法  
> 前置文档：`0824 数据通路、流水线寄存器与控制信号参考.md`、`0825 Hazard控制：forwarding、stall、flush与kill.md`、`0827 Testbench、commit trace与测试集组织.md`

本文是 debug checklist。目标不是讲新原理，而是当测试失败时，能按步骤缩小问题范围。

本文默认你已经有：

| 工具/信息 | 作用 |
|---|---|
| `objdump` | 知道程序实际指令和地址 |
| commit trace | 知道第一条错误提交 |
| waveform | 观察 PC、valid、stall、flush、forwarding、GPR 写回 |
| directed test | 测试足够短，失败点明确 |

## 第1章 总体定位顺序

### 1.1 先找第一条错误提交

不要从波形第一拍开始盲看。先看：

```text
expected trace:
pc=00000008 instr=002081b3 rd=x3 wdata=00000007

rtl trace:
pc=00000008 instr=002081b3 rd=x3 wdata=00000003
```

第一条错误提交告诉你：

| 信息 | 说明 |
|---|---|
| PC | 哪条指令错 |
| instr | 工具链实际生成的编码 |
| rd/wdata | 写回错在哪里 |
| 是否 store | memory 副作用是否错 |

然后再回到波形看这条指令在 ID/EX/MEM/WB 每级经历了什么。

### 1.2 按问题类型分流

| 现象 | 优先看 |
|---|---|
| PC 从第一条就错 | reset PC、imem 加载、链接地址 |
| 指令编码不符合预期 | `.mem` 端序、objdump、imem 索引 |
| 单条 ALU 结果错 | decoder、imm_gen、ALU op、GPR 读值 |
| 连续相关才错 | forwarding、load-use stall |
| branch 后错 | branch compare、target、flush/kill |
| store 错 | store data forwarding、byte enable、dmem 地址映射 |
| load 错 | dmem rdata、地址低位、符号/零扩展 |
| 偶发多提交/少提交 | valid、stall、bubble、flush 优先级 |

## 第2章 必看波形信号

### 2.1 取指和 PC

| 信号 | 看什么 |
|---|---|
| `pc_q` 或 `if_pc` | 是否从 reset PC 开始，是否按 4 递增 |
| `imem_addr_o` | 是否等于当前取指 PC |
| `imem_rdata_i` | 是否等于 `.mem` 对应行 |
| `redirect_valid` | branch/jump 时是否拉高 |
| `redirect_pc` | target 是否正确 |
| `stall_if` | PC 是否因 load-use 被保持 |

### 2.2 pipeline valid

| 信号 | 看什么 |
|---|---|
| `if_id_valid` | reset/flush 后是否清 0 |
| `id_ex_valid` | load-use bubble 是否出现 |
| `ex_mem_valid` | invalid 是否继续产生副作用 |
| `mem_wb_valid` | commit 是否只来自 valid 指令 |

valid 是 debug 的主线。很多 bug 的本质是“这个槽已经不是有效指令，但仍然做了事”。

### 2.3 decode 和操作数

| 信号 | 看什么 |
|---|---|
| `id_rs1_addr/id_rs2_addr/id_rd_addr` | 字段提取是否正确 |
| `id_uses_rs1/id_uses_rs2` | 是否把 LUI/JAL 误认为读寄存器 |
| `id_imm` | 立即数拼接和符号扩展是否正确 |
| `id_reg_we/id_mem_we/id_wb_sel` | 控制信号是否符合指令 |
| `id_ex_rs1_rdata/id_ex_rs2_rdata` | GPR 读值是否正确 |

### 2.4 EX 和 forwarding

| 信号 | 看什么 |
|---|---|
| `fwd_a_sel/fwd_b_sel` | 是否选择了正确来源 |
| `ex_rs1_data/ex_rs2_data` | forwarding 后值是否正确 |
| `ex_mem_rd_addr/mem_wb_rd_addr` | 是否匹配当前 rs |
| `ex_mem_reg_we/mem_wb_reg_we` | 后级是否真的写 GPR |
| `ex_mem_mem_re` | load 是否被禁止从 EX/MEM 前递 |
| `alu_result` | ALU 结果或地址是否正确 |

### 2.5 MEM/WB 和副作用

| 信号 | 看什么 |
|---|---|
| `dmem_we_o` | wrong-path store 是否被屏蔽 |
| `dmem_be_o` | `SB/SH/SW` lane 是否正确 |
| `dmem_addr_o` | 是否经过 DMEM_BASE 映射 |
| `dmem_wdata_o` | store data 是否已对齐 |
| `mem_wb_load_data` | load 扩展是否正确 |
| `wb_rd_wdata` | 最终写回选择是否正确 |
| `wb_gpr_we` | 是否同时满足 valid、reg_we、rd!=0 |

## 第3章 启动和程序加载问题

| 现象 | 可能原因 | 看什么 |
|---|---|---|
| PC 是 `x` | reset 没初始化、复位极性错 | `rst_n_i`、`pc_q` reset 分支 |
| 第一条指令全 0 | imem 没加载、路径错 | `$readmemh` log、`.mem` 文件 |
| 第一条指令 byte 反 | `.mem` 端序错 | objdump 编码 vs imem_rdata |
| PC 正确但取错行 | imem 索引位错 | `addr[AW+1:2]` |
| 程序跳到空地址 | 链接地址和 reset PC 不一致 | objdump `_start`、linker script |

快速检查：

```text
objdump 里 0x00000000 的指令
        是否等于
仿真第一拍 imem_rdata_i
```

如果不等，先别看 CPU，先修程序加载。

## 第4章 decoder 和 immediate 问题

| 现象 | 可能原因 | 看什么 |
|---|---|---|
| `LUI` 结果低 12 bit 不为 0 | U-imm 拼错 | `id_imm` |
| branch 跳到奇怪地址 | B-imm bit 拼接错或重复左移 | `id_imm`、`redirect_pc` |
| JAL 跳转偏移错 | J-imm 拼接错 | `id_imm` |
| `JALR` 目标奇数 | 没清 bit0 | `redirect_pc[0]` |
| `SLTIU` 结果错 | 立即数未先符号扩展 | `id_imm`、比较输入 |
| shift immediate 错 | shamt 位宽或 funct7 检查错 | `instr[24:20]`、`funct7` |

B/J immediate 已经在 `imm_gen` 补了最低 `0` 后，target 计算不要再左移。

## 第5章 GPR 和 x0 问题

| 现象 | 可能原因 | 看什么 |
|---|---|---|
| 读 x0 不是 0 | regfile 读口没特殊处理或写入 x0 | `rs*_addr`、`rs*_rdata` |
| 写 x0 后影响后续 | 写端没屏蔽 `rd=0` | `wb_gpr_we` |
| forwarding 让 x0 非 0 | forwarding 匹配没排除 `rd=0` | `ex_mem_rd_addr`、`fwd_sel` |
| 同拍读写不符合预期 | regfile 写读时序未定义 | 同拍 `we/rd/rs/rdata` |

建议 regfile 保证：

```text
写 rd=0 被丢弃
读 rs=0 返回 0
```

同拍写读同一非零寄存器的语义要在项目中明确；五级流水中通常依赖 WB 写和 ID 读的时序或显式 bypass。

## 第6章 forwarding 问题

| 现象 | 可能原因 | 看什么 |
|---|---|---|
| `add; sub` 相关错 | EX/MEM forwarding 没触发 | `exmem_match_rs*` |
| 隔一条相关错 | MEM/WB forwarding 没触发 | `memwb_match_rs*` |
| 连续写同一 rd 用旧值 | 优先级错 | EX/MEM 是否优先 MEM/WB |
| `lw; add` 得到地址 | EX/MEM load 被错误前递 | `ex_mem_mem_re` |
| branch 判断错 | branch 操作数没 forwarding | branch compare 输入 |
| store 写旧值 | store data 没 forwarding | `ex_mem_store_data` |

定位时先看 forwarding 选择，再看被选择的数据源是否正确。

## 第7章 load-use 问题

| 现象 | 可能原因 | 看什么 |
|---|---|---|
| `lw; add` 结果错 | 没 stall 或 stall 不完整 | `load_use_stall` |
| 指令丢失 | IF/ID 没保持 | `stall_id`、`if_id_instr` |
| 指令重复提交 | PC/IFID/IDEX 控制不一致 | valid 流动 |
| 卡死一直 stall | ID/EX load 没前进到 EX/MEM | `id_ex_mem_re`、`ex_mem_mem_re` |
| 多停一拍 | 条件解除慢或匹配错误 | `id_ex_valid`、`id_ex_rd_addr` |

正确波形应类似：

```text
cycle N:   lw in EX,  add in ID,  load_use_stall=1
cycle N+1: lw in MEM, bubble in EX, add still in ID
cycle N+2: lw in WB,  add in EX,  forwarding from MEM/WB
```

## 第8章 branch/JAL/JALR flush 问题

| 现象 | 可能原因 | 看什么 |
|---|---|---|
| taken 后仍执行旧路径 | `flush_if_id/flush_id_ex` 没拉高 | redirect 当拍 |
| wrong-path 写 GPR | WB 写回没 valid gating | `mem_wb_valid`、`wb_gpr_we` |
| wrong-path store | dmem_we 没 valid gating | `ex_mem_valid`、`dmem_we_o` |
| not-taken 被 flush | branch condition 反了 | `branch_taken` |
| JAL 写回错 | `PC+4` 没随指令保存 | `id_ex_pc_plus4`、`mem_wb_pc_plus4` |
| JALR target 错 | forwarding 或 bit0 清零错 | `ex_rs1_data`、`redirect_pc` |

如果 branch 在 EX 决策，重点看 redirect 当拍 IF/ID 和下一拍 ID/EX 的 valid 是否被清掉。

## 第9章 load/store 和 dmem 问题

| 现象 | 可能原因 | 看什么 |
|---|---|---|
| `SW` 写不到预期地址 | DMEM_BASE 映射错 | `dmem_addr_o`、内部 word index |
| `SB` 写错 byte | byte enable 或 wdata 对齐错 | `dmem_be_o`、`dmem_wdata_o` |
| `LH/LHU` 结果错 | halfword 选择或扩展错 | `addr[1]`、load mux |
| load 返回旧值 | memory 读写同拍语义不清 | dmem 模型 |
| store data 旧 | store data forwarding 漏了 | `ex_mem_store_data` |

先确认地址，再确认 byte enable，最后确认数据。

## 第10章 常见“看起来像 CPU 错，其实不是”的问题

| 现象 | 实际可能 |
|---|---|
| 出现不支持指令 | 编译命令没用 `-march=rv32i`，或 C 代码引入库函数 |
| 出现 16 bit 指令 | 没禁用 C 扩展或没写 `.option norvc` |
| 程序访问奇怪地址 | 链接脚本、栈指针或 C 指针地址错 |
| 仿真不结束 | 程序没有写 tohost，timeout 太长或没有 timeout |
| 波形文件为空 | testbench 没 `$dumpvars`，或仿真提前退出 |
| trace 对不上 cycle | 单周期参考和流水线 cycle 本来不同，应比较提交顺序 |

## 第11章 debug 顺序模板

一次失败可以按这个顺序：

1. 看回归 log，确认哪个测试失败。
2. 看 objdump，确认测试实际指令。
3. 看 commit trace，找第一条错误提交。
4. 找该 PC 在波形中经过 IF/ID/EX/MEM/WB 的位置。
5. 若写回值错，看 decoder、operand、forwarding、ALU、WB。
6. 若 PC 错，看 immediate、branch compare、redirect、flush。
7. 若 memory 错，看 address、be、wdata、valid gating。
8. 修一个最小问题后，只跑对应 directed test。
9. 通过后再跑全量回归。

## 第12章 相关文档

| 文档 | 关系 |
|---|---|
| `0824 数据通路、流水线寄存器与控制信号参考.md` | 本文观察信号的来源 |
| `0825 Hazard控制：forwarding、stall、flush与kill.md` | 本文多数控制 bug 的规则依据 |
| `0826 裸机程序、ROM与RAM加载与工具链使用示例.md` | 程序加载和工具链问题排查 |
| `0827 Testbench、commit trace与测试集组织.md` | trace、pass/fail 和测试组织 |

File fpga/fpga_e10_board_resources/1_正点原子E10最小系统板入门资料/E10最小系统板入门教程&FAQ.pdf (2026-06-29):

原子哥在线教学：www.yuanzige.com | 论坛:www.openedv.com

## E10 最小系统板入门教程&FAQ

## E10 最小系统板入门教程&FAQ

1. 系统板检测

在收到快递之后，您第一步需要做的就是检测系统板是否完好。首先是包装，E10 最小系统板外部采用 邮政纸盒，内部用气泡袋防震保护，拆开外面邮政纸盒和气泡袋后，包装盒外观必须良好；然后我们打开 包装盒，取出所有配件，大家根据自己拍下的内容，进行核对，我们一般会放有发货单，大家可以根据发 货单自行核对。另外，如果您还购买了其他模块/芯片，请单独核对。
对于购买 LCD 液晶屏的朋友，在确认接收到的系统板及配件外观没问题（主要看看 LCD 的触摸屏， 是否有裂痕）之后，请您开始检测系统板的硬件，是否存在问题（主要是 LCD 的问题，在运输过程中最容 易受损）。
1.1. E10 最小系统板综合测试

系统板出厂自带 E10 最小系统板综合测试实验程序，可以直接上电检测硬件而无需再烧写综合测试实 验程序 JIC 文件，E10 最小系统板的 JIC 文件位于“4_SourceCode\2_HardwareTest\peripheral_test.jic”。如果 该测试程序被其他程序覆盖后想要检测系统板的硬件，可以重新烧写综合测试实验程序 JIC 文件。关于如何 烧写 JIC 文件，请参考系统板光盘资料：《E10 最小系统板之 FPGA 开发指南.pdf》，打开后找到第四章:Q uartus 软件的安装和使用中 4.3.8 小节。烧写完之后，断电重启即可。
E10 最小系统板综合测试实验支持测试绝大多数系统板的外设，包括选配的模块，如双目 OV5640 摄像 头、RGB LCD 液晶屏等。详细测试方法将一一展开。 在系统板上电之前，需要连接测试的外设模块与接口，包括双目 OV5640 摄像头、RGB LCD 液晶屏（排 线连接方法参考图 1.1）、最后连接 USB_UART 串口（用 USB 线的 Type_C 端连系统板，另一端与电脑的 USB 口连接），因为 USB_UART 接口也是电源接口，连接 USB_UART 串口的同时开发板也会上电（整个 硬件连接如图 1.2 所示）。当然，如果没有连接选配的外设模块也可以对系统板进行测试，只是有些功能 暂时用不了，E10 最小系统板 LCD 连接示意图如下图所示，先将系统板上 FPC 连接器上的黑色翻盖拉起， 将 FPC 排线金属薄片朝向 FPGA 芯片一端，蓝色部分朝向 JTAG 接口一端，插入连接器，最后黑色翻盖压 下以固定 FPC 排线。

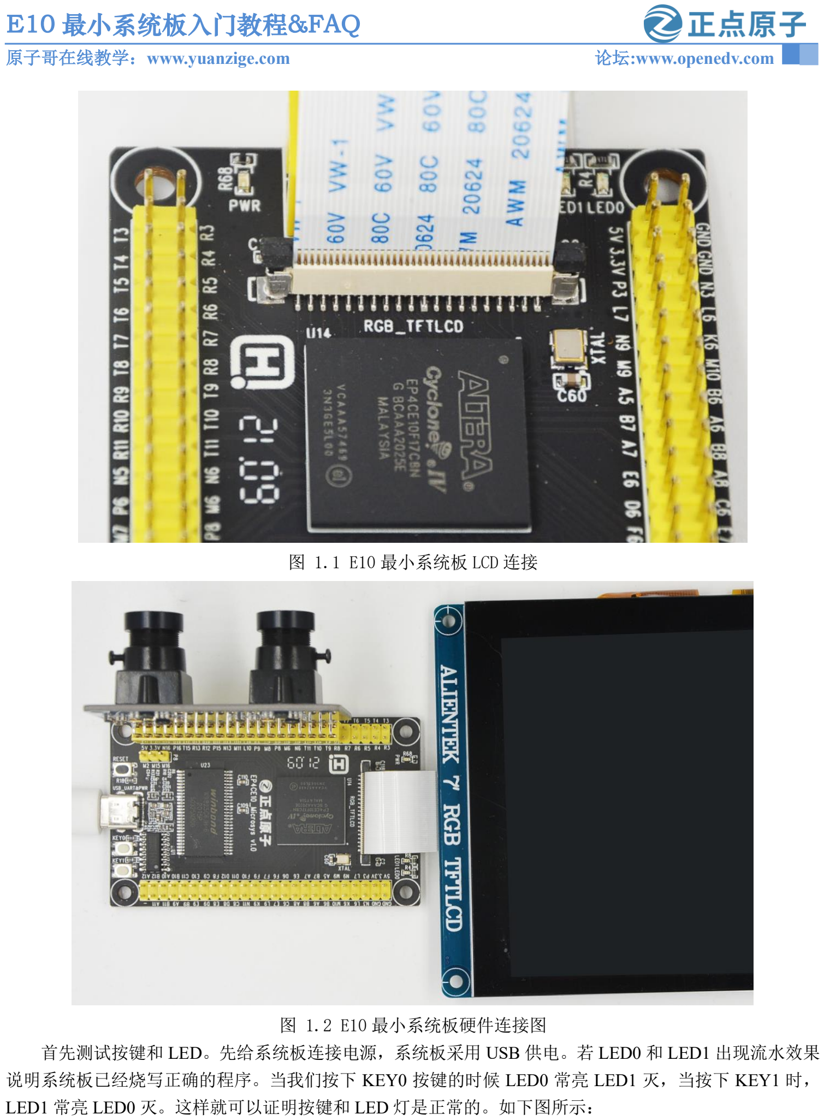
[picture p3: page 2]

图 1.1 E10 最小系统板 LCD 连接

图 1.2 E10 最小系统板硬件连接图
首先测试按键和 LED。先给系统板连接电源，系统板采用 USB 供电。若 LED0 和 LED1 出现流水效果 说明系统板已经烧写正确的程序。当我们按下 KEY0 按键的时候 LED0 常亮 LED1 灭，当按下 KEY1 时， LED1 常亮 LED0 灭。这样就可以证明按键和 LED 灯是正常的。如下图所示：

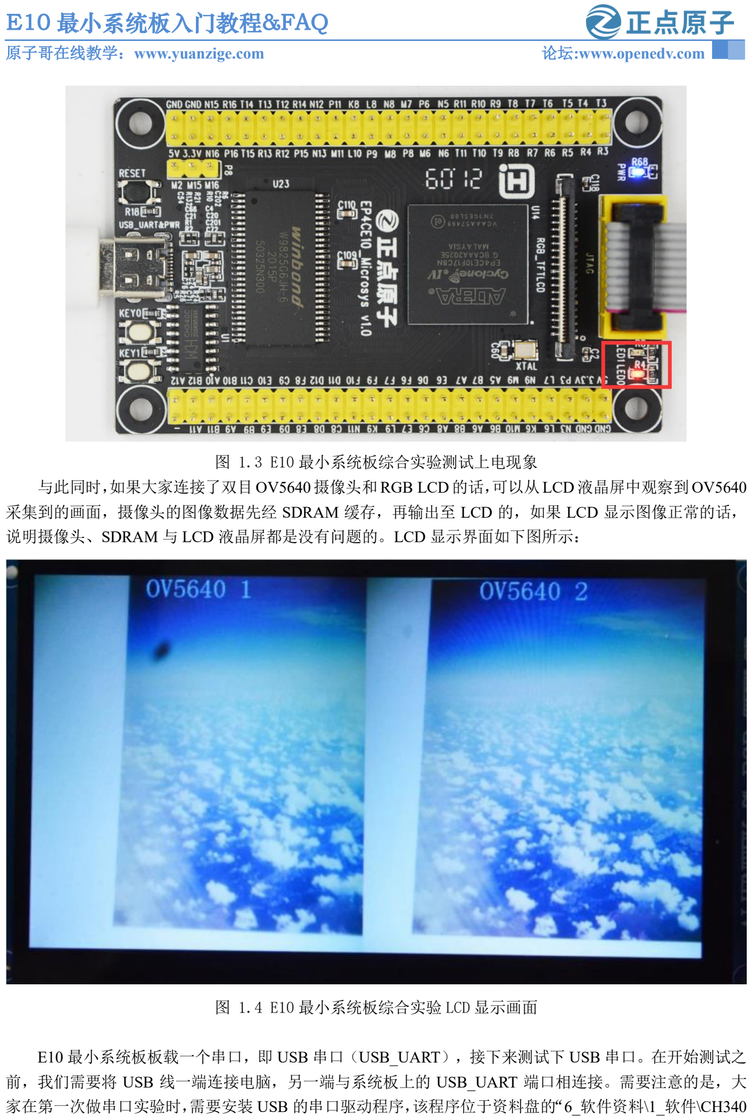
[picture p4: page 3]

图 1.3 E10 最小系统板综合实验测试上电现象
与此同时，如果大家连接了双目OV5640摄像头和RGB LCD 的话，可以从LCD液晶屏中观察到OV5640 采集到的画面，摄像头的图像数据先经 SDRAM 缓存，再输出至 LCD 的，如果 LCD 显示图像正常的话， 说明摄像头、SDRAM 与 LCD 液晶屏都是没有问题的。LCD 显示界面如下图所示：

图 1.4 E10 最小系统板综合实验 LCD 显示画面

E10 最小系统板板载一个串口，即 USB 串口（USB_UART），接下来测试下 USB 串口。在开始测试之 前，我们需要将 USB 线一端连接电脑，另一端与系统板上的 USB_UART 端口相连接。需要注意的是，大 家在第一次做串口实验时，需要安装 USB 的串口驱动程序，该程序位于资料盘的“6_软件资料\1_软件\CH340

驱动(USB 串口驱动)_XP_WIN7 共用”文件夹下。串口测试需要在电脑中打开串口调试助手才能完成通信， 我们资料盘中提供了几种调试助手，本次测试使用的是“XCOM”调试助手，该软件位于“6_软件资料\1_ 软件\串口调试助手\XCOM（ALIENTEK 官方推荐）”文件夹下。 点击“XCOM”，打开串口助手界面，下拉“串口选择”，串口选择 COM 口（不同电脑的不同 USB 口串口号可能会不一样，根据自己的电脑进行选择，这里选择的是 COM7:USB-SERIAL CH340），下拉“波 特率”，选择 115200，不勾选“16 进制显示/发送”，不勾选“发送新行”，点击黑色按钮“打开串口”， 按钮变为红色后即串口成功打开。串口打开和设置完成后的界面如下图所示。

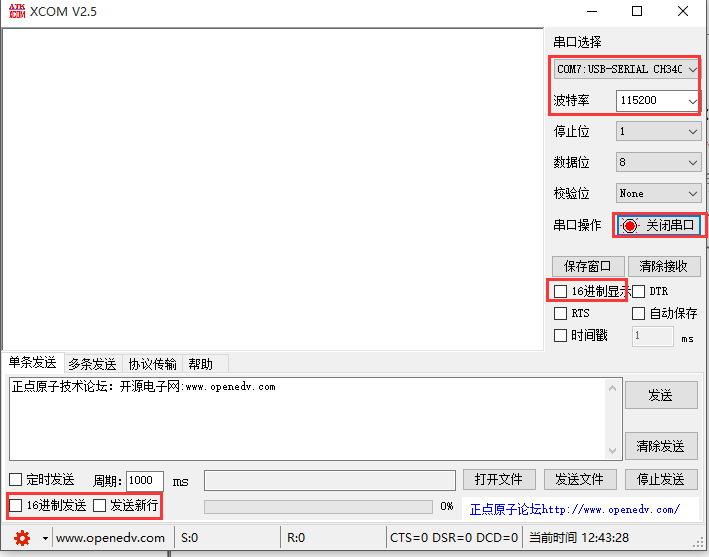
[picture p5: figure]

图 1.5 串口助手界面
我们在下面的发送框输入 5A，点击发送，可以看到上面的接收框通过回环接收了 5A。证明串口没有 问题。

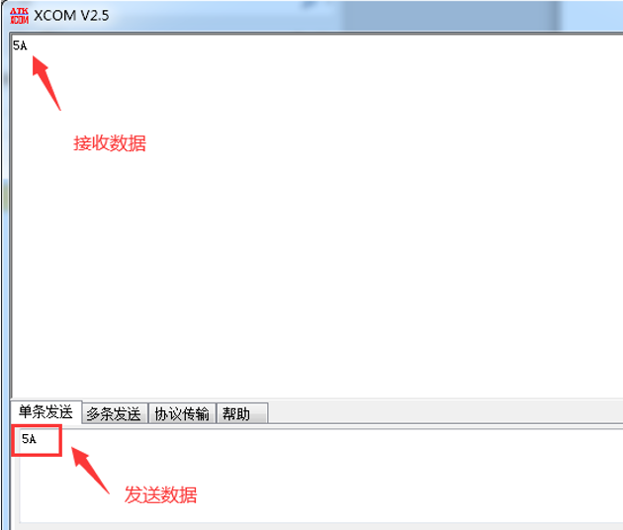
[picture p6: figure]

图 1.6 串口正常效果展示
至此，E10 最小系统板综合测试实验硬件测试完成。
2. 开始学习 E10 最小系统板

在硬件检测完了之后，就可以开始学习 E10 最小系统板了。先安装 Quartus 软件，安装方法请参考系统 板光盘资料：《E10 最小系统板之 FPGA 开发指南.pdf》，打开后找到第四章：Quartus 软件的安装和使用 →4.1 节 Quartus 软件的安装。完成之后，就可以跟着《E10 最小系统板之 FPGA 开发指南.pdf》学习 FPGA 了。需要说明的是，E10 最小系统板板载的外设较少，暂未规划录制视频，大家可以参考开拓者 FPGA 开 发板的视频教程，开拓者 FPGA 开发板的主控芯片和 E10 最小系统板的主控芯片一致。

3. FAQ
3.1. USB 串口驱动安装后无法发现 USB 串口？

这个问题，先检查你的 USB 口有没有插对，我们系统板是需要把 USB 线插在 USB_UART 接口才能实 现 USB 串口。如果你已经是插对了口，那么有可能是 USB 线坏了，也有可能是板子有问题。此时你可以尝 试先换过一根 USB 线试试，如果换线还是不行请联系我们解决。

3.2. 发货前我们是否验货？

我们都是经过检验之后的系统板才包装的，所以来到您手上的板子一般都是没问题的。这里不能说绝 对没问题，因为板子在运输途中可能会有损坏。所以收到货后，请先检查系统板是否正常，检查方法如前 面所述。

3.3. 如果学习过程中有疑问怎么办？

学习过程有疑问很正常，如果大家全部直接问我们，肯定会把我们累死，而且很多客户遇到的问题， 都是重复性的。回答重复性的问题很浪费时间，所以我们的建议是：尽量在论坛（论坛地址：http://www.o penedv.com）提问，并且在提问之前，请先在论坛搜索一下论坛，看看是否有人已经提问过了，如果没有， (http://www.openedv.com/) 再提问。这样大家的提问就会积累起来，以后可以让跟多的人直接通过论坛就可以自己解决问题了，目前 我们论坛里面有很大一部分是客户和网友的提问帖，相信这么多的问题里面，肯定有一些是你想要问的。 对于实在很急的问题，你可以直接通过电话/QQ/旺旺联系我们，我们会尽量帮您解决。最后，感谢您选择 ALIENTEK 的产品，祝您身体健康、学习进步。

公司网址：http://www.alientek.com技术论坛：http://www.openedv.com 电话： 020-38271790
传真： 020-36773971

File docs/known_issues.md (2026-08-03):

# Known Issues

本文档用于记录已经暴露的问题（及其当前状态），避免问题因阶段切换或 `plan.md` 更新而丢失。这里记录问题现象、影响范围、暂缓原因、验证方法和关闭条件。

问题状态使用以下口径：

- `Open`：问题已经确认，正在但尚未修复。
- `Fixed`：根因已经修复，并完成相应回归验证。
- `Deferred`：问题确认存在，但明确推迟到后续阶段或版本处理。

## RTL-001：MMIO 子字节访问的寄存器偏移解码不一致

| 项目 | 内容 |
| --- | --- |
| 状态 | `Fixed` |
| 发现日期 | 2026-07-13 |
| 修复日期 | 2026-07-24 |
| 修复版本 | v6.17（提交 `8930f3a`） |
| 影响范围 | 当前主线 RTL、v6.0 UVM DUT 快照 |
| 相关模块 | `rtl/core/mem_stage.sv`、`rtl/soc/data_subsystem.sv`、各 MMIO 外设 |
| 修复内容 | GPIO0、UART0、TIMER0 的寄存器 offset decode 改为 word-aligned offset；保留原始 byte address 与 byte enable 总线语义 |

### 问题说明

CPU 当前向 simple data bus 输出未经对齐的字节地址，同时根据地址低两位生成 `be`，并将写数据移动到对应 byte lane。例如：

- `SB reg+1`：总线地址为 `reg+1`，`be = 4'b0010`。
- `SH reg+2`：总线地址为 `reg+2`，`be = 4'b1100`。

该语义在 data memory 中可以正常工作：RAM 使用地址的 word index 选择存储字，再使用 `be` 更新对应 byte lane。

修复前 GPIO、UART、timer 等 MMIO 外设直接使用完整的低 12 位地址偏移匹配 word-aligned 寄存器地址。因此，访问已定义寄存器内部的非零 byte offset 时，地址无法命中寄存器：

| 访问形式 | 修复前结果 |
| --- | --- |
| 对齐的 `LW/SW reg+0` | 正常命中 |
| `LB/SB reg+0` | 可以命中 |
| `LB/SB reg+1`、`reg+2` 或 `reg+3` | 被识别为未知偏移并返回 access fault |
| `LH/SH reg+0` | 可以命中 |
| 对齐的 `LH/SH reg+2` | 被识别为未知偏移并返回 access fault |

这不是一套完整一致的“MMIO 仅支持 word 访问”规则。外设内部已经使用 `be` 控制 byte lane；若请求使用 word-aligned 地址并携带非零 lane 的 `be`，外设可以处理，但 CPU 生成的等价子字节请求却会因地址偏移不匹配而失败。因此，按当前simple data bus 的“字节地址 + byte enable”口径，应将其视为 RTL 问题。

### UVM 修复前复现证据

2026-07-23 使用固定 seed `1` 运行 `uvm/v6_0/data_subsystem/sim/run_test.sh DS_map_random_test 1`，该 test 在 `0/1/3/8/32/64/127` 七个 response delay 档位下分别配置 DMEM、GPIO0、UART0、TIMER0，并共完成 2100 笔 data-side transaction。

UVM 汇总得到 `UVM_ERROR=52`、`UVM_FATAL=0`。其中 48 条为 GPIO0 已定义 word offset 的非零 byte address 被错误返回 error，例如 `offset=0x014 addr=0x00080015`：scoreboard 按 word-aligned offset 正确识别 `0x014` 是已定义寄存器，而当前 GPIO RTL 直接使用原始偏移 `0x015` 解码，因而返回 access fault。其余 2 条 OUT read mismatch 和 2 条 OE read mismatch 是上述错误拒绝写请求后，DUT 寄存器状态未更新导致的后续可观测结果，不是独立问题。

同一日志中，真正未知的 GPIO0 word offset（例如对齐 offset `0x038`）均返回 error 并被 scoreboard 记录为 expected behavior；DMEM 没有 mismatch/error，wrapper scoreboard 为 `check_num=2100, correct_num=2100, error_num=0`。functional coverage 为 data `96.67%`、behavior `97.12%`。因此该 FAIL 能隔离为 RTL-001 的修复前证据，可用于同 seed 修复后的 PASS 对比。

### 当前定向测试未暴露问题的原因

现有定向测试分别覆盖了 data memory 的子字节访问和 MMIO 的 word 访问，但尚未覆盖“已映射 MMIO 寄存器的合法子字节访问”这一交叉场景：

- `sw/asm/0801_dmem_wait_basic.S` 包含 `SB/LB/LBU` 和 `SH/LH/LHU`，但访问对象是 data memory。RAM 会忽略地址低两位进行 word 选择，再由 `be` 选择 byte lane，因此这些测试能够通过。
- 现有 MMIO 汇编测试主要使用 word-aligned 的 `LW/SW` 访问寄存器，没有产生 `reg+1` 或 `reg+2` 形式的合法子字节请求。
- C 测试通过 `mmio_read32`、`mmio_write32` 等 32-bit 接口访问 MMIO，编译后同样是 word-aligned 的 word load/store。
- `sw/asm/0605_mmio_misaligned_priority.S` 验证的是未对齐 `LW/SW` 的异常优先级。这类请求会在 core 内被判定为 misaligned，并在到达 data subsystem 前被抑制，因而不能覆盖已映射 MMIO 寄存器上的合法 byte/halfword 访问。

所以，当前回归通过只能说明 DMEM 子字节语义和 MMIO word 访问语义分别正确，不能说明 MMIO 子字节访问已经正确实现。

### 修复内容

修复保留 simple data bus 的原始 byte address 语义，未在 `mem_stage` 强制清除地址低两位。GPIO0、UART0、TIMER0 的寄存器 decode 均改为使用 `{full_offset[11:2], 2'b00}` 形成 word-aligned offset，再由原有 `be` 逻辑选择有效 byte lane。

因此 core 继续保留 byte address、MMIO register decode 忽略地址低两位、byte lane 仍由 `be` 决定，三者的职责边界保持一致。真正未定义的 word offset 不发生 alias，仍由各外设输出 `access_fault_o`。

### 验证与关闭依据

修复后使用相同命令和 seed `1` 运行 `uvm/v6_0/data_subsystem/sim/run_test.sh DS_map_random_test 1`，结果从修复前的 `UVM_ERROR=52` 变为 `UVM_ERROR=0`、`UVM_FATAL=0`。同一 2100 笔事务中，simple bus scoreboard 汇总为 `correct_num=819, error_num=0, partial_num=703, skip_num=578`，wrapper scoreboard 为 `check_num=2100, correct_num=2100, error_num=0`，functional coverage 为 data `96.67%`、behavior `100.00%`。

修复前日志中的未知 GPIO0 word offset 在修复后仍返回 error，说明修复没有把未定义寄存器错误 alias 为已定义寄存器。用户已运行现有 Verilator C/ASM 定向自检仿真，结果通过。至此，修复前 FAIL、修复后同 seed PASS、wrapper timing 检查和主线软件回归均具备证据，RTL-001 关闭。

## REG-001：SoC 回归脚本将 FAIL/TIMEOUT 误统计为 PASS

| 项目 | 内容 |
| --- | --- |
| 状态 | `Fixed` |
| 发现日期 | 2026-07-01 |
| 修复日期 | 2026-07-01 |
| 修复版本 | v5.6（提交 `7af8c51`，tag `v5.6-bugfix-regression-stat`） |
| 影响范围 | SoC 汇编和 C directed regression 的结果统计；被掩盖的失败用例包括汇编 `0603_gpio_rw`、C `0651_soc_mmio_smoke` 和 `0652_soc_mmio_gpio_uart` |
| 相关文件 | `sim/soc_asm/run_all.sh`、`sim/soc_c/run_all.sh`、`sw/asm/0603_gpio_rw.S`、`sw/c/0651_soc_mmio_smoke.c`、`sw/c/0652_soc_mmio_gpio_uart.c`、`tb/sv/tb_rv32i_soc.sv`、`rtl/soc/data_subsystem.sv` |

### 问题说明

早期 ASM/C 回归脚本只根据仿真器进程退出码判断单项测试是否通过。testbench 使用 `$fatal`/`$finish` 结束仿真时，退出码不能可靠地区分 PASS、FAIL 和 TIMEOUT；因此，部分已经打印失败或超时信息的测试仍会被脚本计为 PASS，导致回归汇总不可信，并掩盖了后续列出的测试程序问题。

### 修复内容与关联问题

- 两个 `run_all.sh` 均为每个测试保留日志；只有仿真退出码为 0、日志包含 `PASS after `，且不包含 `FAIL after ` 或 `TIMEOUT:` 时才统计为 PASS。否则明确统计为 FAIL，并打印日志路径。
- 统计修复后暴露出 GPIO IN 检查假设错误：`GPIO_IN[31:30]` 由 TB 周期信号驱动，不是固定输入。`0603`、`0651`、`0652` 改为屏蔽高两位，仅比较稳定的 `GPIO_IN[29:0]`。
- TB 中 `gpio0_in[29:0]` 的复位默认值由 `'0` 改为 `30'hA5A55A5A`，与上述用例的默认输入约定一致。
- 同一提交还将 `data_subsystem.sv` 中 `resp_target` 改为显式声明后再连续赋值，修正该处的连续赋值声明问题。

### 验证与关闭依据

修复后的回归入口会把 PASS/FAIL/TIMEOUT 文本结果纳入统计，失败测试不再仅因进程返回码而误报成功。相关 GPIO 用例已按 TB 的实际驱动语义更新，修复提交已随 v5.6 及后续 release 保留。

## REG-002：0757 GPIO 周期中断测试超过 AXI/APB 下的 handler 吞吐边界

| 项目 | 内容 |
| --- | --- |
| 状态 | `Fixed` |
| 发现日期 | 2026-08-02 |
| 修复日期 | 2026-08-03 |
| 修复阶段 | 0836 第 11 章验证收口 |
| 影响范围 | 修复前影响 SoC C 全量回归中的 `0757_gpio_periodic_irq`；未发现其它 C/ASM 用例受影响 |
| 相关文件 | `sw/c/0757_gpio_periodic_irq.c`、`sw/c_runtime/crt0.S`、`tb/sv/tb_rv32i_soc.sv`、`build/soc_c/logs/0757_gpio_periodic_irq.log` |

### 问题说明

0836 将主线 data-side 从固定响应 simple bus wrapper 切换为 AXI-Lite/APB 后，SoC ASM 全量回归为 25/25 PASS，C 回归为 12/13 PASS；唯一失败项为 `0757_gpio_periodic_irq`。该测试让 TB 每 200 拍翻转一次 GPIO bit30、每 2000 拍翻转一次 bit31，并在 C trap handler 中读取 TIMER0.MTIME，以相邻 handler 采样时间估算 GPIO 边沿周期。

失败日志汇总为 `B30 CNT=35 AVG=299`、`B31 CNT=6 AVG=1985`、`trap_cnt=35`。bit31 的慢周期仍接近预期 2000，未发现 TIMER0 计数变慢、GPIO 中断不触发或 trap 无法返回；bit30 的 299 也不是“200 拍真实周期加上固定 99 拍总线延迟”，而是 handler 吞吐不足后发生 GPIO pending 合并和采样混叠的结果。

### 根因与日志证据

CPU trap entry 先跳转到 `crt0.S::__trap_entry`，不会立即执行 C handler 中的 TIMER0 读取。入口需要向 DMEM 保存完整 GPR 上下文，C handler 本身还会访问全局统计变量、TIMER0、GPIO IRQ_STATUS 和 IRQ_PENDING，返回前再从 DMEM 恢复完整上下文。切换到 AXI-Lite RAM 后，每笔栈保存、栈恢复和全局变量访问都经历正常的 AXI request/response 延迟，因此整轮 handler 已超过 bit30 的 200 拍输入周期。

第一轮日志显示：cycle 1800 发生 trap entry；cycle 1805 至 1896 完成 31 笔上下文保存相关 DMEM store；cycle 1923 才发起 TIMER0.MTIME read；cycle 1957 写 GPIO IRQ_PENDING 清除当前 pending；cycle 1979 至 2069 完成 31 笔上下文恢复相关 DMEM load；cycle 2072 因期间又产生 GPIO pending 而直接再次进入 trap。后续 TIMER0.MTIME read 出现在 cycle 1923、2195、2521、2792、3121、3392，间隔交替接近 272/326 拍，平均约为 299。

GPIO `IRQ_PENDING` 的每个输入只保存一个 pending bit，不是边沿计数器或事件 FIFO。handler 尚未完成时到来的多个 bit30 边沿只能把同一位保持为 1，无法逐个累计；W1C 和 MRET 前后的新边沿还会决定是立即重入还是先返回主流程。因此，软件记录的是未被合并的部分 pending 事件，不再是每个 200 拍硬件边沿。

### 修复判断

当前证据不支持将本问题归类为 AXI/APB、TIMER0、GPIO 或 trap 精确提交的 RTL 功能错误。它暴露的是原测试隐含的性能前提：完整 C handler 必须在最快 GPIO 边沿间隔内完成。固定响应 simple bus 下该前提成立，AXI-Lite/APB 引入正常协议延迟后不再成立。

不能仅把 bit30 允许范围从 180..220 放宽到 299 附近，因为 299 是当前 handler 执行时间、GPIO 相位和 pending 合并共同形成的采样结果，不是稳定的 GPIO 输入周期。

### 修复内容

保留 `0757_gpio_periodic_irq` 作为 GPIO 周期输入精确测量测试，但把 bit30 的翻转间隔从 200 拍提高到 500 拍，使其大于当前完整 C handler 的实际处理时间；bit31 仍保持 2000 拍。测试的 bit30 合法范围同步改为 450～550，预期快慢周期比由共享常量自动推导为 4，避免 testbench 与软件阈值再次漂移。

该修复没有放宽到原失败值 299 附近，也没有修改 GPIO、TIMER0、trap 或 AXI/APB RTL。200 拍输入下的 pending 合并仍是硬件模型的既有边界；若后续要逐个统计这类高频边沿，应另建吞吐边界测试或改用更短 handler/硬件计数机制。

### 验证与关闭依据

修复后 `build/soc_c/logs/0757_gpio_periodic_irq.log` 记录 `B30 CNT=21 AVG=500`、`B31 CNT=6 AVG=2000`、`RATIO(B31/B30)=4 (expect 4)`，测试最终 PASS。该结果同时证明两路 GPIO 周期输入、TIMER0.MTIME 采样和 C trap 返回路径在调整后的吞吐边界内行为一致。

随后运行 SoC 全量回归，ASM 为 25/25 PASS，C 为 13/13 PASS；原先受影响的 `0757_gpio_periodic_irq` 已恢复通过，依赖旧 response-delay mailbox 的 0801/0802/0804/0805/0853/0856 也已按当前 AXI-Lite/APB 实现边界清理并通过。至此 REG-002 关闭。

## UVM-001：DMEM scoreboard 截断地址导致随机回归误报

| 项目 | 内容 |
| --- | --- |
| 状态 | `Fixed` |
| 发现日期 | 2026-07-23 |
| 修复日期 | 2026-07-23 |
| 影响范围 | `uvm/v6_0/data_subsystem` 的 DMEM 随机测试及其 scoreboard 结果 |
| 相关文件 | `uvm/v6_0/data_subsystem/tb/checker/simple_bus_scoreboard.svh`、`uvm/v6_0/data_subsystem/tb/seq/simple_bus_sequences.svh`、`uvm/v6_0/data_subsystem/tb/virtual/data_subsystem_virtual_sequences.svh` |
| 关联 RTL | `rtl/mem/simple_ram.sv`（本问题中未发现 RTL 读写错误） |

### 问题说明

`DS_dmem_random_test_200` 通过，但 `DS_dmem_random_test_2000` 失败并报告 108 个 DMEM read mismatch。根因是 scoreboard 的 `addr_2_dmem_word_addr()` 以 `{addr[DMEM_ADDR_WIDTH-3:2], 2'b00}` 生成参考模型 key。当前 `DMEM_ADDR_WIDTH = 16`，该表达式没有先减去 `DMEM_BASE`，并且丢弃了 DMEM offset 的高两位，导致相隔 `0x4000` 字节的不同 DMEM 地址发生别名。

首个误报可由日志直接确认：

- 先前写 `0x0004_6a81`，`be=4'b1101`，`wdata=0x3746_d5ca`。
- 后续读 `0x0004_aa81`；两地址相差 `0x4000`，在 256 KiB DMEM 中是不同存储位置，RTL 正确返回初始化值 `0`。
- scoreboard 将二者都映射为 key `0x0000_2a80`，错误地期望前一笔写合并后的值 `0x3746_00ca`，从而报 mismatch。

RTL 的 `simple_ram` 使用 `(addr_i - DMEM_BASE) >> 2` 作为 16-bit word index，能区分上述两个地址。因此，这些失败是 golden model 的误报，不能据此判定 RTL 存在 DMEM 数据损坏。

### 为什么 200 次回归会通过

`DS_dmem_random_test_200` 的汇总为 `correct_num=0, error_num=0, skip_num=200`：它没有形成一次被 scoreboard 正确比较的写后读，只是尚未随机触发该错误别名。2000 次运行扩大了随机碰撞概率，最终得到 `correct_num=18, error_num=108, skip_num=1874`。

此外，当前随机激励的地址池实际上未跨事务生效：virtual sequence 在每轮 `repeat` 内新建 `simple_bus_dmem_random_access_seq`，并将 `num_items` 设为 1。该 sequence 内维护的 `written_word_keys` 和 `written_word_seen` 会在唯一一笔请求结束后随对象丢弃。因此后续 read 无法从先前 write 的地址池中选择地址，当前随机测试主要是读从未写过的位置；200 次日志的 `correct_num=0` 正是这一问题的表现。

### 随机地址池的修复方式

保留 `simple_bus_dmem_random_access_seq` 作为地址池的唯一所有者，但将 `bus_seq` 的创建移至 virtual sequence 的 `repeat` 外。随后在每轮中启动同一个 `bus_seq`，并保持 `bus_seq.num_items = 1`；这样该对象的已写地址池能覆盖整个 200/2000 笔访问流。wrapper sequence 也可在循环外创建并在每轮重复 `start()`，其 `body()` 每次都会重新随机生成一笔 delay 配置，不会复用上次的配置值。推荐结构如下：

```systemverilog
bus_seq = simple_bus_dmem_random_access_seq::type_id::create("bus_seq");
bus_seq.num_items = 1;
wrp_seq = wrapper_dmem_cfg_random_seq::type_id::create("wrp_seq");
wrp_seq.num_items = 1;

repeat (num_items) begin
    wrp_seq.start(p_sequencer.wrp_sequencer);
    bus_seq.start(p_sequencer.bus_sequencer);
end
```

`simple_bus_dmem_random_access_seq` 当前以 `addr[XLEN-1:2]` 保存 word 地址，足以区分完整 DMEM 空间；其地址池本身不需要采用 scoreboard 现有的错误截断方式。应确保其生命周期按上述方式延续，并可补充显式清池方法以便同一个 sequence 对象被不同测试阶段复用时重置状态。

### 预期修复方向

scoreboard 应以完整的 DMEM 相对 byte offset 对齐后作为 key，例如使用 `(addr - DMEM_BASE) >> 2` 的 16-bit word index；该口径应与 RAM 的实际 16-bit word index / 256 KiB 容量一致。与此同时，按上述方式延续随机 sequence 的地址池生命周期，确保产生真实的写后读事务。

### 验证与关闭条件

- 修复后使用原测试、原随机种子运行 `DS_dmem_random_test_200` 与 `DS_dmem_random_test_2000`，两者均无 UVM error 即可关闭。

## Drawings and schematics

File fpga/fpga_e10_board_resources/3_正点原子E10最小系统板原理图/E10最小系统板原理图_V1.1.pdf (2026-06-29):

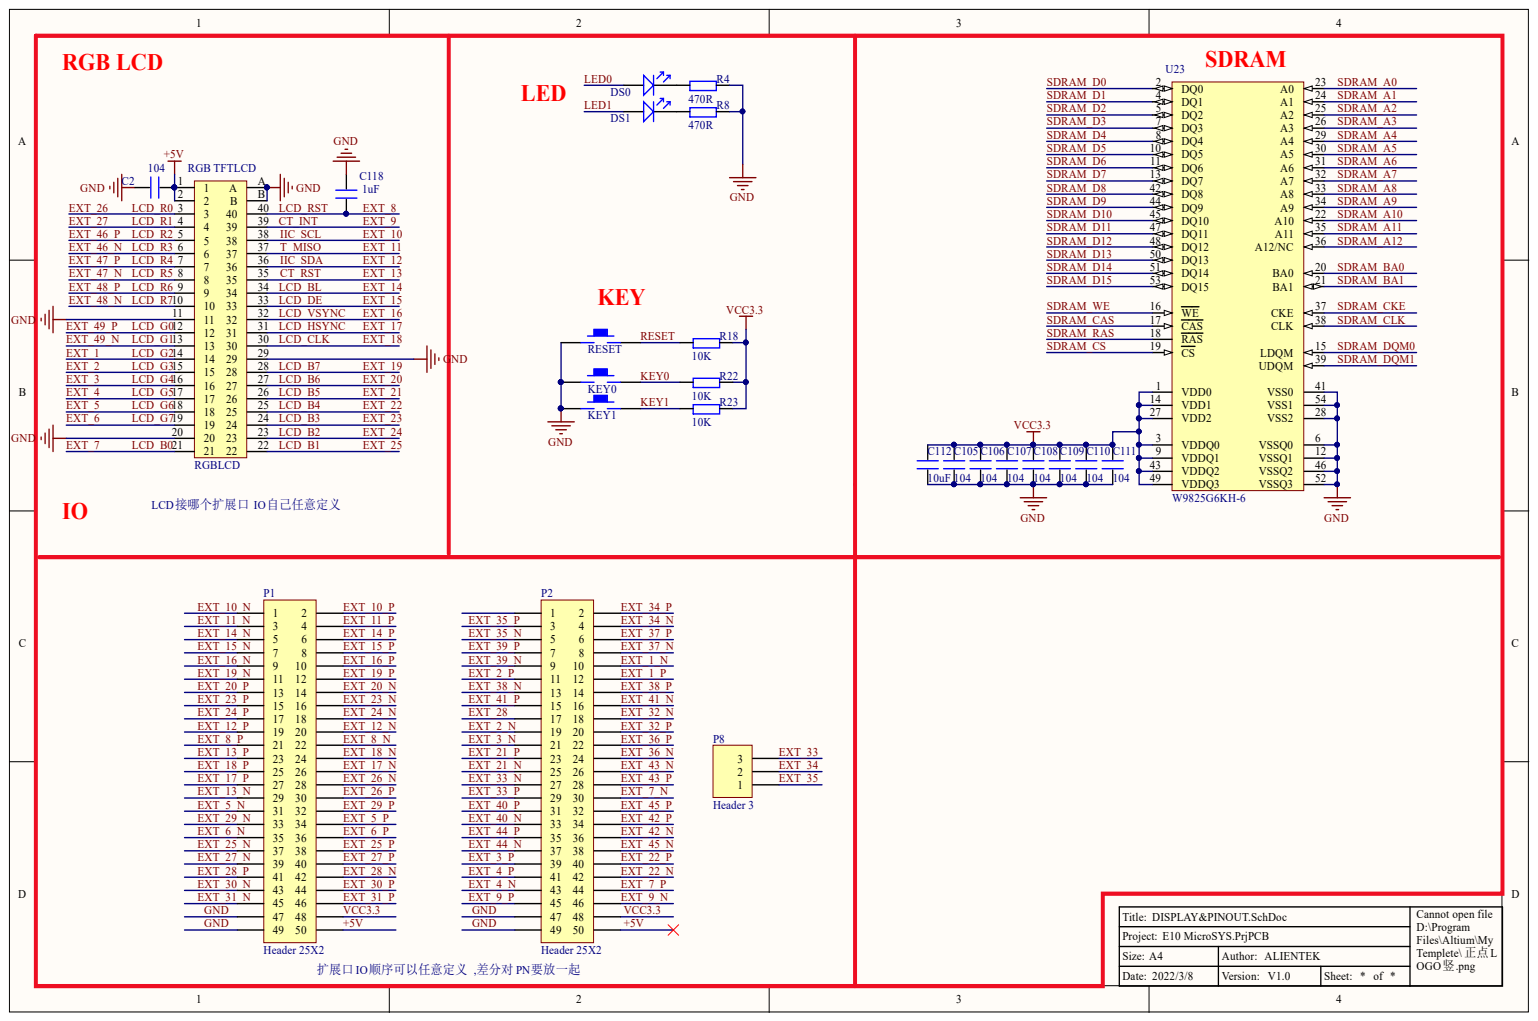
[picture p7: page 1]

扩展口 IO顺序可以任意定义 ,差分对 PN要放一起

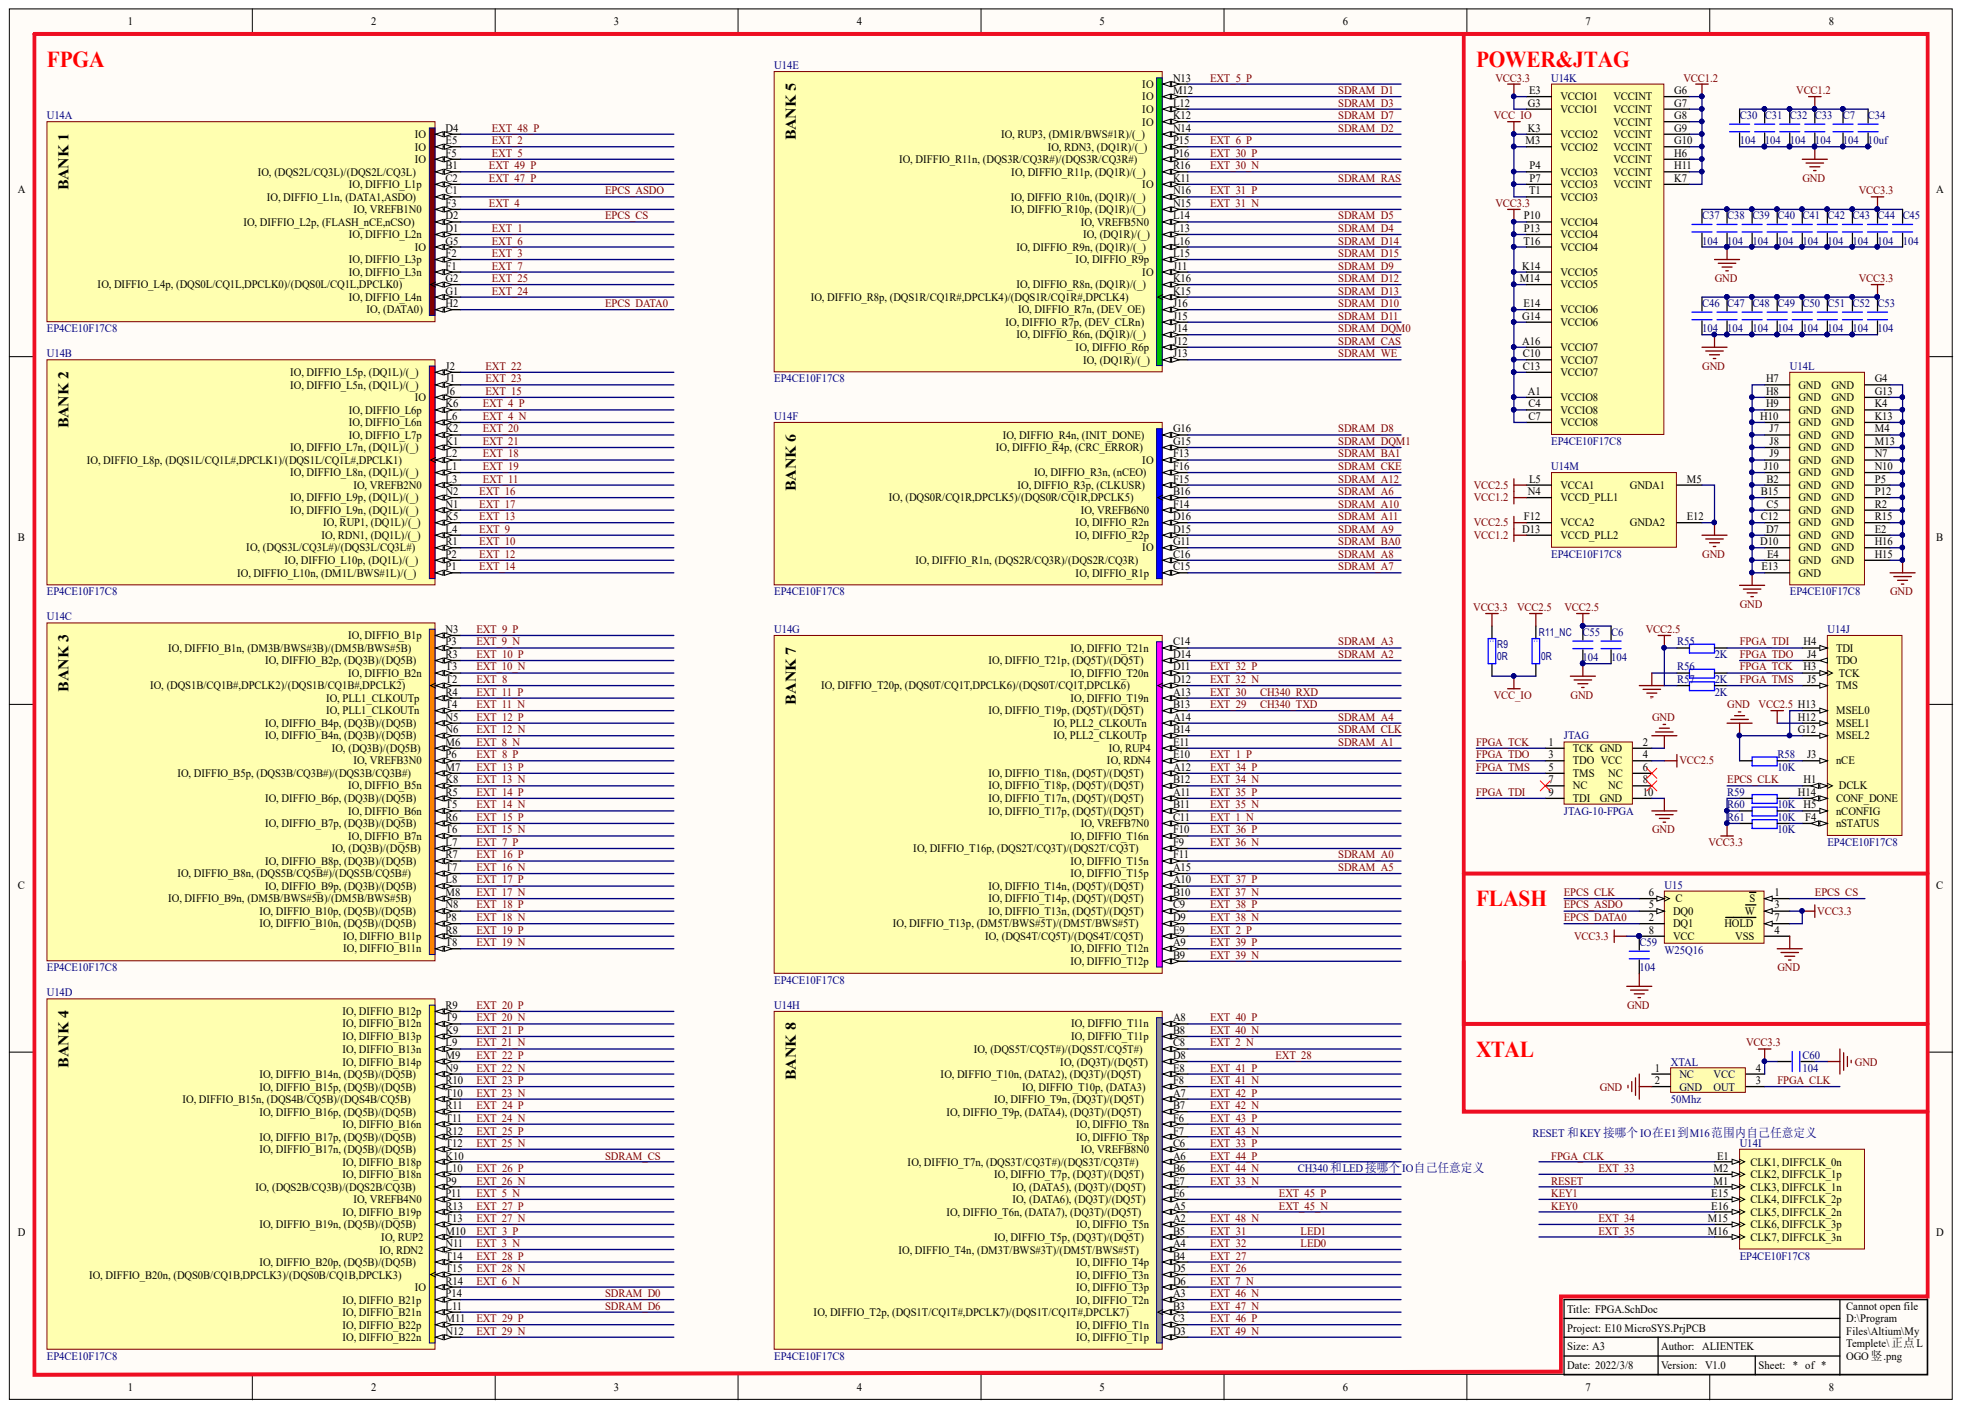
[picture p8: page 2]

H 8 | G13
H 9 | K4
H10 | K13

J 9 | N 7
J10 | N10

C 5 | R2
C12 | R15

H12
G12

Size: A | Author : A L I E N T E K
2022/3/ | Ver s ion: V1.0 | Sheet : * of *

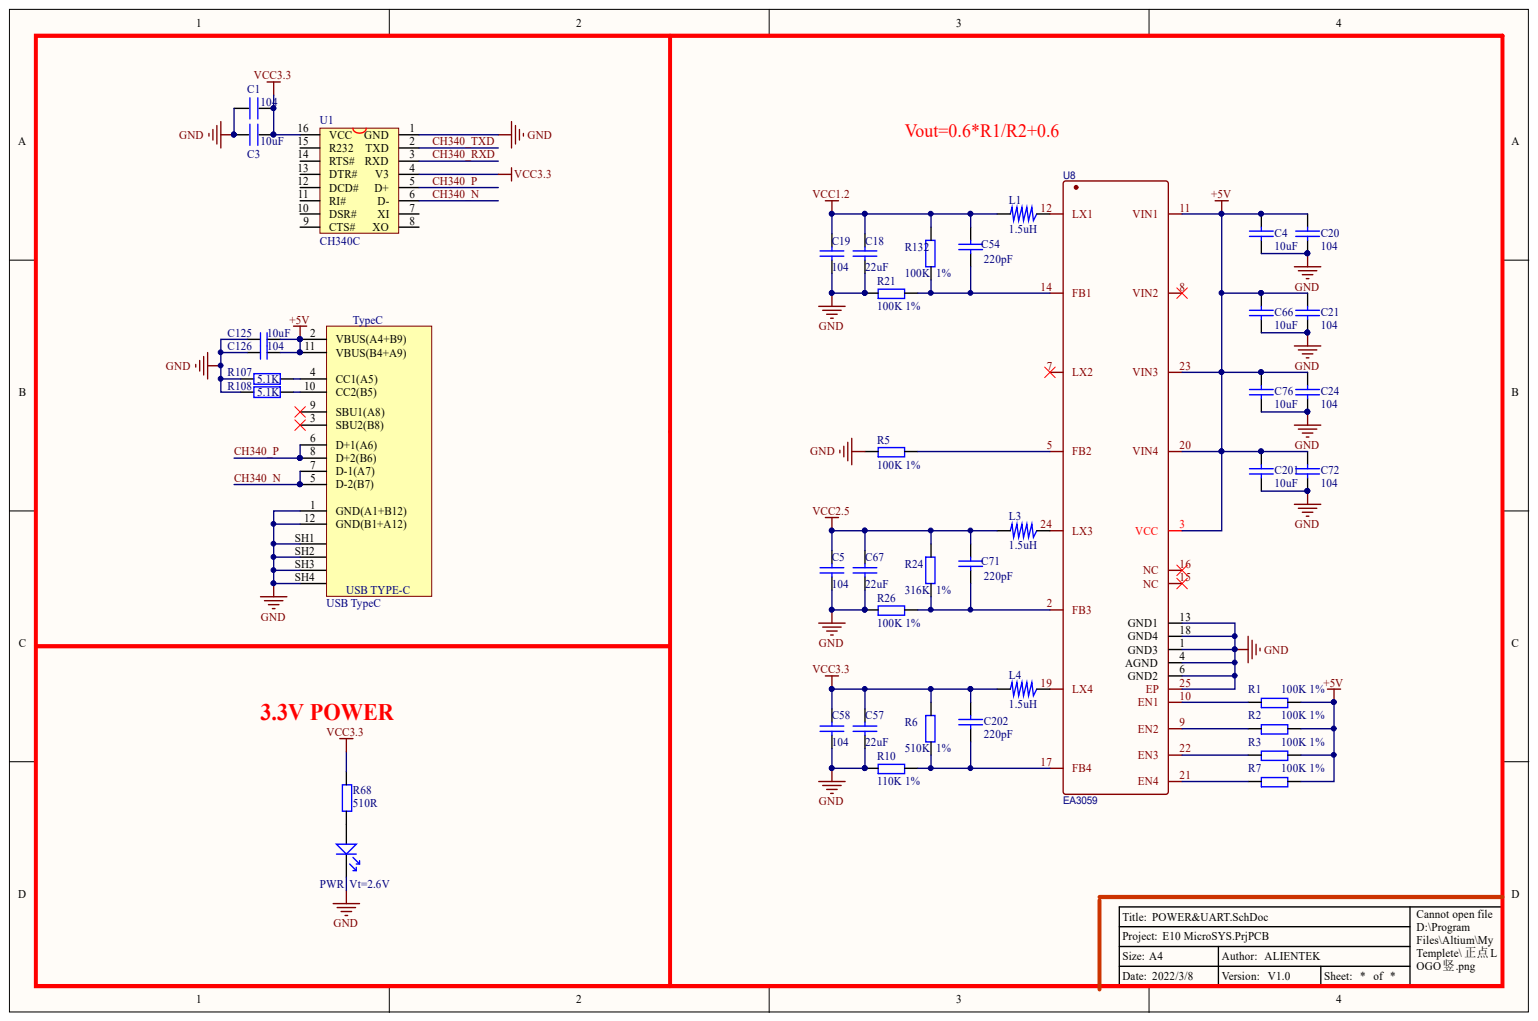
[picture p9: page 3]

Size: A 4 | A u t h or: A LIE N T E K

/ / | Vers i o n : V 1.0 | Sheet : * o f *

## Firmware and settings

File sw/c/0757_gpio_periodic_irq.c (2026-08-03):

/*
 * 0757_gpio_periodic_irq.c — TB 固定周期 GPIO 输入中断精确测量。
 *
 * 目的：
 *   - 用 TIMER0.MTIME 精确测量 bit30/bit31 的边沿间隔。
 *   - 验证 bit30 双边沿间隔 ≈ 500 周期（TB_GPIO0_FAST_TOGGLE_CYCLES）。
 *   - 验证 bit31 双边沿间隔 ≈ 2000 周期（TB_GPIO0_SLOW_TOGGLE_CYCLES）。
 *   - 通过 UART TX 输出测量结果，便于观察实际值与目标值的偏差。
 *
 * TB 硬件驱动（tb_rv32i_soc.sv initial fork 线程）：
 *   - gpio0_in[30] 每 500 拍翻转一次（TB_GPIO0_FAST_TOGGLE_CYCLES）。
 *   - gpio0_in[31] 每 2000 拍翻转一次（TB_GPIO0_SLOW_TOGGLE_CYCLES）。
 *   - 双边沿触发 → 每次翻转产生一个 MEIP。
 *
 * 测量原理：
 *   - TIMER0 的 MTIME 在每个 clock cycle 自增 1（free-running counter）。
 *   - handler 记录每个 bit 的首次边沿 MTIME 和末次边沿 MTIME。
 *   - main 汇总后计算平均间隔：
 *       avg_bitN_interval = (bitN_last_mtime - bitN_first_mtime) / (bitN_count - 1)
 *   - 中断响应延迟在每次边沿中近似恒定，相减后延迟被抵消。
 *     测量值 = TB 翻转周期 + 噪声。噪声主要来自：
 *       (a) 被测指令流与 TB 翻转边沿的对齐抖动
 *       (b) handler 执行时间和 W1C 周期的微小波动
 *   - 快速周期必须长于完整 C handler 的处理时间，避免多个边沿在 pending
 *     清除前合并，使软件观测到的间隔成为输入周期的整数倍。
 *
 * 通过条件：
 *   - bit30_count >= 10：快周期采集足够样本。
 *   - bit31_count >= 6： 慢周期采集足够样本。
 *   - avg_bit30_interval ∈ [450, 550]：半周期 500 ±10%。
 *   - avg_bit31_interval ∈ [1800, 2200]：半周期 2000 ±10%。
 *
 * 失败场景：
 *   1: bit30_count < 10（中断未正常触发或 handler 未正确计数）
 *   2: bit31_count < 6
 *   3: avg_bit30_interval 超出 [450, 550]（快周期频率偏差）
 *   4: avg_bit31_interval 超出 [1800, 2200]（慢周期频率偏差）
 */
#include "platform.h"
#include "tb_rv32i_soc_test.h"

#define BIT30_MASK       TB_GPIO0_FAST_PERIODIC_MASK
#define BIT31_MASK       TB_GPIO0_SLOW_PERIODIC_MASK
#define MIN_30_COUNT     RV32I_U32_C(10)
#define MIN_31_COUNT     RV32I_U32_C(6)
#define MIN_30_INTERVAL  (TB_GPIO0_FAST_TOGGLE_CYCLES * RV32I_U32_C(9) / RV32I_U32_C(10))
#define MAX_30_INTERVAL  (TB_GPIO0_FAST_TOGGLE_CYCLES * RV32I_U32_C(11) / RV32I_U32_C(10))
#define MIN_31_INTERVAL  (TB_GPIO0_SLOW_TOGGLE_CYCLES * RV32I_U32_C(9) / RV32I_U32_C(10))
#define MAX_31_INTERVAL  (TB_GPIO0_SLOW_TOGGLE_CYCLES * RV32I_U32_C(11) / RV32I_U32_C(10))
#define EXPECTED_RATIO   (TB_GPIO0_SLOW_TOGGLE_CYCLES / TB_GPIO0_FAST_TOGGLE_CYCLES)

/* handler 统计数据 */
static volatile unsigned int irq_count;
static volatile unsigned int bit30_count;
static volatile unsigned int bit31_count;
static volatile unsigned int bit30_first_mtime;
static volatile unsigned int bit30_last_mtime;
static volatile unsigned int bit31_first_mtime;
static volatile unsigned int bit31_last_mtime;
static volatile unsigned int test_complete;

/* 软件除法 — RV32I 不含 DIV 指令 */
static unsigned int div_u32(unsigned int a, unsigned int b)
{
    unsigned int q = 0, r = 0;
    int i;
    if (b == 0u) return 0u;
    for (i = 31; i >= 0; i--) {
        r = (r << 1) | ((a >> (unsigned int)i) & 1u);
        if (r >= b) {
            r -= b;
            q |= (1u << (unsigned int)i);
        }
    }
    return q;
}

/* 带余数的除法，供十进制打印使用 */
static unsigned int divmod_u32(unsigned int a, unsigned int b, unsigned int *rem)
{
    unsigned int q = 0, r = 0;
    int i;
    if (b == 0u) { *rem = 0u; return 0u; }
    for (i = 31; i >= 0; i--) {
        r = (r << 1) | ((a >> (unsigned int)i) & 1u);
        if (r >= b) {
            r -= b;
            q |= (1u << (unsigned int)i);
        }
    }
    *rem = r;
    return q;
}

/* UART 输出辅助 */
static void uart_print_str(const char *s)
{
    while (*s) {
        uart_putc(UART0_BASE, *s++);
    }
}

static void uart_print_dec32(unsigned int val)
{
    char buf[12];
    int i = 0, j;
    unsigned int q, r;
    if (val == 0u) {
        uart_putc(UART0_BASE, '0');
        return;
    }
    q = val;
    while (q > 0u) {
        q = divmod_u32(q, 10u, &r);
        buf[i++] = (char)('0' + r);
    }
    for (j = i - 1; j >= 0; j--) {
        uart_putc(UART0_BASE, buf[j]);
    }
}

/*
 * __trap_handler_c — C trap handler。
 *
 * 累加 bit30/bit31 边沿计数并记录首末次 MTIME。
 * 所有 MMIO 访问均经过 AXI-Lite 到 APB 的固定响应路径。
 * W1C 清 pending 后返回 mepc，由 crt0.S 执行 mret。
 *
 * 注意：达到阈值后写 IRQ_EN=0 而非关 mstatus.MIE，
 * 因为 mret 会从 MPIE 恢复 MIE，写 MIE=0 无效。
 */
unsigned int __trap_handler_c(unsigned int mcause, unsigned int mepc, unsigned int mtval)
{
    unsigned int gpio_status;
    unsigned int now;

    (void)mtval;

    if (((mcause & MCAUSE_INTERRUPT_BIT) != 0u) &&
        ((mcause & MCAUSE_CODE_MASK) == 11u)) {

        irq_count++;
        now = mmio_read32(timer32_reg(TIMER0_BASE, TIMER32_MTIME_OFFSET));
        gpio_status = mmio_read32(gpio_reg(GPIO0_BASE, GPIO_IRQ_STATUS_OFFSET));

        if (gpio_status & BIT30_MASK) {
            if (bit30_count == 0u) {
                bit30_first_mtime = now;
            }
            bit30_last_mtime = now;
            bit30_count++;
        }
        if (gpio_status & BIT31_MASK) {
            if (bit31_count == 0u) {
                bit31_first_mtime = now;
            }
            bit31_last_mtime = now;
            bit31_count++;
        }

        /* W1C — 清 IRQ_STATUS */
        mmio_write32(gpio_reg(GPIO0_BASE, GPIO_IRQ_PENDING_OFFSET), gpio_status);

        /* 达到阈值后关 IRQ_EN 阻止后续中断 */
        if (!test_complete && bit30_count >= MIN_30_COUNT && bit31_count >= MIN_31_COUNT) {
            test_complete = 1u;
            mmio_write32(gpio_reg(GPIO0_BASE, GPIO_IRQ_EN_OFFSET), 0u);
        }

        return mepc;
    }

    /* 非 MEIP 的中断/异常 → 挂起 */
    for (;;) {
    }
}

int main(void)
{
    unsigned int timeout;
    unsigned int avg30 = 0u, avg31 = 0u, ratio = 0u;

    /* ----------------------------------------------------------------
     * 关中断 + 初始化外设
     * ---------------------------------------------------------------- */

    csr_clear_mstatus(MSTATUS_MIE);
    csr_write_mie(0u);

    /* 初始化 UART TX — 用于输出测量报告 */
    uart_enable_tx(UART0_BASE);

    /* 清 GPIO 中断配置 */
    mmio_write32(gpio_reg(GPIO0_BASE, GPIO_IRQ_EN_OFFSET), 0u);
    mmio_write32(gpio_reg(GPIO0_BASE, GPIO_IRQ_RISE_EN_OFFSET), 0u);
    mmio_write32(gpio_reg(GPIO0_BASE, GPIO_IRQ_FALL_EN_OFFSET), 0u);
    mmio_write32(gpio_reg(GPIO0_BASE, GPIO_IRQ_PENDING_OFFSET), 0xFFFFFFFFu);

    /* 初始化 TIMER0 — MTIME 作为 free-running cycle counter */
    mmio_write32(timer32_reg(TIMER0_BASE, TIMER32_CTRL_OFFSET), 0u);
    mmio_write32(timer32_reg(TIMER0_BASE, TIMER32_MTIME_OFFSET), 0u);
    mmio_write32(timer32_reg(TIMER0_BASE, TIMER32_MTIMECMP_OFFSET), 0u);
    mmio_write32(timer32_reg(TIMER0_BASE, TIMER32_CTRL_OFFSET), TIMER32_CTRL_ENABLE);

    /* 等几拍让 GPIO sync / TB 翻转稳下来 */
    for (volatile int i = 0; i < 100; i++) {
    }

    /* ----------------------------------------------------------------
     * 配置 bit[31:30] 双边沿触发
     * ---------------------------------------------------------------- */

    mmio_write32(gpio_reg(GPIO0_BASE, GPIO_IRQ_RISE_EN_OFFSET), BIT30_MASK | BIT31_MASK);
    mmio_write32(gpio_reg(GPIO0_BASE, GPIO_IRQ_FALL_EN_OFFSET), BIT30_MASK | BIT31_MASK);
    mmio_write32(gpio_reg(GPIO0_BASE, GPIO_IRQ_EN_OFFSET), BIT30_MASK | BIT31_MASK);
    mmio_write32(gpio_reg(GPIO0_BASE, GPIO_IRQ_PENDING_OFFSET), BIT30_MASK | BIT31_MASK);

    /* 开 MEIE + MIE */
    csr_write_mie(MIE_MEIE);
    csr_set_mstatus(MSTATUS_MIE);

    /* ----------------------------------------------------------------
     * 等待 handler 收集数据达到阈值
     * ---------------------------------------------------------------- */

    timeout = 100000u;
    while (!test_complete && timeout > 0u) {
        timeout--;
    }

    /* 关中断 */
    csr_clear_mstatus(MSTATUS_MIE);
    csr_clear_mie(MIE_MEIE);

    /* ----------------------------------------------------------------
     * 计算平均间隔
     * ---------------------------------------------------------------- */

    if (bit30_count > 1u) {
        avg30 = div_u32(bit30_last_mtime - bit30_first_mtime, bit30_count - 1u);
    }
    if (bit31_count > 1u) {
        avg31 = div_u32(bit31_last_mtime - bit31_first_mtime, bit31_count - 1u);
    }
    if (avg30 > 0u) {
        ratio = div_u32(avg31, avg30);
    }

    /* ----------------------------------------------------------------
     * UART 输出测量报告
     * ---------------------------------------------------------------- */

    uart_print_str("\n--- GPIO PERIODIC IRQ ---\n");
    uart_print_str("B30 CNT=");
    uart_print_dec32(bit30_count);
    uart_print_str(" AVG=");
    uart_print_dec32(avg30);
    uart_print_str("\n");

    uart_print_str("B31 CNT=");
    uart_print_dec32(bit31_count);
    uart_print_str(" AVG=");
    uart_print_dec32(avg31);
    uart_print_str("\n");

    uart_print_str("RATIO(B31/B30)=");
    uart_print_dec32(ratio);
    uart_print_str(" (expect ");
    uart_print_dec32(EXPECTED_RATIO);
    uart_print_str(")\n");

    /* ----------------------------------------------------------------
     * 验证
     * ---------------------------------------------------------------- */
    if (bit30_count < MIN_30_COUNT) {
        uart_print_str("FAIL: bit30 count too low\n");
        return 1;
    }
    if (bit31_count < MIN_31_COUNT) {
        uart_print_str("FAIL: bit31 count too low\n");
        return 2;
    }
    if (avg30 < MIN_30_INTERVAL || avg30 > MAX_30_INTERVAL) {
        uart_print_str("FAIL: bit30 avg interval out of range\n");
        return 3;
    }
    if (avg31 < MIN_31_INTERVAL || avg31 > MAX_31_INTERVAL) {
        uart_print_str("FAIL: bit31 avg interval out of range\n");
        return 4;
    }

    uart_print_str("PASS\n");
    return 0u;
}

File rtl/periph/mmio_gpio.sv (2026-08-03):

//------------------------------------------------------------------------------
// 文件      : rtl/periph/mmio_gpio.sv
// 用途      : GPIO0 最小固定响应 MMIO 寄存器块。
//
// 规范：
//   - 输入端口使用 _i 后缀，输出端口使用 _o 后缀。
//   - 本模块是固定响应 MMIO register block，本体不包含 ready/valid backpressure。
//   - valid_i 由外层 bus adapter 在一次 register access 完成时拉高一拍。
//   - 外设寄存器访问和读写副作用只发生在 valid_i 访问脉冲当拍，不随上层 response stall 重复触发。
//   - GPIO_WIDTH 表示本 GPIO block 的引脚数，当前限制为 1..XLEN。
//   - access_fault_o 表示地址已命中本外设窗口，但 offset 未定义。真正未映射地址由 data_subsystem 汇总判断。
//
// 功能：
//   - 普通 RW 寄存器按 byte enable 更新。
//   - OUT（offset 0x00）是 RW，保存 GPIO 输出值。
//   - IN（offset 0x04）是 RO，返回两级同步后的 gpio_in_i。
//   - OE（offset 0x08）是 RW，保存 GPIO 输出使能。
//   - IRQ_EN/IRQ_RISE_EN/IRQ_FALL_EN/IRQ_HIGH_EN/IRQ_LOW_EN 是 RW 中断配置寄存器。
//   - IRQ_PENDING 是 R/W1C pending 寄存器，软件写 1 清除对应 bit，硬件触发同拍 set 优先。
//   - IRQ_STATUS 是 RO，返回 IRQ_PENDING & IRQ_EN。
//   - gpio_irq_o 是 level interrupt 输出。
//   - gpio_in_i 先同步到 clk_i 域，再用于 IN 读值和 interrupt 触发检测。
//   - 当前只对未知 offset 输出 access_fault_o；写 RO 寄存器等无害访问先忽略。
//------------------------------------------------------------------------------

`default_nettype none

module mmio_gpio #(
    parameter logic [core_pkg::XLEN-1:0] BASE_ADDR  = soc_pkg::GPIO0_BASE,          // 起始地址分配
    parameter int unsigned               GPIO_WIDTH = 32                            // GPIO 引脚个数，当前应保持 1..XLEN
)(
    input  logic                      clk_i,
    input  logic                      rst_n_i,

    input  logic                      valid_i,         // 外层 bus adapter 完成一次 GPIO 访问；地址已命中 GPIO 窗口。
    input  logic                      we_i,            // 本拍是对 GPIO 的 store。
    input  logic [3:0]                be_i,            // byte enable，bit0 对应 wdata_i[7:0]。
    input  logic [core_pkg::XLEN-1:0] addr_i,          // 完整 byte address，内部用 addr_i - BASE_ADDR 得到 offset。
    input  logic [core_pkg::XLEN-1:0] wdata_i,         // store 写数据。
    output logic [core_pkg::XLEN-1:0] rdata_o,         // 读返回数据。
    output logic                      access_fault_o,  // offset 不存在时拉高。后续也可用于权限/访问类型错误。

    input  logic [GPIO_WIDTH-1:0]     gpio_in_i,       // 来自 SoC/testbench 的 GPIO 输入。
    output logic [GPIO_WIDTH-1:0]     gpio_out_o,      // GPIO OUT 寄存器值。
    output logic [GPIO_WIDTH-1:0]     gpio_oe_o,       // GPIO OE 寄存器值。

    output logic                      gpio_irq_o       // GPIO 产生中断，电平信号
);

    import core_pkg::*;
    import soc_pkg::*;

    // 信号声明(兼容 VCS 要求)
    logic offset_illegal;
    wire  [core_pkg::XLEN-1:0] pending_valid;       // 将要挂起的位
    logic [core_pkg::XLEN-1:0] clear_pending_mask;  // 本拍要被清掉的挂起位

    // GPIO 输入来自 SoC/testbench 外部，可能跨时钟域；先同步到 clk_i 域。
    reg [GPIO_WIDTH-1:0] gpio_in_meta, gpio_in_sync, gpio_in_sync_q;
    always_ff @(posedge clk_i or negedge rst_n_i) begin : GPIO_SYNC
        if (!rst_n_i) begin
            gpio_in_meta  <= '0;
            gpio_in_sync   <= '0;
            gpio_in_sync_q <= '0;
        end
        else begin
            gpio_in_meta   <= gpio_in_i;
            gpio_in_sync   <= gpio_in_meta;
            gpio_in_sync_q <= gpio_in_sync;
        end
    end

    // 直接设为 12 位宽，方便与 soc 包中的 OFFSET 比较
    // valid_i 保证地址已命中本外设窗口；本模块只检查窗口内 offset 是否为已定义寄存器。
    wire [core_pkg::XLEN-1:0] full_offset = addr_i - BASE_ADDR;
    wire [11:0]               offset      = {full_offset[11:2], 2'b00};

    // 内部寄存器声明，保持 XLEN 位宽；RW/RO 按属性分组，便于后续扩展。
    // RW 属性寄存器
    localparam RW_N = 7;
    reg  [core_pkg::XLEN-1:0] gpio_rw[RW_N];
    localparam OUT_IDX          = 0;
    localparam OE_IDX           = 1;
    localparam IRQ_EN_IDX       = 2;
    localparam IRQ_RISE_EN_IDX  = 3;
    localparam IRQ_FALL_EN_IDX  = 4;
    localparam IRQ_HIGH_EN_IDX  = 5;
    localparam IRQ_LOW_EN_IDX   = 6;
    // RO 属性寄存器
    localparam RO_N = 2;
    wire [core_pkg::XLEN-1:0] gpio_ro[RO_N];
    localparam IN_IDX           = 0;
    localparam IRQ_STATUS_IDX   = 1;
    // RW1C 属性寄存器，可读，写 1 清除，写 0 保持
    localparam RW1C_N = 1;
    reg  [core_pkg::XLEN-1:0] gpio_rw1c[RW1C_N];
    localparam IRQ_PENDING_IDX  = 0;

    // 输出端口与状态寄存器的控制关系
    assign gpio_out_o       = gpio_rw[OUT_IDX][GPIO_WIDTH-1:0];
    assign gpio_oe_o        = gpio_rw[OE_IDX ][GPIO_WIDTH-1:0];

    // 目前 access_fault_o 仅检测未知 offset，写只读等情况不触发，后续可以用 | 扩展
    assign access_fault_o = offset_illegal;
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

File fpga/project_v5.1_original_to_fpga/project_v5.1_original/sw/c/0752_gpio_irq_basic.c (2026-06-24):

/*
 * 0752_gpio_irq_basic.c — GPIO0 外部中断基础行为测试。
 *
 * 目的：
 *   - IRQ_EN 与 IRQ_STATUS = IRQ_PENDING & IRQ_EN 的寄存器关系。
 *   - 上升沿、下降沿、高电平、低电平四类触发条件。
 *   - IRQ_PENDING R/W1C 清除行为。
 *   - GPIO 输入两级同步后的最终 pending/handler 行为。
 *   - GPIO interrupt 以 machine external interrupt（mcause=0x8000000B）
 *     进入 core。
 *
 * 关于 TB mailbox：
 *   测试通过 tb_rv32i_soc_test.h 的 helper 驱动 GPIO0 输入，
 *   由 tb_rv32i_soc.sv 的 command mailbox 响应。
 *
 * 关于 handler：
 *   handler 记录 mcause 和 GPIO IRQ_STATUS，然后关闭 IRQ_EN 中
 *   已 pending 的位（防止电平触发模式在 mret 后立刻再次中断），
 *   最后返回 mepc 恢复执行。
 *
 * 通过条件：
 *   Stage1: IRQ_EN + IRQ_STATUS 基本关系正确。
 *   Stage2: 上升沿触发 → handler 记录 mcause=0x8000000B。
 *   Stage3: 下降沿触发 → handler 记录 mcause=0x8000000B。
 *   Stage4: 高电平触发 → handler 记录 mcause=0x8000000B。
 *   Stage5: 低电平触发 → handler 记录 mcause=0x8000000B。
 *   Stage6: IRQ_PENDING R/W1C 清除与 IRQ_STATUS 联动正确。
 *
 * 失败场景：
 *   - timeout：中断未发生（mie.MEIE 或 mstatus.MIE 未正确设置、
 *     GPIO 配置有误、TB mailbox 未响应）。
 *   - 错误 mcause：handler 收到非 MEIP 的 trap → infinite loop → timeout。
 *   - R/W1C 行为异常（写 1 不清、读后又自动置位等）。
 */

#include "platform.h"
#include "tb_rv32i_soc_test.h"

/* handler 记录的中断信息 */
static volatile unsigned int irq_count;
static volatile unsigned int irq_mcause;
static volatile unsigned int irq_gpio_status;

/*
 * __trap_handler_c — C trap handler 强定义。
 *
 * 仅接受 machine external interrupt（cause code = 11）。
 * 记录 mcause 和当前 GPIO IRQ_STATUS，关闭对应 IRQ_EN 位
 * 防止 level re-trigger，返回 mepc 恢复执行。
 * 非预期的 trap 进入无限循环 → timeout → FAIL。
 */
unsigned int __trap_handler_c(unsigned int mcause, unsigned int mepc, unsigned int mtval)
{
    unsigned int gpio_status;

    (void)mtval;

    /* 确认是 MEIP（machine external interrupt） */
    if (((mcause & MCAUSE_INTERRUPT_BIT) != 0u) &&
        ((mcause & MCAUSE_CODE_MASK) == 11u)) {

        irq_count++;
        irq_mcause = mcause;

        /* 记录 IRQ_STATUS（pending & en 组合），并关闭 pending
         * 位的 IRQ_EN 来阻止电平重触发。 */
        gpio_status = mmio_read32(gpio_reg(GPIO0_BASE, GPIO_IRQ_STATUS_OFFSET));
        irq_gpio_status = gpio_status;

        if (gpio_status != 0u) {
            mmio_write32(gpio_reg(GPIO0_BASE, GPIO_IRQ_EN_OFFSET),
                mmio_read32(gpio_reg(GPIO0_BASE, GPIO_IRQ_EN_OFFSET)) & ~gpio_status);
        }

        return mepc;
    }

    /* 非预期 trap：无限循环等待 timeout。 */
    for (;;) {
    }
}

/*
 * wait_cycles — 通过空循环消耗约 n 个 cycle。
 * 用于等待 TB mailbox 响应和 GPIO 同步链传播。
 * 不精确但足够可靠。
 */
static void wait_cycles(unsigned int n)
{
    volatile unsigned int i;
    for (i = 0u; i < n; i++) {
    }
}

/*
 * wait_for_irq — 等待 handler 被调用至少 expected 次。
 * 返回 0 表示成功，非 0 表示超时。
 */
static unsigned int wait_for_irq(unsigned int expected, unsigned int timeout)
{
    while (irq_count < expected && timeout > 0u) {
        timeout--;
    }
    return (irq_count >= expected) ? 0u : 1u;
}

int main(void)
{
    unsigned int val;

    /* ----------------------------------------------------------------
     * Stage1: IRQ_EN + IRQ_STATUS 基本关系（无全局中断）
     * 使用 bit 0，高电平触发
     * ---------------------------------------------------------------- */

    /* 1a: TB 驱动 bit 0 为高, 等待同步 */
    tb_gpio0_clear_mask(1u);
    wait_cycles(20u);
    tb_gpio0_set_mask(1u);
    wait_cycles(20u);

    /* 1b: 仅设 IRQ_EN，无触发使能 → STATUS 应为 0 */
    mmio_write32(gpio_reg(GPIO0_BASE, GPIO_IRQ_EN_OFFSET), 1u);
    val = mmio_read32(gpio_reg(GPIO0_BASE, GPIO_IRQ_STATUS_OFFSET));
    if (val != 0u) {
        return 1;
    }

    /* 1c: 加 IRQ_HIGH_EN → pending 置位 → STATUS = 1 */
    mmio_write32(gpio_reg(GPIO0_BASE, GPIO_IRQ_HIGH_EN_OFFSET), 1u);
    wait_cycles(10u);
    val = mmio_read32(gpio_reg(GPIO0_BASE, GPIO_IRQ_PENDING_OFFSET));
    if ((val & 1u) == 0u) {
        return 2;
    }
    val = mmio_read32(gpio_reg(GPIO0_BASE, GPIO_IRQ_STATUS_OFFSET));
    if ((val & 1u) == 0u) {
        return 3;
    }

    /* 1d: 清除 stimulus 和触发使能，W1C pending */
    tb_gpio0_clear_mask(1u);
    mmio_write32(gpio_reg(GPIO0_BASE, GPIO_IRQ_HIGH_EN_OFFSET), 0u);
    wait_cycles(20u);
    mmio_write32(gpio_reg(GPIO0_BASE, GPIO_IRQ_PENDING_OFFSET), 1u);
    val = mmio_read32(gpio_reg(GPIO0_BASE, GPIO_IRQ_PENDING_OFFSET));
    if ((val & 1u) != 0u) {
        return 4;
    }
    val = mmio_read32(gpio_reg(GPIO0_BASE, GPIO_IRQ_STATUS_OFFSET));
    if ((val & 1u) != 0u) {
        return 5;
    }

    /* 1e: 清 IRQ_EN */
    mmio_write32(gpio_reg(GPIO0_BASE, GPIO_IRQ_EN_OFFSET), 0u);

    /* ----------------------------------------------------------------
     * Stage2: 上升沿触发中断
     * 使用 bit 1
     * ---------------------------------------------------------------- */
    irq_count = 0u;

    /* 2a: 确保 bit 1 初始为低 */
    tb_gpio0_clear_mask(2u);
    wait_cycles(20u);

    /* 2b: 配置上升沿触发 */
    mmio_write32(gpio_reg(GPIO0_BASE, GPIO_IRQ_EN_OFFSET), 2u);
    mmio_write32(gpio_reg(GPIO0_BASE, GPIO_IRQ_RISE_EN_OFFSET), 2u);
    mmio_write32(gpio_reg(GPIO0_BASE, GPIO_IRQ_PENDING_OFFSET), 2u);

    /* 2c: 开全局中断和外部中断使能 */
    csr_set_mie(MIE_MEIE);
    csr_set_mstatus(MSTATUS_MIE);

    /* 2d: 制造上升沿（bit 1 低→高） */
    tb_gpio0_set_mask(2u);
    if (wait_for_irq(1u, 5000u) != 0u) {
        return 11;  /* timeout — 中断未发生 */
    }

    /* 2e: 验证 handler 记录 */
    val = irq_mcause;
    if ((val & MCAUSE_INTERRUPT_BIT) == 0u) {
        return 12;  /* 不是 interrupt */
    }
    if ((val & MCAUSE_CODE_MASK) != 11u) {
        return 13;  /* cause code 不是 MEIP */
    }
    if ((irq_gpio_status & 2u) == 0u) {
        return 14;  /* IRQ_STATUS 应包含 bit 1 */
    }

    /* 2f: 清理 */
    csr_clear_mstatus(MSTATUS_MIE);
    csr_clear_mie(MIE_MEIE);
    tb_gpio0_clear_mask(2u);
    wait_cycles(20u);
    mmio_write32(gpio_reg(GPIO0_BASE, GPIO_IRQ_PENDING_OFFSET), 2u);
    mmio_write32(gpio_reg(GPIO0_BASE, GPIO_IRQ_EN_OFFSET), 0u);
    mmio_write32(gpio_reg(GPIO0_BASE, GPIO_IRQ_RISE_EN_OFFSET), 0u);

    /* ----------------------------------------------------------------
     * Stage3: 下降沿触发中断
     * 使用 bit 2
     * ---------------------------------------------------------------- */
    irq_count = 0u;

    /* 3a: 确保 bit 2 初始为高（才能产生下降沿） */
    tb_gpio0_set_mask(4u);
    wait_cycles(20u);

    /* 3b: 配置下降沿触发 */
    mmio_write32(gpio_reg(GPIO0_BASE, GPIO_IRQ_EN_OFFSET), 4u);
    mmio_write32(gpio_reg(GPIO0_BASE, GPIO_IRQ_FALL_EN_OFFSET), 4u);
    mmio_write32(gpio_reg(GPIO0_BASE, GPIO_IRQ_PENDING_OFFSET), 4u);

    /* 3c: 开中断 */
    csr_set_mie(MIE_MEIE);
    csr_set_mstatus(MSTATUS_MIE);

    /* 3d: 制造下降沿（bit 2 高→低） */
    tb_gpio0_clear_mask(4u);
    if (wait_for_irq(1u, 5000u) != 0u) {
        return 21;
    }

    /* 3e: 验证 */
    val = irq_mcause;
    if ((val & MCAUSE_INTERRUPT_BIT) == 0u) {
        return 22;
    }
    if ((val & MCAUSE_CODE_MASK) != 11u) {
        return 23;
    }
    if ((irq_gpio_status & 4u) == 0u) {
        return 24;
    }
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

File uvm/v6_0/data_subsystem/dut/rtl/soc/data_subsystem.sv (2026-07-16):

//------------------------------------------------------------------------------
// 文件      : rtl/soc/data_subsystem.sv
// 用途      : core LSU simple data bus 与具体数据设备之间的译码/响应包装层。
//
// 规范：
//   - 输入端口使用 _i 后缀，输出端口使用 _o 后缀。
//   - core 侧使用单 outstanding request/response 简化 data bus。
//   - core_req_i.valid/core_req_ready_o 接受一次 load/store request。
//   - core_resp_o.valid/core_resp_o.error 返回该 request 的完成结果。
//   - dmem_access_o/mmio_access_o 是 accepted request 命中观察信号，给 testbench 做统计或波形 debug。
//
// 功能：
//   - 接收 core 的 data request（valid/write/be/addr/wdata）。
//   - 判断地址命中 DMEM、UART0、GPIO0、TIMER0，还是未映射。
//   - 通过外置固定响应 DMEM 端口访问上层连接的 simple_ram/DMEM model。
//   - 实例化 mmio_uart、mmio_gpio、mmio_timer32。
//   - 在 request accepted 当拍访问固定响应 DMEM/MMIO target，并锁存 rdata/error。
//   - 根据 TB 配置的 delay cycles 同拍或延迟返回 response。
//   - 对未映射 load/store，返回 response error，读数据返回 0。
//   - 暴露 GPIO 输出、UART TX/RX 事件接口和 GPIO/UART/TIMER0 中断给 SoC/testbench。
//------------------------------------------------------------------------------

`default_nettype none

module data_subsystem (
    input  logic                      clk_i,
    input  logic                      rst_n_i,

    output logic                      core_req_ready_o,
    input  data_bus_pkg::data_req_t   core_req_i,
    output data_bus_pkg::data_resp_t  core_resp_o,

    output logic                      dmem_we_o,
    output logic [3:0]                dmem_be_o,
    output logic [core_pkg::XLEN-1:0] dmem_addr_o,
    output logic [core_pkg::XLEN-1:0] dmem_wdata_o,
    input  logic [core_pkg::XLEN-1:0] dmem_rdata_i,

    input  logic [31:0]               gpio0_in_i,
    output logic [31:0]               gpio0_out_o,
    output logic [31:0]               gpio0_oe_o,

    output logic                      uart0_tx_valid_o,
    output logic [7:0]                uart0_tx_data_o,
    input  logic                      uart0_rx_valid_i,
    input  logic [7:0]                uart0_rx_data_i,

    // 中断输出
    output logic                      gpio0_irq_o,
    output logic                      uart0_irq_o,
    output logic                      timer0_irq_o,

    // 供 tb mailbox 配置的 data target 响应延迟，默认 0 时等价于固定响应。
    input  logic [6:0]                dmem_resp_delay_cycles_i,
    input  logic [6:0]                gpio0_resp_delay_cycles_i,
    input  logic [6:0]                uart0_resp_delay_cycles_i,
    input  logic [6:0]                timer0_resp_delay_cycles_i,

    output logic                      dmem_access_o,        // 观察信号：本拍 accepted request 命中 DMEM。
    output logic                      mmio_access_o         // 观察信号：本拍 accepted request 命中 MMIO。
);

    import core_pkg::*;
    import soc_pkg::*;
    import data_bus_pkg::*;

    // 信号声明(兼容 VCS 要求)
    wire req_accept_fire, req_re_accept, req_we_accept;
    wire dmem_hit, gpio0_hit, uart0_hit, timer0_hit, mapped_hit;
    wire req_dmem_valid, req_gpio0_valid, req_uart0_valid, req_timer0_valid, req_undefined_valid;
    wire [core_pkg::XLEN-1:0] gpio0_rdata, uart0_rdata, timer0_rdata;
    wire gpio0_access_fault, uart0_access_fault, timer0_access_fault;
    wire resp_undefined_valid;

    // 状态信号
    reg resp_pending_q; // 接受了 req 但还没给出 resp
    soc_pkg::target_e target, resp_target_q; // req 请求的目标，resp 响应源
    assign target = dmem_hit   ? TARGET_DMEM   :
                    gpio0_hit  ? TARGET_GPIO0  :
                    uart0_hit  ? TARGET_UART0  :
                    timer0_hit ? TARGET_TIMER0 : TARGET_UNDEFINED;
    always_ff @(posedge clk_i or negedge rst_n_i) begin : STATUS_CTRL
        if (!rst_n_i) begin
            resp_pending_q <= 1'b0;
            resp_target_q  <= TARGET_UNDEFINED;
        end
        else begin
            if (req_accept_fire) begin
                resp_pending_q <= 1'b1;
                resp_target_q  <= target;
            end
            if (core_resp_o.valid) begin    // 0 wait-state 时 resp_pending_q 无需置位
                resp_pending_q <= 1'b0;
            end
        end
    end
    assign core_req_ready_o = !resp_pending_q;

    // 本拍是一个真实被接受的的访存信号（脉冲信号）
    assign req_accept_fire = core_req_i.valid &  core_req_ready_o;
    assign req_re_accept   = req_accept_fire  & !core_req_i.write;
    assign req_we_accept   = req_accept_fire  &  core_req_i.write;

    // core_addr 命中分配
    assign dmem_hit   = (core_req_i.addr >= DMEM_BASE)   & (core_req_i.addr < DMEM_BASE   + DMEM_SIZE_BYTES);
    assign gpio0_hit  = (core_req_i.addr >= GPIO0_BASE)  & (core_req_i.addr < GPIO0_BASE  + GPIO0_SIZE_BYTES);
    assign uart0_hit  = (core_req_i.addr >= UART0_BASE)  & (core_req_i.addr < UART0_BASE  + UART0_SIZE_BYTES);
    assign timer0_hit = (core_req_i.addr >= TIMER0_BASE) & (core_req_i.addr < TIMER0_BASE + TIMER0_SIZE_BYTES);
    assign mapped_hit = dmem_hit | gpio0_hit | uart0_hit | timer0_hit;    // addr 命中已实现的地址

    //accepted request 命中各目标窗口时，产生对应 target 的访问脉冲
    assign req_dmem_valid      = req_accept_fire &  dmem_hit;
    assign req_gpio0_valid     = req_accept_fire &  gpio0_hit;
    assign req_uart0_valid     = req_accept_fire &  uart0_hit;
    assign req_timer0_valid    = req_accept_fire &  timer0_hit;
    assign req_undefined_valid = req_accept_fire & !mapped_hit;

    //======================================================================
    // 固定响应 target 的延时响应包装层，用计数器注入非 0 wait-state。
    // 固定响应 DMEM/MMIO 在 accepted request 当拍完成本体访问并锁存返回值，
    // wrapper 根据 TB 配置的 delay cycles 延后向 core 返回 response。
    // 后续真实慢 slave 可以替换该 wrapper，或自行按 simple bus 语义产生 response。
    //======================================================================
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

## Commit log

2026-06-03 rtl: 初始 RTL 结构提交 - 核心模块与公共包
    包含以下模块：
    - common/core_pkg.sv : 公共类型与参数定义
    - core/alu.sv : ALU (算术逻辑单元)
    - core/imm_gen.sv : 立即数生成器 (I/S/B/U/J 五类)
    - core/regfile.sv : 32 项通用寄存器堆 (组合读/同步写/写转发)
    当前为单周期 RTL 核心框架，后续将接入 PC、控制单元及流水线逻辑。
2026-06-03 单周期顶层完整实现 + regfile 读端口简化
    - core_single_cycle.sv：完成所有模块间互联，实现完整 RV32I 单周期数据通路
    - regfile.sv：移除内部同拍写读旁路逻辑，读端口直接从寄存器阵列取值
    - id_stage.sv：去除冗余的 if_pc_i/if_pc_plus4_i 输入及对应输出，改用顶层外部透传
    - ex_stage/mem_stage/pc_reg：端口顺序整理及注释完善
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2026-06-03 流水线阶段：IF/EX/PC 寄存器完整实现及注释完善
    实现模块：
    - pc_reg.sv : PC 寄存器，支持 reset/redirect/stall/PC+4 更新，
    修复时钟名、pc_valid_o 复位逻辑、优先级顺序。
    - if_stage.sv : 取指阶段组合通路，输出 imem 地址、PC+4 及指令。
    - ex_stage.sv : 执行阶段端口及结构定义。
2026-06-03 流水线阶段模块：IF/EX/PC 寄存器 + mem_stage 完整实现
    新增模块：
    - rtl/core/if_stage.sv : 取指阶段，输出当前 PC 到 imem 并捕获指令。
    - rtl/core/ex_stage.sv : 执行阶段，ALU 操作数选择与运算。
    - rtl/core/pc_reg.sv : PC 寄存器，支持 reset/redirect/stall/顺序四种更新。
    完整实现：
    - rtl/core/mem_stage.sv : 完成 load 数据提取与符号/零扩展、store 数据对齐、
    byte enable 生成、访存不对齐检测。
2026-06-03 流水线阶段模块：写回阶段、分支判断单元及访存阶段框架
    - rtl/core/wb_stage.sv : 写回阶段，根据 wb_sel 选择 ALU 结果/
    load 数据/PC+4/立即数送 regfile 写端口。
    - rtl/core/branch_unit.sv : 条件分支判断单元，覆盖 BEQ/BNE/BLT/
    BGE/BLTU/BGEU 六种比较，输出 branch_taken。
    - rtl/core/mem_stage.sv : 访存阶段框架（端口已定义，逻辑待实现）。
    后续将实现 store 数据对齐、byte enable 生成、
    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
2026-06-03 decoder: 完整 RV32I 译码器实现 + 代码精简
    主要变更：
    - 新增 rtl/core/decoder.sv：完整支持 37 条 RV32I 主线指令的译码，
    包含 opcode/funct3/funct7 分层译码、alu_op 查表、operand 选择、
    写回控制、访存控制、分支比较、跳转检测、非法指令检测。
    - core_pkg.sv：完善 opcode_e/instr_id_e 注释，标注扩展影响；
    新增 ALU_NONE 枚举；移除 OP_B_FOUR；注释暂不实现的 FENCE/ECALL/EBREAK。
    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
2026-06-03 test: 仿真环境搭建 + 完整 RV32I 汇编测试集
    - tb/sv/tb_core_single_cycle.sv: commit trace, PASS/FAIL 检测, TIMEOUT 保护
    - scripts/bin2mem32.py: 二进制→$readmemh 格式转换
    - sim/single_cycle_asm/: 单周期汇编测试编译和仿真脚本 (05-06 + run_all + run_test)
    - sw/linker/linker.ld: RV32I 裸机链接脚本 (IMEM@0x0, DMEM@0x10000)
    - sw/asm/: 7 个定向测试 (smoke, branch, u_type, alu_imm, alu_reg, jump, load_store)
    - docs/simulation_flow.md: 完整仿真流程文档
    - rtl/core/pc_reg.sv: 复位行为小修
2026-06-03 refactor: 为 C 程序仿真做准备，拆分链接脚本和文档
    - sw/linker/linker.ld → asm_test.ld：汇编测试专用链接脚本
    - docs/simulation_flow.md → simulation_flow_singlecycle_s.md：单周期汇编仿真专用文档
    - sim/single_cycle_asm/05_build_mem.sh：同步更新链接脚本路径
    后续可添加 sw/linker/c_test.ld 及对应 C 程序仿真文档。
2026-06-04 feat: 单周期 RV32I core 完成 — 汇编 + C 裸机仿真全部通过
    单周期 demo 核心功能验证完毕：
    - 7 个汇编测试覆盖全部 RV32I 指令（alu_imm/alu_reg/branch/jump/load_store/u_type/smoke）
    - 2 个 C 测试验证 crt0 + .rodata/.data/.bss/栈/函数调用
    - Verilator 仿真环境 + run_all.sh 一键回归
    - IMEM/DMEM 双镜像加载机制
    - 完整的 C 裸机 runtime（crt0.S + c_baremetal.ld）
    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
2026-06-04 feat: 五级流水线空壳 — pipe_reg 模块 + core_pipeline5 数据通路连接
    完成 plan.md 步骤 1-2：四组流水线寄存器（if_id/id_ex/ex_mem/mem_wb
    合并为 pipe_reg.sv），core_pipeline5 顶层实例化全部五级并打通
    valid bit 通路，forwarding/hazard 接口保留接地。配套清理 ex_stage
    branch_taken_o 内化、id_stage 删 unused id_instr_o 端口、
    0802 文档 5.3 补充 stall/bubble 适用范围分析。
2026-06-05 test: 五级流水线仿真环境 — testbench + 无 forwarding/redirect 冒烟测试
    新增 pipeline5 独立仿真环境：
    - tb_core_pipeline5.sv：五级流水线 testbench，提交时打印 PC/指令/写回信息
    - sim/pipeline5_asm/：仿真脚本（build_mem + run_sim）
    - pipeline5_nofwd_noredirect.S：无 forwarding/redirect 的 RAW 依赖冒烟测试
2026-06-05 feat: 五级流水线 data hazard — forwarding + load-use stall + regfile 旁路
    step 3 data hazard 处理，包含：
    - forwarding_unit.sv：EX/MEM→EX + MEM/WB→EX 前递，覆盖 WB_ALU/WB_IMM/WB_PC4 三源
    - hazard_unit.sv：load-use stall（stall_if/stall_id + bubble_ex）
    - regfile.sv：BYPASS_EN 参数 + generate 分支，流水线开启同拍写读旁路
    - core_pipeline5.sv：接入 forwarding_unit + hazard_unit，regfile 使能旁路
    - pipe_reg.sv：EX/MEM 和 MEM/WB 增加 stall_i 接口
    - 测试程序 pipeline5_fwd_noredirect.S：全覆盖 data hazard 场景累加链
    [forwarding_unit.sv]
2026-06-06 feat: 五级流水线完整实现 — data/control hazard + C 仿真环境
    至此五级流水线已补齐全部 hazard 处理（data hazard + control hazard），
    单周期所有指令集测试和流水线专用测试全部通过。
    control hazard（branch/JAL/JALR redirect flush/kill）:
    - hazard_unit 追加 redirect flush 控制（flush_if_id + flush_id_ex）
    - core_pipeline5 接入 flush 信号，移除占位
    - 新增 pipeline5_fwd_redirect.S 验证 forwarding + redirect 混合场景
    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
2026-06-09 refactor: 测试重命名与仿真改进 — 四位编号前缀 + resolve_test_name.sh 公共解析 + 0830 0831 规划文档
    测试文件重编号：
    - 所有汇编测试文件加四位编号前缀（0001~0303），按指令类型分组
    - 所有 C 测试文件加四位编号前缀（0201~0401），按功能分组
    - 编号规则：00xx 冒烟、01xx 单周期指令、02xx C 基础、03xx 流水线、04xx C 综合
    - 文件命名统一为 NNNN_description.S/.c，支持按编号或 basename 引用
    仿真脚本改进：
    - 新增 sim/common/resolve_test_name.sh：公共测试名解析，支持四位编号或完整 basename
    - 全部 16 个仿真脚本（4 组 × 4 脚本）改为调用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
2026-06-10 feat: 最小 M-mode CSR 模块完成 — csr_file + 6 个 CSR 寄存器 + WARL 处理 + trap/MRET 写 + 非法访问检测
    - rtl/core/csr_file.sv: 新建 CSR 寄存器文件，组合读同步写，trap/MRET/普通写三级优先级
    - core_pkg.sv: 新增 CSR 地址常量、trap_cause_e 异常原因枚举、csr_op_e 操作枚举
    - pipeline_pkg.sv: 流水线寄存器结构体新增 CSR/trap 字段
    - decoder/csr_file/trap_ctrl 接口对齐与规划文档更新
2026-06-10 feat: trap_ctrl 模块完成 — 组合 trap/MRET 控制 + 流水线 kill/redirect + 异常优先级
    - rtl/core/trap_ctrl.sv: 新建 trap 控制模块，汇总 pipeline exception 和 CSR illegal
    - 优先级：trap entry > MRET > EX branch redirect > load-use stall
    - 输出 trap/MRET valid、PC redirect、流水线 kill 控制
    - csr_file.sv: 接口跟随调整
    - plan.md: trap_ctrl 章节标记完成
    [csr_file.sv]
2026-06-12 feat: decoder/ID 阶段 CSR/trap 译码完成 — CSR 指令 + exception/FENCE/MRET 识别
    新增端口与译码逻辑：
    - CSR 指令识别：csr_o/csr_op_o/csr_addr_o/csr_uimm_o/csr_uses_rs1_o/csr_writes_rd_o/csr_write_en_o
    - 同步 exception 生成：exception_valid_o/exception_cause_o/exception_tval_o
    - 交互控制信号：fence_o、mret_o
    - INSTR_ID_GEN 补充 OPCODE_MISC_MEM（FENCE）和 OPCODE_SYSTEM（ECALL/EBREAK/MRET/CSR）译码分支
    - uses_rs1_o/reg_we_o/wb_sel_o 同步扩展以支持 CSR 指令
2026-06-12 feat: EX 阶段 CSR/trap 功能扩展
    - exception/csr/mret 端口新增，支持 trap 信息流水线传递
    - instruction address misaligned 检出（跳转目标未 4 字节对齐）
    - 前级 exception 抑制 redirect，同指令先发现异常优先
    - CSR 操作数生成（forwarding 后 rs1 / 零扩展 uimm）
    - MRET 标志透传到 EX/MEM
2026-06-12 feat: MEM 阶段 CSR/trap 端口与地址对齐异常检测
    mem_stage.sv 新增 load/store misaligned 拆分输出及 exception 信息；
    检出不对齐时产生对应 exception cause/tval 并屏蔽 dmem 访问。
    ex_stage.sv 代码格式对齐。
    相关文档同步更新。
2026-06-13 feat: WB/forwarding/hazard CSR 功能扩展 — WB_CSR 写回 + CSR-use stall + late-result 统一处理
    - wb_stage 增加 WB_CSR 写回路径，支持 CSR 旧值写 GPR
    - forwarding_unit 将 mem_re 拆分为 load_re/csr_re，对 CSR late result 做 EX/MEM 前递屏蔽
    - hazard_unit 将 load-use stall 扩展为 late-result-use stall（load + CSR），使用显式 id_ex_load_re_i / id_ex_csr_re_i 作为信号
    - trap/MRET 的 control hazard 由 trap_ctrl 的 kill 口径统一处理，不再混入 hazard_unit
    - id_stage 重构 decoder 信号门控，引入中间 wire 显式受 if_valid_i 约束
    [csr_file.sv, forwarding_unit.sv]
2026-06-14 feat: 流水线寄存器 kill 端口扩展完成 — pipe_reg 四段 kill_i + trap_ctrl 优先级修复
    - pipe_reg_if_id/id_ex/ex_mem/mem_wb 全部新增 kill_i 端口，优先级高于 flush/stall
    - trap_ctrl 异常选择优先级修复：pipeline_exception > csr_illegal_exception
    （此前与 0831 规划文档优先级描述不一致）
    - trap_ctrl.kill_mem_wb_input_o 更名为 kill_mem_wb_o，端口语义对齐
    - pipe_reg.sv 文件头新增 flush/kill 控制口径注释
    - plan.md 第 8 步标记为已完成，第 9 步集成规划更新为详细连接表
2026-06-15 feat: core_pipeline5 CSR/trap 模块集成 — csr_file/trap_ctrl 实例化与全流水线异常传递通路
    - core_pipeline5 顶层实例化 csr_file 和 trap_ctrl，完成 CSR/trap 全信号连接
    - mem_stage 增加前级 exception 透传，支持 pipeline-carried 与本地 misaligned 异常合并
    - ex_stage/mem_stage 扩展 CSR/trap 端口，完善异常信息随流水线传递
    - 所有 pipe_reg 实例 kill 端口连接至 trap_ctrl
    - hazard_unit/forwarding_unit 增加 CSR 写后读检测与 forwarding 抑制
    [csr_file.sv]
2026-06-16 feat: CSR/trap 全模块集成与单周期清理 — csr_file/trap_ctrl 实例化、全流水线异常传递、单周期移除
    - 五级流水线顶层集成 csr_file/trap_ctrl，支持最小 M-mode CSR/trap
    - 译码、ID、EX、MEM、WB 各阶段扩展 CSR/trap 控制通路
    - 流水线寄存器新增 kill 端口，支持 trap/MRET 精确 kill 年轻指令
    - Hazard/forwarding 扩展 CSR-use stall 与 EX/MEM late-result 屏蔽
    - wb_stage 新增 rd_addr_i 端口，x0 写回归零
    - 删除单周期顶层、testbench、仿真脚本及相关流程文档
    - pipeline5 仿真脚本统一 RTL 文件收集方式
2026-06-16 feat: IMEM/DMEM 扩展到 256 KiB、trap handler 链接布局
    - core_pkg 新增 IMEM_ADDR_WIDTH/DMEM_ADDR_WIDTH/SIZE_BYTES 常量
    - simple_rom/simple_ram 默认 ADDR_WIDTH 改用 core_pkg 常量（10→16）
    - DMEM_BASE 从 0x0001_0000 改为 0x0004_0000，适配 256 KiB IMEM 地址空间
    - linker 脚本增加 .text.trap section，IMEM/DMEM region 扩至 256 KiB
    - 所有 asm 测试程序拆 .text.init/.text 并更新 DMEM 地址常量
    - crt0.S 拆 reset stub（.text.init）与主体（.text），避免与 trap vector 冲突
    - objcopy 增加 -j .text.trap，tb DMEM_END_ADDR 改用 DMEM_SIZE_BYTES
    [core_pkg.sv, simple_ram.sv]
2026-06-16 feat: CSR/trap 测试程序完成与综合 PPA 更新 — 全异常验证、Zicsr 指令测试、C trap handler
    - 汇编全异常总测试（0502）：ECALL/EBREAK/非法指令/不对齐等 9 类同步异常，handler
    自检 mcause/mepc/mtval 后 mret 返回，step 计分
    - Zicsr 6 条指令独立测试（0503）：CSRRW/CSRRS/CSRRC/CSRRWI/CSRRSI/CSRRCI
    寄存器与立即数形式、rs1=x0 不修改语义验证
    - C 侧 trap handler 测试（0551）：通过弱符号 __trap_handler_c 实现 C 语言异常处理
    - crt0.S 新增 .text.trap 入口、寄存器保存/恢复和 C handler 调用机制
    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
2026-06-18 feat: 新增 MMIO 地址映射常量与 access fault 异常编码
    为第二阶段最小 memory map/MMIO 外设建立地址映射基础设施：
    - 新增 MMIO_BASE/SIZE_BYTES 及 UART0/GPIO0/TIMER0/ACCEL0 寄存器偏移常量
    - 启用 TRAP_CAUSE_LOAD_ACCESS_FAULT / TRAP_CAUSE_STORE_ACCESS_FAULT
    - 明确 memory map 地址空间总表注释
    本版本确立地址映射框架，v4.0 将在其基础上实现 data_subsystem、
    UART/GPIO MMIO 寄存器块及未映射访问 trap 的完整通路。
2026-06-18 feat: 新增 mmio_gpio/mmio_uart 模块，重构 MMIO 地址映射为多实例布局
    实现最小 MMIO 外设寄存器块：
    - mmio_gpio：GPIO 寄存器块（OUT/OE RW、IN RO、parametric GPIO_WIDTH、
    offset 译码与 access fault、写按 byte-enable 更新）
    - mmio_uart：UART TX 寄存器块（TXDATA WO、STATUS RO fixed ready、
    CTRL RW enable、TX event 输出、offset 译码与 access fault）
    重构 core_pkg MMIO 地址映射：
    - 外设按组管理（GPIO×4、UART×6、TIMER×6、ACCEL×4）
    - 新增 BASE/SIZE_BYTES/STRIDE/NUM 参数体系
    - 补充 MMIO 子地址图总表注释
    [core_pkg.sv, csr_file.sv, mmio_gpio.sv]
2026-06-20 feat: 新增 SoC data_subsystem 地址译码与数据响应层
    - 新增 data_subsystem 模块，完成 core LSU 到 DMEM/UART0/GPIO0 的地址命中判断
    - 实例化 simple_ram/mmio_uart/mmio_gpio，实现 rdata mux 与 access_fault 汇总
    - 新增 dmem_access_o/mmio_access_o 观察信号供 testbench 统计
2026-06-20 feat: core 顶层重命名与 LSU access fault 接入 - 将五级流水线顶层从 core_pipeline5 稳定命名为 core，并改为 rtl/core/core.sv。 - 将 core 数据侧接口从 dmem_* 统一为 lsu_*，保持 testbench 直连 RAM 兼容。 - 新增 lsu_access_fault_i，并在 mem_stage 中合并 loa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
    [data_subsystem.sv]
2026-06-20 feat: 新增 rv32i_soc 最小 SoC 平台顶层
    - 新增 rv32i_soc 模块，将 core/simple_rom/data_subsystem集成为最小 SoC 平台，透传 commit/trap/data/GPIO/UART观察信号供 testbench 使用。
    - plan.md 补充 SoC-level testbench 和定向测试规划。
2026-06-21 feat: SoC 汇编/C 测试套件与仿真平台
    - 建立 SoC 仿真平台 tb/sv/tb_rv32i_soc.sv，支持 GPIO/UART/MMIO 测试观测、GPIO driven 变化打印、UART TX 字符缓冲与汇总日志。
    - 新增 SoC/MMIO 汇编定向测试：SoC smoke、UART TX、GPIO 读写、MMIO access fault、misaligned 优先级、wrong-path MMIO 门控。
    - 修正 0602_uart_tx.S、0603_gpio_rw.S 失败路径，使失败状态写入后回到统一 done 结束路径，便于 testbench 报告。
    - 新增 SoC C MMIO 测试：0651_soc_mmio_smoke.c 覆盖 GPIO/UART 冒烟；0652_soc_mmio_gpio_uart.c 覆盖 GPIO bit 操作、OUT/OE 独立性、IN 只读和 UART 多字符串发送。
    - 新增 sw/include/platform.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
    [0651_soc_mmio_smoke.c, 0652_soc_mmio_gpio_uart.c, tb_rv32i_soc.sv]
2026-06-21 feat: v4.1 machine interrupt + timer 规划
    - 完成 CSR mip/mie、TIMER0 外设、GPIO/UART interrupt、trap_ctrl/core 扩展、流水线 next PC 携带、SoC 集成的设计规划与执行方案。
    - plan.md + 0833 文档。
2026-06-22 feat: v4.2 中断基础常量与流水线 next PC
    - 新增 CSR_ADDR_MIE/MIP、MIP/MIE bit 常量、mcause interrupt bit、irq_cause_e 枚举（支持 M_TIMER/M_EXTERNAL）。
    - 补充 TIMER0/GPIO IRQ/UART RX 的 MMIO offset 和 bit 常量到 soc_pkg。
    - 流水线 EX/MEM 新增 next_pc 字段，EX 阶段为 taken branch/JAL/JALR 生成正确下一条 PC，供中断写入 mepc 使用。
    - 新增 rtl/periph/readme.md 说明 GPIO/UART/TIMER0 中断架构差异。
    - 更新 0833 文档（UART 寄存器表、exception vs interrupt mepc 对比）。
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2026-06-29 feat: v5.2 FPGA 上板验证归档 — E10 Cyclone IV 迁移与板级验证 - 新增 fpga/ 工作区：E10 板卡资料、v5.1 FPGA 迁移工程、Quartus 项目 - 新增 FPGA 版 RTL：板级顶层、IMEM/DMEM M9K wrapper、UART TX/RX PHY - 完成 GPIO/KEY/TIMER/UART/interrupt 共 6 项板级验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
    [E10 最小系统板V1.0(1).dxf, E10 最小系统板V1.0.dxf, E10 最小系统板V1.1(1).DXF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]
2026-06-30 feat: v5.3 LSU request/response handshake — data-side 可变延迟准备
    mem_stage 从纯组合逻辑改为时序 transaction controller，支持 single outstanding request/response 模型，为后续 data-side 可变延迟（DMEM/MMIO 多拍响应）提供 MEM backpressure 基础。
    - mem_stage 新增 clk/rst 和 req/resp 握手接口
    - 新增 outstanding 状态机保证访存副作用最多一次
    - 新增 mem_wait/transaction_complete 控制信号
    - load data 改为 response 驱动，access fault 改为 delayed error 转换
    - 移除废弃固定响应端口（lsu_rdata_i/lsu_access_fault_i/lsu_re_o/lsu_we_o等）
    [data_subsystem.sv]
2026-06-30 feat: v5.4 pipeline_ctrl 与 pipeline backpressure 集成
    新增 pipeline_ctrl 模块，整合 hazard 检测和 MEM backpressure 为统一流水线控制单元；完成 plan 4-6 步骤（core 顶层接线、pipeline backpressure、hazard_unit/hazard_unit 控制同步、pipe_reg stall 注释确认）。
    - 新增 pipeline_ctrl.sv，实例化 hazard_unit 并输出 stall/late_result/flush 和 stall_pipeline
    - core.sv 接入 pipeline_ctrl 和 stall_pipeline（PC/IF/ID/ID/EX/EX/MEM）
    - hazard_unit.sv 重构 stall 输出为 stall_late_result_use_o
    - pipe_reg.sv 更新 ID/EX、EX/MEM stall 接线与注释
    - pc_reg.sv、mem_stage.sv 注释与观察信号补充
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2026-07-01 fix: *v5.6 修正回归统计方法与测试程序 GPIO IN 检查值
    run_all.sh 之前仅依赖 simulator exit code 判断 PASS/FAIL，$fatal/$finish 返回码不可靠导致部分 FAIL/TIMEOUT 被误判为 PASS，掩盖了其他 bug。改为 grep 日志中的 "PASS after"/"FAIL after"/"TIMEOUT:" 关键字精确判定。
    修复暴露的问题：
    - GPIO IN[31:30] 由 TB 周期信号驱动，测试程序需 mask 高位再比较 [29:0]，涉及测试程序：0603、0651、0652
    - gpio0_in[29:0] TB 复位默认值改为 30'hA5A55A5A（此前为 '0）
    - data_subsystem.sv resp_target 连续赋值问题修正,
    影响：asm 测试 0603、C 测试 0651/0652。
    [0651_soc_mmio_smoke.c, 0652_soc_mmio_gpio_uart.c, data_subsystem.sv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]
2026-07-01 feat: v5.7 data_subsystem 可配置延迟响应与 MEM/WB forwarding source 保持
    data_subsystem 各 target 支持独立 0~255 拍可变响应延迟，wrapper 在 accepted request 当拍锁存外设返回值后经计数器延后 response。0 wait-state 直通保持。
    MEM wait 期间 MEM/WB 被 stall 以维持 forwarding source 不丢失，同时通过 commit_valid_o 口径防止被 hold 的 MEM/WB 重复写回/提交。
    - data_subsystem.sv: 新增 delay cycles 输入与 RESP_DELAY 状态机
    - pipeline_ctrl.sv: 新增 stall_mem_wb_o 输出
    - pipe_reg.sv: pipe_reg_mem_wb 新增 commit_valid_o 端口与 stall 语义
    - core.sv: wb_stage.valid_i 切换为 mem_wb_commit_valid
    - rv32i_soc.sv: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
    [0757_gpio_periodic_irq.c, data_subsystem.sv, tb_rv32i_soc.sv]
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2026-07-13 feat: v6.3 simple data bus UVM interface 与 SVA 断言
    - 新增 simple_bus_if：聚合 req/ready/resp 信号，提供master_drv/mon/slave 三组 clocking block 与 modport
    - 补充 6 条 SVA 断言：rst 输出检查、控制/X/Z、请求数据/X/Z、resp error/X/Z、resp rdata/X/Z、backpressure payload stable
    - tb_simple_bus_uvm_top 例化 simple_bus_if 作为 virtual interface
    - filelist.f 和 run_test.sh 同步更新
    - spec.md 规约 data_subsystem_cfg_if 与 delay 配置规则
    - UVM class 文件统一 .svh 扩展名
    - plan.md 第 2 节标记为已完成
2026-07-13 feat: v6.4 UVM sequence item 与 simple data bus 协议规约
    - 新增 simple_bus_item（uvm_sequence_item）：write/be/addr/wdata/idle_cycles/rdata/error/resp_delay 字段、factory 宏、约束、地址解码与打印 helper
    - simple_bus_pkg 接入 simple_bus_item
    - simple_bus_base_test 添加 item 创建与打印的临时代码
    - filelist.f 增加 +incdir+../tb/seq
    - spec.md 规约 idle_cycles 语义、gap x delay 独立性、coverage 扩展
    - 新增 docs/known_issues.md：记录 MMIO 子字节访问偏移解码不一致问题（RTL-001，Deferred）
    - plan.md 跟踪当前进度
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2026-07-14 feat: v6.6 UVM driver 与 master 驱动时序
    - 新增 simple_bus_driver（uvm_driver #(simple_bus_item)）：master_drv_mp vif、wait_reset_release、idle_cycles 空拍执行、req valid/ready 握手、resp valid 等待、request/resp 超时保护、resp 回填 rdata/error/resp_delay
    - simple_bus_if master_drv_cb 拆为独立信号驱动（valid/write/be/addr/wdata），增加 inout req_i.valid 支持驱动 idle；modport 补充 clk_i
    - simple_bus_item 新增 rdata/error 默认 X 值、resp_delay 默认 0；item2string 格式增加 [item] 标签；idle_cycles 注释补充首笔 initial idle 语义
    - simple_bus_sequences send 方法改为 protected
    - simple_bus_pkg 接入 driver
    - plan.md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
2026-07-16 feat: v6.9 DUT harness 集成与第一条 UVM DMEM smoke test
    - DUT 接入：tb_simple_bus_uvm_top 例化 data_subsystem + simple_ram + resp_delay_cfg_if，配置 driver/monitor/DUT 配置 interface 的 uvm_config_db
    - RTL VCS 兼容修复：simple_ram always_ff → always；mmio_gpio/timer32/uart、data_subsystem 内部 wire/logic 声明移至模块顶端
    - 新增 resp_delay_cfg_if：per-target delay 配置 task，立即生效不等待时钟
    - 新增 simple_bus_base_sequence：base_seq 提取为独立文件，send_write32/send_read32 helper
    - 新增 simple_bus_smoke_test：启动 simple_bus_smoke_seq，首条端到端 UVM smoke
    - 新增 uvm 平台仿真流程说明文档 uvm_simulation_flow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
    [data_subsystem.sv, mmio_gpio.sv, simple_ram.sv]
2026-07-17 feat: v6.10 DMEM scoreboard 完整接入与 SVA 统一整理
    - SVA 统一整理至 tb/sva/simple_bus_sva.svh：迁移基础断言（reset/X/Z/backpressure），新增 single outstanding 与 no orphan response 状态型断言；interface 改为 include
    - scoreboard 完整接入 env：创建 scoreboard 并连接 monitor.transfer_ap，read match UVM_INFO
    - 组件命名统一：agent seqr/drv/mon → sequencer/driver/monitor；monitor mon_transfer_ap → transfer_ap
    - filelist.f 增加 checker/sva incdir
    - plan.md 更新：section 9 scoreboard 完成、section 10 SVA 完成、section 11 wait-state smoke 执行中
2026-07-19 feat: v6.11 计划 item 与 observed transfer 分层重构
    - 新增 simple_bus_transfer：内嵌 observed_item，扩展 rdata/error/resp_delay 与 req_cycle/accept_cycle/resp_cycle 时间戳
    - simple_bus_item 精简：移除 response 字段和 factory 宏，恢复为纯 master-side command
    - simple_bus_driver：新增 planned_item clone + planned_item_ap analysis port；不再回填 DUT response
    - simple_bus_monitor：改用 simple_bus_transfer，记录三拍时间戳
    - simple_bus_scoreboard：analysis_imp 改为 simple_bus_transfer
    - simple_bus_pkg 接入 transfer
    - plan.md 更新：section 11 item/transfer 分层完成，section 12 wrapper cfg agent 执行中
2026-07-20 feat: v6.12 response-delay wrapper 配置 agent 完整接入
    - 新增 resp_delay_cfg_if（原 data_subsystem_cfg_if 重命名）：保留 set_target_resp_delay，新增 rst_resp_delay task
    - 新增 resp_delay_cfg_item / resp_delay_cfg_set_sequence：配置 transaction 与定向 sequence
    - 新增 resp_delay_cfg_sequencer / resp_delay_cfg_driver / resp_delay_cfg_agent：active cfg agent，driver 在 reset 期间 rst_resp_delay()，reset 释放后执行普通 cfg item；含 item_check 合法性检查与 applied_item_ap 发布 clone
    - env 接入 wrapper_agent，bus agent/scoreboard 重命名
    - top cfg vif 路径指向 wrapper_agent.driver
    - plan.md 更新：section 12 完成，section 13 执行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
2026-07-23 fix: uvm001 修复补丁
    - addr_2_dmem_word_addr 修复：减 DMEM_BASE 后再移位
    - dmem_word_key 类型改为 DMEM_ADDR_WIDTH-1:0
    - random vseq 的 bus_seq/wrp_seq 创建移到 repeat 循环外
    - 新增 addr_2_dmem_word_key/dmem_word_key_2_addr helper
    - cp_accses_width word32: 4'b111 → 4'b1111
    - 合并 DS_dmem_random_test_200/_2000，保留 DS_dmem_random_test(num_items=2000)
    - known_issues UVM-001 标记 Fixed
    - plan.md 15.4 VDB/URG 标记暂缓（URG 工具崩溃）
2026-07-24 feat: v7.0 文档同步、DUT RTL 快照冻结与 data_subsystem 独立工作区收口
    - dut/rtl 从主线复制最小 RTL 编译闭包，filelist 切回快照
    - 新增 data_subsystem/README.md、verification_report.md
    - 更新根 README、uvm/readme、docs/0835 等文档
    - RTL-001 fix: MMIO offset 解码 {full_offset[11:2], 2'b00}
    - 新增 GPIO0 ref model（OUT/OE）及 check_gpio0
    - 新增全地址图 map random seq/vseq/test
    - coverage 新增 addr_low 及 GPIO0 addr_low×error cross
    - rtl/periph/readme.md 同步更新
    - 文档文件清理与重命名对齐
    [data_subsystem.sv, mmio_gpio.sv, simple_ram.sv]
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2026-07-31 feat: v7.2 AXI-Lite default error slave、single-master router 与 DMEM RAM slave
    - 新增 axi_lite_error_slave：DECERR 终止响应，AW/W 独立握手后返回 B
    - 新增 axi_lite_router：单 master 地址译码/response 路由，4 路下游
    - router 支持 AW/W 同拍或分拍握手，W 先到等待 AW 定 target
    - 新增 axi_lite_ram：32-bit AXI-Lite RAM slave，WSTRB 逐 lane 更新
    - 越界地址返回 SLVERR，注册式 B/R response
    - 0836 新增模块连接图与组合直通/注册边界表
    - plan.md 第 3/4/5 章标记已完成
    [axi_lite_ram.sv]
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2026-08-03 feat: v8.0 0836 AXI-Lite/APB 阶段收口与 SoC 集成验证完成
    - README 更新 AXI4-Lite/APB4 架构图与验证能力描述
    - 0836 文档由规划改写为收口，记录实现与验证边界
    - 0830 总规划标记 0836 已完成
    - simulation_flow 与 sw/ readme 同步迁移后状态
    - 删除 TB delay mailbox 定义与 C helper
    - 0757 bit30 周期 200→500 拍，REG-002 标记 Fixed
    - 0801/0802/0804/0805/0853/0856 清理无效 delay 写入
    - plan.md 已完成
    [0757_gpio_periodic_irq.c, 0853_mmio_wait_basic.c, 0856_wait_mixed_random_smoke.c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]
